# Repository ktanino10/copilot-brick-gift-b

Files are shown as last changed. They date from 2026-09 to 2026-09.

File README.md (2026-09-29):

# B DESK CLASSIC — 個人向け印刷・組立キット

**本人向けの公開案内： [説明・作り方・工程を見る](https://ktanino10.github.io/copilot-brick-gift-b/)**

2026-09-23のユーザー承認により、この個人向けrepoをpublicに変更し、GitHub Pagesで案内します。
個人銘板・許可済みの加工写真も公開内容です。原画像・EXIF・認証情報・ローカル監査資料は含めません。
公開内容は第三者にコピー・cacheされ得ます。[公開範囲](publication/README.md)を参照してください。

**2026-09-25：完成しました。「これで完成ですね」とご報告いただきました。**
水色のゴーグル枠を組み、上枠と紫の頭頂までそろった
[制作過程と完成の写真8枚](docs/BUILD-LOG.md#progress-2026-09-25)を追記しています。
前の16枚も残し、文字の試作から完成までを24枚の実写真でたどれます。
写真の紫・黄色は実制作の配色で、設計色や印刷データは変更していません。
制作の流れは **企画 → 設計 → 3Dプリント → 超音波洗浄 → アッセンブリー（組み立て）**。
[5工程の案内](docs/BUILD-LOG.md#今回の制作は5工程)から設計資料・動画・完成写真へ進めます。
[3Dプリントをページ内で見る](https://ktanino10.github.io/copilot-brick-gift-b/docs/BUILD-LOG.html#printing-video-2026-09-25) ／
[超音波洗浄をページ内で見る](https://ktanino10.github.io/copilot-brick-gift-b/docs/BUILD-LOG.html#post-processing-ultrasonic-2026-09-25)。
2本ともユーザー提供動画です（ネット接続が必要、自動再生なし）。

**2026-09-22承認：文字銘板を読みやすい版へ更新しました。**
1行目12 mmを維持して孔・字間を広げ、2行目10 mm、白い浮彫1.2 mmにしています。
既に印刷した台座・顔・右ロゴはそのまま使い、更新するのは**文字銘板1枚だけ**です。
まず[同寸法の小さな文字試験片と変更説明](docs/NAMEPLATE-V2.md)を確認してください。

**配布するのは通常GitHub CopilotのB・1種類だけ。個人銘板入りのデータと日本語の作り方です。**
承認済みの顔、シアンのゴーグル、マゼンタの外周、緑の目、5段の黒台座を変更していません。
別PCでも、公開Webページを直接見るか、このリポジトリから保存して作業できます。

**[B全キットをダウンロード](https://github.com/ktanino10/copilot-brick-gift-b/blob/main/downloads/B-personal-print-kit.zip)**

リンク先で **Download raw file** → ZIPを展開。公開repoなので閲覧・保存にログインは不要です。
リポジトリ上部の **Code → Download ZIP** でも同じ内容を受け取れます。
2つとも保存する必要はありません。

**展開したフォルダの [`guide/index.html`](guide/index.html) をダブルクリックすると、
印刷ファイルと組立位置を照合できる3Dガイドが開きます。**
インターネット接続、Python、Node、サーバーの準備は不要です。
GitHub上ではHTMLが実行されないため、必ず保存・展開して開きます。

**色別表の上からの印刷順は、組立順ではありません。**
最初は `B-black-02.3mf` の **slot 3 / `BASE3-24x10-B-562406` → `B-001` / 工程1**。
`black-01`の8個は2〜5段目用なので、既に刷ったものは捨てず、部品IDごとに仕分けて使います。

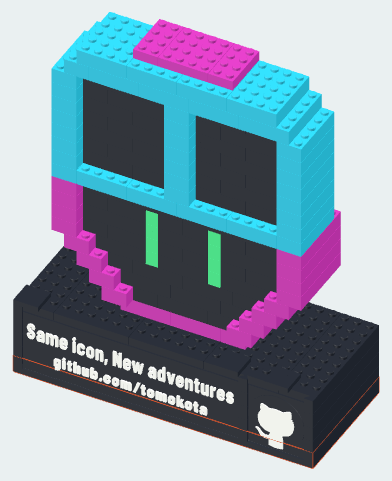
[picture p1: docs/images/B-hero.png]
個人銘板入りの承認済みB。実STLから作成した保存済みの完成配置画像


これは実STL由来のデジタル完成図で、実物写真ではありません。
オレンジの枠はビューアの選択表示で、追加の印刷色・部品ではありません。
**配布データはNOT_SLICED（未スライス）。実制作写真はありますが、正式な嵌合・保持・強度・転倒の評価結果は未提供です。**
3MFは形状と配置のみで、検証済みP1S設定・Pause・G-codeを含みません。

## CLI風アレンジ（実物写真）

ブロックを変更してCLI風にアレンジした実物です。**標準配布モデルとは異なるアレンジ例です。**
設計・印刷ファイル・3D組立順は変更していません。

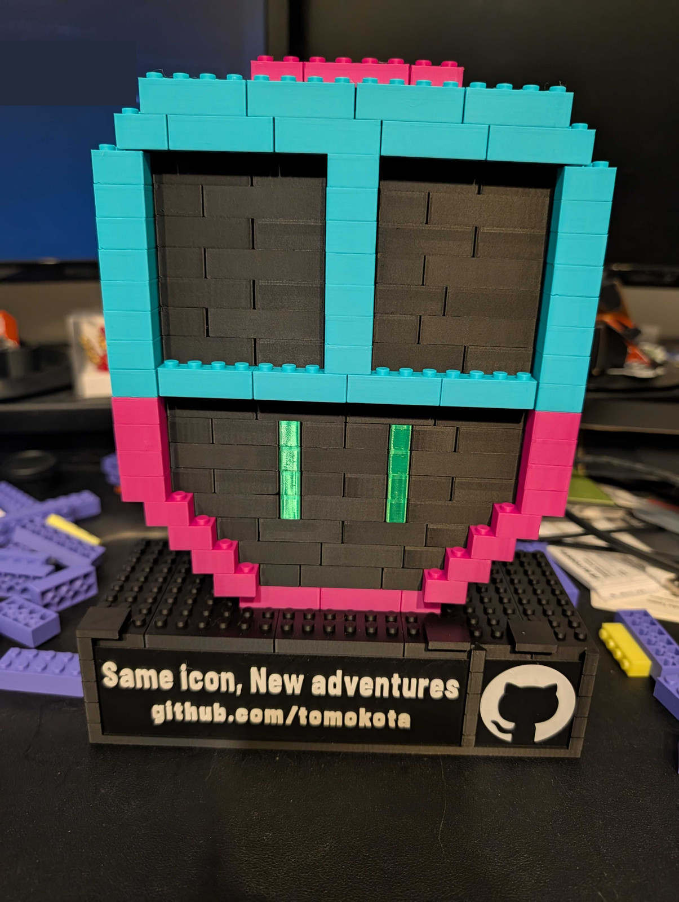
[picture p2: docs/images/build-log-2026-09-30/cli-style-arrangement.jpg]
CLI風にアレンジした実物のブロック模型。シアンのゴーグル枠、黒い顔、マゼンタの輪郭、緑色の目と黒い台座


[制作記録と写真の取扱い](docs/BUILD-LOG.md#cli-arrangement-2026-09-30)に追記しました。
追加日は2026-09-30（JST）で、撮影日は未確認です。

## まず、ここから

1. **[別PCでの保存・Bambu Studio・印刷手順](docs/PRINTING.md)** を開き、
   P1Sの実ノズル・PLA・プレートとStudio設定を合わせます。
2. 最初は **[FIT-M-D470](kit/fit/FIT-M-D470.stl)＋[FIT-F-CP12](kit/fit/FIT-F-CP12.stl)を各1個だけ**。
   mm・100%・向きを確認し、スライス後に穴入口と屋根の経路を見ます。
3. **[少量試作の順番](docs/TRIAL.md)** に沿い、必要なキー溝試験片 → 実ブロック4個 →
   keeperとB台座端部3個 → 実5段台座・前面 → 顔の少量バッチへ進みます。
4. 問題がなければ **[オフライン3Dガイド](guide/index.html)** と
   **[組立・銘板交換・分解](docs/ASSEMBLY.md)** を見ながら組みます。
   **[3Dガイドの使い方](docs/GUIDE.md)**／**[28工程の図](docs/STEPS.md)** も同梱しています。

**穴・溝が塞がる、指でつかめない、座らない、強い力が必要、割れ、保持不足があれば停止。**
全数を先に刷らず、穴を1つずつ削る・工具で無理押しすることを前提にしません。
試作7個の成功だけでは完成品の合格になりません。

## 印刷した部品を、3Dで探してから組む

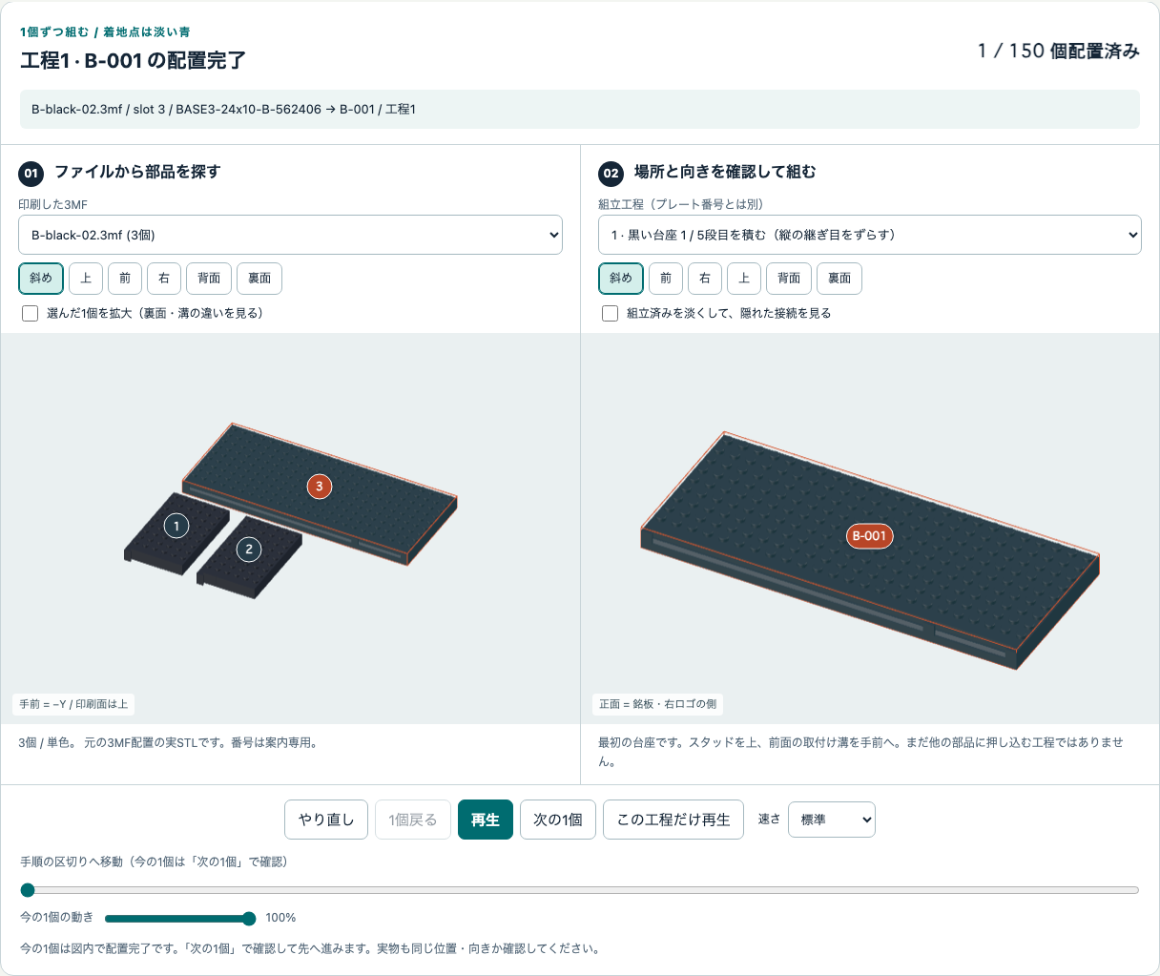
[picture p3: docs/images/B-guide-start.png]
実3MFの配置と実STLによる台座1段目。black-02 slot 3からB-001へ対応する3Dガイド


`B-black-02.3mf` → **slot 3** → `BASE3-24x10-B-562406`（**191.8 × 79.8 mm**）
→ **`B-001`、工程1**。この大きさの1段目は1個だけです。
3D内の部品または一覧を選ぶと、適用できる配置番号と工程、完成／途中の位置を強調します。
案内用slotは3MF内の順番を表す番号で、部品に刻印されていません。
**同じ部品ID・色のものは交換可能**で、便宜上の割当は実物の個体識別ではありません。

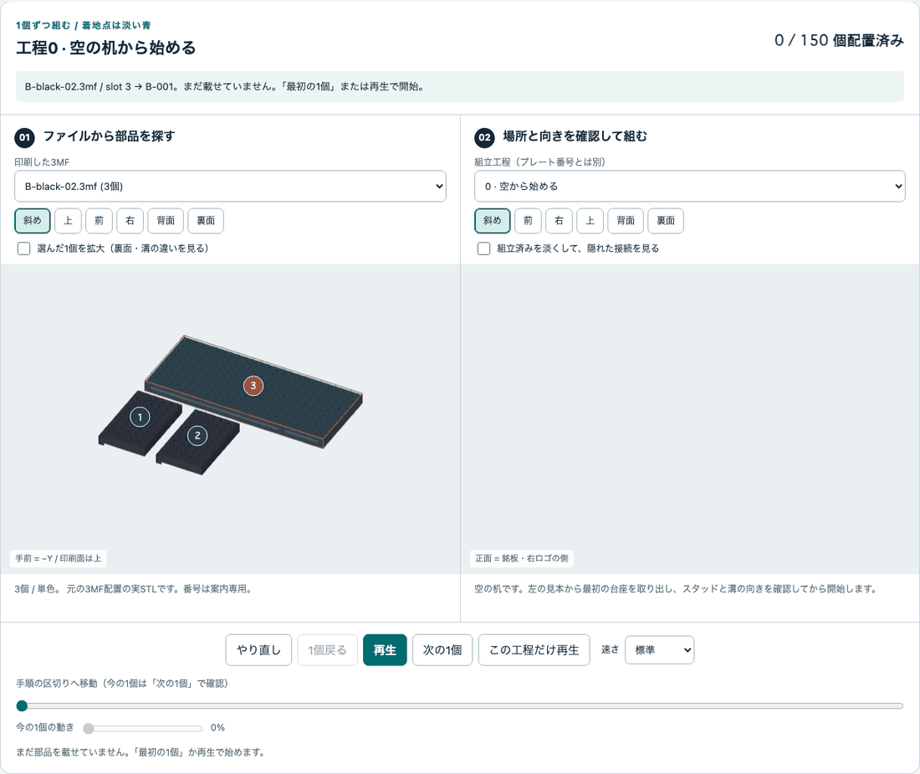
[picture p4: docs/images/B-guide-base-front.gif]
空の机から台座5段、銘板・独立ロゴ、keeper3個を組む実形状3Dアニメーション


台座1〜5段の19個は **black-01〜04**、前面2個は **black-to-white-z2p4 / z2p8**、
keeper3個は **black-07のslot 8〜10** から取ります。
2段目だけでも **black-02 slot 1 → B-002、black-03 slot 3 → B-003、
black-03 slot 1 → B-004、black-01 slot 7 → B-005** が必要です。
全28工程／150個の操作は [3Dガイド](guide/index.html)、
全14枚の対応は [ファイル一覧](docs/FILES.md) へ。
画像・アニメは同梱ビューアの実形状表示で、実物試験や挿入・分解経路の保証ではありません。

## 作るものは、このBだけ

| 項目 | 内容 |
|---|---|
| 完成寸法 W×D×H（設計値） | **191.8 × 80.2 × 238.6 mm**（上端スタッド・前へ0.4 mm増した白文字込み。台座奥行は79.8 mmのまま） |
| 完成品の部品数（設計値） | **150個**。21形状・色別23行の[BOM](kit/B/bom.csv)。試験片は別 |
| 台座（設計値） | 黒5段、台座body高さ48 mm。台座19個＋前面2個＋keeper3個＋顔126個。写真から数えた実測値ではない |
| 前面 | 大きい着脱式2行銘板を左、独立して着脱できる黒地／白Octocatロゴを右 |
| 接続（設計仕様） | 公称8 mmピッチ、無接着で組み、全体を分解できる設計。写真から接着の有無を証明したものではなく、市販品との互換保証もなし |
| 対象プリンタ・材料 | Bambu Lab P1S、PLA。実設定は本人が確認 |
| キット識別 | `4.1-B-legibility.1`。文字銘板だけ改訂。他20形状と150配置は維持 |

### 銘板は反映済み

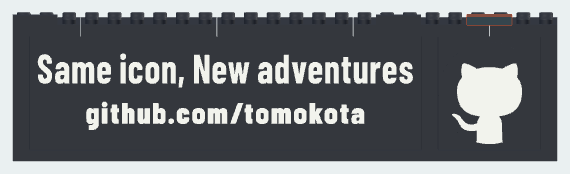
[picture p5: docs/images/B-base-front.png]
個人用の2行銘板と、右側の独立ロゴ。保存済み実形状レンダー


```text
Same icon, New adventures
github.com/tomokota
```

`NP3-TEXT-B` は **142 × 40 × 3.6 mm**、黒い支持体2.4 mm＋白い浮彫1.2 mmです。
実際の行の文字外接高さは上12 mm・下10 mm。黒い基材・裏の取付け形状は変更していません。
銘板は追加の151個目ではなく、完成BOMの1枚を個人版に置換済みです。
`@tomokota` の独立行や、別の呼び名への改名はしていません。
汎用銘板を別途取得する必要はありません。

## 色とファイルの選び方

必要なPLAは**黒・シアン・マゼンタ・緑・白の5色**。
平らな机、柔らかい布、色／部品ID別のトレー、観察用のノギスを用意します。
接着剤・別ピン・ハンマーは不要です。

| 印刷するもの | 組込数 | 3MF候補配置 | ノズルの出発点 |
|---|---:|---:|---|
| 黒い本体・台座・keeper | 82 | 黒7枚 | 0.4 mm |
| シアン | 36 | シアン2枚 | 0.4 mm |
| マゼンタ | 22 | マゼンタ2枚 | 0.4 mm |
| 緑 | 8 | 緑1枚 | 0.4 mm |
| 個人銘板 | 1 | 黒→白1枚、支持体2.4 mm後 | 0.2 mm |
| 右ロゴ | 1 | 黒→白1枚、支持体2.8 mm後 | 0.2 mm |
| **合計** | **150** | **14枚** | **印刷条件・全体の正式検証は未照合** |

BOMの黒84個には、黒い支持体を持つ銘板とロゴ各1個も含まれます。
白のレリーフを別部品として足しません。

**[ファイル名・プレートごとの個数・STL一覧](docs/FILES.md)** から選びます。
本体4色は別々の単色プレートで印刷します。白い文字・ロゴは独立小部品ではなく、
黒い支持体とつながったレリーフです。この2部品だけ、実スライスのプレビューで
**黒地終了後／最初の白い経路の前にPauseを追加**し、P1S標準手順で手動交換します。
AMS不要の経路ですが、Pause・交換・再開は実機で未確認です。
固定の層番号や未検証G-codeは提供しません。

**STLと3MFは代替です。同じ部品の両方を読み込まないでください。**
3MFを1つ開くたびに空のプロジェクトから始めます。
ノズル0.4／0.2 mmは推奨の出発点で、現在の装着径・PLA銘柄・プレート・プロファイルを
この配布物から推測しません。時間・重量は本人の実スライス結果だけを記録します。

## 手順・図面・保管用データ

| 開くもの | 用途 |
|---|---|
| [写真付き制作記録](docs/BUILD-LOG.md)／[9/25の完成記録](docs/BUILD-LOG.html#progress-2026-09-25) | 文字の相談→土台と前面→顔→ゴーグル・頭頂と完成。実物写真と完成CGを区別 |
| [オフライン3Dガイド](guide/index.html)／[使い方](docs/GUIDE.md) | ZIP展開後にダブルクリック。実プレートの部品から組立位置・全28工程へ |
| [印刷手順](docs/PRINTING.md)／[少量試作](docs/TRIAL.md) | 別PCの保存から設定・レイヤー確認・色替え・停止条件まで |
| [組立・分解・交換](docs/ASSEMBLY.md)／[工程図](docs/STEPS.md) | 5段台座から顔まで。番号と色を照合 |
| [組立・部品図PDF（54ページ）](kit/B/drawings.pdf) | 個人銘板入りBの保存済みCAD図。紙への印刷も可能 |
| [BOM](kit/B/bom.csv)／[工程CSV](kit/B/steps.csv)／[配置JSON](kit/B/assembly.json) | 数量・色・配置番号・28工程の対応 |
| [個人銘板の寸法図](kit/B/drawings/parts/NP3-TEXT-B.svg) | 実寸・印刷姿勢・正確な2行 |
| [銘板更新と小試験片](docs/NAMEPLATE-V2.md) | 旧版との比較、まず65.4×30.9 mmだけで文字を確認 |
| [B完成FreeCAD](source/native/B.FCStd)／[完成STEP](source/native/B.step)／[銘板FreeCAD](source/native/NP3-TEXT-B.FCStd) | 保管・確認用。印刷開始にFreeCADは不要 |
| [出典・再利用範囲](docs/PROVENANCE.md)／[権利表記](notices/README.md) | 形状と個人版の対応、元source、フォント等 |
| [検証・保守](docs/MAINTENANCE.md)／[SHA-256一覧](SHA256SUMS.txt) | ファイル対応と再検証方法 |

非文字部品の一部SVGの `REV3` は、変更していない共通形状を作図した当時の表記です。
文字が見える現行図・画像・3Dは新しい銘板を使用しています。
共通接続図の `PUBLIC TEMPLATE` は形状の出典表示で、個人完成図や公開配布先ではありません。
詳しくは[出典](docs/PROVENANCE.md)を参照してください。

成人向け屋内卓上オブジェです。小部品・破片を子どもやペットから離し、
高温部に触れず、完成品は**台座を両手で支えて**扱ってください。
9/22の文字試作は0.2 mmノズルとの申告があり、9/23に土台・前面、9/24に顔下部、
9/25にゴーグル・頭頂までの完成写真と本人の完成報告が届きました。
完成の報告と写真は、使用STL／実スライス版の照合や寸法・荷重などの測定結果とは分けて記録しています。
設定入りBambu Studioプロジェクトは未受領で、糸引き・上面荒れの原因や解決は断定していません。

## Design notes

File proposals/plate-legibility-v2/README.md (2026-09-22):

# 個人B銘板・可読性改訂の承認記録

**この実CAD比較は2026-09-22に承認され、現行銘板へ採用されました。**
このフォルダは比較時の候補形状・測定・根拠の記録です。通常の印刷は
[現行の新版説明](../../docs/NAMEPLATE-V2.md)から行ってください。
候補ファイルと現行ファイルを別々の部品として二重に印刷しません。

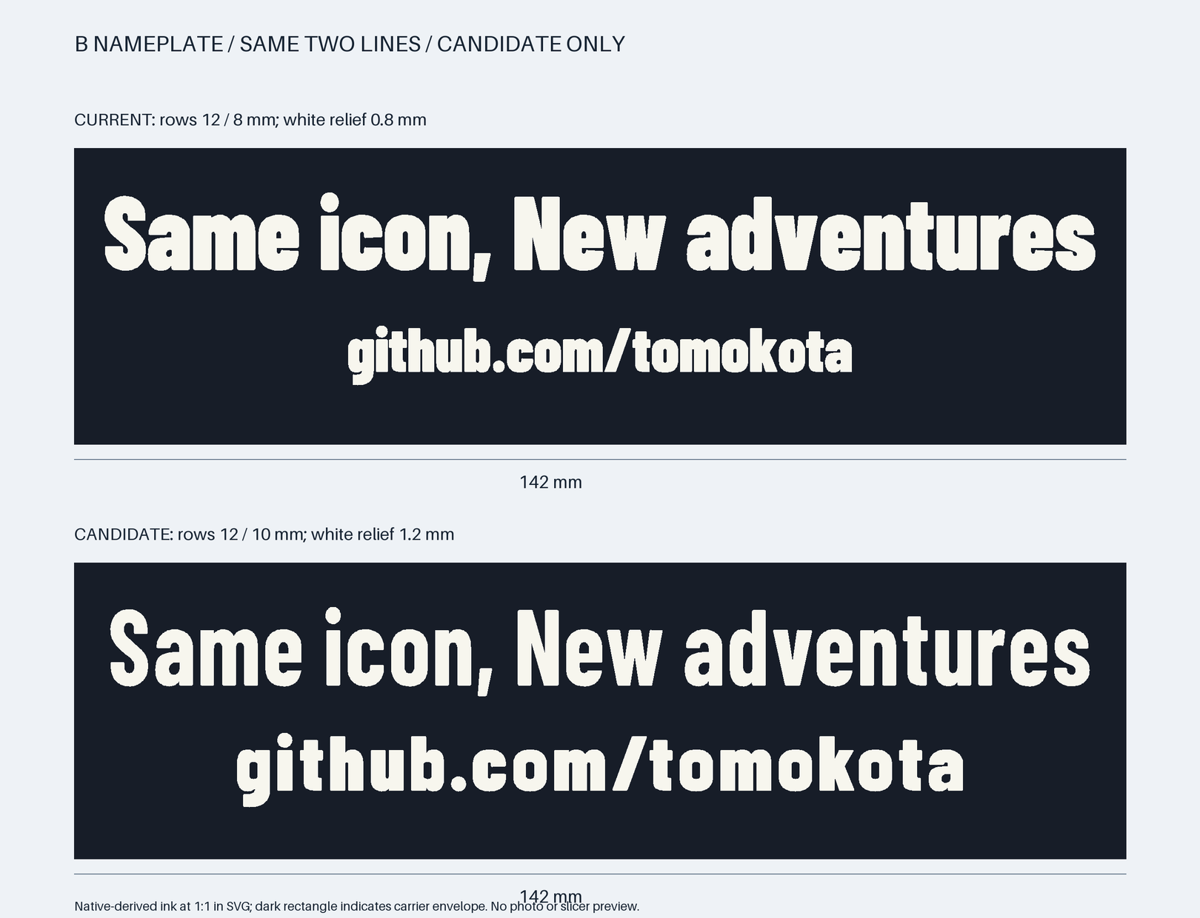
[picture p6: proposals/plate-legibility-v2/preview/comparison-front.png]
上は旧版、下が承認形状。同じ142mm幅、実native輪郭


2行の正確な文面、黒い基材142×40×2.4 mmと裏取付けは維持。
上段12 mm・下段10 mm、白い浮彫1.2 mm、全厚3.6 mmです。
前面の追加0.4 mmを含む完成模型の奥行は80.2 mmになります。

`candidate/plate.stl`／`.3mf`は同じ承認候補1個、`.FCStd`／`.step`は実nativeです。
`coupon/coupon.stl`／`.3mf`は同寸法glyphの小試験片で、縮小した全文ではありません。
どちらもSTLか3MFの一方を選びます。黒2.4 mm後のPauseは本人が実スライスで設定し、
3MFにprofile・Pause・G-codeが入っているとは扱いません。

[孔の拡大図](preview/counter-detail.png)・[実native断面](preview/side-section.png)・
[試験片](preview/coupon-front.png)・[全glyphの測定定義と値](metrics.json)・
[黒基材と連続解除経路の検査](motion-verification.json)を保存しています。
閉孔の中央帯chord、e/cの外へ抜ける有効開口、正線の代表gaugeと持続neckの判定を分けています。
0.2 mmノズルでも、ここで得た約1 mmを成功保証の規格とはしていません。

元写真やEXIFは含めていません。写真の糸引き・上面荒れ等は実設定が未受領のため
原因や補正値を断定せず、新版の実機結果も未確認です。

## 再現の範囲

同じリポジトリの`source/scripts/legible_lettering.py`と`legible_metrics.py`を利用します。
元のBlack、追加した正規Barlow Condensed Bold、OFLは改変していないフォント資源です。
Boldの出典は`google/fonts` commit `e44c4b011a820c2cbe2fd2cfa8052037d7edb571`。
`letter-plan.json`はこの個人2行専用で、別の文字列へ流用しません。
現行と旧版を取り違えないよう、比較の旧形状はrevision付き保管先を明示参照します。
通常ユーザーが再生成する必要はありません。

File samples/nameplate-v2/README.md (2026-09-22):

# 新版銘板の文字試験片

まず`NP3-LETTER-TEST-B-V2.3mf`か同じSTLの**どちらか一方を1個**使います。
65.4×30.9×3.6 mm、黒2.4 mm＋白1.2 mm。mm・100%、平らな裏面を下、文字を上。
汎用3MFは未スライスで、Pause・実機profile・G-codeを含みません。

実際の新版から`icon, New ad`と`b.com/to`を、文字倍率と行内の字間を変えず切り出しています。
孔・eの開口・字間・点・スラッシュ・mの接合を、実装ノズルと一致する0.2 mm設定で確認します。
黒2.4 mmの終了後、最初の白い経路より前にPauseを設定してください。固定層番号はありません。

これは完成BOM150個とは別の試作です。取付けキーがなく、大きい銘板の反り・保持・嵌合試験は代行しません。
詳しくは[変更説明](../../docs/NAMEPLATE-V2.md)と[印刷手順](../../docs/PRINTING.md)を参照してください。

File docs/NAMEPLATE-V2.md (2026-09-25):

# 文字銘板の更新 — 2行のまま、孔と字間を広げる

[入口](../README.md) · [印刷手順](PRINTING.md) · [組立・交換](ASSEMBLY.md)

**2026-09-22に比較図で承認された版を、現行`NP3-TEXT-B`へ反映しました。**
再印刷対象は文字銘板1枚だけです。台座・顔・右ロゴ・keeperの印刷形状と配置は変えていません。
完成品は150個のままで、下の文字試験片はその個数に足しません。

上は旧版、下は承認済み新版。どちらも実CADの文字輪郭、同じ142mm幅

## 先に小さい試験片を1個

| 保存するもの | 用途 |
|---|---|
| [文字試験片3MF](../samples/nameplate-v2/NP3-LETTER-TEST-B-V2.3mf) | まずこちらを1個。65.4×30.9×3.6 mm、黒2.4＋白1.2 mm |
| [文字試験片STL](../samples/nameplate-v2/NP3-LETTER-TEST-B-V2.stl) | 同じ1個の代替形式。上の3MFと同時に読み込まない |
| [新版銘板3MF](../kit/B/plates/B-black-to-white-z2p4-01.3mf) | 小試験後の全文142×40×3.6 mm、1個 |
| [新版銘板STL](../kit/B/parts/NP3-TEXT-B.stl) | 同じ全文1個の代替形式 |

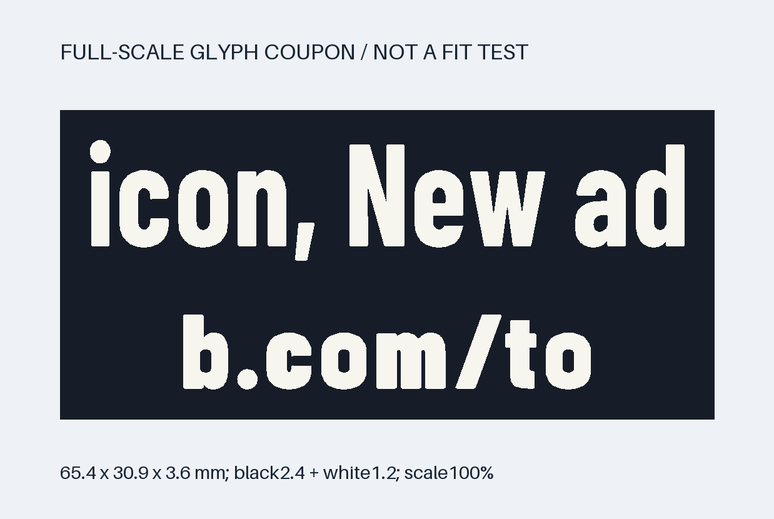
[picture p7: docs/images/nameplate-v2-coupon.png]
縮小していない、候補と同じglyphと字間の試験片


試験片は実際の新版から **`icon, New ad` と `b.com/to`** を切り出したもので、
文字の大きさ・字間・黒白の高さは全文銘板と同じです。上段のa/e/o/d、eの出口、
下段のb/o、点、スラッシュ、mの接合部を見られます。
取付けキーのない単純な裏板です。これが良くても、全文板の反り・嵌合・保持の合格ではありません。

P1Sの実装ノズルとStudioの**0.2 mm設定が一致**することを確認し、
mm・100%、平らな裏面を下、文字を上で1個ずつ使います。
どちらも**NOT_SLICED**で、Pause・プリンタprofile・G-codeは含みません。
黒2.4 mmが終わった後、最初の白い経路の前にPauseを入れるルールは変更ありません。
固定層番号には置き換えず、実レイヤープレビューで確認してください。

## 何を変えたか

| 項目 | 旧版 | 新版 |
|---|---:|---:|
| 上段の実ink高さ | 12 mm | **12 mmを維持** |
| 下段の実ink高さ | 8 mm | **10 mm** |
| 白の浮彫高さ | 0.8 mm | **1.2 mm** |
| 黒の基材厚さ | 2.4 mm | **2.4 mmのまま** |
| 銘板全厚 | 3.2 mm | **3.6 mm** |
| 上段の最小字間・実BRep距離 | 0.342 mm | **1.048 mm** |
| 下段の最小字間・実BRep距離 | 0.172 mm | **1.048 mm** |
| 上下の実ink間隔 | 6 mm | **5 mm** |

「ink高さ」はフォントのポイント数ではなく、点やカンマ等を含む各行の実文字形状の外接高さです。
下段は均等拡大です。上段は横方向のフォント尺度を保ち、従来と同様に実高さ12 mmへ合わせています。
幅へ押し込む横圧縮、文字削除、URL短縮、3行化はしていません。

上段は同じBarlow CondensedのBoldへ替え、eの右の口を広げています。
下段はBlackの正線を残しながら、内側の孔だけを広げました。
不足する字間だけを追加し、元のkerningを縮めていません。
白を厚くしたのは板から出る方向であり、白い文字を横太りさせたものではありません。

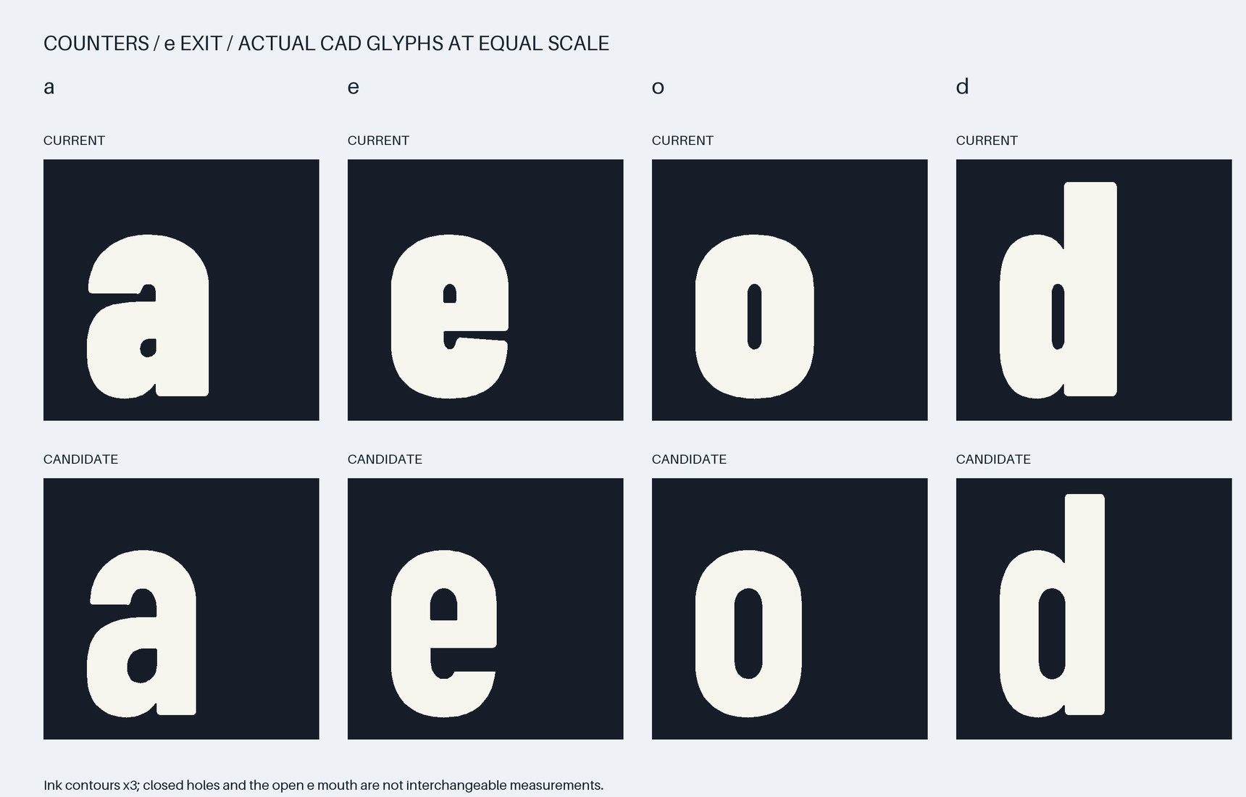
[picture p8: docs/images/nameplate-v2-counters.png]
a/e/o/dの実CAD輪郭を同倍率で比較


代表的な閉孔の**中央50%帯の最小横chord**は、上段aが0.655→1.203 mm、
eが0.501→1.040 mm、oが0.628→1.267 mm、dが0.563→1.203 mmです。
eの右へ通じる有効開口は約0.32→1.10 mm、下段g/b/oの同chordは最低約1.02 mmです。

正の材料幅も別に測っています。平行直線のgauge最小値は上段1.261 mm／下段1.694 mm。
曲線を含む持続的な細い接合を調べる「材料coreが分裂する侵食径」は、
定義した面積条件で上段最低約1.09 mm／下段約1.02 mmです。
点やスラッシュを含めた[測定記録と定義](../verification/legibility-metrics.json)を残しています。

これらは**今回の候補を比較する設計上の目安**です。0.2 mmノズルの保証規格ではありません。
孔の尖った端へ近づいた数学上のゼロ幅を「最小孔径」と数えず、
中央25〜75%を通る横・縦101本のchordと内接円径を区別しています。
e/cの開口は0.01 mm格子で外へ抜ける最大clearance経路を測り、誤差目安は約±0.03 mm。
正線gaugeも曲線先端の全箇所保証ではありません。

## 黒い取付けと交換手順は維持

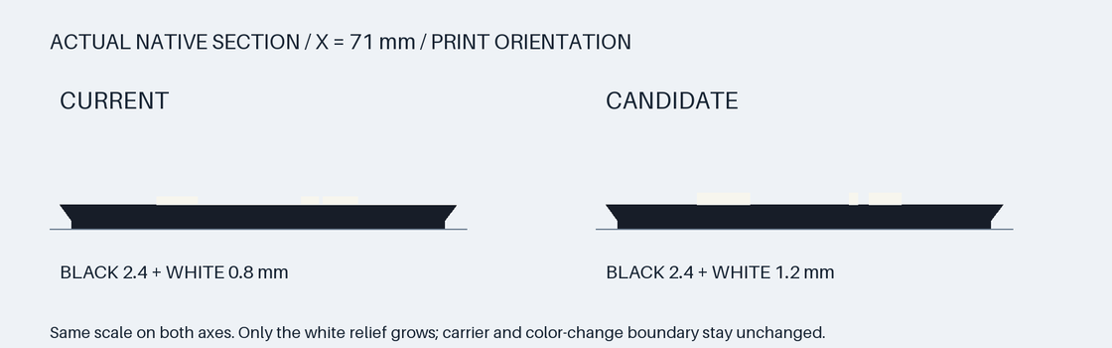
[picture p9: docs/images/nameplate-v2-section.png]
実nativeのX=71mm断面。両軸同倍率、黒2.4mmは不変


黒いキャリアと裏のキーテーパー・座面は旧版と実BRepの体積対称差0です。
差替えた状態、keeperを上6 mm→前32 mmへ外す操作、
銘板を上45 mm→前14 mmへ抜く操作について、
連続掃引または形状を包む保守的な包絡を使い、デジタル干渉0を確認しました。
実物は軽い指の力で試し、強い力・白化・割れ・保持不足があれば止めます。

増した白が0.4 mm前へ出るため、完成模型の外接寸法は**191.8×80.2×238.6 mm**です。
台座の191.8×79.8 mmと5段48 mm、150個の配置は変わりません。
この図はスライス結果でも物理的な成功証明でもありません。

## 写真から分かること・まだ分からないこと

2026-09-23に、銘板2枚の写真と「いけているみたい」、その後に
「土台が組み上がりました」という報告・写真が届きました。
[制作記録](BUILD-LOG.md)に、改訂後の試作についての手応えと台座・前面の状態をまとめています。
2枚の上下の旧・新版対応、各現物と指定STL／実スライスのhashは未照合です。
9/24には、銘板・右ロゴ付き台座の上へ顔下部を組む[途中記録](BUILD-LOG.md#progress-2026-09-24)が追加されました。
これは文字銘板の再改訂や、使用版・印刷条件の合格認定ではありません。
9/25には、ゴーグルの上枠と紫の頭頂までそろった[実物の完成写真と本人の完成報告](BUILD-LOG.md#progress-2026-09-25)が届きました。

旧銘板を0.2 mmノズルで印刷したとの申告と写真が、この変更の起点です。
狭い孔・字間の余裕を増やしましたが、糸引き・上面の荒れ・線状の抜けを
形状だけで解消できるとは断定しません。実際の設定入りBambu Studioプロジェクトは未受領です。
温度、流量、乾燥、冷却の値を写真だけで推測して一律変更しないでください。

試験片で孔が閉じる、文字経路が欠ける、上面が荒れる場合は全文の再印刷を止め、
実プレビューと現物を照合します。写真は銘板を印刷した証拠であり、
完成模型全体の保持・安定性や、特定の指定版が検証条件どおり成功したことを示すものではありません。
許可された加工済み写真だけを掲載し、加工前の原画像やEXIFはこのリポジトリへ保存していません。

旧版を確認する場合だけ、
[履歴用の旧銘板](https://github.com/ktanino10/copilot-brick-gift-b/tree/main/revisions/4.0-B-personal-kit.2)
を使います。現行の印刷対象に混ぜないでください。

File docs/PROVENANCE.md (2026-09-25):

# 出典と個人Bへの対応

[入口](../README.md) · [検証・保守](MAINTENANCE.md) · [権利表記](../notices/README.md)

## 採用範囲

このリポジトリは **B DESK CLASSICの個人向けキット**です。
非文字20形状・黒い取付け基材・150配置を維持し、文字銘板1個だけを
2026-09-22承認の可読性改訂版へ更新しています。
追加キャラクター、別サイズ案、旧試験の4 mmピンは配布対象ではありません。
原本のGit履歴・バックアップ全体は取り込まず、明示された現行ファイルとBの保存済み媒体だけを
ハッシュ照合して選別しました。公開元のリポジトリ・worktreeを変更していません。

| 系統 | 固定した出典 |
|---|---|
| 共通の現行source | `ktanino10/copilot-brick-display`、commit `1eaae1288816ec9575eeb6e2abbe74ed53289d74` |
| 元の別PC・段階試作手順 | 同repo、生成／手順更新commit `7af459e5c5c9f0e3956bf785e34db20135a7ba97`。上記最新commitは検証記録の追記 |
| 共通形状revision | `4.0-public-template`。B非文字20形状、150配置、取付け仕様を再利用 |
| 個人銘板 | 現行は実ink高12／10 mm・白1.2 mmの承認形状。142×40×3.6 mm。正確な2行は不変 |
| 個人B完成native・PDF・画像 | 保存済みBの文字部品だけ差し替え、関係する投影・実STL画像を更新。他149組込solidは幾何一致 |
| 今回のキットrevision | `4.1-B-legibility.1`。文字面だけの改訂。白が0.4 mm前に出るため全体奥行は80.2 mm |

各採用ファイルの出典相対パス、取得時のbytesとSHA-256は
[source-import.json](../verification/source-import.json)にあります。
`adapted:` はBだけの選別やパス・メタデータ整備を行ったものです。
同記録は取得時点の記録で、後のメタデータ更新を含む**納品時の全ハッシュは
[SHA256SUMS.txt](../SHA256SUMS.txt)** を正とします。

## 現行と旧版を分ける

| 現行ファイル | 対応 |
|---|---|
| `kit/B/parts/NP3-TEXT-B.stl` | 新版の文字銘板1個 |
| `kit/B/plates/B-black-to-white-z2p4-01.3mf` | 同じ新版1個の代替形式。Pauseは未設定 |
| `source/native/NP3-TEXT-B.FCStd` | 新版の実native、実STEPも同じ形状 |
| `source/native/B.FCStd`／`B.step` | 同じ150配置へ新版だけを差し替えた完成native／STEP |

現行のSHA-256は[配布一覧](../SHA256SUMS.txt)を参照してください。
旧銘板（下段8 mm・白0.8 mm）は
[revision付きの保管先](https://github.com/ktanino10/copilot-brick-gift-b/tree/main/revisions/4.0-B-personal-kit.2)
に残しました。現行印刷ZIPには旧板を混ぜません。

通常版の文字入りSTLと対応3MFは、この印刷対象には含めていません。
個人板と同じ右ロゴを各1個、残り148個と合わせて**150個**です。
同じ銘板のSTL／3MFは代替形式であり、2個作る意味ではありません。
右ロゴと本体の単色3MFは元ファイルを無変更で使用しています。

旧版の元担当から引き継いだデジタル確認（新版の値と混同しません）：

- [銘板nativeの確認](../verification/inherited-plate-native.json)：
  現行Bキャリアとの対称差0、完成配置の候補9ペアの最大干渉0、
  最小の実直線ストローク約1.4747 mm。
- [銘板梱包の確認](../verification/inherited-plate-package.json)：
  closed・vertex-manifold・正体積、3MFを再読込して1個、NOT_SLICED。
  ここでいう過去の小ZIPは出典記録だけで、今回の配布経路ではありません。

今回の専用worktreeでも、[nativeを再openした結果](../verification/native.json)で
150個のID・色・配置、完成外形、2行、銘板寸法、個人plateとの対称差0、
候補9ペアの最大干渉0を確認しています。
今回は実際に文字nativeを更新し、完成native中の他149個は幾何的に同じまま保存しました。
曲線方向ベクトルの丸めにより旧BRep文字列とbyte差が出た右ロゴも、体積対称差0・面数・外形一致です。
印刷用の非文字20 STL／他13枚の3MFはbyte不変更です。
元の公開キャリアとの比較結果は、元担当の記録として区別して保持します。

## 画像・図面を混同しない

`docs/images/B-hero.png` と `B-base-front.png` は、個人2行が入った
現行の実STLを同じオフラインビューアで描画した画像です。
初回の旧Blender画像を、新版の完成画像と称していません。
`nameplate-front.png` は新版の実CAD正面投影です。
`nameplate-print-orientation.svg` だけは、姿勢と色替え高さを説明する模式図です。
いずれも実物写真・実スライス成功例ではありません。

非文字部品のSVGには保存時のヘッダー **`REV3`** が残っています。
変更していない共通部品の図として使用します。文字が見える全体図・分解図・銘板図、
前面の実断面、銘板を含む工程の平面範囲は新版に対応させ、PDFをまとめ直しています。
全体の前・右・上の図は、実STLの少し見下ろす正投影ビューです。
寸法ラベルはnativeの外接値で、画像の画素を測る図ではありません。
銘板の輪郭・断面と前面取付け断面は実native由来です。

`kit/fit/interface.*`、`front-interface.svg`、非文字部品の寸法SVGは**共通形状の参考図**です。
`PUBLIC TEMPLATE` という元ヘッダーは来歴の表示で、個人完成図や公開配布の指示ではありません。
個人文字が見える銘板図・完成画像・PDFは、すべて今回の確定2行に対応しています。

## オフライン3Dガイドと新しい案内画像

[`guide/index.html`](../guide/index.html)は、承認済みBの実STL・実3MF・assemblyを照合し、
描画ランタイムと圧縮STLを1つのHTMLへ埋め込んだものです。
`guide/index.mapping.json`はその対応表、`kit/B/part-map.csv`は全150slotの表です。
同形同色の全候補と便宜割当を分け、刻印や実物個体の識別とは扱いません。
取付け機構、色、150配置は再設計・再配置していません。
埋め込まれた銘板メッシュだけが今回の新版へ更新されています。

共通のviewer／mapping generatorだけを`ktanino10/copilot-brick-display`の担当者から
限定pathでread-only取得しました。共通案内コードの固定commitは
`35ebc11234779424ebbda83b3f1b7d31d8518b24`（UI v1.3）で、
形状の出典commit `1eaae1288816ec9575eeb6e2abbe74ed53289d74`とは別です。
取り込みのファイル別SHA-256と版は
[guide-source-import.json](../verification/guide-source-import.json)に記録しています。
個人source、銘板、画像、生成HTMLを公開側へ送り返していません。
当初はprivate／Pagesなしで保存しました。2026-09-23のユーザーによる追加承認後は
個人版repoをpublic化し、選別した案内をPagesでも公開します。保存したローカルHTMLも引き続き使えます。

`docs/images/B-guide-start.png`、`B-guide-front.png`、
`B-guide-base-front.gif`は、この同梱ビューアをオフラインの実ブラウザで描画・撮影したものです。
GIFは空の机から`B-001`〜`B-024`の24個を追加し、台座5段・前面2個・keeper3個までを示します。
銘板の90度回転、黒2.4 mm／白1.2 mmと、変更していないロゴ黒2.8 mm／白0.8 mmは実形状です。
軌跡や着地点の透過表示は説明用で、物理シミュレーションではありません。
[ブラウザ検証](../verification/guide-browser.json)は表示・操作の確認であり、実機の合格証拠ではありません。

## 元generatorと寸法source

`source/design/parameters.json` は機械寸法・Bの離散配置と個人2行、
`catalog.json` はB＋必要fit／trialだけの形状定義、`interface.json` は接続仕様です。
個人銘板のhash・三角形数・CAD体積・重心と完成Bの集計値は、今回の再open結果へ更新し、
通常版の文字の集計値を残していません。

`source/scripts/` に、元の機械geometry・前面機構・文字幅測定・配置generatorを保持しています。
`freecad_geometry.py`、`letter_metrics.py` の共通機械・既存正線測定はそのままです。
`front_nameplate.py` は承認済みの文字計画に対応し、`legible_lettering.py`と
`legible_metrics.py`が閉孔・e出口・追加字間の限定処理と定義済み測定を提供します。
`source/design/nameplate-plan.json`は正確な個人2行に対する計画で、公開側へ流用しません。
`design.py` はBと確定2行のみ許可し、公開用ポリシーや公開サイト出力に依存せず、
新しいローカル出力先だけを使うよう入口を適応しました。配置・寸法の計算は変えていません。

Barlow Condensed BlackとOFL、元マークの派生輪郭を保持し、正規のBoldを追加しました。
Boldの出典は`google/fonts` commit `e44c4b011a820c2cbe2fd2cfa8052037d7edb571`です。
公開側へ渡したのは個人値を持たない共通関数とBold/OFLだけです。
制作記録には、9/23記録の9枚、9/24の途中写真7枚と、9/25の制作過程・完成写真8枚を収録しています。
各回の写真掲載は別途承認されています。
いずれも親担当が回転・切り取り・メタデータ除去した派生だけを、再加工せずに使用しています。
加工前の原画像・元のファイル名・EXIF・元パス対応表は含めません。
以前の記録にあるprivate生成モードは当時の来歴で、現在の公開設定を示すものではありません。
[最新の公開方針](../publication/README.md)を参照してください。
不要なBlenderファイル／旧動画／中間フレーム、公開用workflow・CNAME・Pages設定、
会話履歴、端末の絶対パス、プリンタID・tokenも含めません。
元プロジェクト全体のビルドやサイト公開手順は、このキットの利用に必要ありません。

## 検証の限界

closed／manifold、CAD干渉0、正しい配置、ハッシュ一致は**印刷成功の保証ではありません**。
文字試作から、台座・顔・ゴーグル・頭頂と完成に至る実写真・本人報告は[制作記録](BUILD-LOG.md)にあります。
現物の正確な寸法、keeper保持力、強度、転倒、P1Sの交換手順等の正式な評価結果は未提供です。
9/22の0.2 mmノズル申告、9/23の土台、9/24の顔下部、9/25の完成報告と写真を記録しています。
完成写真と本人の報告は、使用した版のhash照合や寸法・荷重・耐久の測定とは分けています。
写真の色と設計色は別で、印刷データは変更していません。
PLA銘柄／色、plate、処理profile、AMS有無、実設定入りBambuプロジェクトは未照合です。
本人の実スライスと段階試作を省略しないでください。

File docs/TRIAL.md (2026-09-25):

# 全数を刷る前の少量試作

銘板だけを新しい可読性改訂版へ替える場合は、まず[実文字と同寸法の小試験片](NAMEPLATE-V2.md)を
使えます。これは文字の孔・開口・字間・白1.2 mmを確認するもので、
以下の機械的なfit試験や大きい銘板の取付け確認の代わりではありません。

[入口](../README.md) · [3Dで部品を探す](../guide/index.html) · [実機設定・レイヤー確認](PRINTING.md) · [組立](ASSEMBLY.md)

**試作7個の確認は、完成品の保持・強度・転倒の合格ではありません。**
外観、8 mmピッチ、スタッド・受け・溝の設計寸法は変更していません。

別の4 mmピン／受け試験では「小さくて作りにくい」「穴が樹脂で埋まる」との報告が
ありました。しかし失敗時の設定入りBambu Studioプロジェクトは未受領です。
今回は8 mmピッチのスタッド／下面の壁・筒・リブという別構造であり、
旧試験の原因を確定したり、補正値を流用したりしていません。

## 段階ごとに止まり、合格した分だけ進む

| 段階 | 選ぶ部品 | 個数 | 確認すること |
|---|---|---:|---|
| 1 | `FIT-M-D470`、`FIT-F-CP12` | 各1 | 入口、スタッド、軽い指の力での着脱 |
| 2 | `NP3-FIT-PLAQUE`、`NP3-FIT-SOCKET-C25`から | 必要分 | 短いキー溝への着座。候補値は合格値ではない |
| 3 | `BR-02x02-H096`、`BR-02x04-H096` | 各2、計4 | 実ブロックのつかみやすさ、下面空洞、屋根、着脱 |
| 4 | `NP3-KEEPER`、`BASE3-03x10-T-aa77a9` | 1＋2、計3 | 浅い受け、深い台座、キー溝、反りと整列 |
| 5 | Bの実5段台座＋個人銘板＋右ロゴ＋keeper3個 | [BOM](../kit/B/bom.csv)の該当分 | 全幅の反り、5段の溝、上止め、交換経路 |
| 6 | 顔の部品 | 少量バッチ | 細い1列部品も種類ごとに1個先行して確認 |

**「7個」は段階3の4個＋段階4の3個だけ**です。最初のfit試験片、
キー溝試験片、5段台座、完成品150個の総数とは分けて数えます。

[B専用試作BOM](../kit/trial/bom.csv)を使います。台座端部2個は**同じ左端形状を2個**で、
左右一対や鏡像ではありません。本来の3段目・5段目に使う同形状を選んでいます。
2個だけ重ねる試作は、正式な5段・互い違いの継ぎ目の再現ではありません。

2×2、2×4は既存の共通接続を試すための代表形状です。試作BOMを完成BOMに足しません。
完成品に使える同じID・色の良品だけ、完成BOMの既印刷数として管理できます。
試験片や完成BOMにない形状は、完成150個には含めません。

段階5で先にそろえるのは、完成BOMの **`BASE3-` で始まる全8行・計19個**、
**`NP3-KEEPER` 3個、`NP3-TEXT-B` 1個、`NP3-LOGO-B` 1個の計24個**です。
試作から流用する良品の分は差し引きます。黒い3MFには顔の部品も含むプレートがあるため、
この段階は必要なSTLをBOMどおり手配置できます。顔126個は、実台座・前面の確認後です。
印刷済みの3MFから探す場合は[3Dガイド](GUIDE.md)を使います。
1段目の大きい1枚は `B-black-02.3mf` slot 3の`B-001`、
試作した同じ左端2個は`B-006`／`B-015`（3段目／5段目）です。
黒の印刷順を組立順とは扱いません。

## ファイルと向き

fit試験片は [kit/fit/](../kit/fit/)、実ブロック等の参照先は
[試作BOM](../kit/trial/bom.csv)に記載しています。
**BOMの段階どおりの個数だけ**を新しい空のプロジェクトに読み込みます。

| 試作の実部品 | 外形 W×D×H / mm | 姿勢・注意 |
|---|---|---|
| `BR-02x02-H096` | 15.8 × 15.8 × 11.4 | 穴側下、スタッド上 |
| `BR-02x04-H096` | 15.8 × 31.8 × 11.4 | 穴側下、スタッド上 |
| `NP3-KEEPER` | 15.8 × 15.8 × 3.2 | 浅い受け下。後半の1列だけが受け、前半は中実の上止め |
| `BASE3-03x10-T-aa77a9` | 23.8 × 79.8 × 11.4 | 穴側下、前面キー溝を保つ。最前列の補強帯は削らない |

黒PLAを最初の候補にし、材料・色・ノズルが変われば再確認します。
まず実機の設定でスライスし、[入口・内部・屋根の点検](PRINTING.md#4-スライス後に見る場所)を
行ってから本人が印刷します。時間・重量は未測定のままで構いません。

## 冷却後の手作業

1. 完全に冷ましてから外し、明るい机と柔らかい布の上でIDごとに分けます。
   スタッドではなく側壁を持ちます。
2. 穴・溝の入口、屋根の垂れ、反り、白化・ひびを観察します。
   異常がある部品を押し合わせません。
3. 下の部品を机で支え、平行を保ち、軽い指の力で最後まで座るか確認します。
   真っすぐ取り外せることも確認します。つかめない場合は中止します。
4. keeperは対応する2スタッドへ試します。台座は最前列の補強帯を避け、
   接続用の2列目以降を使います。
5. 段階5で実5段の全幅・溝整列と、大きい銘板の反り・保持・交換を別途確認します。
   段階4だけでkeeperの上止め力や完成銘板の保持を認定しません。

市販ブロックと比べる場合は、変形・損傷のない小部品を使い、
「印刷オス→市販メス」「市販オス→印刷メス」を別々に確認します。
互換性の保証ではありません。傷がつきそうなら止めます。

## 中止条件と記録

**閉塞／指でつかめない／着座しない／強い力・工具が必要／割れ・白化／保持不足**
のいずれかがあれば、後の段階と全数印刷を止めます。
小穴の個別削り、こじり、打撃、熱による無理合わせをしません。

[fit-log.csv](../kit/fit-log.csv)をローカルへコピーして、入力ファイル名とSHA-256、
ノズル、PLA、プレート、プロファイル、入口／屋根の観察、つかみやすさ、
着座・保持、変更した1条件と結果を記録します。未確認の欄は空欄で構いません。
初層、ブリム、サポート、ブリッジ、材料、形状を区別し、原因未確定のまま
全穴径・XY補正・流量・温度をまとめて変更しません。

文字試作から完成までの[実制作写真と本人報告](BUILD-LOG.md)がありますが、
嵌合力・keeper保持・台座剛性・転倒等の正式な評価結果は未提供です。
CADの断面、閉じたメッシュ、ハッシュ一致は、実機印刷の成功保証ではありません。
小部品・破片を子どもやペットの手の届く場所に置かないでください。

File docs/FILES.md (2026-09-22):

# Bのファイル一覧と数量

[入口](../README.md) · [オフライン3D](../guide/index.html) · [3Dの使い方](GUIDE.md) · [印刷手順](PRINTING.md) · [少量試作](TRIAL.md)

**2026-09-22の変更は文字銘板1枚だけです。全厚3.6 mm・上12／下10 mm・白1.2 mm。まず[小さな文字試験片](NAMEPLATE-V2.md)から。台座・顔・右ロゴは刷り直し不要です。**

**印刷したファイルから探す：ZIPを展開して `guide/index.html` をダブルクリックし、3MFとslotを選びます。実プレートの配置と完成／途中の対応位置が3Dで見られます。**
全14枚／150配置を照合しています。slotは案内用の番号で、実物には刻印されていません。
同じ部品ID・色は可換です。便宜上の割当を実物の固有番号とは扱いません。
**色表とblack-01からの印刷順は組立順ではありません。1段目はblack-02 slot 3のB-001です。**

**全ファイルNOT_SLICED。STLと3MFは代替です。同じ部品の両形式を読み込まないでください。**
この一覧はBOM・3MF manifestから生成しています。各プレートを空のプロジェクトへ1枚ずつ開きます。
3MFにはPause、検証済みプリンタ設定、G-codeがありません。個人銘板は既に置換済みです。

## 配置済み3MF：全14枚、計150個

| ファイル | 色・用途 | 配置個数 | slotと組立位置 |
|---|---|---:|---|
| [B-black-01.3mf](../kit/B/plates/B-black-01.3mf) | 黒 | 8 | [対応表](#b-black-013mf) |
| [B-black-02.3mf](../kit/B/plates/B-black-02.3mf) | 黒 | 3 | [対応表](#b-black-023mf) |
| [B-black-03.3mf](../kit/B/plates/B-black-03.3mf) | 黒 | 6 | [対応表](#b-black-033mf) |
| [B-black-04.3mf](../kit/B/plates/B-black-04.3mf) | 黒 | 19 | [対応表](#b-black-043mf) |
| [B-black-05.3mf](../kit/B/plates/B-black-05.3mf) | 黒 | 20 | [対応表](#b-black-053mf) |
| [B-black-06.3mf](../kit/B/plates/B-black-06.3mf) | 黒 | 16 | [対応表](#b-black-063mf) |
| [B-black-07.3mf](../kit/B/plates/B-black-07.3mf) | 黒 | 10 | [対応表](#b-black-073mf) |
| [B-cyan-01.3mf](../kit/B/plates/B-cyan-01.3mf) | シアン | 26 | [対応表](#b-cyan-013mf) |
| [B-cyan-02.3mf](../kit/B/plates/B-cyan-02.3mf) | シアン | 10 | [対応表](#b-cyan-023mf) |
| [B-magenta-01.3mf](../kit/B/plates/B-magenta-01.3mf) | マゼンタ | 20 | [対応表](#b-magenta-013mf) |
| [B-magenta-02.3mf](../kit/B/plates/B-magenta-02.3mf) | マゼンタ | 2 | [対応表](#b-magenta-023mf) |
| [B-green-01.3mf](../kit/B/plates/B-green-01.3mf) | 緑 | 8 | [対応表](#b-green-013mf) |
| [B-black-to-white-z2p4-01.3mf](../kit/B/plates/B-black-to-white-z2p4-01.3mf) | 黒→白・個人銘板（2.4 mm後） | 1 | [対応表](#b-black-to-white-z2p4-013mf) |
| [B-black-to-white-z2p8-01.3mf](../kit/B/plates/B-black-to-white-z2p8-01.3mf) | 黒→白・右ロゴ（2.8 mm後） | 1 | [対応表](#b-black-to-white-z2p8-013mf) |

色替えの高さは目安となる境界です。実レイヤープレビューで黒地終了後／最初の白path前へPauseを入れ、
停止・交換・再開を本人が確認してください。固定層番号には変換しません。

## 手配置用STL：21形状、色別23行、完成150個

1つのSTLファイルは形状1種類です。以下の色ごとの数量が必要数です。
試作から完成品へ流用する良品があれば、既印刷数として引き当てて重複印刷を避けます。

| STL／部品ID | 色 | 完成必要数 |
|---|---|---:|
| [BASE3-03x10-T-aa77a9](../kit/B/parts/BASE3-03x10-T-aa77a9.stl) | 黒 | 2 |
| [BASE3-03x10-T-d79875](../kit/B/parts/BASE3-03x10-T-d79875.stl) | 黒 | 2 |
| [BASE3-06x10-T-3f87ac](../kit/B/parts/BASE3-06x10-T-3f87ac.stl) | 黒 | 2 |
| [BASE3-06x10-T-6159e6](../kit/B/parts/BASE3-06x10-T-6159e6.stl) | 黒 | 2 |
| [BASE3-06x10-T-6e100f](../kit/B/parts/BASE3-06x10-T-6e100f.stl) | 黒 | 2 |
| [BASE3-06x10-T-838259](../kit/B/parts/BASE3-06x10-T-838259.stl) | 黒 | 6 |
| [BASE3-06x10-T-e1945a](../kit/B/parts/BASE3-06x10-T-e1945a.stl) | 黒 | 2 |
| [BASE3-24x10-B-562406](../kit/B/parts/BASE3-24x10-B-562406.stl) | 黒 | 1 |
| [BR-01x04-H096](../kit/B/parts/BR-01x04-H096.stl) | 緑 | 8 |
| [BR-02x04-H064](../kit/B/parts/BR-02x04-H064.stl) | マゼンタ | 2 |
| [BR-02x04-H096](../kit/B/parts/BR-02x04-H096.stl) | 黒 | 19 |
| [BR-02x04-H096](../kit/B/parts/BR-02x04-H096.stl) | マゼンタ | 1 |
| [BR-02x05-H096](../kit/B/parts/BR-02x05-H096.stl) | シアン | 24 |
| [BR-02x06-H096](../kit/B/parts/BR-02x06-H096.stl) | マゼンタ | 16 |
| [BR-03x04-H096](../kit/B/parts/BR-03x04-H096.stl) | 黒 | 12 |
| [BR-04x04-H064](../kit/B/parts/BR-04x04-H064.stl) | マゼンタ | 1 |
| [BR-04x04-H096](../kit/B/parts/BR-04x04-H096.stl) | 黒 | 21 |
| [BR-04x04-H096](../kit/B/parts/BR-04x04-H096.stl) | マゼンタ | 2 |
| [BR-04x05-H096](../kit/B/parts/BR-04x05-H096.stl) | シアン | 12 |
| [BR-05x04-H096](../kit/B/parts/BR-05x04-H096.stl) | 黒 | 8 |
| [NP3-KEEPER](../kit/B/parts/NP3-KEEPER.stl) | 黒 | 3 |
| [NP3-LOGO-B](../kit/B/parts/NP3-LOGO-B.stl) | 黒→白 | 1 |
| [NP3-TEXT-B](../kit/B/parts/NP3-TEXT-B.stl) | 黒→白 | 1 |

## 全数印刷より先に使うもの

まず [FIT-M-D470](../kit/fit/FIT-M-D470.stl)＋[FIT-F-CP12](../kit/fit/FIT-F-CP12.stl)を各1個。
キー溝は [NP3-FIT-PLAQUE](../kit/fit/NP3-FIT-PLAQUE.stl)＋[NP3-FIT-SOCKET-C25](../kit/fit/NP3-FIT-SOCKET-C25.stl)から必要分だけ。

他のfit候補は [kit/fit/](../kit/fit/)にありますが、全種類を一括印刷しません。
候補は合格補正値ではありません。次の[試作BOM](../kit/trial/bom.csv)はBの7個だけです。

| 実部品の試作 | 個数 |
|---|---:|
| [BR-02x02-H096](../kit/trial/parts/BR-02x02-H096.stl) | 2 |
| [BR-02x04-H096](../kit/B/parts/BR-02x04-H096.stl) | 2 |
| [NP3-KEEPER](../kit/B/parts/NP3-KEEPER.stl) | 1 |
| [BASE3-03x10-T-aa77a9](../kit/B/parts/BASE3-03x10-T-aa77a9.stl) | 2（同じ左端形状） |

4個→3個と段階を分けます。2×2は完成BOMにない共通接続の試験用で、完成150個には数えません。

## 各3MFのslot・形状・寸法・適用先：全150項目

[対応CSV](../kit/B/part-map.csv) · [検査用mapping JSON](../guide/index.mapping.json) · [実プレートを3Dで見る](../guide/index.html)

slotは元3MFの順番です。各行は印刷配置1個で、同形の行でも別の印刷配置を数えています。
「同形数」はこのプレート内／完成B全体の同ID・同色数。「全適用先」は可換な全候補で、各行の実物を候補全部へ同時に使う意味ではありません。
便宜割当は150個を過不足なく数える案内です。寸法は印刷姿勢のスタッド・レリーフ込み外形です。

### B-black-01.3mf

[3Dガイド](../guide/index.html)でこのファイルを選び、同じslot番号の実形状を確認します。

| slot | 部品ID | 外形 W×D×H mm | 同形数（板内／全体） | 便宜割当／工程 | 全適用先 | 適用工程 |
|---:|---|---|---:|---|---|---|
| 1 | [BASE3-03x10-T-aa77a9](../kit/B/parts/BASE3-03x10-T-aa77a9.stl) | 23.8 × 79.8 × 11.4 | 2／2 | `B-006`／3 | `B-006`、`B-015` | 3、5 |
| 2 | [BASE3-03x10-T-aa77a9](../kit/B/parts/BASE3-03x10-T-aa77a9.stl) | 23.8 × 79.8 × 11.4 | 2／2 | `B-015`／5 | `B-006`、`B-015` | 3、5 |
| 3 | [BASE3-03x10-T-d79875](../kit/B/parts/BASE3-03x10-T-d79875.stl) | 23.8 × 79.8 × 11.4 | 2／2 | `B-010`／3 | `B-010`、`B-019` | 3、5 |
| 4 | [BASE3-03x10-T-d79875](../kit/B/parts/BASE3-03x10-T-d79875.stl) | 23.8 × 79.8 × 11.4 | 2／2 | `B-019`／5 | `B-010`、`B-019` | 3、5 |
| 5 | [BASE3-06x10-T-6159e6](../kit/B/parts/BASE3-06x10-T-6159e6.stl) | 47.8 × 79.8 × 11.4 | 2／2 | `B-009`／3 | `B-009`、`B-018` | 3、5 |
| 6 | [BASE3-06x10-T-6159e6](../kit/B/parts/BASE3-06x10-T-6159e6.stl) | 47.8 × 79.8 × 11.4 | 2／2 | `B-018`／5 | `B-009`、`B-018` | 3、5 |
| 7 | [BASE3-06x10-T-6e100f](../kit/B/parts/BASE3-06x10-T-6e100f.stl) | 47.8 × 79.8 × 11.4 | 2／2 | `B-005`／2 | `B-005`、`B-014` | 2、4 |
| 8 | [BASE3-06x10-T-6e100f](../kit/B/parts/BASE3-06x10-T-6e100f.stl) | 47.8 × 79.8 × 11.4 | 2／2 | `B-014`／4 | `B-005`、`B-014` | 2、4 |

### B-black-02.3mf

[3Dガイド](../guide/index.html)でこのファイルを選び、同じslot番号の実形状を確認します。

| slot | 部品ID | 外形 W×D×H mm | 同形数（板内／全体） | 便宜割当／工程 | 全適用先 | 適用工程 |
|---:|---|---|---:|---|---|---|
| 1 | [BASE3-06x10-T-e1945a](../kit/B/parts/BASE3-06x10-T-e1945a.stl) | 47.8 × 79.8 × 11.4 | 2／2 | `B-002`／2 | `B-002`、`B-011` | 2、4 |
| 2 | [BASE3-06x10-T-e1945a](../kit/B/parts/BASE3-06x10-T-e1945a.stl) | 47.8 × 79.8 × 11.4 | 2／2 | `B-011`／4 | `B-002`、`B-011` | 2、4 |
| 3 | [BASE3-24x10-B-562406](../kit/B/parts/BASE3-24x10-B-562406.stl) | 191.8 × 79.8 × 11.4 | 1／1 | `B-001`／1 | `B-001` | 1 |

### B-black-03.3mf

[3Dガイド](../guide/index.html)でこのファイルを選び、同じslot番号の実形状を確認します。

| slot | 部品ID | 外形 W×D×H mm | 同形数（板内／全体） | 便宜割当／工程 | 全適用先 | 適用工程 |
|---:|---|---|---:|---|---|---|
| 1 | [BASE3-06x10-T-3f87ac](../kit/B/parts/BASE3-06x10-T-3f87ac.stl) | 47.8 × 76.4 × 11.4 | 2／2 | `B-004`／2 | `B-004`、`B-013` | 2、4 |
| 2 | [BASE3-06x10-T-3f87ac](../kit/B/parts/BASE3-06x10-T-3f87ac.stl) | 47.8 × 76.4 × 11.4 | 2／2 | `B-013`／4 | `B-004`、`B-013` | 2、4 |
| 3 | [BASE3-06x10-T-838259](../kit/B/parts/BASE3-06x10-T-838259.stl) | 47.8 × 76.4 × 11.4 | 4／6 | `B-003`／2 | `B-003`、`B-007`、`B-008`、`B-012`、`B-016`、`B-017` | 2、3、4、5 |
| 4 | [BASE3-06x10-T-838259](../kit/B/parts/BASE3-06x10-T-838259.stl) | 47.8 × 76.4 × 11.4 | 4／6 | `B-007`／3 | `B-003`、`B-007`、`B-008`、`B-012`、`B-016`、`B-017` | 2、3、4、5 |
| 5 | [BASE3-06x10-T-838259](../kit/B/parts/BASE3-06x10-T-838259.stl) | 47.8 × 76.4 × 11.4 | 4／6 | `B-008`／3 | `B-003`、`B-007`、`B-008`、`B-012`、`B-016`、`B-017` | 2、3、4、5 |
| 6 | [BASE3-06x10-T-838259](../kit/B/parts/BASE3-06x10-T-838259.stl) | 47.8 × 76.4 × 11.4 | 4／6 | `B-012`／4 | `B-003`、`B-007`、`B-008`、`B-012`、`B-016`、`B-017` | 2、3、4、5 |

### B-black-04.3mf

[3Dガイド](../guide/index.html)でこのファイルを選び、同じslot番号の実形状を確認します。

| slot | 部品ID | 外形 W×D×H mm | 同形数（板内／全体） | 便宜割当／工程 | 全適用先 | 適用工程 |
|---:|---|---|---:|---|---|---|
| 1 | [BASE3-06x10-T-838259](../kit/B/parts/BASE3-06x10-T-838259.stl) | 47.8 × 76.4 × 11.4 | 2／6 | `B-016`／5 | `B-003`、`B-007`、`B-008`、`B-012`、`B-016`、`B-017` | 2、3、4、5 |
| 2 | [BASE3-06x10-T-838259](../kit/B/parts/BASE3-06x10-T-838259.stl) | 47.8 × 76.4 × 11.4 | 2／6 | `B-017`／5 | `B-003`、`B-007`、`B-008`、`B-012`、`B-016`、`B-017` | 2、3、4、5 |
| 3 | [BR-02x04-H096](../kit/B/parts/BR-02x04-H096.stl) | 15.8 × 31.8 × 11.4 | 17／19 | `B-029`／9 | `B-029`、`B-031`、`B-036`、`B-039`、`B-042`、`B-052`、`B-055`、`B-056`、`B-058`、`B-069`、`B-072`、`B-073`、`B-075`、`B-098`、`B-101`、`B-112`、`B-115`、`B-126`、`B-129` | 9、10、11、13、15、19、21、23 |
| 4 | [BR-02x04-H096](../kit/B/parts/BR-02x04-H096.stl) | 15.8 × 31.8 × 11.4 | 17／19 | `B-031`／9 | `B-029`、`B-031`、`B-036`、`B-039`、`B-042`、`B-052`、`B-055`、`B-056`、`B-058`、`B-069`、`B-072`、`B-073`、`B-075`、`B-098`、`B-101`、`B-112`、`B-115`、`B-126`、`B-129` | 9、10、11、13、15、19、21、23 |
| 5 | [BR-02x04-H096](../kit/B/parts/BR-02x04-H096.stl) | 15.8 × 31.8 × 11.4 | 17／19 | `B-036`／10 | `B-029`、`B-031`、`B-036`、`B-039`、`B-042`、`B-052`、`B-055`、`B-056`、`B-058`、`B-069`、`B-072`、`B-073`、`B-075`、`B-098`、`B-101`、`B-112`、`B-115`、`B-126`、`B-129` | 9、10、11、13、15、19、21、23 |
| 6 | [BR-02x04-H096](../kit/B/parts/BR-02x04-H096.stl) | 15.8 × 31.8 × 11.4 | 17／19 | `B-039`／11 | `B-029`、`B-031`、`B-036`、`B-039`、`B-042`、`B-052`、`B-055`、`B-056`、`B-058`、`B-069`、`B-072`、`B-073`、`B-075`、`B-098`、`B-101`、`B-112`、`B-115`、`B-126`、`B-129` | 9、10、11、13、15、19、21、23 |
| 7 | [BR-02x04-H096](../kit/B/parts/BR-02x04-H096.stl) | 15.8 × 31.8 × 11.4 | 17／19 | `B-042`／11 | `B-029`、`B-031`、`B-036`、`B-039`、`B-042`、`B-052`、`B-055`、`B-056`、`B-058`、`B-069`、`B-072`、`B-073`、`B-075`、`B-098`、`B-101`、`B-112`、`B-115`、`B-126`、`B-129` | 9、10、11、13、15、19、21、23 |
| 8 | [BR-02x04-H096](../kit/B/parts/BR-02x04-H096.stl) | 15.8 × 31.8 × 11.4 | 17／19 | `B-052`／13 | `B-029`、`B-031`、`B-036`、`B-039`、`B-042`、`B-052`、`B-055`、`B-056`、`B-058`、`B-069`、`B-072`、`B-073`、`B-075`、`B-098`、`B-101`、`B-112`、`B-115`、`B-126`、`B-129` | 9、10、11、13、15、19、21、23 |
| 9 | [BR-02x04-H096](../kit/B/parts/BR-02x04-H096.stl) | 15.8 × 31.8 × 11.4 | 17／19 | `B-055`／13 | `B-029`、`B-031`、`B-036`、`B-039`、`B-042`、`B-052`、`B-055`、`B-056`、`B-058`、`B-069`、`B-072`、`B-073`、`B-075`、`B-098`、`B-101`、`B-112`、`B-115`、`B-126`、`B-129` | 9、10、11、13、15、19、21、23 |
| 10 | [BR-02x04-H096](../kit/B/parts/BR-02x04-H096.stl) | 15.8 × 31.8 × 11.4 | 17／19 | `B-056`／13 | `B-029`、`B-031`、`B-036`、`B-039`、`B-042`、`B-052`、`B-055`、`B-056`、`B-058`、`B-069`、`B-072`、`B-073`、`B-075`、`B-098`、`B-101`、`B-112`、`B-115`、`B-126`、`B-129` | 9、10、11、13、15、19、21、23 |
| 11 | [BR-02x04-H096](../kit/B/parts/BR-02x04-H096.stl) | 15.8 × 31.8 × 11.4 | 17／19 | `B-058`／13 | `B-029`、`B-031`、`B-036`、`B-039`、`B-042`、`B-052`、`B-055`、`B-056`、`B-058`、`B-069`、`B-072`、`B-073`、`B-075`、`B-098`、`B-101`、`B-112`、`B-115`、`B-126`、`B-129` | 9、10、11、13、15、19、21、23 |
| 12 | [BR-02x04-H096](../kit/B/parts/BR-02x04-H096.stl) | 15.8 × 31.8 × 11.4 | 17／19 | `B-069`／15 | `B-029`、`B-031`、`B-036`、`B-039`、`B-042`、`B-052`、`B-055`、`B-056`、`B-058`、`B-069`、`B-072`、`B-073`、`B-075`、`B-098`、`B-101`、`B-112`、`B-115`、`B-126`、`B-129` | 9、10、11、13、15、19、21、23 |
| 13 | [BR-02x04-H096](../kit/B/parts/BR-02x04-H096.stl) | 15.8 × 31.8 × 11.4 | 17／19 | `B-072`／15 | `B-029`、`B-031`、`B-036`、`B-039`、`B-042`、`B-052`、`B-055`、`B-056`、`B-058`、`B-069`、`B-072`、`B-073`、`B-075`、`B-098`、`B-101`、`B-112`、`B-115`、`B-126`、`B-129` | 9、10、11、13、15、19、21、23 |
| 14 | [BR-02x04-H096](../kit/B/parts/BR-02x04-H096.stl) | 15.8 × 31.8 × 11.4 | 17／19 | `B-073`／15 | `B-029`、`B-031`、`B-036`、`B-039`、`B-042`、`B-052`、`B-055`、`B-056`、`B-058`、`B-069`、`B-072`、`B-073`、`B-075`、`B-098`、`B-101`、`B-112`、`B-115`、`B-126`、`B-129` | 9、10、11、13、15、19、21、23 |
| 15 | [BR-02x04-H096](../kit/B/parts/BR-02x04-H096.stl) | 15.8 × 31.8 × 11.4 | 17／19 | `B-075`／15 | `B-029`、`B-031`、`B-036`、`B-039`、`B-042`、`B-052`、`B-055`、`B-056`、`B-058`、`B-069`、`B-072`、`B-073`、`B-075`、`B-098`、`B-101`、`B-112`、`B-115`、`B-126`、`B-129` | 9、10、11、13、15、19、21、23 |
| 16 | [BR-02x04-H096](../kit/B/parts/BR-02x04-H096.stl) | 15.8 × 31.8 × 11.4 | 17／19 | `B-098`／19 | `B-029`、`B-031`、`B-036`、`B-039`、`B-042`、`B-052`、`B-055`、`B-056`、`B-058`、`B-069`、`B-072`、`B-073`、`B-075`、`B-098`、`B-101`、`B-112`、`B-115`、`B-126`、`B-129` | 9、10、11、13、15、19、21、23 |
| 17 | [BR-02x04-H096](../kit/B/parts/BR-02x04-H096.stl) | 15.8 × 31.8 × 11.4 | 17／19 | `B-101`／19 | `B-029`、`B-031`、`B-036`、`B-039`、`B-042`、`B-052`、`B-055`、`B-056`、`B-058`、`B-069`、`B-072`、`B-073`、`B-075`、`B-098`、`B-101`、`B-112`、`B-115`、`B-126`、`B-129` | 9、10、11、13、15、19、21、23 |
| 18 | [BR-02x04-H096](../kit/B/parts/BR-02x04-H096.stl) | 15.8 × 31.8 × 11.4 | 17／19 | `B-112`／21 | `B-029`、`B-031`、`B-036`、`B-039`、`B-042`、`B-052`、`B-055`、`B-056`、`B-058`、`B-069`、`B-072`、`B-073`、`B-075`、`B-098`、`B-101`、`B-112`、`B-115`、`B-126`、`B-129` | 9、10、11、13、15、19、21、23 |
| 19 | [BR-02x04-H096](../kit/B/parts/BR-02x04-H096.stl) | 15.8 × 31.8 × 11.4 | 17／19 | `B-115`／21 | `B-029`、`B-031`、`B-036`、`B-039`、`B-042`、`B-052`、`B-055`、`B-056`、`B-058`、`B-069`、`B-072`、`B-073`、`B-075`、`B-098`、`B-101`、`B-112`、`B-115`、`B-126`、`B-129` | 9、10、11、13、15、19、21、23 |

### B-black-05.3mf

[3Dガイド](../guide/index.html)でこのファイルを選び、同じslot番号の実形状を確認します。

| slot | 部品ID | 外形 W×D×H mm | 同形数（板内／全体） | 便宜割当／工程 | 全適用先 | 適用工程 |
|---:|---|---|---:|---|---|---|
| 1 | [BR-02x04-H096](../kit/B/parts/BR-02x04-H096.stl) | 15.8 × 31.8 × 11.4 | 2／19 | `B-126`／23 | `B-029`、`B-031`、`B-036`、`B-039`、`B-042`、`B-052`、`B-055`、`B-056`、`B-058`、`B-069`、`B-072`、`B-073`、`B-075`、`B-098`、`B-101`、`B-112`、`B-115`、`B-126`、`B-129` | 9、10、11、13、15、19、21、23 |
| 2 | [BR-02x04-H096](../kit/B/parts/BR-02x04-H096.stl) | 15.8 × 31.8 × 11.4 | 2／19 | `B-129`／23 | `B-029`、`B-031`、`B-036`、`B-039`、`B-042`、`B-052`、`B-055`、`B-056`、`B-058`、`B-069`、`B-072`、`B-073`、`B-075`、`B-098`、`B-101`、`B-112`、`B-115`、`B-126`、`B-129` | 9、10、11、13、15、19、21、23 |
| 3 | [BR-03x04-H096](../kit/B/parts/BR-03x04-H096.stl) | 23.8 × 31.8 × 11.4 | 12／12 | `B-053`／13 | `B-053`、`B-059`、`B-070`、`B-076`、`B-092`、`B-095`、`B-106`、`B-109`、`B-120`、`B-123`、`B-134`、`B-137` | 13、15、18、20、22、24 |
| 4 | [BR-03x04-H096](../kit/B/parts/BR-03x04-H096.stl) | 23.8 × 31.8 × 11.4 | 12／12 | `B-059`／13 | `B-053`、`B-059`、`B-070`、`B-076`、`B-092`、`B-095`、`B-106`、`B-109`、`B-120`、`B-123`、`B-134`、`B-137` | 13、15、18、20、22、24 |
| 5 | [BR-03x04-H096](../kit/B/parts/BR-03x04-H096.stl) | 23.8 × 31.8 × 11.4 | 12／12 | `B-070`／15 | `B-053`、`B-059`、`B-070`、`B-076`、`B-092`、`B-095`、`B-106`、`B-109`、`B-120`、`B-123`、`B-134`、`B-137` | 13、15、18、20、22、24 |
| 6 | [BR-03x04-H096](../kit/B/parts/BR-03x04-H096.stl) | 23.8 × 31.8 × 11.4 | 12／12 | `B-076`／15 | `B-053`、`B-059`、`B-070`、`B-076`、`B-092`、`B-095`、`B-106`、`B-109`、`B-120`、`B-123`、`B-134`、`B-137` | 13、15、18、20、22、24 |
| 7 | [BR-03x04-H096](../kit/B/parts/BR-03x04-H096.stl) | 23.8 × 31.8 × 11.4 | 12／12 | `B-092`／18 | `B-053`、`B-059`、`B-070`、`B-076`、`B-092`、`B-095`、`B-106`、`B-109`、`B-120`、`B-123`、`B-134`、`B-137` | 13、15、18、20、22、24 |
| 8 | [BR-03x04-H096](../kit/B/parts/BR-03x04-H096.stl) | 23.8 × 31.8 × 11.4 | 12／12 | `B-095`／18 | `B-053`、`B-059`、`B-070`、`B-076`、`B-092`、`B-095`、`B-106`、`B-109`、`B-120`、`B-123`、`B-134`、`B-137` | 13、15、18、20、22、24 |
| 9 | [BR-03x04-H096](../kit/B/parts/BR-03x04-H096.stl) | 23.8 × 31.8 × 11.4 | 12／12 | `B-106`／20 | `B-053`、`B-059`、`B-070`、`B-076`、`B-092`、`B-095`、`B-106`、`B-109`、`B-120`、`B-123`、`B-134`、`B-137` | 13、15、18、20、22、24 |
| 10 | [BR-03x04-H096](../kit/B/parts/BR-03x04-H096.stl) | 23.8 × 31.8 × 11.4 | 12／12 | `B-109`／20 | `B-053`、`B-059`、`B-070`、`B-076`、`B-092`、`B-095`、`B-106`、`B-109`、`B-120`、`B-123`、`B-134`、`B-137` | 13、15、18、20、22、24 |
| 11 | [BR-03x04-H096](../kit/B/parts/BR-03x04-H096.stl) | 23.8 × 31.8 × 11.4 | 12／12 | `B-120`／22 | `B-053`、`B-059`、`B-070`、`B-076`、`B-092`、`B-095`、`B-106`、`B-109`、`B-120`、`B-123`、`B-134`、`B-137` | 13、15、18、20、22、24 |
| 12 | [BR-03x04-H096](../kit/B/parts/BR-03x04-H096.stl) | 23.8 × 31.8 × 11.4 | 12／12 | `B-123`／22 | `B-053`、`B-059`、`B-070`、`B-076`、`B-092`、`B-095`、`B-106`、`B-109`、`B-120`、`B-123`、`B-134`、`B-137` | 13、15、18、20、22、24 |
| 13 | [BR-03x04-H096](../kit/B/parts/BR-03x04-H096.stl) | 23.8 × 31.8 × 11.4 | 12／12 | `B-134`／24 | `B-053`、`B-059`、`B-070`、`B-076`、`B-092`、`B-095`、`B-106`、`B-109`、`B-120`、`B-123`、`B-134`、`B-137` | 13、15、18、20、22、24 |
| 14 | [BR-03x04-H096](../kit/B/parts/BR-03x04-H096.stl) | 23.8 × 31.8 × 11.4 | 12／12 | `B-137`／24 | `B-053`、`B-059`、`B-070`、`B-076`、`B-092`、`B-095`、`B-106`、`B-109`、`B-120`、`B-123`、`B-134`、`B-137` | 13、15、18、20、22、24 |
| 15 | [BR-04x04-H096](../kit/B/parts/BR-04x04-H096.stl) | 31.8 × 31.8 × 11.4 | 6／21 | `B-030`／9 | `B-030`、`B-034`、`B-035`、`B-040`、`B-041`、`B-045`、`B-047`、`B-049`、`B-064`、`B-079`、`B-080`、`B-081`、`B-082`、`B-091`、`B-094`、`B-105`、`B-108`、`B-119`、`B-122`、`B-133`、`B-136` | 9、10、11、12、14、16、18、20、22、24 |
| 16 | [BR-04x04-H096](../kit/B/parts/BR-04x04-H096.stl) | 31.8 × 31.8 × 11.4 | 6／21 | `B-034`／10 | `B-030`、`B-034`、`B-035`、`B-040`、`B-041`、`B-045`、`B-047`、`B-049`、`B-064`、`B-079`、`B-080`、`B-081`、`B-082`、`B-091`、`B-094`、`B-105`、`B-108`、`B-119`、`B-122`、`B-133`、`B-136` | 9、10、11、12、14、16、18、20、22、24 |
| 17 | [BR-04x04-H096](../kit/B/parts/BR-04x04-H096.stl) | 31.8 × 31.8 × 11.4 | 6／21 | `B-035`／10 | `B-030`、`B-034`、`B-035`、`B-040`、`B-041`、`B-045`、`B-047`、`B-049`、`B-064`、`B-079`、`B-080`、`B-081`、`B-082`、`B-091`、`B-094`、`B-105`、`B-108`、`B-119`、`B-122`、`B-133`、`B-136` | 9、10、11、12、14、16、18、20、22、24 |
| 18 | [BR-04x04-H096](../kit/B/parts/BR-04x04-H096.stl) | 31.8 × 31.8 × 11.4 | 6／21 | `B-040`／11 | `B-030`、`B-034`、`B-035`、`B-040`、`B-041`、`B-045`、`B-047`、`B-049`、`B-064`、`B-079`、`B-080`、`B-081`、`B-082`、`B-091`、`B-094`、`B-105`、`B-108`、`B-119`、`B-122`、`B-133`、`B-136` | 9、10、11、12、14、16、18、20、22、24 |
| 19 | [BR-04x04-H096](../kit/B/parts/BR-04x04-H096.stl) | 31.8 × 31.8 × 11.4 | 6／21 | `B-041`／11 | `B-030`、`B-034`、`B-035`、`B-040`、`B-041`、`B-045`、`B-047`、`B-049`、`B-064`、`B-079`、`B-080`、`B-081`、`B-082`、`B-091`、`B-094`、`B-105`、`B-108`、`B-119`、`B-122`、`B-133`、`B-136` | 9、10、11、12、14、16、18、20、22、24 |
| 20 | [BR-04x04-H096](../kit/B/parts/BR-04x04-H096.stl) | 31.8 × 31.8 × 11.4 | 6／21 | `B-045`／12 | `B-030`、`B-034`、`B-035`、`B-040`、`B-041`、`B-045`、`B-047`、`B-049`、`B-064`、`B-079`、`B-080`、`B-081`、`B-082`、`B-091`、`B-094`、`B-105`、`B-108`、`B-119`、`B-122`、`B-133`、`B-136` | 9、10、11、12、14、16、18、20、22、24 |

### B-black-06.3mf

[3Dガイド](../guide/index.html)でこのファイルを選び、同じslot番号の実形状を確認します。

| slot | 部品ID | 外形 W×D×H mm | 同形数（板内／全体） | 便宜割当／工程 | 全適用先 | 適用工程 |
|---:|---|---|---:|---|---|---|
| 1 | [BR-04x04-H096](../kit/B/parts/BR-04x04-H096.stl) | 31.8 × 31.8 × 11.4 | 15／21 | `B-047`／12 | `B-030`、`B-034`、`B-035`、`B-040`、`B-041`、`B-045`、`B-047`、`B-049`、`B-064`、`B-079`、`B-080`、`B-081`、`B-082`、`B-091`、`B-094`、`B-105`、`B-108`、`B-119`、`B-122`、`B-133`、`B-136` | 9、10、11、12、14、16、18、20、22、24 |
| 2 | [BR-04x04-H096](../kit/B/parts/BR-04x04-H096.stl) | 31.8 × 31.8 × 11.4 | 15／21 | `B-049`／12 | `B-030`、`B-034`、`B-035`、`B-040`、`B-041`、`B-045`、`B-047`、`B-049`、`B-064`、`B-079`、`B-080`、`B-081`、`B-082`、`B-091`、`B-094`、`B-105`、`B-108`、`B-119`、`B-122`、`B-133`、`B-136` | 9、10、11、12、14、16、18、20、22、24 |
| 3 | [BR-04x04-H096](../kit/B/parts/BR-04x04-H096.stl) | 31.8 × 31.8 × 11.4 | 15／21 | `B-064`／14 | `B-030`、`B-034`、`B-035`、`B-040`、`B-041`、`B-045`、`B-047`、`B-049`、`B-064`、`B-079`、`B-080`、`B-081`、`B-082`、`B-091`、`B-094`、`B-105`、`B-108`、`B-119`、`B-122`、`B-133`、`B-136` | 9、10、11、12、14、16、18、20、22、24 |
| 4 | [BR-04x04-H096](../kit/B/parts/BR-04x04-H096.stl) | 31.8 × 31.8 × 11.4 | 15／21 | `B-079`／16 | `B-030`、`B-034`、`B-035`、`B-040`、`B-041`、`B-045`、`B-047`、`B-049`、`B-064`、`B-079`、`B-080`、`B-081`、`B-082`、`B-091`、`B-094`、`B-105`、`B-108`、`B-119`、`B-122`、`B-133`、`B-136` | 9、10、11、12、14、16、18、20、22、24 |
| 5 | [BR-04x04-H096](../kit/B/parts/BR-04x04-H096.stl) | 31.8 × 31.8 × 11.4 | 15／21 | `B-080`／16 | `B-030`、`B-034`、`B-035`、`B-040`、`B-041`、`B-045`、`B-047`、`B-049`、`B-064`、`B-079`、`B-080`、`B-081`、`B-082`、`B-091`、`B-094`、`B-105`、`B-108`、`B-119`、`B-122`、`B-133`、`B-136` | 9、10、11、12、14、16、18、20、22、24 |
| 6 | [BR-04x04-H096](../kit/B/parts/BR-04x04-H096.stl) | 31.8 × 31.8 × 11.4 | 15／21 | `B-081`／16 | `B-030`、`B-034`、`B-035`、`B-040`、`B-041`、`B-045`、`B-047`、`B-049`、`B-064`、`B-079`、`B-080`、`B-081`、`B-082`、`B-091`、`B-094`、`B-105`、`B-108`、`B-119`、`B-122`、`B-133`、`B-136` | 9、10、11、12、14、16、18、20、22、24 |
| 7 | [BR-04x04-H096](../kit/B/parts/BR-04x04-H096.stl) | 31.8 × 31.8 × 11.4 | 15／21 | `B-082`／16 | `B-030`、`B-034`、`B-035`、`B-040`、`B-041`、`B-045`、`B-047`、`B-049`、`B-064`、`B-079`、`B-080`、`B-081`、`B-082`、`B-091`、`B-094`、`B-105`、`B-108`、`B-119`、`B-122`、`B-133`、`B-136` | 9、10、11、12、14、16、18、20、22、24 |
| 8 | [BR-04x04-H096](../kit/B/parts/BR-04x04-H096.stl) | 31.8 × 31.8 × 11.4 | 15／21 | `B-091`／18 | `B-030`、`B-034`、`B-035`、`B-040`、`B-041`、`B-045`、`B-047`、`B-049`、`B-064`、`B-079`、`B-080`、`B-081`、`B-082`、`B-091`、`B-094`、`B-105`、`B-108`、`B-119`、`B-122`、`B-133`、`B-136` | 9、10、11、12、14、16、18、20、22、24 |
| 9 | [BR-04x04-H096](../kit/B/parts/BR-04x04-H096.stl) | 31.8 × 31.8 × 11.4 | 15／21 | `B-094`／18 | `B-030`、`B-034`、`B-035`、`B-040`、`B-041`、`B-045`、`B-047`、`B-049`、`B-064`、`B-079`、`B-080`、`B-081`、`B-082`、`B-091`、`B-094`、`B-105`、`B-108`、`B-119`、`B-122`、`B-133`、`B-136` | 9、10、11、12、14、16、18、20、22、24 |
| 10 | [BR-04x04-H096](../kit/B/parts/BR-04x04-H096.stl) | 31.8 × 31.8 × 11.4 | 15／21 | `B-105`／20 | `B-030`、`B-034`、`B-035`、`B-040`、`B-041`、`B-045`、`B-047`、`B-049`、`B-064`、`B-079`、`B-080`、`B-081`、`B-082`、`B-091`、`B-094`、`B-105`、`B-108`、`B-119`、`B-122`、`B-133`、`B-136` | 9、10、11、12、14、16、18、20、22、24 |
| 11 | [BR-04x04-H096](../kit/B/parts/BR-04x04-H096.stl) | 31.8 × 31.8 × 11.4 | 15／21 | `B-108`／20 | `B-030`、`B-034`、`B-035`、`B-040`、`B-041`、`B-045`、`B-047`、`B-049`、`B-064`、`B-079`、`B-080`、`B-081`、`B-082`、`B-091`、`B-094`、`B-105`、`B-108`、`B-119`、`B-122`、`B-133`、`B-136` | 9、10、11、12、14、16、18、20、22、24 |
| 12 | [BR-04x04-H096](../kit/B/parts/BR-04x04-H096.stl) | 31.8 × 31.8 × 11.4 | 15／21 | `B-119`／22 | `B-030`、`B-034`、`B-035`、`B-040`、`B-041`、`B-045`、`B-047`、`B-049`、`B-064`、`B-079`、`B-080`、`B-081`、`B-082`、`B-091`、`B-094`、`B-105`、`B-108`、`B-119`、`B-122`、`B-133`、`B-136` | 9、10、11、12、14、16、18、20、22、24 |
| 13 | [BR-04x04-H096](../kit/B/parts/BR-04x04-H096.stl) | 31.8 × 31.8 × 11.4 | 15／21 | `B-122`／22 | `B-030`、`B-034`、`B-035`、`B-040`、`B-041`、`B-045`、`B-047`、`B-049`、`B-064`、`B-079`、`B-080`、`B-081`、`B-082`、`B-091`、`B-094`、`B-105`、`B-108`、`B-119`、`B-122`、`B-133`、`B-136` | 9、10、11、12、14、16、18、20、22、24 |
| 14 | [BR-04x04-H096](../kit/B/parts/BR-04x04-H096.stl) | 31.8 × 31.8 × 11.4 | 15／21 | `B-133`／24 | `B-030`、`B-034`、`B-035`、`B-040`、`B-041`、`B-045`、`B-047`、`B-049`、`B-064`、`B-079`、`B-080`、`B-081`、`B-082`、`B-091`、`B-094`、`B-105`、`B-108`、`B-119`、`B-122`、`B-133`、`B-136` | 9、10、11、12、14、16、18、20、22、24 |
| 15 | [BR-04x04-H096](../kit/B/parts/BR-04x04-H096.stl) | 31.8 × 31.8 × 11.4 | 15／21 | `B-136`／24 | `B-030`、`B-034`、`B-035`、`B-040`、`B-041`、`B-045`、`B-047`、`B-049`、`B-064`、`B-079`、`B-080`、`B-081`、`B-082`、`B-091`、`B-094`、`B-105`、`B-108`、`B-119`、`B-122`、`B-133`、`B-136` | 9、10、11、12、14、16、18、20、22、24 |
| 16 | [BR-05x04-H096](../kit/B/parts/BR-05x04-H096.stl) | 39.8 × 31.8 × 11.4 | 1／8 | `B-062`／14 | `B-062`、`B-066`、`B-099`、`B-102`、`B-113`、`B-116`、`B-127`、`B-130` | 14、19、21、23 |

### B-black-07.3mf

[3Dガイド](../guide/index.html)でこのファイルを選び、同じslot番号の実形状を確認します。

| slot | 部品ID | 外形 W×D×H mm | 同形数（板内／全体） | 便宜割当／工程 | 全適用先 | 適用工程 |
|---:|---|---|---:|---|---|---|
| 1 | [BR-05x04-H096](../kit/B/parts/BR-05x04-H096.stl) | 39.8 × 31.8 × 11.4 | 7／8 | `B-066`／14 | `B-062`、`B-066`、`B-099`、`B-102`、`B-113`、`B-116`、`B-127`、`B-130` | 14、19、21、23 |
| 2 | [BR-05x04-H096](../kit/B/parts/BR-05x04-H096.stl) | 39.8 × 31.8 × 11.4 | 7／8 | `B-099`／19 | `B-062`、`B-066`、`B-099`、`B-102`、`B-113`、`B-116`、`B-127`、`B-130` | 14、19、21、23 |
| 3 | [BR-05x04-H096](../kit/B/parts/BR-05x04-H096.stl) | 39.8 × 31.8 × 11.4 | 7／8 | `B-102`／19 | `B-062`、`B-066`、`B-099`、`B-102`、`B-113`、`B-116`、`B-127`、`B-130` | 14、19、21、23 |
| 4 | [BR-05x04-H096](../kit/B/parts/BR-05x04-H096.stl) | 39.8 × 31.8 × 11.4 | 7／8 | `B-113`／21 | `B-062`、`B-066`、`B-099`、`B-102`、`B-113`、`B-116`、`B-127`、`B-130` | 14、19、21、23 |
| 5 | [BR-05x04-H096](../kit/B/parts/BR-05x04-H096.stl) | 39.8 × 31.8 × 11.4 | 7／8 | `B-116`／21 | `B-062`、`B-066`、`B-099`、`B-102`、`B-113`、`B-116`、`B-127`、`B-130` | 14、19、21、23 |
| 6 | [BR-05x04-H096](../kit/B/parts/BR-05x04-H096.stl) | 39.8 × 31.8 × 11.4 | 7／8 | `B-127`／23 | `B-062`、`B-066`、`B-099`、`B-102`、`B-113`、`B-116`、`B-127`、`B-130` | 14、19、21、23 |
| 7 | [BR-05x04-H096](../kit/B/parts/BR-05x04-H096.stl) | 39.8 × 31.8 × 11.4 | 7／8 | `B-130`／23 | `B-062`、`B-066`、`B-099`、`B-102`、`B-113`、`B-116`、`B-127`、`B-130` | 14、19、21、23 |
| 8 | [NP3-KEEPER](../kit/B/parts/NP3-KEEPER.stl) | 15.8 × 15.8 × 3.2 | 3／3 | `B-022`／7 | `B-022`、`B-023`、`B-024` | 7 |
| 9 | [NP3-KEEPER](../kit/B/parts/NP3-KEEPER.stl) | 15.8 × 15.8 × 3.2 | 3／3 | `B-023`／7 | `B-022`、`B-023`、`B-024` | 7 |
| 10 | [NP3-KEEPER](../kit/B/parts/NP3-KEEPER.stl) | 15.8 × 15.8 × 3.2 | 3／3 | `B-024`／7 | `B-022`、`B-023`、`B-024` | 7 |

### B-cyan-01.3mf

[3Dガイド](../guide/index.html)でこのファイルを選び、同じslot番号の実形状を確認します。

| slot | 部品ID | 外形 W×D×H mm | 同形数（板内／全体） | 便宜割当／工程 | 全適用先 | 適用工程 |
|---:|---|---|---:|---|---|---|
| 1 | [BR-02x05-H096](../kit/B/parts/BR-02x05-H096.stl) | 15.8 × 39.8 × 11.4 | 24／24 | `B-084`／17 | `B-084`、`B-089`、`B-090`、`B-093`、`B-096`、`B-097`、`B-100`、`B-103`、`B-104`、`B-107`、`B-110`、`B-111`、`B-114`、`B-117`、`B-118`、`B-121`、`B-124`、`B-125`、`B-128`、`B-131`、`B-132`、`B-135`、`B-138`、`B-139` | 17、18、19、20、21、22、23、24、25 |
| 2 | [BR-02x05-H096](../kit/B/parts/BR-02x05-H096.stl) | 15.8 × 39.8 × 11.4 | 24／24 | `B-089`／17 | `B-084`、`B-089`、`B-090`、`B-093`、`B-096`、`B-097`、`B-100`、`B-103`、`B-104`、`B-107`、`B-110`、`B-111`、`B-114`、`B-117`、`B-118`、`B-121`、`B-124`、`B-125`、`B-128`、`B-131`、`B-132`、`B-135`、`B-138`、`B-139` | 17、18、19、20、21、22、23、24、25 |
| 3 | [BR-02x05-H096](../kit/B/parts/BR-02x05-H096.stl) | 15.8 × 39.8 × 11.4 | 24／24 | `B-090`／18 | `B-084`、`B-089`、`B-090`、`B-093`、`B-096`、`B-097`、`B-100`、`B-103`、`B-104`、`B-107`、`B-110`、`B-111`、`B-114`、`B-117`、`B-118`、`B-121`、`B-124`、`B-125`、`B-128`、`B-131`、`B-132`、`B-135`、`B-138`、`B-139` | 17、18、19、20、21、22、23、24、25 |
| 4 | [BR-02x05-H096](../kit/B/parts/BR-02x05-H096.stl) | 15.8 × 39.8 × 11.4 | 24／24 | `B-093`／18 | `B-084`、`B-089`、`B-090`、`B-093`、`B-096`、`B-097`、`B-100`、`B-103`、`B-104`、`B-107`、`B-110`、`B-111`、`B-114`、`B-117`、`B-118`、`B-121`、`B-124`、`B-125`、`B-128`、`B-131`、`B-132`、`B-135`、`B-138`、`B-139` | 17、18、19、20、21、22、23、24、25 |
| 5 | [BR-02x05-H096](../kit/B/parts/BR-02x05-H096.stl) | 15.8 × 39.8 × 11.4 | 24／24 | `B-096`／18 | `B-084`、`B-089`、`B-090`、`B-093`、`B-096`、`B-097`、`B-100`、`B-103`、`B-104`、`B-107`、`B-110`、`B-111`、`B-114`、`B-117`、`B-118`、`B-121`、`B-124`、`B-125`、`B-128`、`B-131`、`B-132`、`B-135`、`B-138`、`B-139` | 17、18、19、20、21、22、23、24、25 |
| 6 | [BR-02x05-H096](../kit/B/parts/BR-02x05-H096.stl) | 15.8 × 39.8 × 11.4 | 24／24 | `B-097`／19 | `B-084`、`B-089`、`B-090`、`B-093`、`B-096`、`B-097`、`B-100`、`B-103`、`B-104`、`B-107`、`B-110`、`B-111`、`B-114`、`B-117`、`B-118`、`B-121`、`B-124`、`B-125`、`B-128`、`B-131`、`B-132`、`B-135`、`B-138`、`B-139` | 17、18、19、20、21、22、23、24、25 |
| 7 | [BR-02x05-H096](../kit/B/parts/BR-02x05-H096.stl) | 15.8 × 39.8 × 11.4 | 24／24 | `B-100`／19 | `B-084`、`B-089`、`B-090`、`B-093`、`B-096`、`B-097`、`B-100`、`B-103`、`B-104`、`B-107`、`B-110`、`B-111`、`B-114`、`B-117`、`B-118`、`B-121`、`B-124`、`B-125`、`B-128`、`B-131`、`B-132`、`B-135`、`B-138`、`B-139` | 17、18、19、20、21、22、23、24、25 |
| 8 | [BR-02x05-H096](../kit/B/parts/BR-02x05-H096.stl) | 15.8 × 39.8 × 11.4 | 24／24 | `B-103`／19 | `B-084`、`B-089`、`B-090`、`B-093`、`B-096`、`B-097`、`B-100`、`B-103`、`B-104`、`B-107`、`B-110`、`B-111`、`B-114`、`B-117`、`B-118`、`B-121`、`B-124`、`B-125`、`B-128`、`B-131`、`B-132`、`B-135`、`B-138`、`B-139` | 17、18、19、20、21、22、23、24、25 |
| 9 | [BR-02x05-H096](../kit/B/parts/BR-02x05-H096.stl) | 15.8 × 39.8 × 11.4 | 24／24 | `B-104`／20 | `B-084`、`B-089`、`B-090`、`B-093`、`B-096`、`B-097`、`B-100`、`B-103`、`B-104`、`B-107`、`B-110`、`B-111`、`B-114`、`B-117`、`B-118`、`B-121`、`B-124`、`B-125`、`B-128`、`B-131`、`B-132`、`B-135`、`B-138`、`B-139` | 17、18、19、20、21、22、23、24、25 |
| 10 | [BR-02x05-H096](../kit/B/parts/BR-02x05-H096.stl) | 15.8 × 39.8 × 11.4 | 24／24 | `B-107`／20 | `B-084`、`B-089`、`B-090`、`B-093`、`B-096`、`B-097`、`B-100`、`B-103`、`B-104`、`B-107`、`B-110`、`B-111`、`B-114`、`B-117`、`B-118`、`B-121`、`B-124`、`B-125`、`B-128`、`B-131`、`B-132`、`B-135`、`B-138`、`B-139` | 17、18、19、20、21、22、23、24、25 |
| 11 | [BR-02x05-H096](../kit/B/parts/BR-02x05-H096.stl) | 15.8 × 39.8 × 11.4 | 24／24 | `B-110`／20 | `B-084`、`B-089`、`B-090`、`B-093`、`B-096`、`B-097`、`B-100`、`B-103`、`B-104`、`B-107`、`B-110`、`B-111`、`B-114`、`B-117`、`B-118`、`B-121`、`B-124`、`B-125`、`B-128`、`B-131`、`B-132`、`B-135`、`B-138`、`B-139` | 17、18、19、20、21、22、23、24、25 |
| 12 | [BR-02x05-H096](../kit/B/parts/BR-02x05-H096.stl) | 15.8 × 39.8 × 11.4 | 24／24 | `B-111`／21 | `B-084`、`B-089`、`B-090`、`B-093`、`B-096`、`B-097`、`B-100`、`B-103`、`B-104`、`B-107`、`B-110`、`B-111`、`B-114`、`B-117`、`B-118`、`B-121`、`B-124`、`B-125`、`B-128`、`B-131`、`B-132`、`B-135`、`B-138`、`B-139` | 17、18、19、20、21、22、23、24、25 |
| 13 | [BR-02x05-H096](../kit/B/parts/BR-02x05-H096.stl) | 15.8 × 39.8 × 11.4 | 24／24 | `B-114`／21 | `B-084`、`B-089`、`B-090`、`B-093`、`B-096`、`B-097`、`B-100`、`B-103`、`B-104`、`B-107`、`B-110`、`B-111`、`B-114`、`B-117`、`B-118`、`B-121`、`B-124`、`B-125`、`B-128`、`B-131`、`B-132`、`B-135`、`B-138`、`B-139` | 17、18、19、20、21、22、23、24、25 |
| 14 | [BR-02x05-H096](../kit/B/parts/BR-02x05-H096.stl) | 15.8 × 39.8 × 11.4 | 24／24 | `B-117`／21 | `B-084`、`B-089`、`B-090`、`B-093`、`B-096`、`B-097`、`B-100`、`B-103`、`B-104`、`B-107`、`B-110`、`B-111`、`B-114`、`B-117`、`B-118`、`B-121`、`B-124`、`B-125`、`B-128`、`B-131`、`B-132`、`B-135`、`B-138`、`B-139` | 17、18、19、20、21、22、23、24、25 |
| 15 | [BR-02x05-H096](../kit/B/parts/BR-02x05-H096.stl) | 15.8 × 39.8 × 11.4 | 24／24 | `B-118`／22 | `B-084`、`B-089`、`B-090`、`B-093`、`B-096`、`B-097`、`B-100`、`B-103`、`B-104`、`B-107`、`B-110`、`B-111`、`B-114`、`B-117`、`B-118`、`B-121`、`B-124`、`B-125`、`B-128`、`B-131`、`B-132`、`B-135`、`B-138`、`B-139` | 17、18、19、20、21、22、23、24、25 |
| 16 | [BR-02x05-H096](../kit/B/parts/BR-02x05-H096.stl) | 15.8 × 39.8 × 11.4 | 24／24 | `B-121`／22 | `B-084`、`B-089`、`B-090`、`B-093`、`B-096`、`B-097`、`B-100`、`B-103`、`B-104`、`B-107`、`B-110`、`B-111`、`B-114`、`B-117`、`B-118`、`B-121`、`B-124`、`B-125`、`B-128`、`B-131`、`B-132`、`B-135`、`B-138`、`B-139` | 17、18、19、20、21、22、23、24、25 |
| 17 | [BR-02x05-H096](../kit/B/parts/BR-02x05-H096.stl) | 15.8 × 39.8 × 11.4 | 24／24 | `B-124`／22 | `B-084`、`B-089`、`B-090`、`B-093`、`B-096`、`B-097`、`B-100`、`B-103`、`B-104`、`B-107`、`B-110`、`B-111`、`B-114`、`B-117`、`B-118`、`B-121`、`B-124`、`B-125`、`B-128`、`B-131`、`B-132`、`B-135`、`B-138`、`B-139` | 17、18、19、20、21、22、23、24、25 |
| 18 | [BR-02x05-H096](../kit/B/parts/BR-02x05-H096.stl) | 15.8 × 39.8 × 11.4 | 24／24 | `B-125`／23 | `B-084`、`B-089`、`B-090`、`B-093`、`B-096`、`B-097`、`B-100`、`B-103`、`B-104`、`B-107`、`B-110`、`B-111`、`B-114`、`B-117`、`B-118`、`B-121`、`B-124`、`B-125`、`B-128`、`B-131`、`B-132`、`B-135`、`B-138`、`B-139` | 17、18、19、20、21、22、23、24、25 |
| 19 | [BR-02x05-H096](../kit/B/parts/BR-02x05-H096.stl) | 15.8 × 39.8 × 11.4 | 24／24 | `B-128`／23 | `B-084`、`B-089`、`B-090`、`B-093`、`B-096`、`B-097`、`B-100`、`B-103`、`B-104`、`B-107`、`B-110`、`B-111`、`B-114`、`B-117`、`B-118`、`B-121`、`B-124`、`B-125`、`B-128`、`B-131`、`B-132`、`B-135`、`B-138`、`B-139` | 17、18、19、20、21、22、23、24、25 |
| 20 | [BR-02x05-H096](../kit/B/parts/BR-02x05-H096.stl) | 15.8 × 39.8 × 11.4 | 24／24 | `B-131`／23 | `B-084`、`B-089`、`B-090`、`B-093`、`B-096`、`B-097`、`B-100`、`B-103`、`B-104`、`B-107`、`B-110`、`B-111`、`B-114`、`B-117`、`B-118`、`B-121`、`B-124`、`B-125`、`B-128`、`B-131`、`B-132`、`B-135`、`B-138`、`B-139` | 17、18、19、20、21、22、23、24、25 |
| 21 | [BR-02x05-H096](../kit/B/parts/BR-02x05-H096.stl) | 15.8 × 39.8 × 11.4 | 24／24 | `B-132`／24 | `B-084`、`B-089`、`B-090`、`B-093`、`B-096`、`B-097`、`B-100`、`B-103`、`B-104`、`B-107`、`B-110`、`B-111`、`B-114`、`B-117`、`B-118`、`B-121`、`B-124`、`B-125`、`B-128`、`B-131`、`B-132`、`B-135`、`B-138`、`B-139` | 17、18、19、20、21、22、23、24、25 |
| 22 | [BR-02x05-H096](../kit/B/parts/BR-02x05-H096.stl) | 15.8 × 39.8 × 11.4 | 24／24 | `B-135`／24 | `B-084`、`B-089`、`B-090`、`B-093`、`B-096`、`B-097`、`B-100`、`B-103`、`B-104`、`B-107`、`B-110`、`B-111`、`B-114`、`B-117`、`B-118`、`B-121`、`B-124`、`B-125`、`B-128`、`B-131`、`B-132`、`B-135`、`B-138`、`B-139` | 17、18、19、20、21、22、23、24、25 |
| 23 | [BR-02x05-H096](../kit/B/parts/BR-02x05-H096.stl) | 15.8 × 39.8 × 11.4 | 24／24 | `B-138`／24 | `B-084`、`B-089`、`B-090`、`B-093`、`B-096`、`B-097`、`B-100`、`B-103`、`B-104`、`B-107`、`B-110`、`B-111`、`B-114`、`B-117`、`B-118`、`B-121`、`B-124`、`B-125`、`B-128`、`B-131`、`B-132`、`B-135`、`B-138`、`B-139` | 17、18、19、20、21、22、23、24、25 |
| 24 | [BR-02x05-H096](../kit/B/parts/BR-02x05-H096.stl) | 15.8 × 39.8 × 11.4 | 24／24 | `B-139`／25 | `B-084`、`B-089`、`B-090`、`B-093`、`B-096`、`B-097`、`B-100`、`B-103`、`B-104`、`B-107`、`B-110`、`B-111`、`B-114`、`B-117`、`B-118`、`B-121`、`B-124`、`B-125`、`B-128`、`B-131`、`B-132`、`B-135`、`B-138`、`B-139` | 17、18、19、20、21、22、23、24、25 |
| 25 | [BR-04x05-H096](../kit/B/parts/BR-04x05-H096.stl) | 31.8 × 39.8 × 11.4 | 2／12 | `B-085`／17 | `B-085`、`B-086`、`B-087`、`B-088`、`B-140`、`B-141`、`B-142`、`B-143`、`B-144`、`B-145`、`B-146`、`B-147` | 17、25、26 |
| 26 | [BR-04x05-H096](../kit/B/parts/BR-04x05-H096.stl) | 31.8 × 39.8 × 11.4 | 2／12 | `B-086`／17 | `B-085`、`B-086`、`B-087`、`B-088`、`B-140`、`B-141`、`B-142`、`B-143`、`B-144`、`B-145`、`B-146`、`B-147` | 17、25、26 |

### B-cyan-02.3mf

[3Dガイド](../guide/index.html)でこのファイルを選び、同じslot番号の実形状を確認します。

| slot | 部品ID | 外形 W×D×H mm | 同形数（板内／全体） | 便宜割当／工程 | 全適用先 | 適用工程 |
|---:|---|---|---:|---|---|---|
| 1 | [BR-04x05-H096](../kit/B/parts/BR-04x05-H096.stl) | 31.8 × 39.8 × 11.4 | 10／12 | `B-087`／17 | `B-085`、`B-086`、`B-087`、`B-088`、`B-140`、`B-141`、`B-142`、`B-143`、`B-144`、`B-145`、`B-146`、`B-147` | 17、25、26 |
| 2 | [BR-04x05-H096](../kit/B/parts/BR-04x05-H096.stl) | 31.8 × 39.8 × 11.4 | 10／12 | `B-088`／17 | `B-085`、`B-086`、`B-087`、`B-088`、`B-140`、`B-141`、`B-142`、`B-143`、`B-144`、`B-145`、`B-146`、`B-147` | 17、25、26 |
| 3 | [BR-04x05-H096](../kit/B/parts/BR-04x05-H096.stl) | 31.8 × 39.8 × 11.4 | 10／12 | `B-140`／25 | `B-085`、`B-086`、`B-087`、`B-088`、`B-140`、`B-141`、`B-142`、`B-143`、`B-144`、`B-145`、`B-146`、`B-147` | 17、25、26 |
| 4 | [BR-04x05-H096](../kit/B/parts/BR-04x05-H096.stl) | 31.8 × 39.8 × 11.4 | 10／12 | `B-141`／25 | `B-085`、`B-086`、`B-087`、`B-088`、`B-140`、`B-141`、`B-142`、`B-143`、`B-144`、`B-145`、`B-146`、`B-147` | 17、25、26 |
| 5 | [BR-04x05-H096](../kit/B/parts/BR-04x05-H096.stl) | 31.8 × 39.8 × 11.4 | 10／12 | `B-142`／25 | `B-085`、`B-086`、`B-087`、`B-088`、`B-140`、`B-141`、`B-142`、`B-143`、`B-144`、`B-145`、`B-146`、`B-147` | 17、25、26 |
| 6 | [BR-04x05-H096](../kit/B/parts/BR-04x05-H096.stl) | 31.8 × 39.8 × 11.4 | 10／12 | `B-143`／25 | `B-085`、`B-086`、`B-087`、`B-088`、`B-140`、`B-141`、`B-142`、`B-143`、`B-144`、`B-145`、`B-146`、`B-147` | 17、25、26 |
| 7 | [BR-04x05-H096](../kit/B/parts/BR-04x05-H096.stl) | 31.8 × 39.8 × 11.4 | 10／12 | `B-144`／26 | `B-085`、`B-086`、`B-087`、`B-088`、`B-140`、`B-141`、`B-142`、`B-143`、`B-144`、`B-145`、`B-146`、`B-147` | 17、25、26 |
| 8 | [BR-04x05-H096](../kit/B/parts/BR-04x05-H096.stl) | 31.8 × 39.8 × 11.4 | 10／12 | `B-145`／26 | `B-085`、`B-086`、`B-087`、`B-088`、`B-140`、`B-141`、`B-142`、`B-143`、`B-144`、`B-145`、`B-146`、`B-147` | 17、25、26 |
| 9 | [BR-04x05-H096](../kit/B/parts/BR-04x05-H096.stl) | 31.8 × 39.8 × 11.4 | 10／12 | `B-146`／26 | `B-085`、`B-086`、`B-087`、`B-088`、`B-140`、`B-141`、`B-142`、`B-143`、`B-144`、`B-145`、`B-146`、`B-147` | 17、25、26 |
| 10 | [BR-04x05-H096](../kit/B/parts/BR-04x05-H096.stl) | 31.8 × 39.8 × 11.4 | 10／12 | `B-147`／26 | `B-085`、`B-086`、`B-087`、`B-088`、`B-140`、`B-141`、`B-142`、`B-143`、`B-144`、`B-145`、`B-146`、`B-147` | 17、25、26 |

### B-magenta-01.3mf

[3Dガイド](../guide/index.html)でこのファイルを選び、同じslot番号の実形状を確認します。

| slot | 部品ID | 外形 W×D×H mm | 同形数（板内／全体） | 便宜割当／工程 | 全適用先 | 適用工程 |
|---:|---|---|---:|---|---|---|
| 1 | [BR-02x06-H096](../kit/B/parts/BR-02x06-H096.stl) | 15.8 × 47.8 × 11.4 | 16／16 | `B-028`／9 | `B-028`、`B-032`、`B-033`、`B-037`、`B-038`、`B-043`、`B-044`、`B-050`、`B-051`、`B-060`、`B-061`、`B-067`、`B-068`、`B-077`、`B-078`、`B-083` | 9、10、11、12、13、14、15、16 |
| 2 | [BR-02x06-H096](../kit/B/parts/BR-02x06-H096.stl) | 15.8 × 47.8 × 11.4 | 16／16 | `B-032`／9 | `B-028`、`B-032`、`B-033`、`B-037`、`B-038`、`B-043`、`B-044`、`B-050`、`B-051`、`B-060`、`B-061`、`B-067`、`B-068`、`B-077`、`B-078`、`B-083` | 9、10、11、12、13、14、15、16 |
| 3 | [BR-02x06-H096](../kit/B/parts/BR-02x06-H096.stl) | 15.8 × 47.8 × 11.4 | 16／16 | `B-033`／10 | `B-028`、`B-032`、`B-033`、`B-037`、`B-038`、`B-043`、`B-044`、`B-050`、`B-051`、`B-060`、`B-061`、`B-067`、`B-068`、`B-077`、`B-078`、`B-083` | 9、10、11、12、13、14、15、16 |
| 4 | [BR-02x06-H096](../kit/B/parts/BR-02x06-H096.stl) | 15.8 × 47.8 × 11.4 | 16／16 | `B-037`／10 | `B-028`、`B-032`、`B-033`、`B-037`、`B-038`、`B-043`、`B-044`、`B-050`、`B-051`、`B-060`、`B-061`、`B-067`、`B-068`、`B-077`、`B-078`、`B-083` | 9、10、11、12、13、14、15、16 |
| 5 | [BR-02x06-H096](../kit/B/parts/BR-02x06-H096.stl) | 15.8 × 47.8 × 11.4 | 16／16 | `B-038`／11 | `B-028`、`B-032`、`B-033`、`B-037`、`B-038`、`B-043`、`B-044`、`B-050`、`B-051`、`B-060`、`B-061`、`B-067`、`B-068`、`B-077`、`B-078`、`B-083` | 9、10、11、12、13、14、15、16 |
| 6 | [BR-02x06-H096](../kit/B/parts/BR-02x06-H096.stl) | 15.8 × 47.8 × 11.4 | 16／16 | `B-043`／11 | `B-028`、`B-032`、`B-033`、`B-037`、`B-038`、`B-043`、`B-044`、`B-050`、`B-051`、`B-060`、`B-061`、`B-067`、`B-068`、`B-077`、`B-078`、`B-083` | 9、10、11、12、13、14、15、16 |
| 7 | [BR-02x06-H096](../kit/B/parts/BR-02x06-H096.stl) | 15.8 × 47.8 × 11.4 | 16／16 | `B-044`／12 | `B-028`、`B-032`、`B-033`、`B-037`、`B-038`、`B-043`、`B-044`、`B-050`、`B-051`、`B-060`、`B-061`、`B-067`、`B-068`、`B-077`、`B-078`、`B-083` | 9、10、11、12、13、14、15、16 |
| 8 | [BR-02x06-H096](../kit/B/parts/BR-02x06-H096.stl) | 15.8 × 47.8 × 11.4 | 16／16 | `B-050`／12 | `B-028`、`B-032`、`B-033`、`B-037`、`B-038`、`B-043`、`B-044`、`B-050`、`B-051`、`B-060`、`B-061`、`B-067`、`B-068`、`B-077`、`B-078`、`B-083` | 9、10、11、12、13、14、15、16 |
| 9 | [BR-02x06-H096](../kit/B/parts/BR-02x06-H096.stl) | 15.8 × 47.8 × 11.4 | 16／16 | `B-051`／13 | `B-028`、`B-032`、`B-033`、`B-037`、`B-038`、`B-043`、`B-044`、`B-050`、`B-051`、`B-060`、`B-061`、`B-067`、`B-068`、`B-077`、`B-078`、`B-083` | 9、10、11、12、13、14、15、16 |
| 10 | [BR-02x06-H096](../kit/B/parts/BR-02x06-H096.stl) | 15.8 × 47.8 × 11.4 | 16／16 | `B-060`／13 | `B-028`、`B-032`、`B-033`、`B-037`、`B-038`、`B-043`、`B-044`、`B-050`、`B-051`、`B-060`、`B-061`、`B-067`、`B-068`、`B-077`、`B-078`、`B-083` | 9、10、11、12、13、14、15、16 |
| 11 | [BR-02x06-H096](../kit/B/parts/BR-02x06-H096.stl) | 15.8 × 47.8 × 11.4 | 16／16 | `B-061`／14 | `B-028`、`B-032`、`B-033`、`B-037`、`B-038`、`B-043`、`B-044`、`B-050`、`B-051`、`B-060`、`B-061`、`B-067`、`B-068`、`B-077`、`B-078`、`B-083` | 9、10、11、12、13、14、15、16 |
| 12 | [BR-02x06-H096](../kit/B/parts/BR-02x06-H096.stl) | 15.8 × 47.8 × 11.4 | 16／16 | `B-067`／14 | `B-028`、`B-032`、`B-033`、`B-037`、`B-038`、`B-043`、`B-044`、`B-050`、`B-051`、`B-060`、`B-061`、`B-067`、`B-068`、`B-077`、`B-078`、`B-083` | 9、10、11、12、13、14、15、16 |
| 13 | [BR-02x06-H096](../kit/B/parts/BR-02x06-H096.stl) | 15.8 × 47.8 × 11.4 | 16／16 | `B-068`／15 | `B-028`、`B-032`、`B-033`、`B-037`、`B-038`、`B-043`、`B-044`、`B-050`、`B-051`、`B-060`、`B-061`、`B-067`、`B-068`、`B-077`、`B-078`、`B-083` | 9、10、11、12、13、14、15、16 |
| 14 | [BR-02x06-H096](../kit/B/parts/BR-02x06-H096.stl) | 15.8 × 47.8 × 11.4 | 16／16 | `B-077`／15 | `B-028`、`B-032`、`B-033`、`B-037`、`B-038`、`B-043`、`B-044`、`B-050`、`B-051`、`B-060`、`B-061`、`B-067`、`B-068`、`B-077`、`B-078`、`B-083` | 9、10、11、12、13、14、15、16 |
| 15 | [BR-02x06-H096](../kit/B/parts/BR-02x06-H096.stl) | 15.8 × 47.8 × 11.4 | 16／16 | `B-078`／16 | `B-028`、`B-032`、`B-033`、`B-037`、`B-038`、`B-043`、`B-044`、`B-050`、`B-051`、`B-060`、`B-061`、`B-067`、`B-068`、`B-077`、`B-078`、`B-083` | 9、10、11、12、13、14、15、16 |
| 16 | [BR-02x06-H096](../kit/B/parts/BR-02x06-H096.stl) | 15.8 × 47.8 × 11.4 | 16／16 | `B-083`／16 | `B-028`、`B-032`、`B-033`、`B-037`、`B-038`、`B-043`、`B-044`、`B-050`、`B-051`、`B-060`、`B-061`、`B-067`、`B-068`、`B-077`、`B-078`、`B-083` | 9、10、11、12、13、14、15、16 |
| 17 | [BR-02x04-H064](../kit/B/parts/BR-02x04-H064.stl) | 15.8 × 31.8 × 8.2 | 2／2 | `B-148`／27 | `B-148`、`B-150` | 27 |
| 18 | [BR-02x04-H064](../kit/B/parts/BR-02x04-H064.stl) | 15.8 × 31.8 × 8.2 | 2／2 | `B-150`／27 | `B-148`、`B-150` | 27 |
| 19 | [BR-02x04-H096](../kit/B/parts/BR-02x04-H096.stl) | 15.8 × 31.8 × 11.4 | 1／1 | `B-027`／8 | `B-027` | 8 |
| 20 | [BR-04x04-H064](../kit/B/parts/BR-04x04-H064.stl) | 31.8 × 31.8 × 8.2 | 1／1 | `B-149`／27 | `B-149` | 27 |

### B-magenta-02.3mf

[3Dガイド](../guide/index.html)でこのファイルを選び、同じslot番号の実形状を確認します。

| slot | 部品ID | 外形 W×D×H mm | 同形数（板内／全体） | 便宜割当／工程 | 全適用先 | 適用工程 |
|---:|---|---|---:|---|---|---|
| 1 | [BR-04x04-H096](../kit/B/parts/BR-04x04-H096.stl) | 31.8 × 31.8 × 11.4 | 2／2 | `B-025`／8 | `B-025`、`B-026` | 8 |
| 2 | [BR-04x04-H096](../kit/B/parts/BR-04x04-H096.stl) | 31.8 × 31.8 × 11.4 | 2／2 | `B-026`／8 | `B-025`、`B-026` | 8 |

### B-green-01.3mf

[3Dガイド](../guide/index.html)でこのファイルを選び、同じslot番号の実形状を確認します。

| slot | 部品ID | 外形 W×D×H mm | 同形数（板内／全体） | 便宜割当／工程 | 全適用先 | 適用工程 |
|---:|---|---|---:|---|---|---|
| 1 | [BR-01x04-H096](../kit/B/parts/BR-01x04-H096.stl) | 7.8 × 31.8 × 11.4 | 8／8 | `B-046`／12 | `B-046`、`B-048`、`B-054`、`B-057`、`B-063`、`B-065`、`B-071`、`B-074` | 12、13、14、15 |
| 2 | [BR-01x04-H096](../kit/B/parts/BR-01x04-H096.stl) | 7.8 × 31.8 × 11.4 | 8／8 | `B-048`／12 | `B-046`、`B-048`、`B-054`、`B-057`、`B-063`、`B-065`、`B-071`、`B-074` | 12、13、14、15 |
| 3 | [BR-01x04-H096](../kit/B/parts/BR-01x04-H096.stl) | 7.8 × 31.8 × 11.4 | 8／8 | `B-054`／13 | `B-046`、`B-048`、`B-054`、`B-057`、`B-063`、`B-065`、`B-071`、`B-074` | 12、13、14、15 |
| 4 | [BR-01x04-H096](../kit/B/parts/BR-01x04-H096.stl) | 7.8 × 31.8 × 11.4 | 8／8 | `B-057`／13 | `B-046`、`B-048`、`B-054`、`B-057`、`B-063`、`B-065`、`B-071`、`B-074` | 12、13、14、15 |
| 5 | [BR-01x04-H096](../kit/B/parts/BR-01x04-H096.stl) | 7.8 × 31.8 × 11.4 | 8／8 | `B-063`／14 | `B-046`、`B-048`、`B-054`、`B-057`、`B-063`、`B-065`、`B-071`、`B-074` | 12、13、14、15 |
| 6 | [BR-01x04-H096](../kit/B/parts/BR-01x04-H096.stl) | 7.8 × 31.8 × 11.4 | 8／8 | `B-065`／14 | `B-046`、`B-048`、`B-054`、`B-057`、`B-063`、`B-065`、`B-071`、`B-074` | 12、13、14、15 |
| 7 | [BR-01x04-H096](../kit/B/parts/BR-01x04-H096.stl) | 7.8 × 31.8 × 11.4 | 8／8 | `B-071`／15 | `B-046`、`B-048`、`B-054`、`B-057`、`B-063`、`B-065`、`B-071`、`B-074` | 12、13、14、15 |
| 8 | [BR-01x04-H096](../kit/B/parts/BR-01x04-H096.stl) | 7.8 × 31.8 × 11.4 | 8／8 | `B-074`／15 | `B-046`、`B-048`、`B-054`、`B-057`、`B-063`、`B-065`、`B-071`、`B-074` | 12、13、14、15 |

### B-black-to-white-z2p4-01.3mf

[3Dガイド](../guide/index.html)でこのファイルを選び、同じslot番号の実形状を確認します。

| slot | 部品ID | 外形 W×D×H mm | 同形数（板内／全体） | 便宜割当／工程 | 全適用先 | 適用工程 |
|---:|---|---|---:|---|---|---|
| 1 | [NP3-TEXT-B](../kit/B/parts/NP3-TEXT-B.stl) | 142 × 40 × 3.6 | 1／1 | `B-020`／6 | `B-020` | 6 |

### B-black-to-white-z2p8-01.3mf

[3Dガイド](../guide/index.html)でこのファイルを選び、同じslot番号の実形状を確認します。

| slot | 部品ID | 外形 W×D×H mm | 同形数（板内／全体） | 便宜割当／工程 | 全適用先 | 適用工程 |
|---:|---|---|---:|---|---|---|
| 1 | [NP3-LOGO-B](../kit/B/parts/NP3-LOGO-B.stl) | 40 × 40 × 3.6 | 1／1 | `B-021`／6 | `B-021` | 6 |

## 保管・照合

[BOM](../kit/B/bom.csv) · [slot対応CSV](../kit/B/part-map.csv) · [工程CSV](../kit/B/steps.csv) · [組立配置](../kit/B/assembly.json) · [全図PDF](../kit/B/drawings.pdf) · [印刷ファイルmanifest](../kit/manifest.json)

[完成FreeCAD](../source/native/B.FCStd) · [銘板FreeCAD](../source/native/NP3-TEXT-B.FCStd) · [銘板STEP](../source/native/NP3-TEXT-B.step)

[全キットZIP](https://github.com/ktanino10/copilot-brick-gift-b/blob/main/downloads/B-personal-print-kit.zip) · [ファイルSHA-256](../SHA256SUMS.txt) · [ZIPのSHA-256](https://github.com/ktanino10/copilot-brick-gift-b/blob/main/downloads/SHA256SUMS.txt)

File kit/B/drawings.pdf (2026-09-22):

## PRIVATE B / 4.1-B-legibility.1 / TWO-LINE NAMEPLATE

# B / DESK CLASSIC / CURRENT ENVELOPE

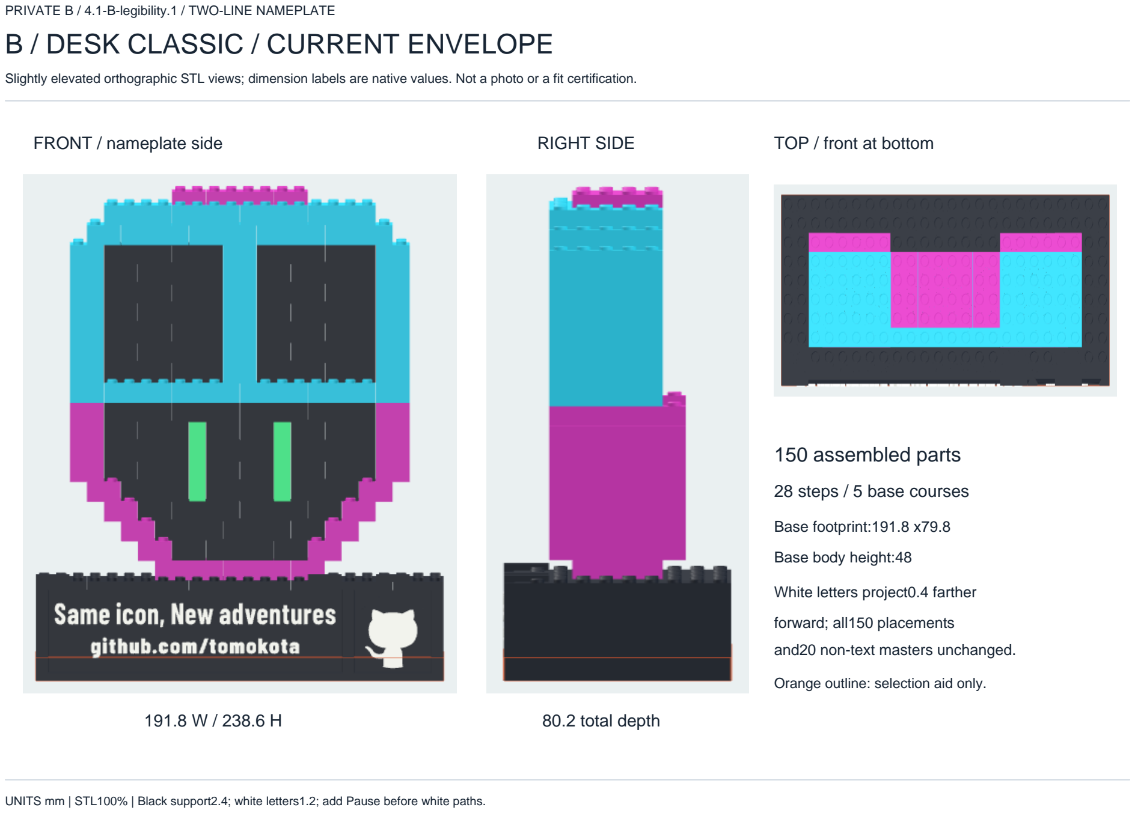
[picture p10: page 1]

Slightly elevated orthographic STL views; dimension labels are native values. Not a photo or a fit certification.

# FRONT / nameplate side

191.8 W / 238.6 H

# RIGHT SIDE

# 80.2 total depth

# TOP / front at bottom

# 150 assembled parts

# 28 steps / 5 base courses

## Base footprint:191.8 x79.8

## Base body height:48

## White letters project0.4 farther

## forward; all150 placements

and20 non-text masters unchanged.

Orange outline: selection aid only.

UNITS mm | STL100% | Black support2.4; white letters1.2; add Pause before white paths.

## PRIVATE B / 4.1-B-legibility.1 / TWO-LINE NAMEPLATE

# B / FRONT MODULE INSERTION AND RELEASE REFERENCE

Left: current mesh insertion detail; right: actual native plate cap contours. Not a force simulation.

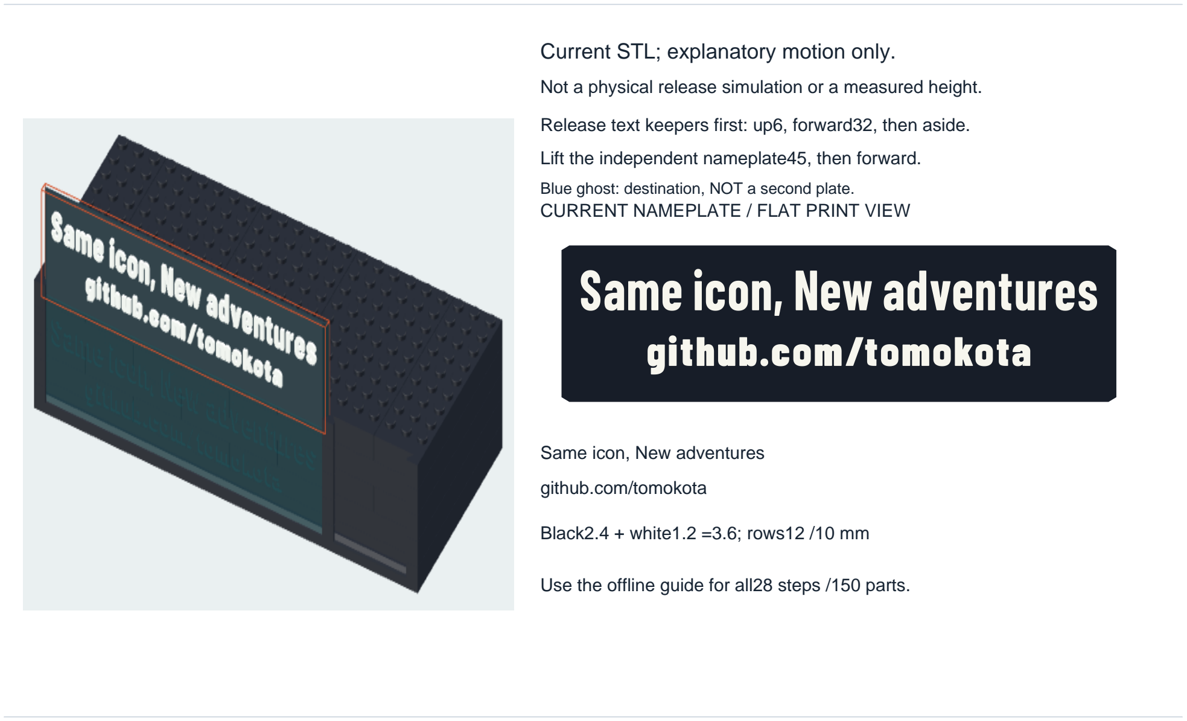
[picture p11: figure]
Current STL; explanatory motion only.; CURRENT NAMEPLATE / FLAT PRINT VIEW; Same icon, New adventures; github.com/tomokota; Black2.4 + white1.2 =3.6; rows12 /10 mm

Not a physical release simulation or a measured height.

Release text keepers first: up6, forward32, then aside. Lift the independent nameplate45, then forward.
Blue ghost: destination, NOT a second plate.

Use the offline guide for all28 steps /150 parts.

UNITS mm | STL100% | Black support2.4; white letters1.2; add Pause before white paths.

### BRICK PORTRAIT / PUBLIC TEMPLATE / 5-COURSE BASE / DIGITAL PROTOTYPE

# INTERFACE / SECTION & CLEARANCE

Project design candidates, NOT a proprietary tolerance standard. Geometry from FreeCAD planar sections.

## SECTION: Y = 4.00 / TWO 2x2 BRICKS

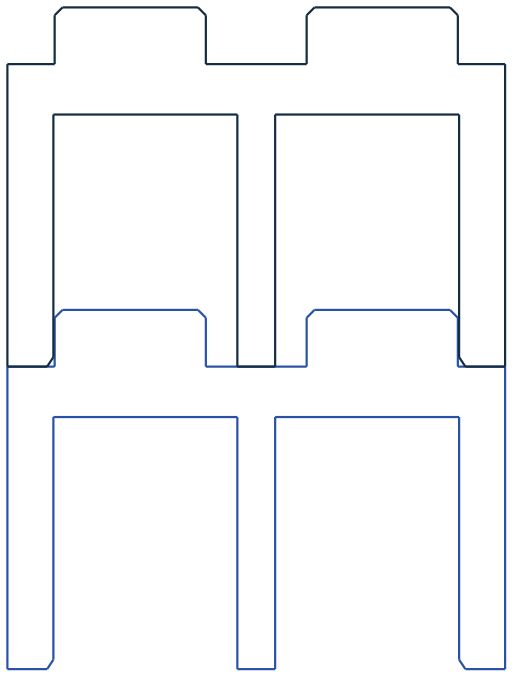
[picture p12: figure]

## 8.00 nominal pitch x 2

## JOINT SECTION: Z = 10.50

### Actual wall, tube, rib + mating stud outlines

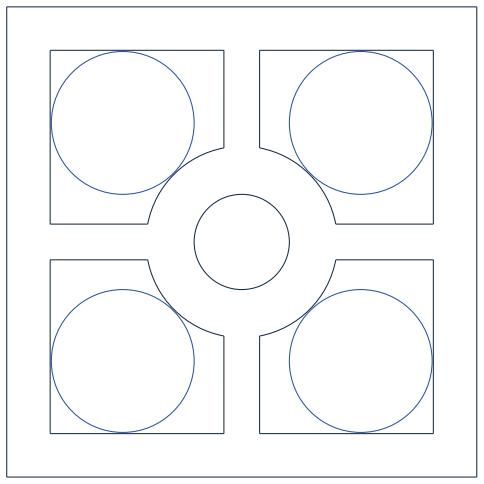
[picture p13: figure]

### Blue: lower brick / black: upper socket

### Reference stud dia 4.80; candidate height 1.80

### Radial clearance c=+0.04 (default; untested)

### Inside wall offset 1.56 / wall thickness 1.46

### Tube OD 6.433708 / ID 3.20; grid rib 1.20

### Tip lead-in 0.25 / female lead-in 0.20 x 0.30

### Roof 1.60; thin plate roof 1.00

### Thin plate / keeper: nominal headroom 0.40

No forced fit. Tune male and female separately.

UNITS mm | Fixed 8 mm pitch | Physical fit / strength / stability NOT tested | Do not scale STL. Calibrate male + female coupons first.

## PRIVATE B / 4.1-B-legibility.1 / TWO-LINE NAMEPLATE

# B / CURRENT FRONT INTERFACE AND RELEASE

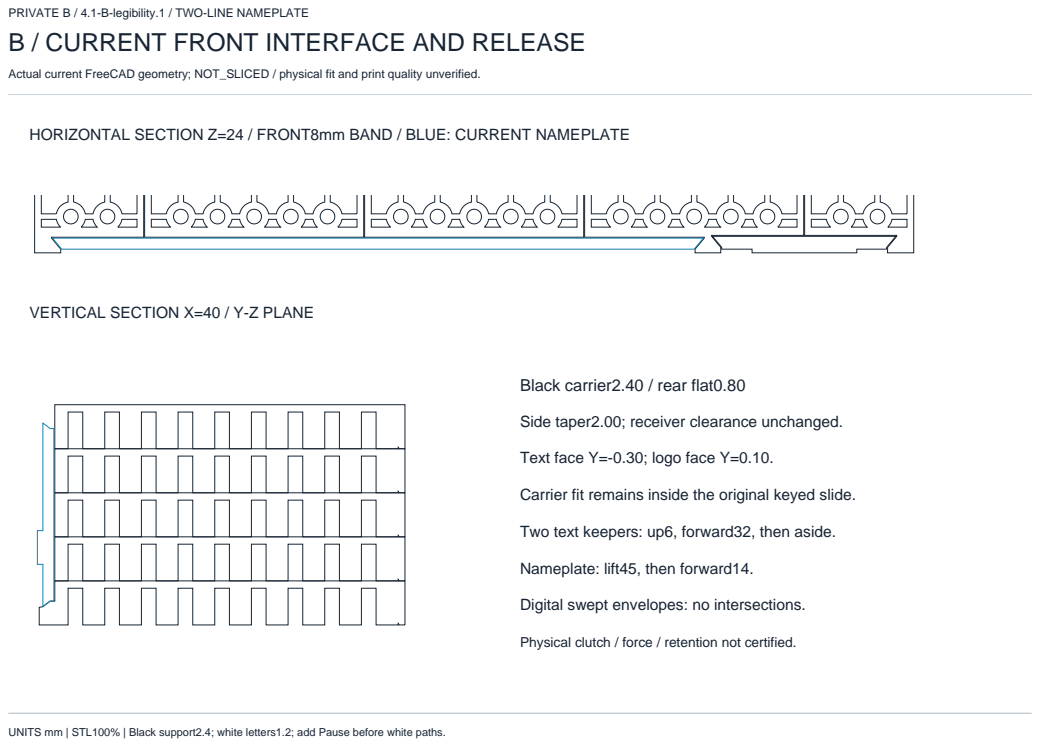
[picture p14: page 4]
Black carrier2.40 / rear flat0.80; Nameplate: lift45, then forward14.

Actual current FreeCAD geometry; NOT_SLICED / physical fit and print quality unverified.

HORIZONTAL SECTION Z=24 / FRONT8mm BAND / BLUE: CURRENT NAMEPLATE

VERTICAL SECTION X=40 / Y-Z PLANE

Side taper2.00; receiver clearance unchanged.

Text face Y=-0.30; logo face Y=0.10.

Carrier fit remains inside the original keyed slide.

Two text keepers: up6, forward32, then aside.

Digital swept envelopes: no intersections.

Physical clutch / force / retention not certified.

UNITS mm | STL100% | Black support2.4; white letters1.2; add Pause before white paths.

### BRICK PORTRAIT / REV3 / 5-COURSE BASE / DIGITAL PROTOTYPE

# B / COLOR BOM / 1

One STL geometry may be printed in several colors. Use the quantities for this model only.

PART ID | COLOR | QTY | PRINT FILE
BASE3-03x10-T-aa77a9 | black | 2 | parts/BASE3-03x10-T-aa77a9.stl
BASE3-03x10-T-d79875 | black | 2 | parts/BASE3-03x10-T-d79875.stl
BASE3-06x10-T-3f87ac | black | 2 | parts/BASE3-06x10-T-3f87ac.stl
BASE3-06x10-T-6159e6 | black | 2 | parts/BASE3-06x10-T-6159e6.stl
BASE3-06x10-T-6e100f | black | 2 | parts/BASE3-06x10-T-6e100f.stl
BASE3-06x10-T-838259 | black | 6 | parts/BASE3-06x10-T-838259.stl
BASE3-06x10-T-e1945a | black | 2 | parts/BASE3-06x10-T-e1945a.stl
BASE3-24x10-B-562406 | black | 1 | parts/BASE3-24x10-B-562406.stl
BR-01x04-H096 | green | 8 | parts/BR-01x04-H096.stl
BR-02x04-H064 | magenta | 2 | parts/BR-02x04-H064.stl
BR-02x04-H096 | black | 19 | parts/BR-02x04-H096.stl
BR-02x04-H096 | magenta | 1 | parts/BR-02x04-H096.stl
BR-02x05-H096 | cyan | 24 | parts/BR-02x05-H096.stl
BR-02x06-H096 | magenta | 16 | parts/BR-02x06-H096.stl
BR-03x04-H096 | black | 12 | parts/BR-03x04-H096.stl
BR-04x04-H064 | magenta | 1 | parts/BR-04x04-H064.stl
BR-04x04-H096 | black | 21 | parts/BR-04x04-H096.stl
BR-04x04-H096 | magenta | 2 | parts/BR-04x04-H096.stl
BR-04x05-H096 | cyan | 12 | parts/BR-04x05-H096.stl
BR-05x04-H096 | black | 8 | parts/BR-05x04-H096.stl
NP3-KEEPER | black | 3 | parts/NP3-KEEPER.stl
NP3-LOGO-B | black | 1 | parts/NP3-LOGO-B.stl
NP3-TEXT-B | black | 1 | parts/NP3-TEXT-B.stl

TEXT: black -> white at 2.4mm; LOGO: black -> white at 2.8mm. Separate plates.

Assembly: 150 pieces, including 2 front modules + 3 keepers. Coupons separate.

### BRICK PORTRAIT / REV3 / 5-COURSE BASE / DIGITAL PROTOTYPE

# B / STEP 01 OF 28

Placement diagram from canonical part bounds. IDs match native CAD, BOM, viewer and animation.

## PLAN VIEW / front at bottom / NEW parts in color

001

## nominal 192 / grid 8.00

## FRONT (-Y) / new parts enter from above (+Z)

# ADD 1 PART(S)

### B-001 BLACK

BASE3-24x10-B-562406 @ 0,0,0

### BRICK PORTRAIT / REV3 / 5-COURSE BASE / DIGITAL PROTOTYPE

# B / STEP 02 OF 28

Placement diagram from canonical part bounds. IDs match native CAD, BOM, viewer and animation.

## PLAN VIEW / front at bottom / NEW parts in color

002 | 003 | 004 | 005

## nominal 192 / grid 8.00

## FRONT (-Y) / new parts enter from above (+Z)

# ADD 4 PART(S)

### B-002 BLACK

BASE3-06x10-T-e1945a @ 0,0,9.6

### B-003 BLACK

BASE3-06x10-T-838259 @ 48,0,9.6

### B-004 BLACK

BASE3-06x10-T-3f87ac @ 96,0,9.6

### B-005 BLACK

BASE3-06x10-T-6e100f @ 144,0,9.6

### BRICK PORTRAIT / REV3 / 5-COURSE BASE / DIGITAL PROTOTYPE

# B / STEP 03 OF 28

Placement diagram from canonical part bounds. IDs match native CAD, BOM, viewer and animation.

## PLAN VIEW / front at bottom / NEW parts in color

006 | 007 | 008 | 009 | 010

## nominal 192 / grid 8.00

## FRONT (-Y) / new parts enter from above (+Z)

# ADD 5 PART(S)

### B-006 BLACK

BASE3-03x10-T-aa77a9 @ 0,0,19.2

### B-007 BLACK

BASE3-06x10-T-838259 @ 24,0,19.2

### B-008 BLACK

BASE3-06x10-T-838259 @ 72,0,19.2

### B-009 BLACK

BASE3-06x10-T-6159e6 @ 120,0,19.2

### B-010 BLACK

BASE3-03x10-T-d79875 @ 168,0,19.2

### BRICK PORTRAIT / REV3 / 5-COURSE BASE / DIGITAL PROTOTYPE

# B / STEP 04 OF 28

Placement diagram from canonical part bounds. IDs match native CAD, BOM, viewer and animation.

## PLAN VIEW / front at bottom / NEW parts in color

011 | 012 | 013 | 014

## nominal 192 / grid 8.00

## FRONT (-Y) / new parts enter from above (+Z)

# ADD 4 PART(S)

### B-011 BLACK

BASE3-06x10-T-e1945a @ 0,0,28.8

### B-012 BLACK

BASE3-06x10-T-838259 @ 48,0,28.8

### B-013 BLACK

BASE3-06x10-T-3f87ac @ 96,0,28.8

### B-014 BLACK

BASE3-06x10-T-6e100f @ 144,0,28.8

### BRICK PORTRAIT / REV3 / 5-COURSE BASE / DIGITAL PROTOTYPE

# B / STEP 05 OF 28

Placement diagram from canonical part bounds. IDs match native CAD, BOM, viewer and animation.

## PLAN VIEW / front at bottom / NEW parts in color

015 | 016 | 017 | 018 | 019

## nominal 192 / grid 8.00

## FRONT (-Y) / new parts enter from above (+Z)

# ADD 5 PART(S)

### B-015 BLACK

BASE3-03x10-T-aa77a9 @ 0,0,38.4

### B-016 BLACK

BASE3-06x10-T-838259 @ 24,0,38.4

### B-017 BLACK

BASE3-06x10-T-838259 @ 72,0,38.4

### B-018 BLACK

BASE3-06x10-T-6159e6 @ 120,0,38.4

### B-019 BLACK

BASE3-03x10-T-d79875 @ 168,0,38.4

### BRICK PORTRAIT / LEGIBILITY4.1 / 5-COURSE BASE / DIGITAL PROTOTYPE

# B / STEP 06 OF 28

Placement diagram from canonical part bounds. IDs match native CAD, BOM, viewer and animation.

## PLAN VIEW / front at bottom / NEW parts in color

020 021

## nominal 192 / grid 8.00

## FRONT (-Y) / new parts enter from above (+Z)

# ADD 2 PART(S)

### B-020 BLACK

NP3-TEXT-B @ 4,3.3,4

### B-021 BLACK

NP3-LOGO-B @ 148,3.7,4

# B / STEP 07 OF 28

Placement diagram from canonical part bounds. IDs match native CAD, BOM, viewer and animation.

## PLAN VIEW / front at bottom / NEW parts in color

022 | 023 | 024

## nominal 192 / grid 8.00

## FRONT (-Y) / new parts enter from above (+Z)

# ADD 3 PART(S)

### B-022 BLACK

NP3-KEEPER @ 0,0,48

### B-023 BLACK

NP3-KEEPER @ 128,0,48

### B-024 BLACK

NP3-KEEPER @ 160,0,48

# B / STEP 08 OF 28

Placement diagram from canonical part bounds. IDs match native CAD, BOM, viewer and animation.

## PLAN VIEW / front at bottom / NEW parts in color

025 | 026 | 027

## nominal 192 / grid 8.00

## FRONT (-Y) / new parts enter from above (+Z)

# ADD 3 PART(S)

### B-025 MAGENTA

BR-04x04-H096 @ 56,24,48

### B-026 MAGENTA

BR-04x04-H096 @ 88,24,48

### B-027 MAGENTA

BR-02x04-H096 @ 120,24,48

# B / STEP 09 OF 28

Placement diagram from canonical part bounds. IDs match native CAD, BOM, viewer and animation.

## PLAN VIEW / front at bottom / NEW parts in color

028 | 029 | 030 | 031 | 032

## nominal 192 / grid 8.00

## FRONT (-Y) / new parts enter from above (+Z)

# ADD 5 PART(S)

### B-028 MAGENTA

BR-02x06-H096 @ 48,16,57.6

### B-029 BLACK

BR-02x04-H096 @ 64,24,57.6

### B-030 BLACK

BR-04x04-H096 @ 80,24,57.6

### B-031 BLACK

BR-02x04-H096 @ 112,24,57.6

### B-032 MAGENTA

BR-02x06-H096 @ 128,16,57.6

# B / STEP 10 OF 28

Placement diagram from canonical part bounds. IDs match native CAD, BOM, viewer and animation.

## PLAN VIEW / front at bottom / NEW parts in color

033 | 034 | 035 | 036 | 037

## nominal 192 / grid 8.00

## FRONT (-Y) / new parts enter from above (+Z)

# ADD 5 PART(S)

### B-033 MAGENTA

BR-02x06-H096 @ 40,16,67.2

### B-034 BLACK

BR-04x04-H096 @ 56,24,67.2

### B-035 BLACK

BR-04x04-H096 @ 88,24,67.2

### B-036 BLACK

BR-02x04-H096 @ 120,24,67.2

### B-037 MAGENTA

BR-02x06-H096 @ 136,16,67.2

# B / STEP 11 OF 28

Placement diagram from canonical part bounds. IDs match native CAD, BOM, viewer and animation.

## PLAN VIEW / front at bottom / NEW parts in color

038 | 039 | 040 | 041 | 042 | 043

## nominal 192 / grid 8.00

## FRONT (-Y) / new parts enter from above (+Z)

# ADD 6 PART(S)

### B-038 MAGENTA

BR-02x06-H096 @ 32,16,76.8

### B-039 BLACK

BR-02x04-H096 @ 48,24,76.8

### B-040 BLACK

BR-04x04-H096 @ 64,24,76.8

### B-041 BLACK

BR-04x04-H096 @ 96,24,76.8

### B-042 BLACK

BR-02x04-H096 @ 128,24,76.8

### B-043 MAGENTA

BR-02x06-H096 @ 144,16,76.8

# B / STEP 12 OF 28

Placement diagram from canonical part bounds. IDs match native CAD, BOM, viewer and animation.

## PLAN VIEW / front at bottom / NEW parts in color

044 | 045 | 046 | 047 | 048 | 049 | 050

## nominal 192 / grid 8.00

## FRONT (-Y) / new parts enter from above (+Z)

# ADD 7 PART(S)

### B-044 MAGENTA

BR-02x06-H096 @ 24,16,86.4

### B-045 BLACK

BR-04x04-H096 @ 40,24,86.4

### B-046 GREEN

BR-01x04-H096 @ 72,24,86.4

### B-047 BLACK

BR-04x04-H096 @ 80,24,86.4

### B-048 GREEN

BR-01x04-H096 @ 112,24,86.4

### B-049 BLACK

BR-04x04-H096 @ 120,24,86.4

### B-050 MAGENTA

BR-02x06-H096 @ 152,16,86.4

# B / STEP 13 OF 28

Placement diagram from canonical part bounds. IDs match native CAD, BOM, viewer and animation.

## PLAN VIEW / front at bottom / NEW parts in color

051 | 052 | 053 | 054 | 055 | 056 | 057 | 058 | 059 | 060

## nominal 192 / grid 8.00

## FRONT (-Y) / new parts enter from above (+Z)

# ADD 10 PART(S)

### B-051 MAGENTA

BR-02x06-H096 @ 16,16,96

### B-052 BLACK

BR-02x04-H096 @ 32,24,96

### B-053 BLACK

BR-03x04-H096 @ 48,24,96

### B-054 GREEN

BR-01x04-H096 @ 72,24,96

### B-055 BLACK

BR-02x04-H096 @ 80,24,96

### B-056 BLACK

BR-02x04-H096 @ 96,24,96

### B-057 GREEN

BR-01x04-H096 @ 112,24,96

### B-058 BLACK

BR-02x04-H096 @ 120,24,96

### B-059 BLACK

BR-03x04-H096 @ 136,24,96

### B-060 MAGENTA

BR-02x06-H096 @ 160,16,96

# B / STEP 14 OF 28

Placement diagram from canonical part bounds. IDs match native CAD, BOM, viewer and animation.

## PLAN VIEW / front at bottom / NEW parts in color

061 | 062 | 063 | 064 | 065 | 066 | 067

## nominal 192 / grid 8.00

## FRONT (-Y) / new parts enter from above (+Z)

# ADD 7 PART(S)

### B-061 MAGENTA

BR-02x06-H096 @ 16,16,105.6

### B-062 BLACK

BR-05x04-H096 @ 32,24,105.6

### B-063 GREEN

BR-01x04-H096 @ 72,24,105.6

### B-064 BLACK

BR-04x04-H096 @ 80,24,105.6

### B-065 GREEN

BR-01x04-H096 @ 112,24,105.6

### B-066 BLACK

BR-05x04-H096 @ 120,24,105.6

### B-067 MAGENTA

BR-02x06-H096 @ 160,16,105.6

# B / STEP 15 OF 28

Placement diagram from canonical part bounds. IDs match native CAD, BOM, viewer and animation.

## PLAN VIEW / front at bottom / NEW parts in color

068 | 069 | 070 | 071 | 072 | 073 | 074 | 075 | 076 | 077

## nominal 192 / grid 8.00

## FRONT (-Y) / new parts enter from above (+Z)

# ADD 10 PART(S)

### B-068 MAGENTA

BR-02x06-H096 @ 16,16,115.2

### B-069 BLACK

BR-02x04-H096 @ 32,24,115.2

### B-070 BLACK

BR-03x04-H096 @ 48,24,115.2

### B-071 GREEN

BR-01x04-H096 @ 72,24,115.2

### B-072 BLACK

BR-02x04-H096 @ 80,24,115.2

### B-073 BLACK

BR-02x04-H096 @ 96,24,115.2

### B-074 GREEN

BR-01x04-H096 @ 112,24,115.2

### B-075 BLACK

BR-02x04-H096 @ 120,24,115.2

### B-076 BLACK

BR-03x04-H096 @ 136,24,115.2

### B-077 MAGENTA

BR-02x06-H096 @ 160,16,115.2

# B / STEP 16 OF 28

Placement diagram from canonical part bounds. IDs match native CAD, BOM, viewer and animation.

## PLAN VIEW / front at bottom / NEW parts in color

078 | 079 | 080 | 081 | 082 | 083

## nominal 192 / grid 8.00

## FRONT (-Y) / new parts enter from above (+Z)

# ADD 6 PART(S)

### B-078 MAGENTA

BR-02x06-H096 @ 16,16,124.8

### B-079 BLACK

BR-04x04-H096 @ 32,24,124.8

### B-080 BLACK

BR-04x04-H096 @ 64,24,124.8

### B-081 BLACK

BR-04x04-H096 @ 96,24,124.8

### B-082 BLACK

BR-04x04-H096 @ 128,24,124.8

### B-083 MAGENTA

BR-02x06-H096 @ 160,16,124.8

# B / STEP 17 OF 28

Placement diagram from canonical part bounds. IDs match native CAD, BOM, viewer and animation.

## PLAN VIEW / front at bottom / NEW parts in color

084 | 085 | 086 | 087 | 088 | 089

## nominal 192 / grid 8.00

## FRONT (-Y) / new parts enter from above (+Z)

# ADD 6 PART(S)

### B-084 CYAN

BR-02x05-H096 @ 16,16,134.4

### B-085 CYAN

BR-04x05-H096 @ 32,16,134.4

### B-086 CYAN

BR-04x05-H096 @ 64,16,134.4

### B-087 CYAN

BR-04x05-H096 @ 96,16,134.4

### B-088 CYAN

BR-04x05-H096 @ 128,16,134.4

### B-089 CYAN

BR-02x05-H096 @ 160,16,134.4

# B / STEP 18 OF 28

Placement diagram from canonical part bounds. IDs match native CAD, BOM, viewer and animation.

## PLAN VIEW / front at bottom / NEW parts in color

090 | 093 | 096
091 092 | 094 095

## nominal 192 / grid 8.00

## FRONT (-Y) / new parts enter from above (+Z)

# ADD 7 PART(S)

### B-090 CYAN

BR-02x05-H096 @ 16,16,144

### B-091 BLACK

BR-04x04-H096 @ 32,24,144

### B-092 BLACK

BR-03x04-H096 @ 64,24,144

### B-093 CYAN

BR-02x05-H096 @ 88,16,144

### B-094 BLACK

BR-04x04-H096 @ 104,24,144

### B-095 BLACK

BR-03x04-H096 @ 136,24,144

### B-096 CYAN

BR-02x05-H096 @ 160,16,144

# B / STEP 19 OF 28

Placement diagram from canonical part bounds. IDs match native CAD, BOM, viewer and animation.

## PLAN VIEW / front at bottom / NEW parts in color

097 | 100 | 103
098 099 | 101 102

## nominal 192 / grid 8.00

## FRONT (-Y) / new parts enter from above (+Z)

# ADD 7 PART(S)

### B-097 CYAN

BR-02x05-H096 @ 16,16,153.6

### B-098 BLACK

BR-02x04-H096 @ 32,24,153.6

### B-099 BLACK

BR-05x04-H096 @ 48,24,153.6

### B-100 CYAN

BR-02x05-H096 @ 88,16,153.6

### B-101 BLACK

BR-02x04-H096 @ 104,24,153.6

### B-102 BLACK

BR-05x04-H096 @ 120,24,153.6

### B-103 CYAN

BR-02x05-H096 @ 160,16,153.6

# B / STEP 20 OF 28

Placement diagram from canonical part bounds. IDs match native CAD, BOM, viewer and animation.

## PLAN VIEW / front at bottom / NEW parts in color

104 | 107 | 110
105 106 | 108 109

## nominal 192 / grid 8.00

## FRONT (-Y) / new parts enter from above (+Z)

# ADD 7 PART(S)

### B-104 CYAN

BR-02x05-H096 @ 16,16,163.2

### B-105 BLACK

BR-04x04-H096 @ 32,24,163.2

### B-106 BLACK

BR-03x04-H096 @ 64,24,163.2

### B-107 CYAN

BR-02x05-H096 @ 88,16,163.2

### B-108 BLACK

BR-04x04-H096 @ 104,24,163.2

### B-109 BLACK

BR-03x04-H096 @ 136,24,163.2

### B-110 CYAN

BR-02x05-H096 @ 160,16,163.2

# B / STEP 21 OF 28

Placement diagram from canonical part bounds. IDs match native CAD, BOM, viewer and animation.

## PLAN VIEW / front at bottom / NEW parts in color

111 | 114 | 117
112 113 | 115 116

## nominal 192 / grid 8.00

## FRONT (-Y) / new parts enter from above (+Z)

# ADD 7 PART(S)

### B-111 CYAN

BR-02x05-H096 @ 16,16,172.8

### B-112 BLACK

BR-02x04-H096 @ 32,24,172.8

### B-113 BLACK

BR-05x04-H096 @ 48,24,172.8

### B-114 CYAN

BR-02x05-H096 @ 88,16,172.8

### B-115 BLACK

BR-02x04-H096 @ 104,24,172.8

### B-116 BLACK

BR-05x04-H096 @ 120,24,172.8

### B-117 CYAN

BR-02x05-H096 @ 160,16,172.8

# B / STEP 22 OF 28

Placement diagram from canonical part bounds. IDs match native CAD, BOM, viewer and animation.

## PLAN VIEW / front at bottom / NEW parts in color

118 | 121 | 124
119 120 | 122 123

## nominal 192 / grid 8.00

## FRONT (-Y) / new parts enter from above (+Z)

# ADD 7 PART(S)

### B-118 CYAN

BR-02x05-H096 @ 16,16,182.4

### B-119 BLACK

BR-04x04-H096 @ 32,24,182.4

### B-120 BLACK

BR-03x04-H096 @ 64,24,182.4

### B-121 CYAN

BR-02x05-H096 @ 88,16,182.4

### B-122 BLACK

BR-04x04-H096 @ 104,24,182.4

### B-123 BLACK

BR-03x04-H096 @ 136,24,182.4

### B-124 CYAN

BR-02x05-H096 @ 160,16,182.4

# B / STEP 23 OF 28

Placement diagram from canonical part bounds. IDs match native CAD, BOM, viewer and animation.

## PLAN VIEW / front at bottom / NEW parts in color

125 | 128 | 131
126 127 | 129 130

## nominal 192 / grid 8.00

## FRONT (-Y) / new parts enter from above (+Z)

# ADD 7 PART(S)

### B-125 CYAN

BR-02x05-H096 @ 16,16,192

### B-126 BLACK

BR-02x04-H096 @ 32,24,192

### B-127 BLACK

BR-05x04-H096 @ 48,24,192

### B-128 CYAN

BR-02x05-H096 @ 88,16,192

### B-129 BLACK

BR-02x04-H096 @ 104,24,192

### B-130 BLACK

BR-05x04-H096 @ 120,24,192

### B-131 CYAN

BR-02x05-H096 @ 160,16,192

# B / STEP 24 OF 28

Placement diagram from canonical part bounds. IDs match native CAD, BOM, viewer and animation.

## PLAN VIEW / front at bottom / NEW parts in color

132 | 135 | 138
133 134 | 136 137

## nominal 192 / grid 8.00

## FRONT (-Y) / new parts enter from above (+Z)

# ADD 7 PART(S)

### B-132 CYAN

BR-02x05-H096 @ 16,16,201.6

### B-133 BLACK

BR-04x04-H096 @ 32,24,201.6

### B-134 BLACK

BR-03x04-H096 @ 64,24,201.6

### B-135 CYAN

BR-02x05-H096 @ 88,16,201.6

### B-136 BLACK

BR-04x04-H096 @ 104,24,201.6

### B-137 BLACK

BR-03x04-H096 @ 136,24,201.6

### B-138 CYAN

BR-02x05-H096 @ 160,16,201.6

# B / STEP 25 OF 28

Placement diagram from canonical part bounds. IDs match native CAD, BOM, viewer and animation.

## PLAN VIEW / front at bottom / NEW parts in color

139 | 140 | 141 | 142 | 143

## nominal 192 / grid 8.00

## FRONT (-Y) / new parts enter from above (+Z)

# ADD 5 PART(S)

### B-139 CYAN

BR-02x05-H096 @ 24,16,211.2

### B-140 CYAN

BR-04x05-H096 @ 40,16,211.2

### B-141 CYAN

BR-04x05-H096 @ 72,16,211.2

### B-142 CYAN

BR-04x05-H096 @ 104,16,211.2

### B-143 CYAN

BR-04x05-H096 @ 136,16,211.2

# B / STEP 26 OF 28

Placement diagram from canonical part bounds. IDs match native CAD, BOM, viewer and animation.

## PLAN VIEW / front at bottom / NEW parts in color

144 | 145 | 146 | 147

## nominal 192 / grid 8.00

## FRONT (-Y) / new parts enter from above (+Z)

# ADD 4 PART(S)

### B-144 CYAN

BR-04x05-H096 @ 32,16,220.8

### B-145 CYAN

BR-04x05-H096 @ 64,16,220.8

### B-146 CYAN

BR-04x05-H096 @ 96,16,220.8

### B-147 CYAN

BR-04x05-H096 @ 128,16,220.8

# B / STEP 27 OF 28

Placement diagram from canonical part bounds. IDs match native CAD, BOM, viewer and animation.

## PLAN VIEW / front at bottom / NEW parts in color

148 | 149 | 150

## nominal 192 / grid 8.00

## FRONT (-Y) / new parts enter from above (+Z)

# ADD 3 PART(S)

### B-148 MAGENTA

BR-02x04-H064 @ 64,24,230.4

### B-149 MAGENTA

BR-04x04-H064 @ 80,24,230.4

### B-150 MAGENTA

BR-02x04-H064 @ 112,24,230.4

# B / STEP 28 OF 28

Placement diagram from canonical part bounds. IDs match native CAD, BOM, viewer and animation.

## PLAN VIEW / front at bottom / NEW parts in color

## nominal 192 / grid 8.00

## FRONT (-Y) / new parts enter from above (+Z)

# ADD 0 PART(S)

### BRICK PORTRAIT / PUBLIC TEMPLATE / 5-COURSE BASE / DIGITAL PROTOTYPE

# BASE3-03x10-T-aa77a9

Three orthographic views + underside from the actual solid. Exterior heights include studs / text.

## FRONT

23.80

11.40

## SIDE

79.80

TOP / PRINT ORIENTATION | BOTTOM / REAL CAVITIES

Kind: front_base

STL: BASE3-03x10-T-aa77a9.stl

STL units: mm / scale 100%

Grid: 3 x 10 @ 8.00

Body height: 9.60

Stud: dia 4.80 x 1.80 high

Tip lead-in: 0.25 high / radial

Female radial c: +0.04

Outer wall: 1.46

Tube bore: 3.20 (not accessory fit)

Roof ribs: 1.20; bridge gap <=6.80

Front row reserved (no stud/socket)

NP3 dovetail side allowance: 0.20

See front-interface.svg for sections

### BRICK PORTRAIT / PUBLIC TEMPLATE / 5-COURSE BASE / DIGITAL PROTOTYPE

# BASE3-03x10-T-d79875

Three orthographic views + underside from the actual solid. Exterior heights include studs / text.

## FRONT

23.80

11.40

## SIDE

79.80

TOP / PRINT ORIENTATION | BOTTOM / REAL CAVITIES

Kind: front_base

STL: BASE3-03x10-T-d79875.stl

STL units: mm / scale 100%

Grid: 3 x 10 @ 8.00

Body height: 9.60

Stud: dia 4.80 x 1.80 high

Tip lead-in: 0.25 high / radial

Female radial c: +0.04

Outer wall: 1.46

Tube bore: 3.20 (not accessory fit)

Roof ribs: 1.20; bridge gap <=6.80

Front row reserved (no stud/socket)

NP3 dovetail side allowance: 0.20

See front-interface.svg for sections

### BRICK PORTRAIT / PUBLIC TEMPLATE / 5-COURSE BASE / DIGITAL PROTOTYPE

# BASE3-06x10-T-3f87ac

Three orthographic views + underside from the actual solid. Exterior heights include studs / text.

## FRONT

47.80

11.40

## SIDE

76.40

TOP / PRINT ORIENTATION | BOTTOM / REAL CAVITIES

Kind: front_base

STL: BASE3-06x10-T-3f87ac.stl

STL units: mm / scale 100%

Grid: 6 x 10 @ 8.00

Body height: 9.60

Stud: dia 4.80 x 1.80 high

Tip lead-in: 0.25 high / radial

Female radial c: +0.04

Outer wall: 1.46

Tube bore: 3.20 (not accessory fit)

Roof ribs: 1.20; bridge gap <=6.80

Front row reserved (no stud/socket)

NP3 dovetail side allowance: 0.20

See front-interface.svg for sections

### BRICK PORTRAIT / PUBLIC TEMPLATE / 5-COURSE BASE / DIGITAL PROTOTYPE

# BASE3-06x10-T-6159e6

Three orthographic views + underside from the actual solid. Exterior heights include studs / text.

## FRONT

47.80

11.40

## SIDE

79.80

TOP / PRINT ORIENTATION | BOTTOM / REAL CAVITIES

Kind: front_base

STL: BASE3-06x10-T-6159e6.stl

STL units: mm / scale 100%

Grid: 6 x 10 @ 8.00

Body height: 9.60

Stud: dia 4.80 x 1.80 high

Tip lead-in: 0.25 high / radial

Female radial c: +0.04

Outer wall: 1.46

Tube bore: 3.20 (not accessory fit)

Roof ribs: 1.20; bridge gap <=6.80

Front row reserved (no stud/socket)

NP3 dovetail side allowance: 0.20

See front-interface.svg for sections

### BRICK PORTRAIT / PUBLIC TEMPLATE / 5-COURSE BASE / DIGITAL PROTOTYPE

# BASE3-06x10-T-6e100f

Three orthographic views + underside from the actual solid. Exterior heights include studs / text.

## FRONT

47.80

11.40

## SIDE

79.80

TOP / PRINT ORIENTATION | BOTTOM / REAL CAVITIES

Kind: front_base

STL: BASE3-06x10-T-6e100f.stl

STL units: mm / scale 100%

Grid: 6 x 10 @ 8.00

Body height: 9.60

Stud: dia 4.80 x 1.80 high

Tip lead-in: 0.25 high / radial

Female radial c: +0.04

Outer wall: 1.46

Tube bore: 3.20 (not accessory fit)

Roof ribs: 1.20; bridge gap <=6.80

Front row reserved (no stud/socket)

NP3 dovetail side allowance: 0.20

See front-interface.svg for sections

### BRICK PORTRAIT / PUBLIC TEMPLATE / 5-COURSE BASE / DIGITAL PROTOTYPE

# BASE3-06x10-T-838259

Three orthographic views + underside from the actual solid. Exterior heights include studs / text.

## FRONT

47.80

11.40

## SIDE

76.40

TOP / PRINT ORIENTATION | BOTTOM / REAL CAVITIES

Kind: front_base

STL: BASE3-06x10-T-838259.stl

STL units: mm / scale 100%

Grid: 6 x 10 @ 8.00

Body height: 9.60

Stud: dia 4.80 x 1.80 high

Tip lead-in: 0.25 high / radial

Female radial c: +0.04

Outer wall: 1.46

Tube bore: 3.20 (not accessory fit)

Roof ribs: 1.20; bridge gap <=6.80

Front row reserved (no stud/socket)

NP3 dovetail side allowance: 0.20

See front-interface.svg for sections

### BRICK PORTRAIT / PUBLIC TEMPLATE / 5-COURSE BASE / DIGITAL PROTOTYPE

# BASE3-06x10-T-e1945a

Three orthographic views + underside from the actual solid. Exterior heights include studs / text.

## FRONT

47.80

11.40

## SIDE

79.80

TOP / PRINT ORIENTATION | BOTTOM / REAL CAVITIES

Kind: front_base

STL: BASE3-06x10-T-e1945a.stl

STL units: mm / scale 100%

Grid: 6 x 10 @ 8.00

Body height: 9.60

Stud: dia 4.80 x 1.80 high

Tip lead-in: 0.25 high / radial

Female radial c: +0.04

Outer wall: 1.46

Tube bore: 3.20 (not accessory fit)

Roof ribs: 1.20; bridge gap <=6.80

Front row reserved (no stud/socket)

NP3 dovetail side allowance: 0.20

See front-interface.svg for sections

### BRICK PORTRAIT / PUBLIC TEMPLATE / 5-COURSE BASE / DIGITAL PROTOTYPE

# BASE3-24x10-B-562406

Three orthographic views + underside from the actual solid. Exterior heights include studs / text.

## FRONT

191.80

11.40

## SIDE

79.80

TOP / PRINT ORIENTATION | BOTTOM / REAL CAVITIES

Kind: front_base

STL: BASE3-24x10-B-562406.stl

STL units: mm / scale 100%

Grid: 24 x 10 @ 8.00

Body height: 9.60

Stud: dia 4.80 x 1.80 high

Tip lead-in: 0.25 high / radial

Female radial c: +0.04

Outer wall: 1.46

Tube bore: 3.20 (not accessory fit)

Roof ribs: 1.20; bridge gap <=6.80

Front row reserved (no stud/socket)

NP3 dovetail side allowance: 0.20

See front-interface.svg for sections

### BRICK PORTRAIT / PUBLIC TEMPLATE / 5-COURSE BASE / DIGITAL PROTOTYPE

# BR-01x04-H096

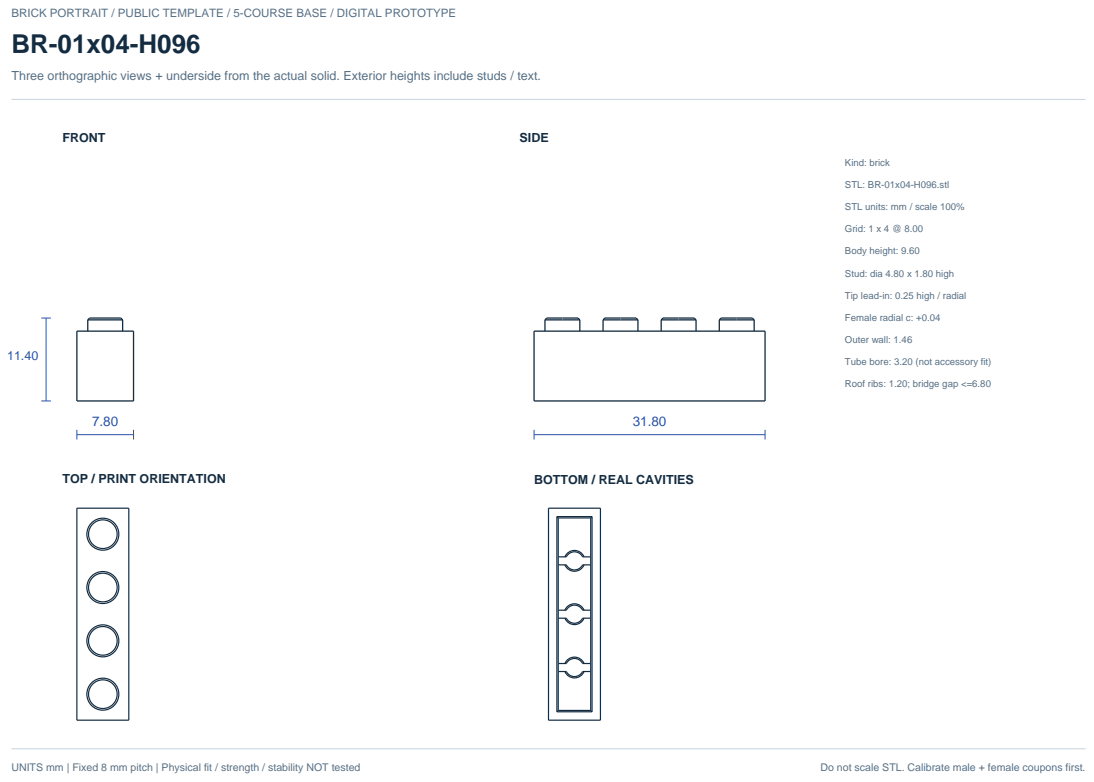
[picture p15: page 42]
FRONT; SIDE; TOP / PRINT ORIENTATION; BOTTOM / REAL CAVITIES; Kind: brick; Grid: 1 x 4 @ 8.00; Body height: 9.60; Female radial c: +0.04; Outer wall: 1.46

Three orthographic views + underside from the actual solid. Exterior heights include studs / text.

STL: BR-01x04-H096.stl

STL units: mm / scale 100%

Stud: dia 4.80 x 1.80 high

Tip lead-in: 0.25 high / radial

Tube bore: 3.20 (not accessory fit)

Roof ribs: 1.20; bridge gap <=6.80

### BRICK PORTRAIT / PUBLIC TEMPLATE / 5-COURSE BASE / DIGITAL PROTOTYPE

# BR-02x04-H064

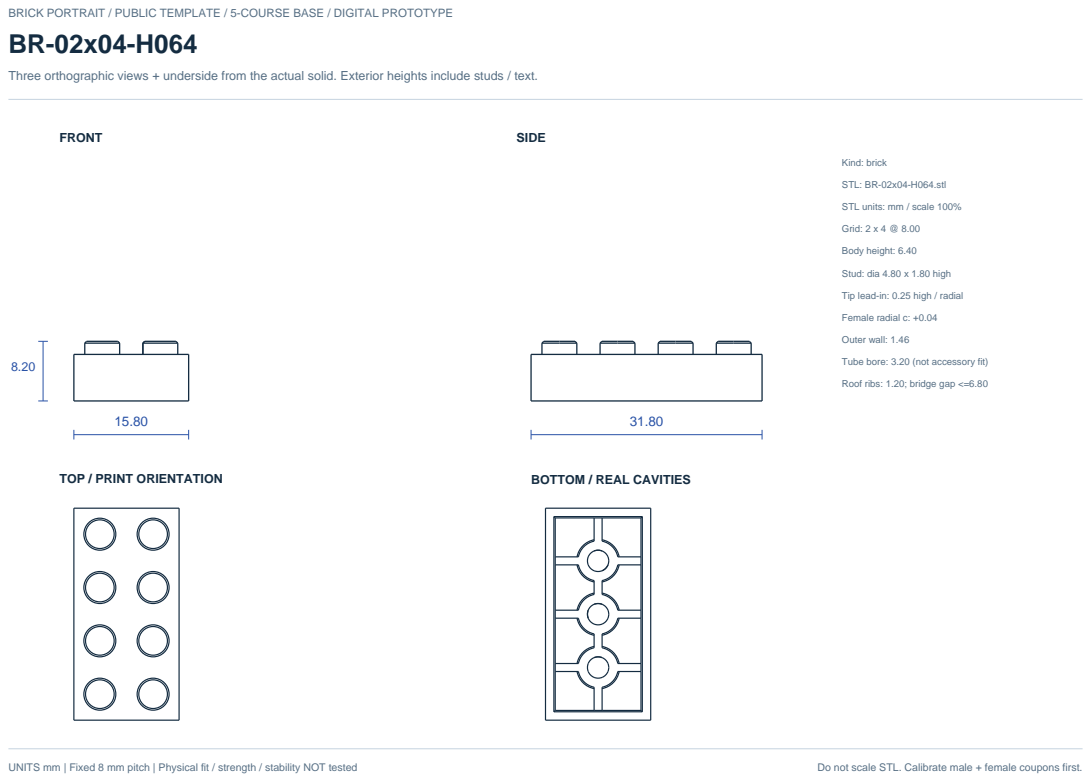
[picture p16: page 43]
FRONT; SIDE; TOP / PRINT ORIENTATION; BOTTOM / REAL CAVITIES; Kind: brick; Grid: 2 x 4 @ 8.00; Body height: 6.40; Female radial c: +0.04; Outer wall: 1.46

Three orthographic views + underside from the actual solid. Exterior heights include studs / text.

STL: BR-02x04-H064.stl

STL units: mm / scale 100%

Stud: dia 4.80 x 1.80 high

Tip lead-in: 0.25 high / radial

Tube bore: 3.20 (not accessory fit)

Roof ribs: 1.20; bridge gap <=6.80

### BRICK PORTRAIT / PUBLIC TEMPLATE / 5-COURSE BASE / DIGITAL PROTOTYPE

# BR-02x04-H096

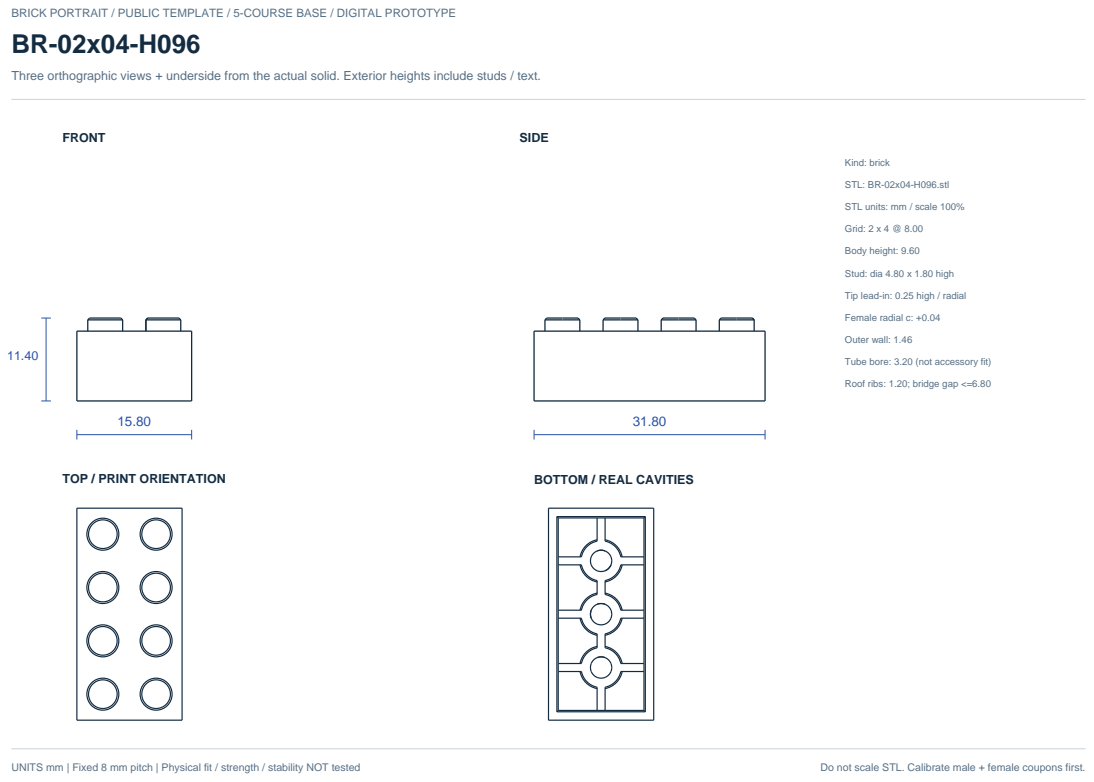
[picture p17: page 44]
FRONT; SIDE; TOP / PRINT ORIENTATION; BOTTOM / REAL CAVITIES; Kind: brick; Grid: 2 x 4 @ 8.00; Body height: 9.60; Female radial c: +0.04; Outer wall: 1.46

Three orthographic views + underside from the actual solid. Exterior heights include studs / text.

STL: BR-02x04-H096.stl

STL units: mm / scale 100%

Stud: dia 4.80 x 1.80 high

Tip lead-in: 0.25 high / radial

Tube bore: 3.20 (not accessory fit)

Roof ribs: 1.20; bridge gap <=6.80

### BRICK PORTRAIT / PUBLIC TEMPLATE / 5-COURSE BASE / DIGITAL PROTOTYPE

# BR-02x05-H096

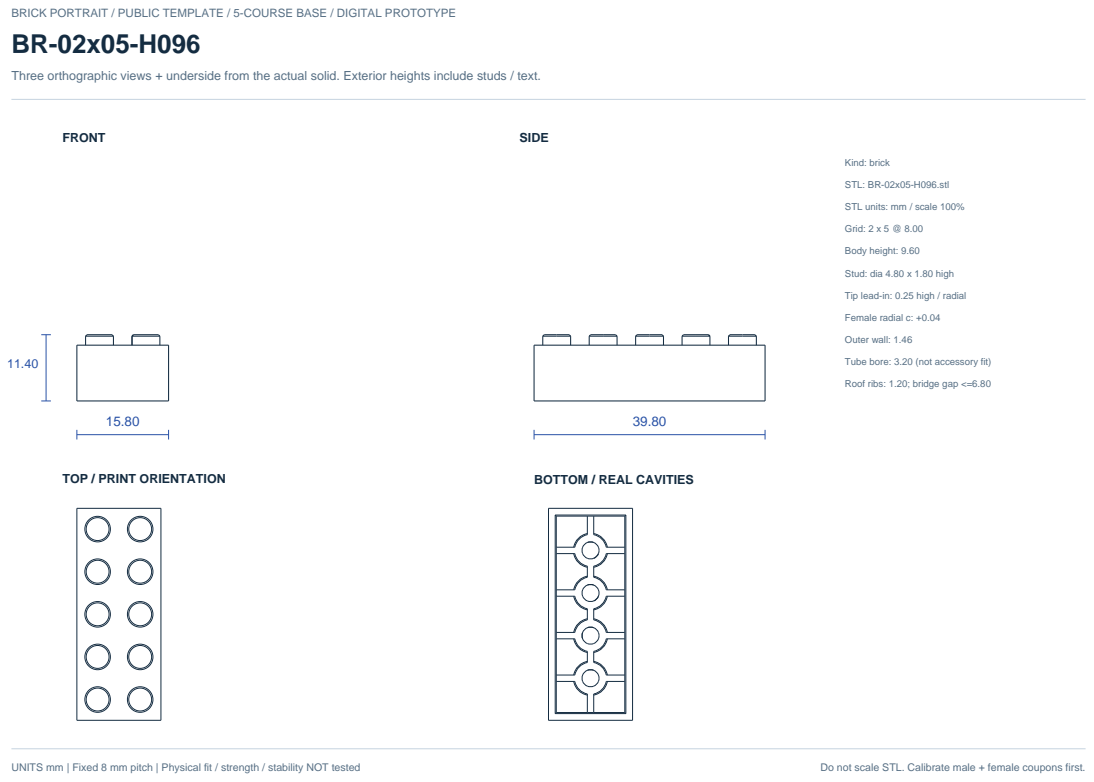
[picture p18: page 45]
FRONT; SIDE; TOP / PRINT ORIENTATION; BOTTOM / REAL CAVITIES; Kind: brick; Grid: 2 x 5 @ 8.00; Body height: 9.60; Female radial c: +0.04; Outer wall: 1.46

Three orthographic views + underside from the actual solid. Exterior heights include studs / text.

STL: BR-02x05-H096.stl

STL units: mm / scale 100%

Stud: dia 4.80 x 1.80 high

Tip lead-in: 0.25 high / radial

Tube bore: 3.20 (not accessory fit)

Roof ribs: 1.20; bridge gap <=6.80

### BRICK PORTRAIT / PUBLIC TEMPLATE / 5-COURSE BASE / DIGITAL PROTOTYPE

# BR-02x06-H096

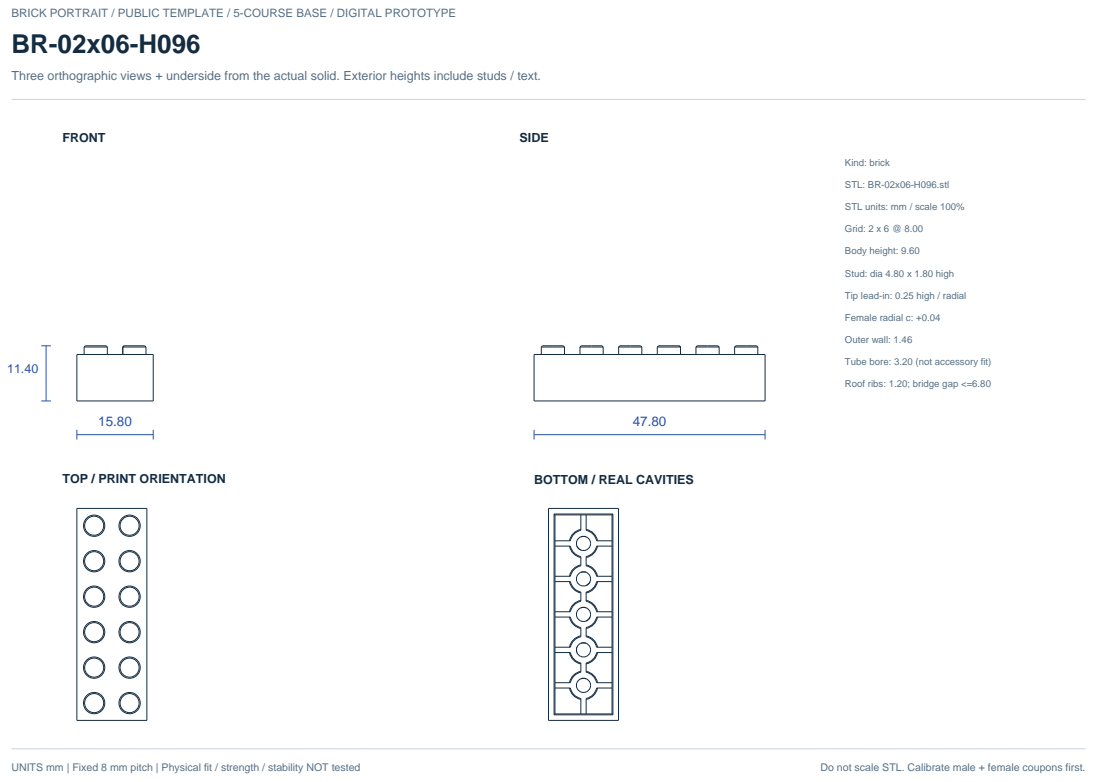
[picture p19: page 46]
FRONT; SIDE; TOP / PRINT ORIENTATION; BOTTOM / REAL CAVITIES; Kind: brick; Grid: 2 x 6 @ 8.00; Body height: 9.60; Female radial c: +0.04; Outer wall: 1.46

Three orthographic views + underside from the actual solid. Exterior heights include studs / text.

STL: BR-02x06-H096.stl

STL units: mm / scale 100%

Stud: dia 4.80 x 1.80 high

Tip lead-in: 0.25 high / radial

Tube bore: 3.20 (not accessory fit)

Roof ribs: 1.20; bridge gap <=6.80

### BRICK PORTRAIT / PUBLIC TEMPLATE / 5-COURSE BASE / DIGITAL PROTOTYPE

# BR-03x04-H096

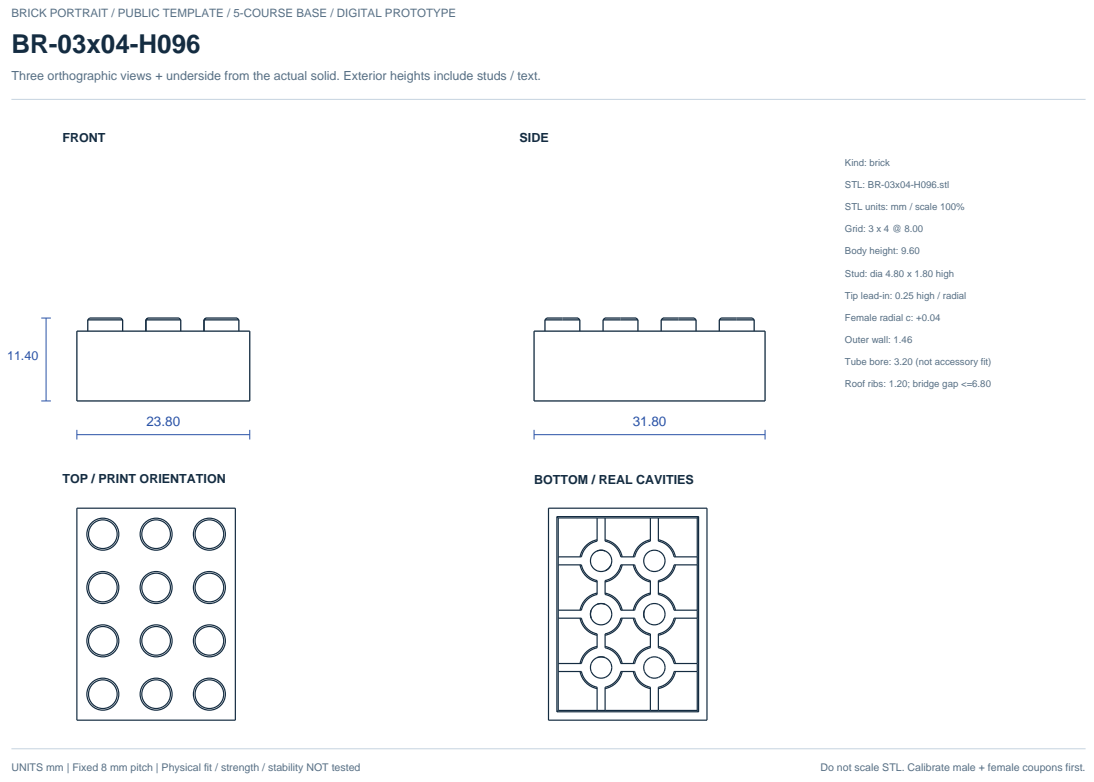
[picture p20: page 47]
FRONT; SIDE; TOP / PRINT ORIENTATION; BOTTOM / REAL CAVITIES; Kind: brick; Grid: 3 x 4 @ 8.00; Body height: 9.60; Female radial c: +0.04; Outer wall: 1.46

Three orthographic views + underside from the actual solid. Exterior heights include studs / text.

STL: BR-03x04-H096.stl

STL units: mm / scale 100%

Stud: dia 4.80 x 1.80 high

Tip lead-in: 0.25 high / radial

Tube bore: 3.20 (not accessory fit)

Roof ribs: 1.20; bridge gap <=6.80

### BRICK PORTRAIT / PUBLIC TEMPLATE / 5-COURSE BASE / DIGITAL PROTOTYPE

# BR-04x04-H064

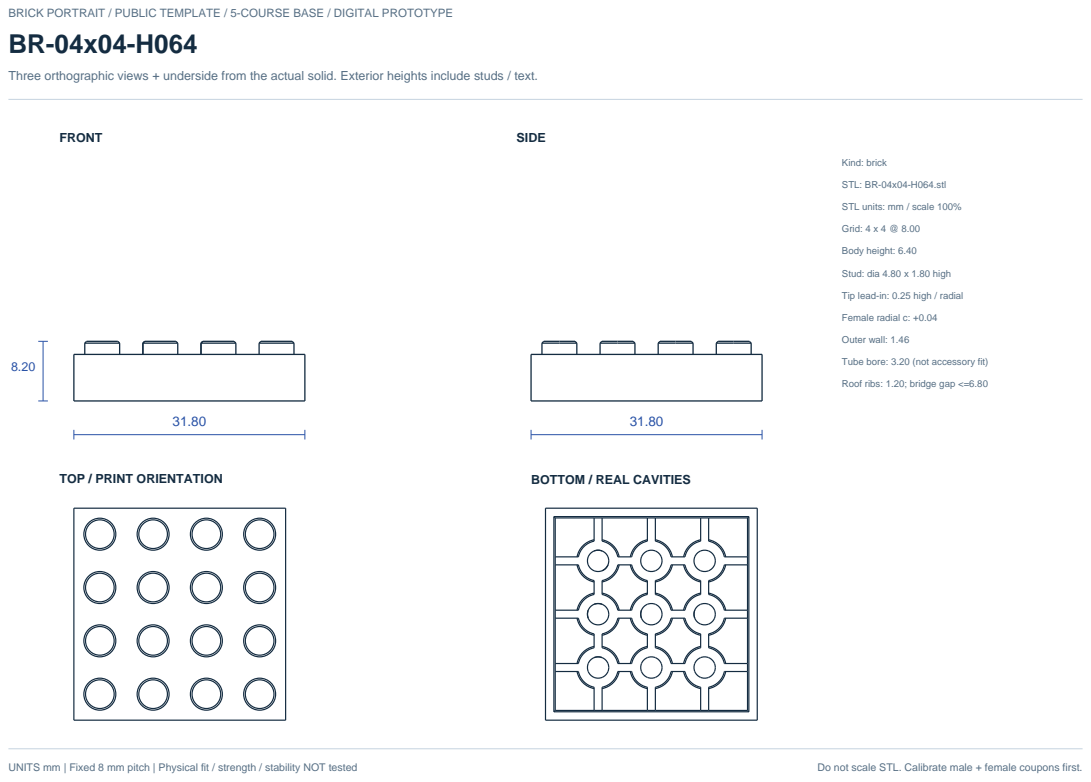
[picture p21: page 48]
FRONT; SIDE; TOP / PRINT ORIENTATION; BOTTOM / REAL CAVITIES; Kind: brick; Grid: 4 x 4 @ 8.00; Body height: 6.40; Female radial c: +0.04; Outer wall: 1.46

Three orthographic views + underside from the actual solid. Exterior heights include studs / text.

STL: BR-04x04-H064.stl

STL units: mm / scale 100%

Stud: dia 4.80 x 1.80 high

Tip lead-in: 0.25 high / radial

Tube bore: 3.20 (not accessory fit)

Roof ribs: 1.20; bridge gap <=6.80

### BRICK PORTRAIT / PUBLIC TEMPLATE / 5-COURSE BASE / DIGITAL PROTOTYPE

# BR-04x04-H096

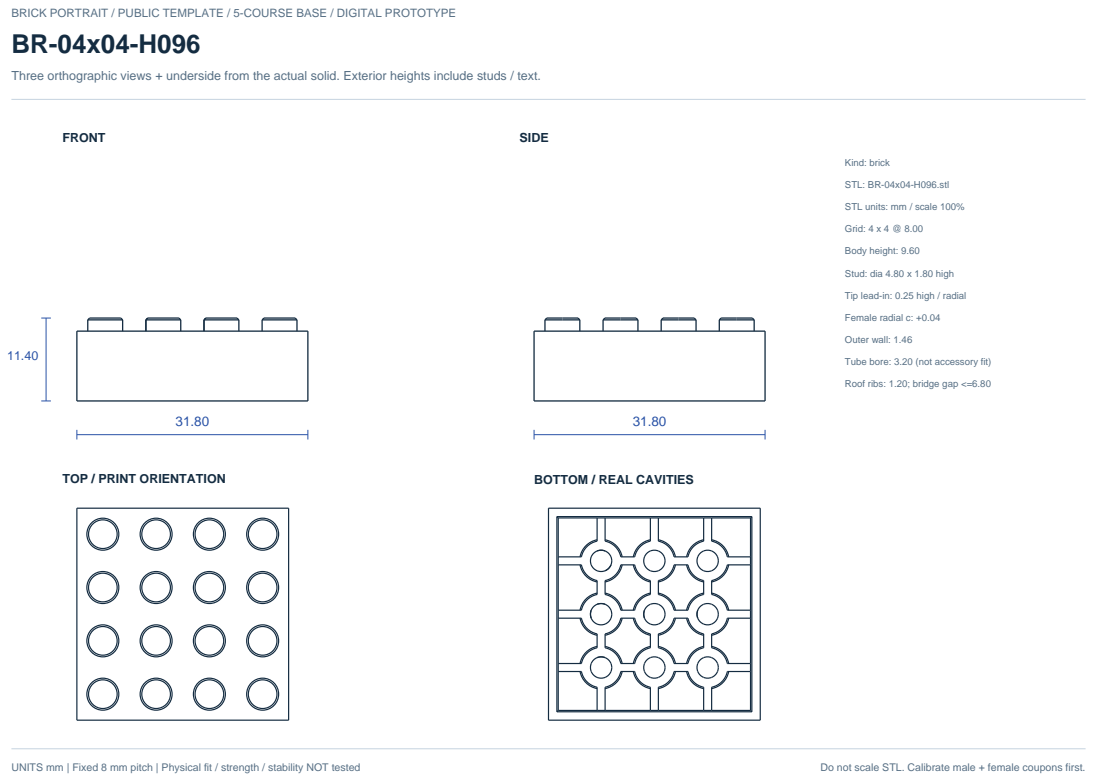
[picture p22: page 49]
FRONT; SIDE; TOP / PRINT ORIENTATION; BOTTOM / REAL CAVITIES; Kind: brick; Grid: 4 x 4 @ 8.00; Body height: 9.60; Female radial c: +0.04; Outer wall: 1.46

Three orthographic views + underside from the actual solid. Exterior heights include studs / text.

STL: BR-04x04-H096.stl

STL units: mm / scale 100%

Stud: dia 4.80 x 1.80 high

Tip lead-in: 0.25 high / radial

Tube bore: 3.20 (not accessory fit)

Roof ribs: 1.20; bridge gap <=6.80

### BRICK PORTRAIT / PUBLIC TEMPLATE / 5-COURSE BASE / DIGITAL PROTOTYPE

# BR-04x05-H096

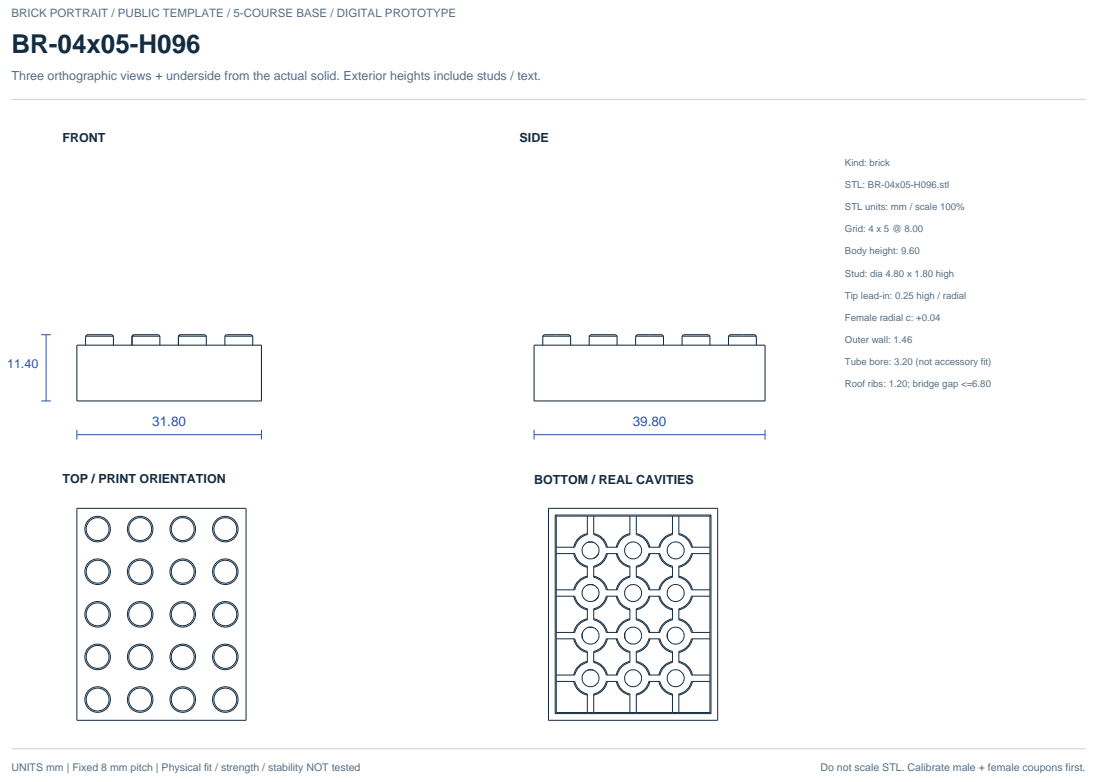
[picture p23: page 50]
FRONT; SIDE; TOP / PRINT ORIENTATION; BOTTOM / REAL CAVITIES; Kind: brick; Grid: 4 x 5 @ 8.00; Body height: 9.60; Female radial c: +0.04; Outer wall: 1.46

Three orthographic views + underside from the actual solid. Exterior heights include studs / text.

STL: BR-04x05-H096.stl

STL units: mm / scale 100%

Stud: dia 4.80 x 1.80 high

Tip lead-in: 0.25 high / radial

Tube bore: 3.20 (not accessory fit)

Roof ribs: 1.20; bridge gap <=6.80

### BRICK PORTRAIT / PUBLIC TEMPLATE / 5-COURSE BASE / DIGITAL PROTOTYPE

# BR-05x04-H096

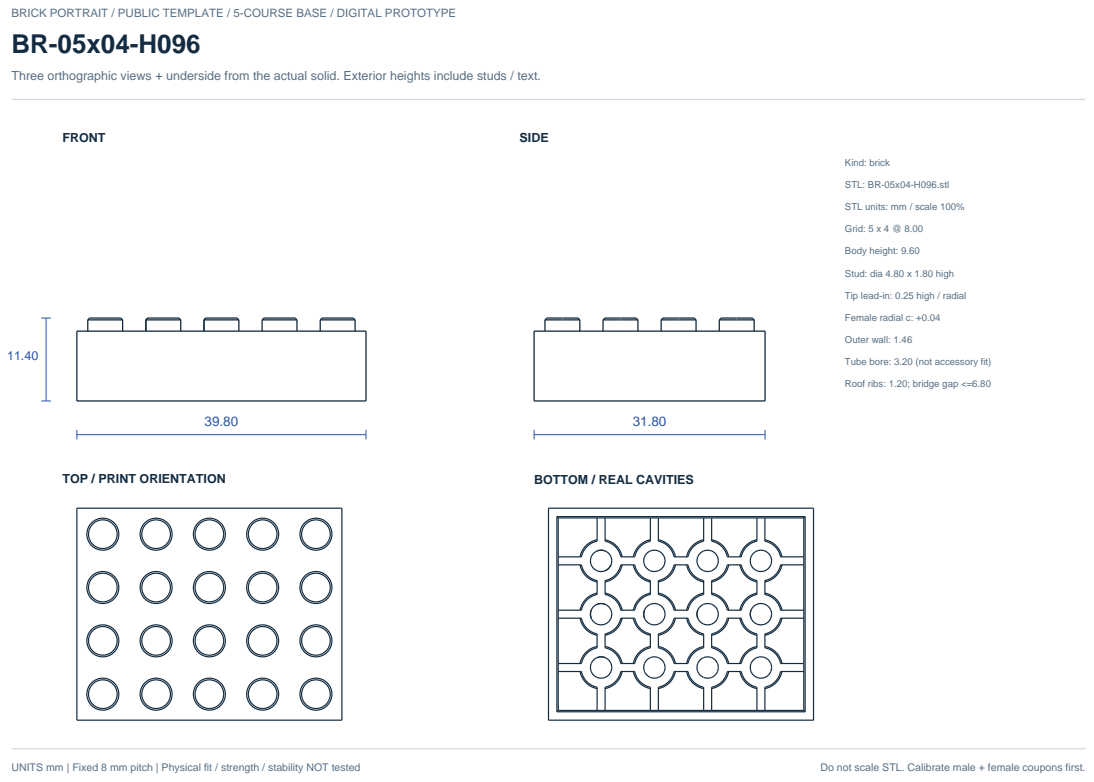
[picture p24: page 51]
FRONT; SIDE; TOP / PRINT ORIENTATION; BOTTOM / REAL CAVITIES; Kind: brick; Grid: 5 x 4 @ 8.00; Body height: 9.60; Female radial c: +0.04; Outer wall: 1.46

Three orthographic views + underside from the actual solid. Exterior heights include studs / text.

STL: BR-05x04-H096.stl

STL units: mm / scale 100%

Stud: dia 4.80 x 1.80 high

Tip lead-in: 0.25 high / radial

Tube bore: 3.20 (not accessory fit)

Roof ribs: 1.20; bridge gap <=6.80

### BRICK PORTRAIT / PUBLIC TEMPLATE / 5-COURSE BASE / DIGITAL PROTOTYPE

# NP3-KEEPER

Three orthographic views + underside from the actual solid. Exterior heights include studs / text.

## FRONT

15.80

3.20

## SIDE

15.80

TOP / PRINT ORIENTATION | BOTTOM / REAL CAVITIES

Kind: front_keeper

STL: NP3-KEEPER.stl

STL units: mm / scale 100%

Grid: 2 x 1 @ 8.00

Body height: 3.20

Female radial c: +0.04

Outer wall: 1.46

Tube bore: 3.20 (not accessory fit)

Roof ribs: 1.20; bridge gap <=6.80

Socket row at local Y=12.00

Flat front stop covers module top

Lift 6mm, then forward >=32mm and aside

### BRICK PORTRAIT / PUBLIC TEMPLATE / 5-COURSE BASE / DIGITAL PROTOTYPE

# NP3-LOGO-B

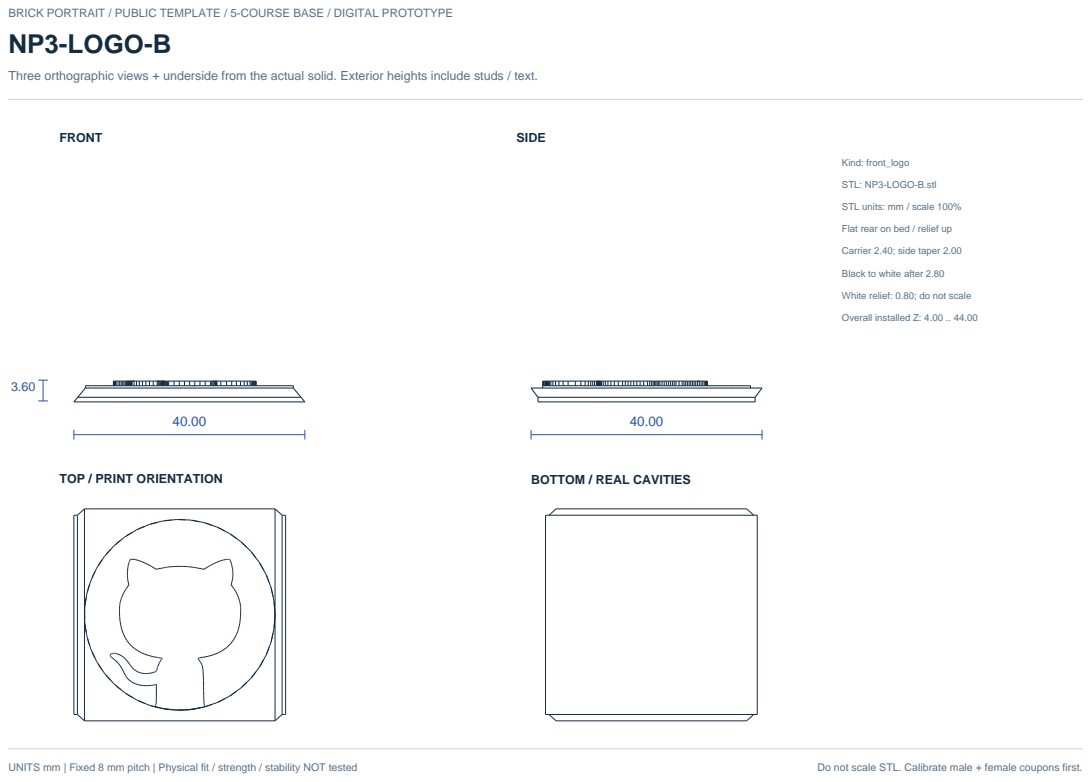
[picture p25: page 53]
FRONT; SIDE; TOP / PRINT ORIENTATION; BOTTOM / REAL CAVITIES; Kind: front_logo; Overall installed Z: 4.00 .. 44.00

Three orthographic views + underside from the actual solid. Exterior heights include studs / text.

STL: NP3-LOGO-B.stl

STL units: mm / scale 100%

Flat rear on bed / relief up

Carrier 2.40; side taper 2.00

Black to white after 2.80

White relief: 0.80; do not scale

## PRIVATE B / 4.1-B-legibility.1 / TWO-LINE NAMEPLATE

# NP3-TEXT-B / LEGIBILITY V2

Actual current FreeCAD geometry; NOT_SLICED / physical fit and print quality unverified.

# TOP / REAR ON BED / LETTERS UP

142.00 x40.00

NATIVE SECTION Y=26 / TOTAL3.60 | SECTION X=71 /40.00 x3.60

Unchanged black carrier:142 x40 x2.4; keyed rear geometry preserved.

Actual ink row heights12 /10; white relief1.2; black-to-white after2.4.

# Same icon, New adventures

# github.com/tomokota

Print the lettering coupon first. Thickness does not diagnose stringing or surface roughness.

UNITS mm | STL100% | Black support2.4; white letters1.2; add Pause before white paths.

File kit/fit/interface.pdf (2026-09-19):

BRICK PORTRAIT / PUBLIC TEMPLATE / 5-COURSE BASE / DIGITAL PROTOTYPE

# INTERFACE / SECTION & CLEARANCE

Project design candidates, NOT a proprietary tolerance standard. Geometry from FreeCAD planar sections.

SECTION: Y = 4.00 / TWO 2x2 BRICKS

JOINT SECTION: Z = 10.50

Actual wall, tube, rib + mating stud outlines

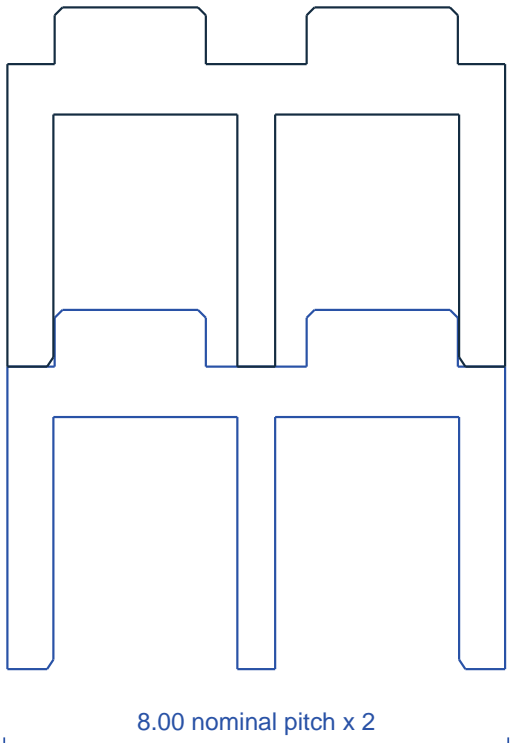
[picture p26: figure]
8.00 nominal pitch x 2

Blue: lower brick / black: upper socket

Reference stud dia 4.80; candidate height 1.80 Radial clearance c=+0.04 (default; untested)

Inside wall offset 1.56 / wall thickness 1.46

Tube OD 6.433708 / ID 3.20; grid rib 1.20

Tip lead-in 0.25 / female lead-in 0.20 x 0.30

Roof 1.60; thin plate roof 1.00

Thin plate / keeper: nominal headroom 0.40

No forced fit. Tune male and female separately.

UNITS mm | Fixed 8 mm pitch | Physical fit / strength / stability NOT tested | Do not scale STL. Calibrate male + female coupons first.

BRICK PORTRAIT / PUBLIC TEMPLATE / 5-COURSE BASE / DIGITAL PROTOTYPE

# NP3 / BASE-FRONT CAPTURE & REMOVAL

Actual BREP sections; precise dimensions apply to the nominal model, not guaranteed printed fit.

B / HORIZONTAL SECTION Z=24 / FRONT 8mm BAND

B message: 142.00

B logo carrier: 40.00

VERTICAL SECTION X=40

48.00

Blue: installed modules; black: actual receiver / keepers

Carrier thickness2.40 / rear flat0.80 / edge relief1.20

Rear width -> front width: 2.00 inset on each X side

Default side clearance0.20; coupon candidates0.15/0.20/0.25

Text backY=3.30; logo backY=3.70; relief frontY=0.10

Both front modules fit in Z=4.00..44.00, inside48mm base

3 separate up-stops: text2 / logo1; stud-grid mounting

Remove: up-stops up6, forward>=32; module up45

Thread / glue / magnet / purchased fastener not required

Physical clutch, retention, flatness and stability NOT tested

UNITS mm | Fixed 8 mm pitch | Physical fit / strength / stability NOT tested | Do not scale STL. Calibrate male + female coupons first.

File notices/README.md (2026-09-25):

# 権利・出典に関する表記

この個人向けキットの元コード、CAD、図、説明全体を覆う包括ライセンスは設定していません。
publicになったことは、商用利用・再配布・商標利用を一律に許可する意味ではありません。
再利用の条件は権利者・リポジトリ所有者へ確認してください。

| このキットに含めたもの | 表記・出典 |
|---|---|
| Barlow Condensed Bold / Black | SIL Open Font License 1.1。[原文OFL](../source/resources/fonts/barlow-condensed/OFL.txt)。上段Bold・下段Blackの輪郭に使用。フォントファイル自体は未改変 |
| GitHubマークの派生輪郭 | [輪郭データ](../source/resources/github-mark-relief.json)。提供された図柄に由来する支持体付きレリーフ。元ラスタ画像は非収録 |
| 既存Bのコード・形状・媒体 | [provenance](../docs/PROVENANCE.md)に固定commit・再利用範囲を記載 |
| 元プロジェクトのnotice | [原文をそのまま保存](upstream-rights.md) |
| Three.js 0.180.0、同版のOrbitControls／STLLoader | [MIT原文](THREE-LICENSE.txt)。オフライン3Dランタイムへ同梱。生成HTMLとruntimeのbannerにも全文を保持 |
| 制作記録の実写真24枚 | ユーザー提供。9/23までの9枚、9/24の7枚、9/25の制作過程・完成8枚は各回の掲載許可済み。[写真の取扱い](../docs/BUILD-LOG.md#写真の取扱い)。写真の権利はユーザーに帰属し、モデル／フォント／ソフトウェアのライセンスを自動適用しない |

原文noticeには元サイトで使われるThree.jsとB612への言及があります。
この版ではThree.jsをオフライン3D案内と、承認済みのGitHub Pages案内で使用します。
B612フォント本体は収録していません。同梱フォントはBarlow Condensed BoldとBlackで、
そのOFLを保持しています。ガイドの画面文字は端末のシステムフォントを利用します。

FreeCAD、Blender、ReportLab、Python、NumPy、trimesh、Shapely、SciPy、svglib、pypdf、Playwright、Pillow、Markdown、esbuild等は作成・検証のツールです。
それらのアプリ／ライブラリ本体は同梱しません。各ツールのライセンスはそれぞれに適用されます。
制作記録に含めるのは許可された加工済み写真だけです。加工前の原画像・EXIF、無関係な人物・バッグ画像、
参考資料PDF、依頼会話、機器の認証情報は収録しません。写真の掲載許可は第三者への包括的な再利用許諾ではありません。

GitHub、LEGO、Bambu Lab等の名称は、図柄・接続の参考・使用機器を示すものです。
この模型は非公式の個人用卓上オブジェで、各社の公式商品・認定品・互換保証品ではありません。
GitHubマークの包括的な商標利用許諾を与えるものではありません。

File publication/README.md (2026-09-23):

# 公開範囲とGitHub Pages

2026-09-23、ユーザーから個人向けリポジトリ全体のpublic化と、
本人へ説明・作り方・工程を見せるGitHub Pagesの公開を明示的に承認されました。
以前の「private／Pagesなし」方針はこの承認で更新しています。

リポジトリの現在の追跡ファイルとGit履歴は公開されます。
切替前に、実際にremoteへ公開されるmainの5コミット・368 blobと、
ZIP／3MF／native内部を含む569件の内容を点検しました。
認証情報・絶対ローカルパス・加工前写真・元パス監査表・画像EXIFは検出されませんでした。
個人銘板と許可済み写真は意図した公開内容であり、秘密として誤分類していません。

`.work`、未追跡の私有フォルダ、セッション状態、ローカルのCopilot checkpoint refsは、
このリポジトリの公開ブランチへpushしていません。履歴を削除・書き換える作業でもありません。
公開された内容は第三者にコピー・cacheされ得るため、削除で完全回収できる保証はありません。

Pagesは公開用の出力だけをアップロードします。リポジトリのルートをそのまま配信しません。
原写真、EXIF、認証情報、監査元パス、内部検証記録、nativeの一式、旧版・旧履歴は、
Pagesの配信フォルダに含めません。印刷データは公開repoの対応ファイルへリンクします。

模型の寸法、100%の印刷倍率、150配置は今回変更していません。
この作業は公開のための案内と配信設定の変更で、形状・表示・工程進捗の縮小ではありません。

[公開方針](policy.json)に、公開許可と除外範囲を記録しています。

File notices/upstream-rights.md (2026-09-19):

# Notices and rights

No blanket license has been selected for this project's original code, CAD, artwork, or documents.
Public availability is not a statement that all uses are permitted. Ask the repository owner
about reuse terms. This file does not relabel third-party components.

Third-party material intentionally redistributed:

| Material | License / notice location | Purpose |
| --- | --- | --- |
| Three.js 0.180.0 | MIT, `site/vendor/THREE-LICENSE.txt` | Local browser 3D runtime |
| B612 Mono Bold | SIL Open Font License 1.1, `resources/fonts/OFL.txt` | Exact approved message outlines |
| Barlow Condensed Black | SIL Open Font License 1.1, `resources/fonts/barlow-condensed/OFL.txt` | Enlarged two-line normal-model lettering |

Python packages, FreeCAD, Blender and ffmpeg are build/runtime tools rather than vendored
application binaries. Their respective licenses remain applicable. Package versions are pinned
where installed for this project. Source-reference PDFs and proprietary photographs are not copied
into the public package.

The new front logo is a supported 3D relief derived from the user's supplied GitHub mark.
Only the derived contours and manufactured geometry are included; the input raster is not distributed.
This does not grant a blanket trademark license or claim official status.

LEGO, Bambu Lab and GitHub names identify references, intended interfaces, tools or the public
profile URL. This is an original, unofficial personal display model. It is not an official LEGO
or GitHub product and has no endorsement or compatibility certification from those organizations.

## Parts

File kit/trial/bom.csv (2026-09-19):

part | quantity | color | stage | stl | sha256 | width_mm | depth_mm | height_mm | orientation
BR-02x02-H096 | 2 | black | real-blocks | parts/BR-02x02-H096.stl | 16726dd1b4b1e1a44bc8c0871ab681cf12c200643be356c5f1903c0017395d30 | 15.8 | 15.8 | 11.4 | underside_on_bed_studs_up
BR-02x04-H096 | 2 | black | real-blocks | ../B/parts/BR-02x04-H096.stl | 31b61fbf103450546cda92dfe50bfc24393e776bbe62a45d24d6084cb0c7a269 | 15.8 | 31.8 | 11.4 | underside_on_bed_studs_up
NP3-KEEPER | 1 | black | keeper-base | ../B/parts/NP3-KEEPER.stl | b523f99637728aa9e51b4025ec778016f0c9d78f9959aa7823abb71ce691978f | 15.8 | 15.8 | 3.2 | flat_front_pad_and_socket_down
BASE3-03x10-T-aa77a9 | 2 | black | keeper-base | ../B/parts/BASE3-03x10-T-aa77a9.stl | 0eedec766e01cdbef5539540873c80f90309018d6958a6b77b19516be633f18e | 23.8 | 79.8 | 11.4 | underside_on_bed_studs_up

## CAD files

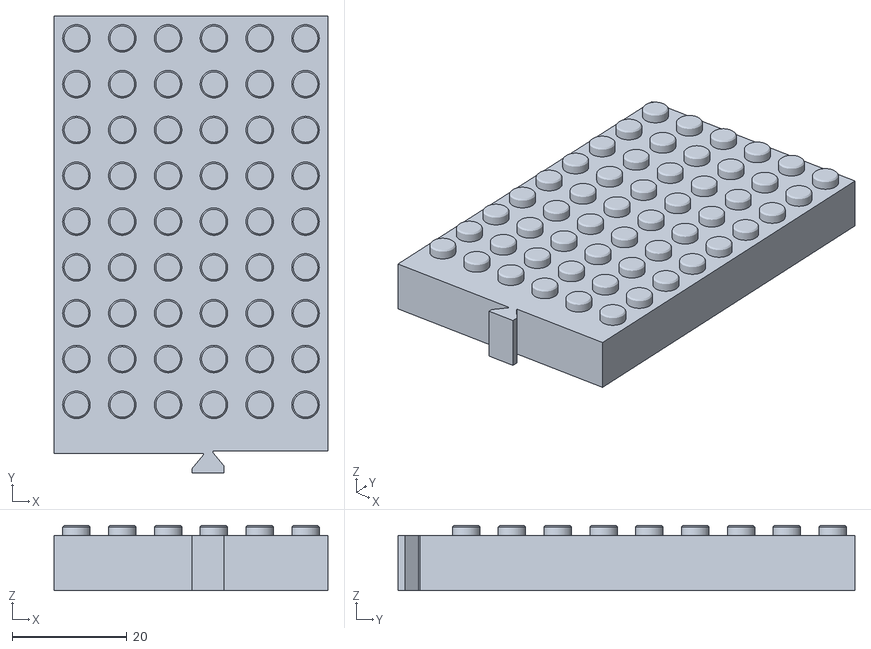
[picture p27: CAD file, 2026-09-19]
kit/B/parts/BASE3-06x10-T-6159e6.stl
47.8 x 79.8 x 11.4

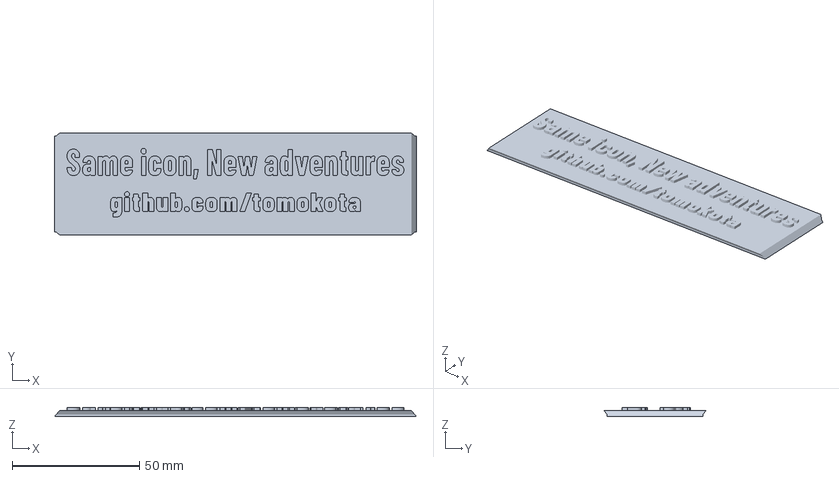
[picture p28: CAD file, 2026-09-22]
kit/B/plates/B-black-to-white-z2p4-01.3mf
142.0 x 40.0 x 3.60 mm

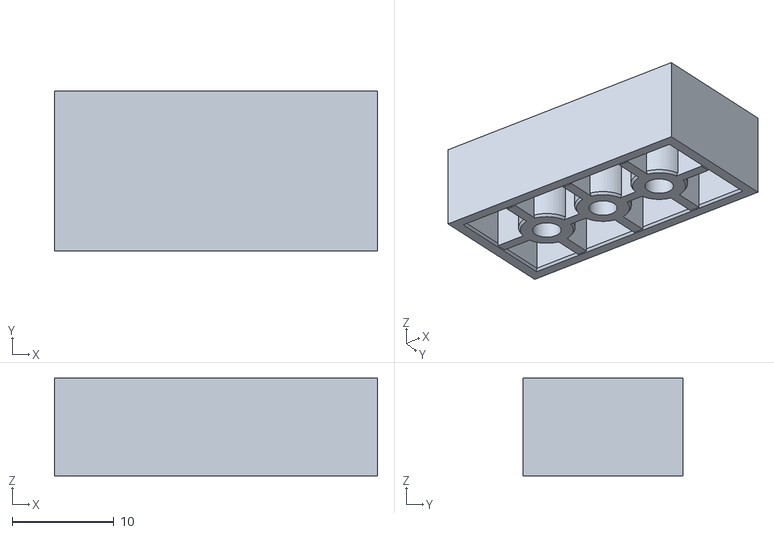
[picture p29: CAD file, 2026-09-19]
kit/fit/FIT-F-CP08.stl
31.8 x 15.8 x 9.60

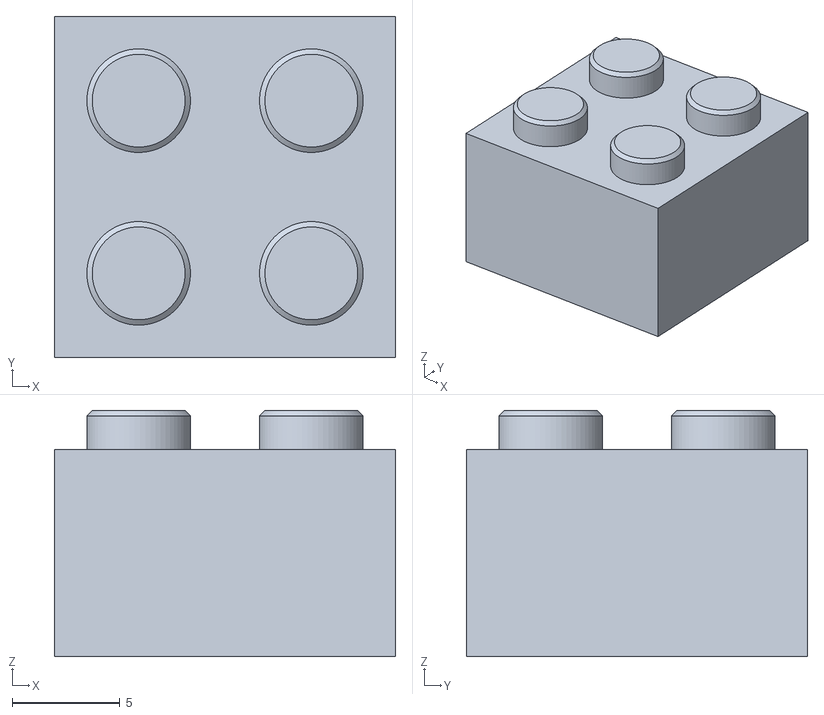
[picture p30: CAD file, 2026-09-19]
kit/trial/parts/BR-02x02-H096.stl
15.8 x 15.8 x 11.4

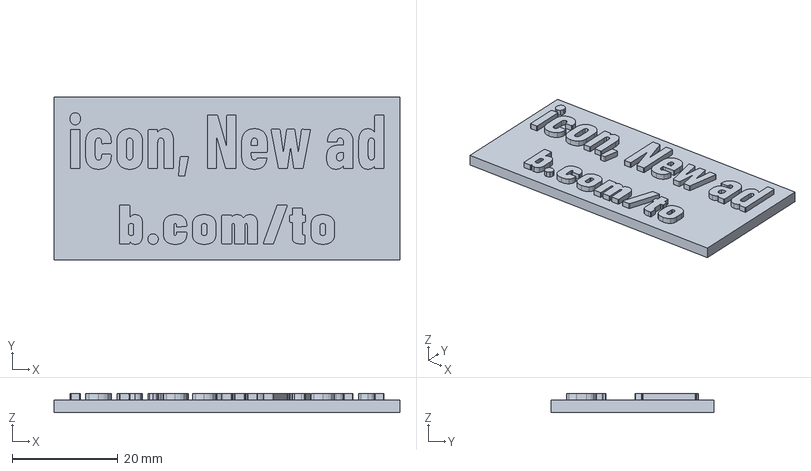
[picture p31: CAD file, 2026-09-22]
proposals/plate-legibility-v2/coupon/coupon.step
65.4 x 30.9 x 3.60 mm

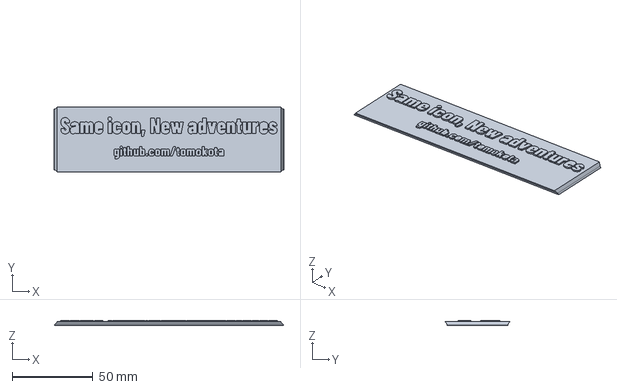
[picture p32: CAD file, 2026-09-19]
revisions/4.0-B-personal-kit.2/nameplate/plate.step
142.0 x 40.0 x 3.20 mm

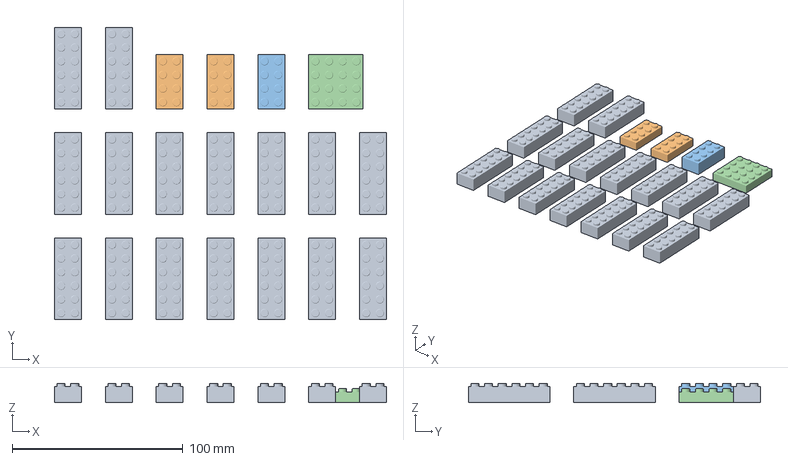
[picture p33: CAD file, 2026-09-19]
kit/B/plates/B-magenta-01.3mf
194.6 x 171.4 x 11.4 mm
BR-02x06-H096 x 16
BR-02x04-H064 x 2
BR-02x04-H096
BR-04x04-H064

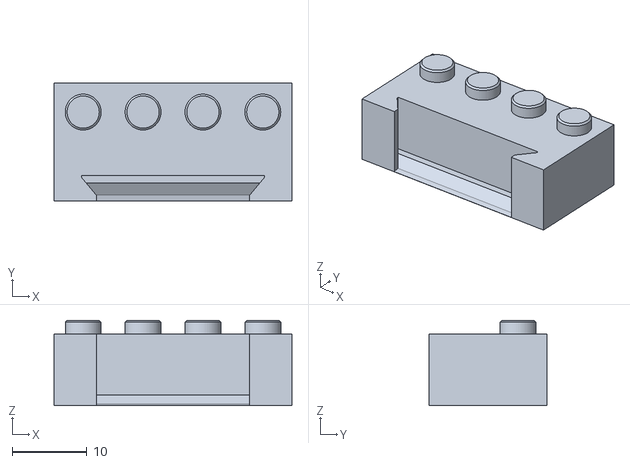
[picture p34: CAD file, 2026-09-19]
kit/fit/NP3-FIT-SOCKET-C25.stl
31.8 x 15.8 x 11.4

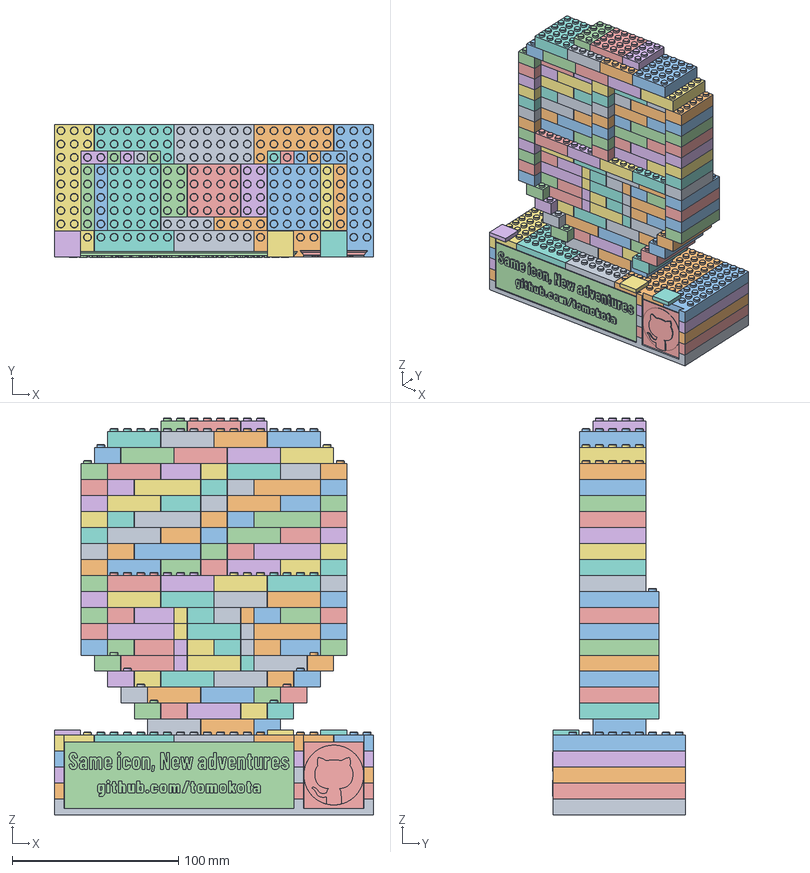
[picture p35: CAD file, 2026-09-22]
source/native/B.FCStd
191.8 x 80.2 x 238.6 mm
B-001 | BASE3-24x10-B-562406 | black
B-002 | BASE3-06x10-T-e1945a | black
B-003 | BASE3-06x10-T-838259 | black
B-004 | BASE3-06x10-T-3f87ac | black
B-005 | BASE3-06x10-T-6e100f | black
B-006 | BASE3-03x10-T-aa77a9 | black
B-007 | BASE3-06x10-T-838259 | black
B-008 | BASE3-06x10-T-838259 | black
B-009 | BASE3-06x10-T-6159e6 | black
B-010 | BASE3-03x10-T-d79875 | black
B-011 | BASE3-06x10-T-e1945a | black
B-012 | BASE3-06x10-T-838259 | black
B-013 | BASE3-06x10-T-3f87ac | black
B-014 | BASE3-06x10-T-6e100f | black
B-015 | BASE3-03x10-T-aa77a9 | black
B-016 | BASE3-06x10-T-838259 | black
B-017 | BASE3-06x10-T-838259 | black
B-018 | BASE3-06x10-T-6159e6 | black
B-019 | BASE3-03x10-T-d79875 | black
B-020 | NP3-TEXT-B | black
B-021 | NP3-LOGO-B | black
B-022 | NP3-KEEPER | black
B-023 | NP3-KEEPER | black
B-024 | NP3-KEEPER | black
B-025 | BR-04x04-H096 | magenta
B-026 | BR-04x04-H096 | magenta
B-027 | BR-02x04-H096 | magenta
B-028 | BR-02x06-H096 | magenta
B-029 | BR-02x04-H096 | black
B-030 | BR-04x04-H096 | black
B-031 | BR-02x04-H096 | black
B-032 | BR-02x06-H096 | magenta
B-033 | BR-02x06-H096 | magenta
B-034 | BR-04x04-H096 | black
B-035 | BR-04x04-H096 | black
B-036 | BR-02x04-H096 | black
B-037 | BR-02x06-H096 | magenta
B-038 | BR-02x06-H096 | magenta
B-039 | BR-02x04-H096 | black
B-040 | BR-04x04-H096 | black
B-041 | BR-04x04-H096 | black
B-042 | BR-02x04-H096 | black
B-043 | BR-02x06-H096 | magenta
B-044 | BR-02x06-H096 | magenta
B-045 | BR-04x04-H096 | black
B-046 | BR-01x04-H096 | green
B-047 | BR-04x04-H096 | black
B-048 | BR-01x04-H096 | green
B-049 | BR-04x04-H096 | black
B-050 | BR-02x06-H096 | magenta
B-051 | BR-02x06-H096 | magenta
B-052 | BR-02x04-H096 | black
B-053 | BR-03x04-H096 | black
B-054 | BR-01x04-H096 | green
B-055 | BR-02x04-H096 | black
B-056 | BR-02x04-H096 | black
B-057 | BR-01x04-H096 | green
B-058 | BR-02x04-H096 | black
B-059 | BR-03x04-H096 | black
B-060 | BR-02x06-H096 | magenta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

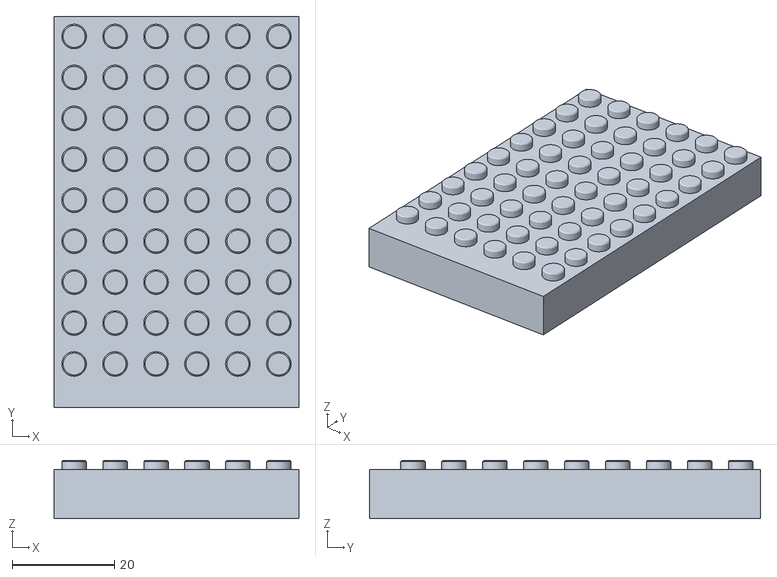
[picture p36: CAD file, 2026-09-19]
kit/B/parts/BASE3-06x10-T-838259.stl
47.8 x 76.4 x 11.4

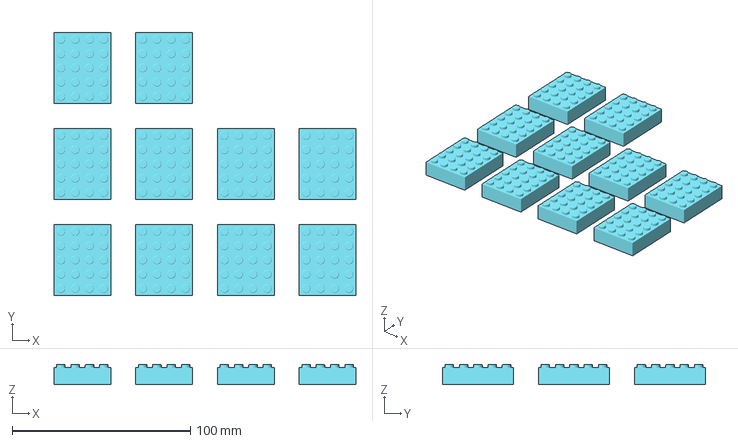
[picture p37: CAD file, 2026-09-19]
kit/B/plates/B-cyan-02.3mf
169.2 x 147.4 x 11.4 mm
BR-04x05-H096 x 10

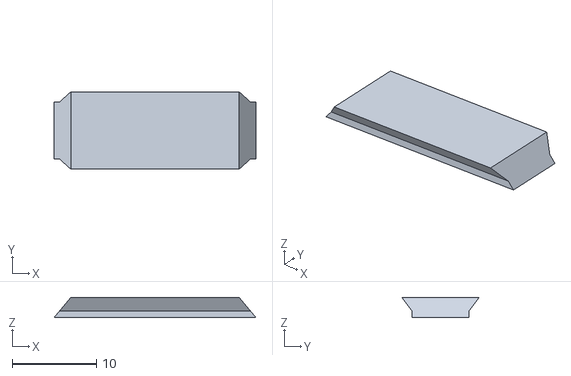
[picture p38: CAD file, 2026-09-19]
kit/fit/NP3-FIT-PLAQUE.stl
24.0 x 9.20 x 2.40

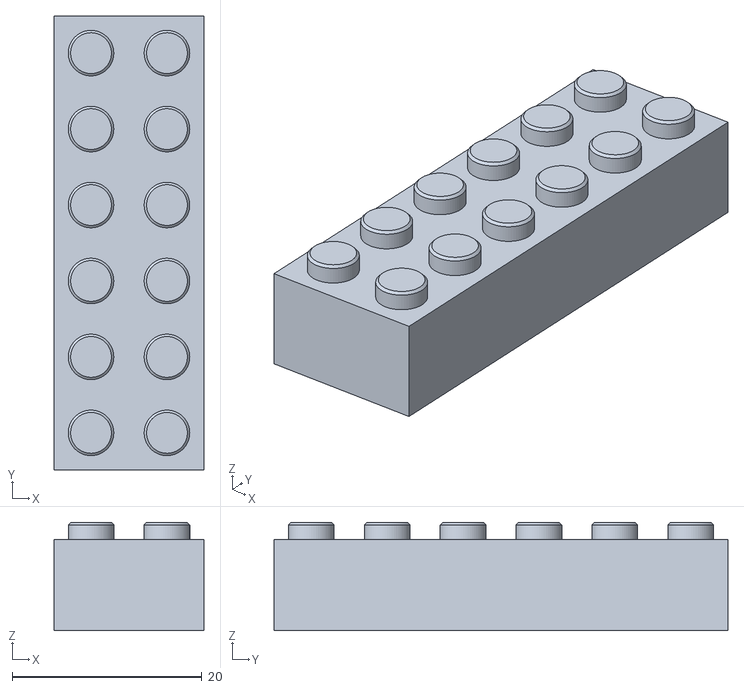
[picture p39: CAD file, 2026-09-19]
kit/B/parts/BR-02x06-H096.stl
15.8 x 47.8 x 11.4

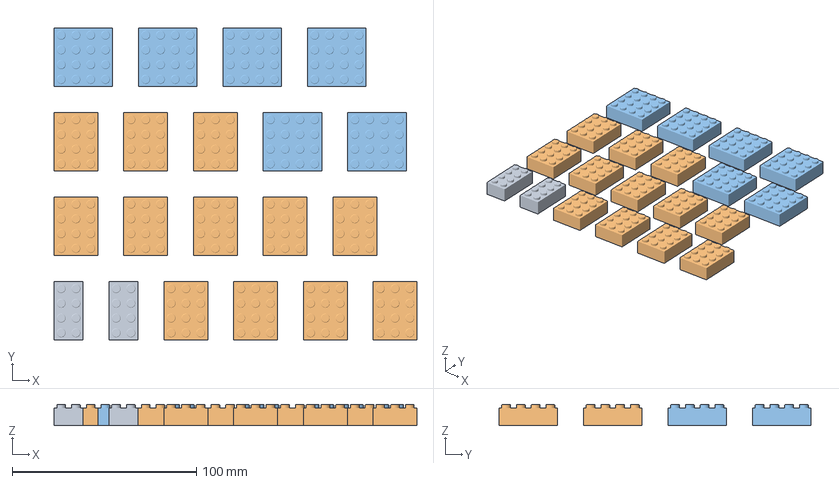
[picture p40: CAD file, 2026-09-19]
kit/B/plates/B-black-05.3mf
196.8 x 169.2 x 11.4 mm
BR-02x04-H096 x 2
BR-03x04-H096 x 12
BR-04x04-H096 x 6

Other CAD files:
proposals/plate-legibility-v2/candidate/plate.step
samples/nameplate-v2/NP3-LETTER-TEST-B-V2.3mf
source/native/NP3-TEXT-B.step
kit/B/parts/BASE3-06x10-T-6e100f.stl
kit/B/parts/BASE3-03x10-T-aa77a9.stl
kit/B/parts/BASE3-03x10-T-d79875.stl
kit/B/parts/BASE3-06x10-T-e1945a.stl
kit/B/parts/BASE3-24x10-B-562406.stl
kit/B/parts/BR-01x04-H096.stl
kit/B/parts/BR-02x04-H064.stl
kit/B/parts/BR-02x04-H096.stl
kit/B/parts/BR-02x05-H096.stl
kit/B/parts/BR-03x04-H096.stl
kit/B/parts/BR-04x04-H064.stl
kit/B/parts/BR-04x04-H096.stl
kit/B/parts/BR-04x05-H096.stl
kit/B/parts/BR-05x04-H096.stl
kit/B/parts/NP3-KEEPER.stl
kit/B/parts/NP3-LOGO-B.stl
kit/B/plates/B-black-01.3mf
kit/B/plates/B-black-02.3mf
kit/B/plates/B-black-03.3mf
kit/B/plates/B-black-04.3mf
kit/B/plates/B-black-06.3mf
kit/B/plates/B-black-07.3mf
kit/B/plates/B-black-to-white-z2p8-01.3mf
kit/B/plates/B-cyan-01.3mf
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

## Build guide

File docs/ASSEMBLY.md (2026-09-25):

# Bを組み立てる・銘板を交換する・分解する

**実制作の進捗：** 2026-09-25に、[ゴーグル・頭頂までの完成写真と本人の完成報告](BUILD-LOG.md#progress-2026-09-25)が届きました。
前の台座・顔下部の途中記録も日付別に残しています。以下は引き続き設計に基づく組立案内で、
写真を正確な工程番号や部品検品結果の代わりにはしていません。
写真で見える紫・黄色と、設計のマゼンタ・緑は区別し、配置・設計色は変更していません。

**現在の銘板は承認済みの可読性改訂版です。** 上12 mm・下10 mm、白い浮彫1.2 mm、
全厚3.6 mmになりました。黒い取付け基材は同じため、以下の差込・keeper操作は変更ありません。
必要な再印刷は文字銘板だけで、[文字試験片](NAMEPLATE-V2.md)は完成150個に数えません。
白い文字の最前面が0.4 mm前へ出るため、完成奥行は80.2 mmです。台座本体は79.8 mmのままです。

[入口](../README.md) · [3Dガイド](../guide/index.html) · [印刷](PRINTING.md) · [少量試作](TRIAL.md) · [28工程の図](STEPS.md)

印刷と冷却を終え、段階試作で指による着脱を確認してから始めます。
接着剤は使いません。強く押す、こじる、打撃を加える、熱で無理に合わせることはしません。
大きい完成形の保持・強度・転倒は未試験です。

**まずZIPを展開し、`guide/index.html`をダブルクリックします。**
空の机から1個ずつ増える組立を、前／次、再生／停止、工程再生で確かめられます。
印刷済みのファイルを選び、部品のslotから組立位置を探すこともできます。
ネット接続やサーバー準備は不要です。[詳しい使い方](GUIDE.md)。

## 図と部品の見方

[B専用PDF](../kit/B/drawings.pdf)と[BOM](../kit/B/bom.csv)を手元に置きます。
PDFは54ページで、全体、分解参考、共通接続、BOM、28工程、21形状の寸法図を収録しています。
紙に出す場合は必要ページだけA4横などで読める大きさへ縮小して構いません。
図は型紙ではなく、寸法数字を参照するものです。**STL自体は100%から変えません。**

**工程平面図は、図の下が手前（銘板側）**です。鏡像にしません。
`B-001` などは**その場所に付ける1個の配置番号**、
`BR-02x04-H096` などは**同じ形状を共有する部品ID**です。
同じ形でも色・個数は[BOM](../kit/B/bom.csv)を確認し、ID別のトレーへ分けます。
3Dガイドの**slot番号は3MF内の部品順の目印**で、刻印ではありません。
同じ部品ID・色なら可換です。案内用の1対1割当を、どの実物がどこへ入るかの断定にしません。
色の見えにくい印刷図では、[工程CSV](../kit/B/steps.csv)と
[配置JSON](../kit/B/assembly.json)を併用してください。

個人Bの完成配置。実STL由来の保存済み画像であり、実物写真ではない

## 1. 黒い台座を5段積む

| 工程 | 今回追加する配置番号 | 個数 | 案内上の出処（`B-*.3mf`） | 見る図 |
|---:|---|---:|---|---|
| 1 | `B-001` | 1 | **black-02 slot 3** | [台座1段目](../kit/B/drawings/step-01.svg) |
| 2 | `B-002`〜`B-005` | 4 | black-01、02、03 | [台座2段目](../kit/B/drawings/step-02.svg) |
| 3 | `B-006`〜`B-010` | 5 | black-01、03 | [台座3段目](../kit/B/drawings/step-03.svg) |
| 4 | `B-011`〜`B-014` | 4 | black-01、02、03 | [台座4段目](../kit/B/drawings/step-04.svg) |
| 5 | `B-015`〜`B-019` | 5 | black-01、**04** | [台座5段目](../kit/B/drawings/step-05.svg) |

**印刷順は組立順ではありません。** 1段目は
`B-black-02.3mf` のslot 3、`BASE3-24x10-B-562406`、
**191.8 × 79.8 mmの黒い台座部品1個だけ**です。
小さい部品を横に並べて1段目の代わりにしません。
平らな机に置き、手前のキー溝を確認します。

実3MFから台座1段目のB-001を探す

2段目は次の4個です。3MFごとではなく、**同じ工程に必要な部品を集めてから**載せます。

| 配置番号 | 部品ID | 案内上の出処 |
|---|---|---|
| `B-002` | `BASE3-06x10-T-e1945a` | `B-black-02.3mf` slot 1 |
| `B-003` | `BASE3-06x10-T-838259` | `B-black-03.3mf` slot 3 |
| `B-004` | `BASE3-06x10-T-3f87ac` | `B-black-03.3mf` slot 1 |
| `B-005` | `BASE3-06x10-T-6e100f` | `B-black-01.3mf` slot 7 |

2〜5段目は図の番号順に、継ぎ目が互い違いになる位置へ載せます。
下段を机で支え、軽い指の力で平行に押し、段間と四隅の浮きを見ます。
`black-01`の8個は2〜5段目で使います。同じ左端形状
`BASE3-03x10-T-aa77a9`の2個は`B-006`／`B-015`用で、左右ペアではありません。
外寸が同じでも溝形状の異なるID同士は代用しません。

空から5段台座、前面2部品、keeper3個を組む実形状アニメーション

台座本体は5×9.6＝**48 mm高、計19個**です。
前面5段のキー溝が一直線に通ることを確認してください。
最前列の補強帯には接続用の通常受け・スタッドを設けていない部分があります。
穴がないことを不良と決めつけて削ったり、市販ブロックを無理に接続したりしません。

## 2. 個人銘板と右ロゴを上から入れる

[工程6の図](../kit/B/drawings/step-06.svg)を見ながら、
左へ **`B-020 / NP3-TEXT-B`**、右へ **`B-021 / NP3-LOGO-B`** を
それぞれ独立した溝へ**上からまっすぐ**差し込みます。
完成配置ではどちらも台座内のZ=4〜44 mmに収まります。
印刷ファイルはそれぞれ `B-black-to-white-z2p4-01.3mf`／
`B-black-to-white-z2p8-01.3mf` のslot 1です。
印刷時は裏面を下、組立時は**X軸まわりに90度回して文字・図柄を手前**にします。
3Dガイドも実配置の90度回転を使い、黒い支持体と白いレリーフを分けて表示します。
銘板は個人版1枚への置換済みで、追加の151個目ではありません。

台座正面。左に個人銘板、右に独立ロゴ

正しい2行：

```text
Same icon, New adventures
github.com/tomokota
```

反り・溝のずれ・途中の引っ掛かりで座らないときは止めます。
前から押し込む方式ではありません。文字やロゴを押して力をかけないでください。

## 3. 上止めのkeeperを3個載せる

[工程7の図](../kit/B/drawings/step-07.svg)で向きを確認し、
台座上の**2列目のスタッド**へ取り付けます。
案内上の出処は `B-black-07.3mf` のslot 8／9／10です。

| 配置番号 | 用途 |
|---|---|
| `B-022`、`B-023` | 銘板の上止め、2個 |
| `B-024` | 右ロゴの上止め、1個 |

keeperの下面受けは後ろ側の1列、前側は中実の上止めです。
前後を反転させないでください。`NP3-KEEPER` は接着せず取り外せる黒い独立部品です。
ここで大きい銘板の保持・溝の整列・交換経路を確認してから、顔へ進みます。
短い試験片や台座端部2個の試作だけでは、この確認を代用できません。

## 4. 顔を下から1段ずつ

[工程8〜26](STEPS.md)は本体19段です。各図の**新しく追加する番号**だけを取り、
色と形を照合して上から載せます。マゼンタ外周、黒い顔、緑の縦線、
シアンのゴーグルの位置を変えません。

最後に[工程27](../kit/B/drawings/step-27.svg)で
`B-148`〜`B-150` の頭頂マゼンタ3個を取り付けます。
顔・頭頂は合計126個です。台座19個＋前面2個＋keeper3個と合わせて**150個**になります。

細い1列部品も、種類ごとにまず1個のつかみやすさ・着脱を確認してください。
大きい2×2／2×4が扱えたから全小部品も大丈夫とは判断しません。
足りない・余る・色が違う場合は、無理に別部品で埋めずBOMと配置番号へ戻ります。

## 5. 飾る前に確認する

[工程28](../kit/B/drawings/step-28.svg)は新しい部品を追加しない確認工程です。
2行と右ロゴの位置、keeperの保持、段間の浮き、台座のがたつき、
前後左右への倒れやすさを、平らで低い机の奥側でそっと確認します。
完成品を反転したり、振ったり、押し倒したりする試験ではありません。

自然に外れる、ぐらつく、ひびが出る場合は飾らず、該当部品と実スライス条件を見直します。
棚の縁、直射日光、暖房器具の近く、車内には置きません。
持ち運びは**台座を両手で支えます**。頭、ゴーグル、銘板、ロゴ、keeperを持ち手にしません。

## 銘板だけ・ロゴだけを交換する

前面機構の実CAD断面。共通形状の参考図で、実物の保持保証ではない

1. 模型を机に置き、台座を支えます。交換する部品に対応したkeeperだけを外します。
   銘板は2個、ロゴは1個です。
2. keeperを**上へ約6 mm**外し、**手前へ32 mm以上**離してから脇へ置きます。
3. 対象の銘板／ロゴを傾けずに**まっすぐ45 mm以上上へ**持ち上げて溝を抜き、
   その後で手前へ取り出します。
4. 同じ取付け仕様の部品を上から入れ、対応するkeeperを戻します。
   キットの銘板は最初から個人版です。初回組立で別の汎用銘板へ交換する必要はありません。

これは既存CADに基づく解除経路です。実物の軽い力での動作は別途確認が必要です。
指で安全につかめない・強い力が必要・ぶつかるときは止め、横へこじりません。
後ろの顔を持ち上げる取っ手として前面部品を使わないでください。

## 全部分解する

まず上記の方法で前面モジュールを外します。
次に顔を頭頂から工程の逆順に1段ずつ、最後に台座を5段目から外します。
下段を支え、外した部品を色・IDごとに戻します。
白化・ひび・欠けのある部品は再使用せず、原因を確認します。

[分解参考図](../kit/B/drawings/exploded.svg)は見やすく位置を離した表示です。
物理シミュレーション、許容荷重、実物の分解保証ではありません。

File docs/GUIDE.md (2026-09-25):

# 印刷した部品を探す・3Dで組み方を見る

[実写真の制作記録](BUILD-LOG.md)／[オフライン閲覧版](BUILD-LOG.html)も追加しました。
台座・前面、顔下部に続く[9/25のゴーグル・頭頂と完成の写真](BUILD-LOG.md#progress-2026-09-25)も含め、
本人の「これで完成ですね」という報告と実物写真を、CGの工程表示とは別に記録しています。
3D画面上部からも開けます。写真を読む場合はZIP全体を展開してください。

2026-09-22承認の新しい銘板を3D・画像・アニメにも反映しています。
前の版から変更したのは文字銘板だけです。[文字試験片と変更点](NAMEPLATE-V2.md)を先に確認し、
台座・顔・右ロゴをこの更新のために刷り直す必要はありません。

[入口](../README.md) · [3Dガイドを開く](../guide/index.html) · [全ファイル対応](FILES.md) · [全工程](STEPS.md)

## ZIPを展開してダブルクリック

保存したZIPを展開し、**`guide/index.html`をブラウザで開きます**。
HTML内に表示用ランタイム、実STL由来のメッシュ、全14枚／150配置のデータを同梱しています。
見るだけならインターネット、Python、Node、FreeCAD、サーバーは不要です。
GitHubのファイル画面やZIPの中から直接開かず、展開済みファイルを使ってください。
フォルダをコピーして別PCへ移しても、個人データを外へ送らず閲覧できます。

WebGLが使える最近のChrome／Edge／Firefox／Safariなどのブラウザが必要です。
3D表示に失敗したら画面のエラーを確認し、WebGL対応ブラウザで開き直します。
安全警告や組織の端末制限を解除する必要はありません。
表示できない端末では、同梱の[工程図](STEPS.md)と[PDF](../kit/B/drawings.pdf)を使います。

## 1. 最初の大きい1枚を探す

**印刷順と組立順は別です。色表やファイル名の01から積み始めません。**

1. 印刷ファイルで **`B-black-02.3mf`** を選びます。
2. プレート上の一番大きい **slot 3** を選びます。一覧からも選択できます。
3. `BASE3-24x10-B-562406`、**191.8 × 79.8 mm**、1個、
   **`B-001`／工程1**という対応を確認します。
4. 組立を空の状態から進め、この広い1枚を机へ置く様子を見ます。
   2段目以降は小さい部品を順に載せます。

black-02 slot 3の実プレート配置と、B-001工程1

`B-black-01.3mf`を先に印刷済みなら、その8個は2〜5段目へ取っておきます。
同じ左端形状2個は3段目・5段目用で、左右ペアではありません。
この理由だけで廃棄・再印刷はしません。

## 2. slot・部品ID・配置番号の違い

| 表示 | 意味 |
|---|---|
| `B-black-02.3mf` | どの印刷ファイルから取るか。ガイドはその実3MFの配置を読み取っています |
| slot 3 | その3MF内の3番目。**案内用の番号で刻印なし**。スライサーの独自番号と同じとは限りません |
| `BASE3-24x10-B-562406` | 形状の部品ID。寸法だけでなく、末尾まで一致することを確認します |
| `B-001` | 完成Bのどこに置く1個かを示す配置番号 |
| 工程1 | 組立に追加する段階。印刷順ではありません |

同じ**部品IDと色**のものは同形・可換です。ガイドには全適用候補と、
150個を過不足なく数えるための便宜上の割当があります。
印刷した特定の実物が特定の配置専用品だとは断定していません。
他のslotや試作から同形・同色の良品を使った場合は、必要数から差し引いてください。
色が違うもの、外寸が同じでも末尾の異なるものは、同じ部品ではありません。

台座の6×10部品は似ていますが、銘板／ロゴの溝形状が異なります。
プレートと組立を回転・拡大し、**正面の溝と下面、端の形**を見比べます。
3Dで見えた穴の有無だけを理由に実物を削らず、部品IDと[寸法図](FILES.md)を照合してください。

## 3. 空の机から全28工程へ

前／次、再生／停止、工程の選択、工程再生、やり直しで進めます。
工程を移動したら再生は停止し、選んだ工程の状態へ切り替わります。
既に置いた部品は残り、その工程の部品だけが順に加わります。
回転・ズーム、前／右／上の視点で接続を確認できます。
完成位置の強調表示と途中の組立表示を使い分けてください。
オレンジの枠や淡い着地点は案内用の表示で、フィラメント色や追加の部品ではありません。
「今の1個の動き」を100%にすると、その1個は図内で配置完了になり、表示個数に含まれます。
「次の1個」で確認して先へ進めます。スライダーの区切りや図内の完了表示は、
実物の作業・保持試験が済んだことを記録するものではありません。
ボタンや一覧はTabで選び、Enter／Spaceで操作できます。3Dのマウス選択だけに頼りません。

| 工程 | 内容・追加数 | 案内上の出処 |
|---|---|---|
| 1 | 幅191.8 mmの1段目、1個 | black-02 slot 3 |
| 2〜5 | 継ぎ目をずらして台座を5段へ、計18個 | black-01〜04。2段目にも01・02・03すべてが必要 |
| 6 | 左の個人銘板と右の独立ロゴ、2個 | black-to-white-z2p4／z2p8の各slot 1 |
| 7 | 2列目へkeeper、3個 | black-07 slot 8〜10 |
| 8〜26 | 顔19段、計123個 | その工程に表示される部品・色・3MFを確認 |
| 27 | 頭頂マゼンタ、3個 | マゼンタの該当slot |
| 28 | 保持・浮き・転倒の確認、追加0個 | 累計150個 |

最初の24個を実形状で組む3Dガイドの短いアニメーション

この動画は空から台座5段・前面2部品・keeper3個が追加される様子です。
全体を回すだけの動画ではありません。全150個は操作できる[3Dガイド](../guide/index.html)で確認します。
プレートの配置やassemblyの位置・回転は実データを使いますが、
持ち上げて見せる移動や分解・透過表示は説明用です。
**衝突回避、挿入力、保持、分解経路の物理保証ではありません。**

## 4. 前面の向き・色・数量を間違えない

銘板とロゴは印刷では裏面を下にして平置きします。
組立では実データどおりX軸まわりに90度回し、文字／ロゴを手前に向け、
台座前面の独立した溝へ上から入れます。前から押し込む方式ではありません。

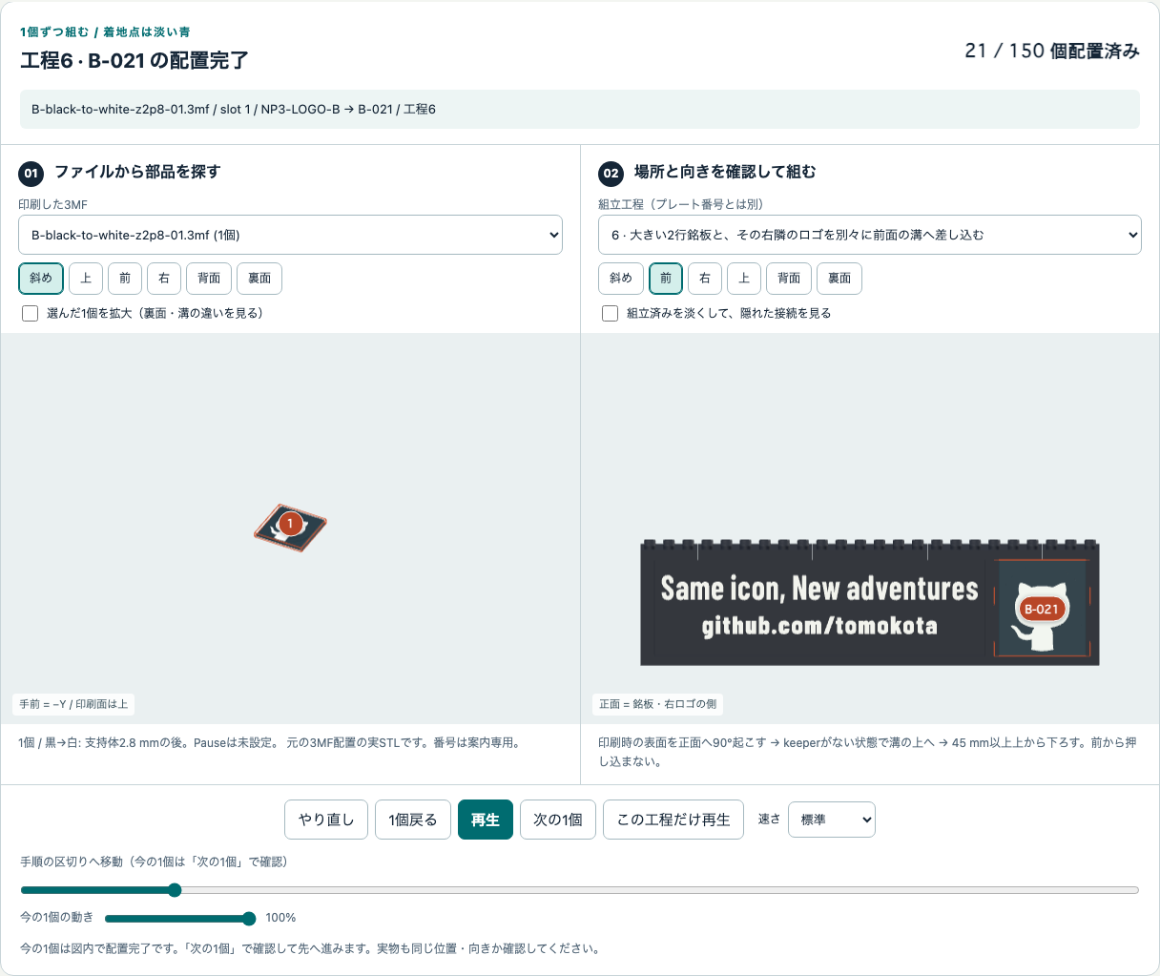
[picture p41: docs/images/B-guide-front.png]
実ビューアで銘板と独立ロゴを正面へ起こして着座させた状態。keeperを載せる前


銘板は `B-black-to-white-z2p4-01.3mf` slot 1 → `NP3-TEXT-B` → `B-020`、
右ロゴは `B-black-to-white-z2p8-01.3mf` slot 1 → `NP3-LOGO-B` → `B-021`。
どちらも工程6です。続く工程7のkeeper3個はblack-07 slot 8〜10 → `B-022`〜`B-024`です。

個人銘板は`NP3-TEXT-B`の1枚、**142 × 40 × 3.6 mm**、
黒の支持体2.4 mm＋白レリーフ1.2 mmです。実際の行の文字高さは12／10 mmです。
ロゴは黒の支持体2.8 mmの後に白となります。
ガイドの配色は形状の高さ境界を示すもので、Pauseや実レイヤー番号を設定しません。
正確な文字は次の2行だけです。

```text
Same icon, New adventures
github.com/tomokota
```

個人銘板は汎用版への**置換1枚**であり、追加ではありません。
完成品は**150個、191.8 × 80.2 × 238.6 mm、黒台座5段48 mm**です。
個数・台座寸法・配置はそのまま、増した白文字だけが0.4 mm前に出ます。
fit試験片と7個の試作セットは別区分です。試作の2×2ブロック2個は完成BOMに含まれません。
他の試作良品は部品ID・色・必要数を確認して流用し、重複印刷を避けます。

## デジタルの案内と実物の安全を分ける

配布データは**NOT_SLICED**です。制作過程と完成写真・本人の完成報告はありますが、
使用版・設定の照合、嵌合、保持、強度、転倒、途中色替え手順の正式な評価結果は未提供です。
今回の旧銘板の実ノズルは0.2 mmとの申告があります。新版の印刷条件は未照合で、
実ノズルとStudio設定、PLA、plate、profileは本人が確認します。
このガイドはプリンタ接続、Send／Print、設定変更を行いません。
穴・溝の閉塞、指でつかめない、座らない、強い力が必要、割れ、保持不足があれば停止し、
[少量試作](TRIAL.md)と[印刷時の点検](PRINTING.md)へ戻ります。

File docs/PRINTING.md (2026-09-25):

# 別のPCで印刷する

**銘板の2026-09-22更新：再印刷対象は文字銘板1枚だけです。**
現行`NP3-TEXT-B`は上12 mm／下10 mm、白1.2 mm、全厚3.6 mm。
台座・顔・右ロゴ・keeperは変更していません。既存部品を一律に刷り直さず、
まず[新しい文字試験片](NAMEPLATE-V2.md)で孔・字間・上面を確認してください。

[入口へ戻る](../README.md) · [3Dガイド](../guide/index.html) · [少量試作](TRIAL.md) · [組立・分解](ASSEMBLY.md)

このキットは **B DESK CLASSIC・個人銘板入りの1種類だけ**です。すべて
**NOT_SLICED（未スライス）**。配布3MFは形状と配置だけで、P1S設定入りの
Bambu Studioプロジェクト、Pause設定、G-codeではありません。
ユーザーによる文字試作・組立過程に加え、[9/25の完成写真と「これで完成ですね」という報告](BUILD-LOG.md#progress-2026-09-25)があります。
使用ファイル／実スライス版の照合、保持・寸法・荷重・転倒等の評価結果は未提供です。
写真があることと、配布3MFに実機設定やPauseが含まれることは別です。
実写真の紫・黄色に合わせて設計色を変更したものではありません。この記録追加による再印刷は不要です。

**色別表は印刷用の仕分けであり、組立順ではありません。**
`B-black-01.3mf`から印刷しても構いませんが、その8個だけで1段目を作ることはできません。
最初の1段目は **`B-black-02.3mf` のslot 3、`BASE3-24x10-B-562406`、
191.8 × 79.8 mmの1枚 → `B-001`／工程1** です。
刷り上がった部品は捨てたり一律に再印刷したりせず、
[3Dガイドの仕分け手順](GUIDE.md)で部品IDと色を確認して保管します。

## 1. 別PCで見る・保存する

1. 別PCで[本人向けの公開案内](https://ktanino10.github.io/copilot-brick-gift-b/)を開くと、
   説明・作り方・3D工程・制作記録をそのまま読めます。閲覧にログインは不要です。
   印刷データを保存するときは、[公開リポジトリ](https://github.com/ktanino10/copilot-brick-gift-b)へ進みます。
2. **Code → Download ZIP** で全体を保存します。印刷用だけなら
   [B-personal-print-kit.zip](https://github.com/ktanino10/copilot-brick-gift-b/blob/main/downloads/B-personal-print-kit.zip)のファイル画面で
   **Download raw file** を選びます。どちらか一方で十分です。
3. エクスプローラー／FinderでZIPを**展開**します。ZIPを直接スライサーへ渡しません。
   展開後の `README.md` と `docs/` が、この説明のオフライン版です。
   **`guide/index.html`をダブルクリック**すると、実3MFの配置と組立の3Dガイドが開きます。
   閲覧にPython／Node／サーバー／ネット接続は不要です。
4. GitHubの閲覧HTMLを「ページとして保存」して `.stl` に改名しないでください。
   実ファイルの拡張子が `.zip`／`.3mf`／`.stl` かを確認します。
   閲覧ページのHTMLが保存された場合は、**Download raw file**から取り直します。

2026-09-23の承認により、個人版の案内をGitHub Pagesでも公開しています。
保存したZIP内の相対リンクも引き続き使えます。
ダウンロード時の一時的な署名付きURLを共有・ブックマークする必要はありません。

## 2. 用意するものと実機の確認

| 用意するもの | 確認すること |
|---|---|
| Bambu Lab P1S、Bambu Studio | **今、実際に装着されているノズル径**とプリンタプリセットが一致すること |
| PLA 5色 | ブラック、シアン、マゼンタ、グリーン、ホワイト。実際の銘柄・色に対応する設定を選ぶ |
| 使用するビルドプレート | 種類とメーカーの取扱手順。清掃・取り外しはその手順に従う |
| 平らな机、柔らかい布、色・ID別トレー | 小部品の落下・混同を防ぐ |
| ノギス | 外形・スタッド・反りの観察用。測定のばらつきも記録する |

接着剤、別ピン、ハンマーは不要です。AMSの有無は未確認ですが、以下は**AMSなしの
色別印刷＋前面2部品の手動色替え**で進める手順です。

本体に0.4 mm、文字・ロゴに0.2 mmノズルを推奨しますが、
**未実機検証の出発点**です。今回の旧銘板は0.2 mmノズルで印刷したとの申告があります。
新版の成功や次回の設定一致を意味しないので、印刷時の実装状態を改めて照合します。
交換する場合はP1Sのメーカー手順に従い、冷却・安全確保後に
行い、Studio側の設定も合わせ直します。

温度・流量・冷却・層高・線幅は、実際のPLA、プレート、ノズルに合う公式プリセットを
起点にします。ここでは成功済みのプロファイルや固定の補正値を指定していません。

## 3. 最初は2個だけ

最初に [FIT-M-D470.stl](../kit/fit/FIT-M-D470.stl) と
[FIT-F-CP12.stl](../kit/fit/FIT-F-CP12.stl) を**各1個**使います。
全数の本体プレートはまだ印刷しません。

1. 新しい空のプロジェクトで実P1S・実ノズル・PLA・プレートを選択します。
   一致するプリセットがなければ、別機種や別径で代用せず止めます。
2. 2つのSTLを読み込み、**mm・倍率100%・各1個**を確認します。
   提供された向きを保ち、下面がZ=0でベッドに接することを確認します。
3. スライス後、下記のレイヤー点検を行います。警告が理解できなければ印刷しません。
4. 設定を配布物とは別名の、ローカルのBambu Studioプロジェクトに保存します。
   記録には[空の記録表](../kit/fit-log.csv)をコピーして使えます。
5. 本人がプレビューと実機条件を確認してから、メーカーの通常操作で印刷します。
   このキットからプリンタへ自動接続・Send・Printはしません。
6. 十分冷まして取り出し、[少量試作の合否](TRIAL.md)を確認します。
   次は必要なキー溝試験片、実ブロック4個、keeperと台座端部の3個の順です。

STLは単位情報を持ちません。大きさを合わせるための拡大・縮小はしないでください。
8 mmピッチと嵌合寸法が変わります。

## 4. スライス後に見る場所

| プレビュー位置 | 印刷前に確認すること |
|---|---|
| 初層・穴入口 | 受けや溝を塞ぐ線、意図しない内側ブリムがない |
| 下面空洞の途中 | 内部へ不要なサポートや隣部品のブリムが入っていない |
| 屋根の最初の層 | ブリッジが必要なリブへ着地する。空洞を埋める経路になっていない |
| スタッド・薄壁・キー溝 | 必要な輪郭が連続し、細い経路が欠落していない |
| 文字・ロゴ | レリーフの最初から最後まで読める経路が残る |
| プレート全体 | 校正線、除外領域、外側ブリム、部品同士が干渉しない |

通常ブロックの屋根下面はおよそZ=8 mm、keeper後列受けの屋根下面はおよそ
Z=2.2 mmです。リブ・屋根は必要な材料です。台座最前列の中実の補強帯を、
本来あるはずの穴が塞がったものと取り違えて削らないでください。

**サポートを穴に自動で詰めないこと**が重要です。「後で全部取れる」と推測しません。
穴側を上へ反転して解決したことにもせず、提供姿勢で点検します。
時間・重量は本人の実スライスに表示された値だけを記録します。

## 5. B本体を色別に印刷する

[プレート一覧・数量](FILES.md)と[完成品BOM](../kit/B/bom.csv)を使います。
本体4色は単色で、白だけの独立部品はありません。
**以下の表の上から順に刷ることと、台座1段目から組むことは別です。**
色でまとめるのは材料交換を減らすためです。黒を刷った順に下から積める、という意味ではありません。

| 色／用途 | `kit/B/plates/` 内のファイル | 候補プレート数 | ノズル案 |
|---|---|---:|---|
| 黒・本体 | `B-black-01.3mf`〜`B-black-07.3mf` | 7 | 0.4 mm |
| シアン | `B-cyan-01.3mf`〜`B-cyan-02.3mf` | 2 | 0.4 mm |
| マゼンタ | `B-magenta-01.3mf`〜`B-magenta-02.3mf` | 2 | 0.4 mm |
| 緑 | `B-green-01.3mf` | 1 | 0.4 mm |
| 個人銘板・黒→白 | `B-black-to-white-z2p4-01.3mf` | 1 | 0.2 mm |
| 右ロゴ・黒→白 | `B-black-to-white-z2p8-01.3mf` | 1 | 0.2 mm |

各3MFは**1回分の候補配置**です。1つずつ新しい空のプレート／プロジェクトに
開き、前の配置へ追加しません。単色プレートでも収録部品・個数はそれぞれ異なります。
プレート数14は部品数150とは違います。

### black-01を既に刷った場合

その8個は**2〜5段目用**です。`BASE3-03x10-T-aa77a9`の2個は
**同じ左端形状を3段目と5段目で使うもの**で、左右ペアではありません。
右端は別IDです。同じ外寸の6×10でもキー溝の形が違うため、
ID末尾まで確認し、3Dの正面・裏面を回して見比べます。
slot番号はガイドの目印で、実物に番号が刻まれているわけではありません。

black-02の大きいslot 3と、組立B-001の対応

1段目の幅191.8 mmの1枚を準備したら、2段目には
**black-01・02・03のそれぞれ**から4個を集めます。
5段目の同形中央部品2個は案内上black-04へ割り当てているため、
5段台座の19個すべてがblack-01〜03だけでそろうわけではありません。
[工程ごとの出処](STEPS.md)と[全slot対応](FILES.md)を使ってください。
同一ID・同一色の良品なら、別slotや試作から引き当てても構いません。
必要な台座形状がそろうまでは、ファイル名・部品ID・色ごとのトレーへ入れて待ちます。
顔の組立開始にはマゼンタなど別色も必要です。黒だけ先にすべて積み上げません。

形状だけの3MFとして読み込み、実機設定を再確認します。Studioが設定を問い合わせた
場合も、この3MFを検証済みP1Sプロファイルとは扱いません。単色部品にはその色のPLAを
割り当てます。印刷順序は**層ごと**を使い、ヘッド干渉未確認のまま
「オブジェクトごと」の順次印刷へ変えません。

**3MF方式とSTL方式は代替です。同じ部品の両形式を同時に読み込まないでください。**
STLで少量ずつ手配置する場合だけ、BOMの色別数量を使います。
試作と実5段台座を確認する間はSTL方式で必要な分だけ選べます。
完成品に使う良品を試作から流用する場合は、BOMで既印刷数を差し引き、
全プレートをそのまま追加印刷して二重に数えないでください。

完全に冷えた部品を外し、外側ブリム・糸引きだけを取り除いて仕分けます。
嵌合面を削る、強く押す、こじる作業を前提にしません。

## 6. 銘板とロゴだけ黒→白に替える

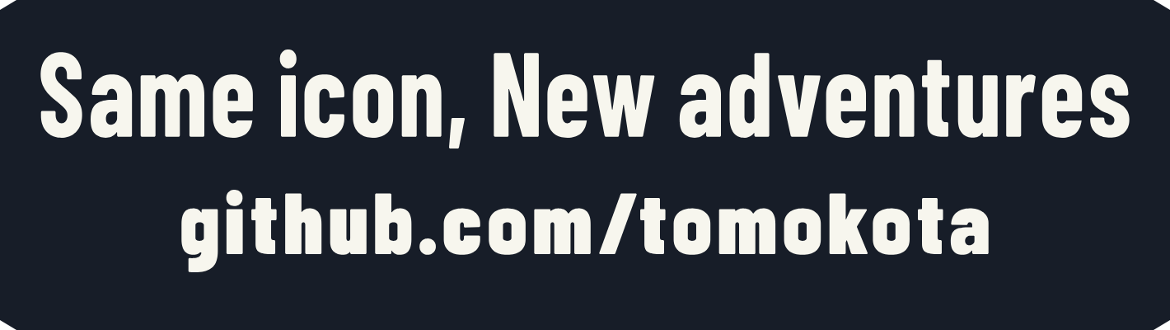
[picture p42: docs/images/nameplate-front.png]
新版の個人銘板の実CAD正面投影


上は新版個人銘板の実CAD投影です。実形状の2行と孔を確認する図で、
実スライスの経路や実物写真ではありません。
[個人銘板の寸法図](../kit/B/drawings/parts/NP3-TEXT-B.svg)にも印刷姿勢を示しています。

この2部品は**黒い支持体と白いレリーフがつながった一体形状**です。
白い文字や白いロゴを別体で接着・組立する方式ではありません。
どちらも、平らな裏面をベッド、文字／図柄を上にして印刷します。

銘板の印刷姿勢と色替え高さの模式図。裏面下、黒支持体2.4 mm、白レリーフ1.2 mm

模式図は向きと高さの説明用で、実スライスの経路や層番号を示すものではありません。

| 部品 | 黒い部分の終了高さ | 白いレリーフ | 合計厚さ |
|---|---:|---:|---:|
| 個人銘板 `NP3-TEXT-B` | Z=2.4 mm | 1.2 mm | 3.6 mm |
| 右ロゴ `NP3-LOGO-B` | Z=2.8 mm | 0.8 mm | 3.6 mm |

大きくしたのは2行目の実際の文字外接高さと、板から出る白いレリーフの高さです。
文字を横太りさせて孔を埋めたものではありません。黒の厚みは変わらず、
**銘板のPause境界は2.4 mmのまま**です。白を厚くしても糸引きや押出過不足が
自動で直るとは限りません。写真だけから温度・流量・乾燥条件の補正値を決めていません。

1. 専用3MFを**1つだけ**開き、100%、部品Z=0、裏面下を確認します。
   別の黒部品を同じプレートへ追加しません。黒PLAで始めます。
2. 実ノズル・PLA・プレートでスライスし、文字またはロゴが初めて現れる経路を探します。
3. **黒い支持体の最終層が終わった後、白いレリーフの最初の経路が始まる前**に
   Pauseが入るようにします。通常はPreviewのレイヤースライダーで該当箇所を右クリックし、
   「一時停止を追加／Add pause」を使います。バージョンにより表示は異なります。
4. Pauseが実際に入ったことと停止タイミングを、レイヤープレビューで本人が確認します。
   **固定層番号は使いません。** 初層高・可変層高により番号が変わり、
   `2.4 ÷ 層高`だけでは決まりません。位置を判断できなければ開始しません。
5. 実機がPauseしたら、P1Sの標準フィラメント交換手順に従って黒→白へ交換します。
   白が出るまで残った黒の排出を確認し、プレート・造形物を動かさずに再開します。
   高温部へ触れず、自動動作前に手を退避します。
6. 冷却後、2行の欠け・文字の欠落・黒の混色・裏面の反りを確認します。

P1Sの画面はボタン操作です。別機種のタッチスクリーン手順や、
未検証の `M600` 等のカスタムG-codeは使いません。
Pause中に必要なunload／load操作ができない、表示が手順と違う、再開方法が分からない
場合は、手動で無理に引き抜いたり動作を迂回せず、メーカーのP1S手順を確認します。
初回のPause・交換・再開は**本人による実機検証が必要**です。

メーカー参照：
[P1シリーズのフィラメント装填](https://wiki.bambulab.com/en/p1/manual/loading-filament) /
[フィラメント交換](https://wiki.bambulab.com/en/p1/manual/replacing-filament)。
これらの一般操作説明は、このキットの途中交換が実機で成功した証拠ではありません。

個人銘板の正確な文字は次の2行です。`@tomokota` の独立行はありません。

```text
Same icon, New adventures
github.com/tomokota
```

このキットの `NP3-TEXT-B` は**既に個人版へ置換済み**です。
汎用版を別途ダウンロードしたり、銘板を2個数えたりしません。完成品は150部品のままです。

## 7. 進めてはいけない状態

穴・溝の閉塞、指でつかめない、最後まで座らない、強い力が必要、割れ・白化、
保持不足のいずれかがあれば**全数印刷を停止**します。
小穴を1個ずつ削る、ハンマー・工具で押し込む、穴径・XY補正・流量・温度を
一律変更することは、このキットの使い方ではありません。

現物と、実際に使った設定入りプロジェクトの断面を照合し、仮説を分けて
1条件ずつ比較します。0.2 mmノズルへ替えるだけで直るとは限りません。
プロジェクトには機器情報やローカルパスが入ることがあるため、そのまま公開しないでください。

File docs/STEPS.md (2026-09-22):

# Bの28工程

[入口](../README.md) · [オフライン3D](../guide/index.html) · [3Dの使い方](GUIDE.md) · [組立・交換・分解](ASSEMBLY.md) · [全図PDF](../kit/B/drawings.pdf)

**現行の銘板は上12／下10 mm・白1.2 mmの改訂版。[文字試験片](NAMEPLATE-V2.md)は完成150個とは別です。**

**ZIPを展開して `guide/index.html` をダブルクリック。空の机から全28工程を3Dで進められます。**
Python／Node／ネット接続は閲覧に不要です。印刷順と組立順は別です。
**工程1は `B-black-02.3mf` のslot 3、`BASE3-24x10-B-562406` → `B-001`。**
black-01の8個は2〜5段目用です。台座5段の出処はblack-01〜04にまたがります。
slot番号は案内用で刻印なし。同一ID・色の実物は可換で、特定個体の割当ではありません。

図の下が手前（銘板側）です。追加する配置番号を、その工程の図で確認します。
最終工程は確認だけで、新しい部品はありません。図は実CAD由来で、実物の合格証拠ではありません。

[全150slotの対応CSV](../kit/B/part-map.csv) · [全14枚の部品・寸法表](FILES.md)

| 工程図 | 内容 | 追加数 | 配置番号 | 3MFの便宜出処 |
|---|---|---:|---|---|
| [01](../kit/B/drawings/step-01.svg) | 黒い台座 1 / 5段目を積む（縦の継ぎ目をずらす） | 1 | `B-001` | `B-black-02.3mf` |
| [02](../kit/B/drawings/step-02.svg) | 黒い台座 2 / 5段目を積む（縦の継ぎ目をずらす） | 4 | `B-002`〜`B-005` | `B-black-01.3mf`、`B-black-02.3mf`、`B-black-03.3mf` |
| [03](../kit/B/drawings/step-03.svg) | 黒い台座 3 / 5段目を積む（縦の継ぎ目をずらす） | 5 | `B-006`〜`B-010` | `B-black-01.3mf`、`B-black-03.3mf` |
| [04](../kit/B/drawings/step-04.svg) | 黒い台座 4 / 5段目を積む（縦の継ぎ目をずらす） | 4 | `B-011`〜`B-014` | `B-black-01.3mf`、`B-black-02.3mf`、`B-black-03.3mf` |
| [05](../kit/B/drawings/step-05.svg) | 黒い台座 5 / 5段目を積む（縦の継ぎ目をずらす） | 5 | `B-015`〜`B-019` | `B-black-01.3mf`、`B-black-04.3mf` |
| [06](../kit/B/drawings/step-06.svg) | 大きい2行銘板と、その右隣のロゴを別々に前面の溝へ差し込む | 2 | `B-020`〜`B-021` | `B-black-to-white-z2p4-01.3mf`、`B-black-to-white-z2p8-01.3mf` |
| [07](../kit/B/drawings/step-07.svg) | 銘板用2個・ロゴ用1個の黒いキーパーを2列目のスタッドに載せる | 3 | `B-022`〜`B-024` | `B-black-07.3mf` |
| [08](../kit/B/drawings/step-08.svg) | 本体 1 段目を左から載せる | 3 | `B-025`〜`B-027` | `B-magenta-01.3mf`、`B-magenta-02.3mf` |
| [09](../kit/B/drawings/step-09.svg) | 本体 2 段目を左から載せる | 5 | `B-028`〜`B-032` | `B-black-04.3mf`、`B-black-05.3mf`、`B-magenta-01.3mf` |
| [10](../kit/B/drawings/step-10.svg) | 本体 3 段目を左から載せる | 5 | `B-033`〜`B-037` | `B-black-04.3mf`、`B-black-05.3mf`、`B-magenta-01.3mf` |
| [11](../kit/B/drawings/step-11.svg) | 本体 4 段目を左から載せる | 6 | `B-038`〜`B-043` | `B-black-04.3mf`、`B-black-05.3mf`、`B-magenta-01.3mf` |
| [12](../kit/B/drawings/step-12.svg) | 本体 5 段目を左から載せる | 7 | `B-044`〜`B-050` | `B-black-05.3mf`、`B-black-06.3mf`、`B-green-01.3mf`、`B-magenta-01.3mf` |
| [13](../kit/B/drawings/step-13.svg) | 本体 6 段目を左から載せる | 10 | `B-051`〜`B-060` | `B-black-04.3mf`、`B-black-05.3mf`、`B-green-01.3mf`、`B-magenta-01.3mf` |
| [14](../kit/B/drawings/step-14.svg) | 本体 7 段目を左から載せる | 7 | `B-061`〜`B-067` | `B-black-06.3mf`、`B-black-07.3mf`、`B-green-01.3mf`、`B-magenta-01.3mf` |
| [15](../kit/B/drawings/step-15.svg) | 本体 8 段目を左から載せる | 10 | `B-068`〜`B-077` | `B-black-04.3mf`、`B-black-05.3mf`、`B-green-01.3mf`、`B-magenta-01.3mf` |
| [16](../kit/B/drawings/step-16.svg) | 本体 9 段目を左から載せる | 6 | `B-078`〜`B-083` | `B-black-06.3mf`、`B-magenta-01.3mf` |
| [17](../kit/B/drawings/step-17.svg) | 本体 10 段目を左から載せる | 6 | `B-084`〜`B-089` | `B-cyan-01.3mf`、`B-cyan-02.3mf` |
| [18](../kit/B/drawings/step-18.svg) | 本体 11 段目を左から載せる | 7 | `B-090`〜`B-096` | `B-black-05.3mf`、`B-black-06.3mf`、`B-cyan-01.3mf` |
| [19](../kit/B/drawings/step-19.svg) | 本体 12 段目を左から載せる | 7 | `B-097`〜`B-103` | `B-black-04.3mf`、`B-black-07.3mf`、`B-cyan-01.3mf` |
| [20](../kit/B/drawings/step-20.svg) | 本体 13 段目を左から載せる | 7 | `B-104`〜`B-110` | `B-black-05.3mf`、`B-black-06.3mf`、`B-cyan-01.3mf` |
| [21](../kit/B/drawings/step-21.svg) | 本体 14 段目を左から載せる | 7 | `B-111`〜`B-117` | `B-black-04.3mf`、`B-black-07.3mf`、`B-cyan-01.3mf` |
| [22](../kit/B/drawings/step-22.svg) | 本体 15 段目を左から載せる | 7 | `B-118`〜`B-124` | `B-black-05.3mf`、`B-black-06.3mf`、`B-cyan-01.3mf` |
| [23](../kit/B/drawings/step-23.svg) | 本体 16 段目を左から載せる | 7 | `B-125`〜`B-131` | `B-black-05.3mf`、`B-black-07.3mf`、`B-cyan-01.3mf` |
| [24](../kit/B/drawings/step-24.svg) | 本体 17 段目を左から載せる | 7 | `B-132`〜`B-138` | `B-black-05.3mf`、`B-black-06.3mf`、`B-cyan-01.3mf` |
| [25](../kit/B/drawings/step-25.svg) | 本体 18 段目を左から載せる | 5 | `B-139`〜`B-143` | `B-cyan-01.3mf`、`B-cyan-02.3mf` |
| [26](../kit/B/drawings/step-26.svg) | 本体 19 段目を左から載せる | 4 | `B-144`〜`B-147` | `B-cyan-02.3mf` |
| [27](../kit/B/drawings/step-27.svg) | 頭頂のマゼンタのプレートを載せる | 3 | `B-148`〜`B-150` | `B-magenta-01.3mf` |
| [28](../kit/B/drawings/step-28.svg) | 2行と右ロゴが5段台座の正面内に収まること、保持と転倒を確認する | 0 | 追加なし | 追加なし |

工程1〜5は台座、6は前面2部品、7はkeeper、8〜26は顔19段、27は頭頂、28は確認です。
試作の端部2個だけを積む操作を、正式な5段配置と取り違えないでください。

実形状による空の机から台座・前面・keeperへの短い組立アニメーション

最初の1枚はblack-02 slot 3。前面はblack-to-white-z2p4／z2p8の各slot 1、keeperはblack-07 slot 8〜10です。持ち上げ・透過・分解表示は説明用で、物理的な経路保証ではありません。

## 前面の取り付け図

前面2部品の取り付け位置

keeper3個の配置

## 1個ごとの取り出し表

以下は3MFの元の順番に対応させた便宜割当です。同一ID・同一色なら別slotの良品を使えます。
実物への刻印ではありません。試作から流用した分もここへ引き当て、再印刷を重複させません。

### 工程1：黒い台座 1 / 5段目を積む（縦の継ぎ目をずらす）

| 配置番号 | 部品ID | 3MF | slot | 印刷姿勢の外形 mm |
|---|---|---|---:|---|
| `B-001` | [BASE3-24x10-B-562406](../kit/B/parts/BASE3-24x10-B-562406.stl) | [B-black-02.3mf](../kit/B/plates/B-black-02.3mf) | 3 | 191.8 × 79.8 × 11.4 |

### 工程2：黒い台座 2 / 5段目を積む（縦の継ぎ目をずらす）

| 配置番号 | 部品ID | 3MF | slot | 印刷姿勢の外形 mm |
|---|---|---|---:|---|
| `B-002` | [BASE3-06x10-T-e1945a](../kit/B/parts/BASE3-06x10-T-e1945a.stl) | [B-black-02.3mf](../kit/B/plates/B-black-02.3mf) | 1 | 47.8 × 79.8 × 11.4 |
| `B-003` | [BASE3-06x10-T-838259](../kit/B/parts/BASE3-06x10-T-838259.stl) | [B-black-03.3mf](../kit/B/plates/B-black-03.3mf) | 3 | 47.8 × 76.4 × 11.4 |
| `B-004` | [BASE3-06x10-T-3f87ac](../kit/B/parts/BASE3-06x10-T-3f87ac.stl) | [B-black-03.3mf](../kit/B/plates/B-black-03.3mf) | 1 | 47.8 × 76.4 × 11.4 |
| `B-005` | [BASE3-06x10-T-6e100f](../kit/B/parts/BASE3-06x10-T-6e100f.stl) | [B-black-01.3mf](../kit/B/plates/B-black-01.3mf) | 7 | 47.8 × 79.8 × 11.4 |

### 工程3：黒い台座 3 / 5段目を積む（縦の継ぎ目をずらす）

| 配置番号 | 部品ID | 3MF | slot | 印刷姿勢の外形 mm |
|---|---|---|---:|---|
| `B-006` | [BASE3-03x10-T-aa77a9](../kit/B/parts/BASE3-03x10-T-aa77a9.stl) | [B-black-01.3mf](../kit/B/plates/B-black-01.3mf) | 1 | 23.8 × 79.8 × 11.4 |
| `B-007` | [BASE3-06x10-T-838259](../kit/B/parts/BASE3-06x10-T-838259.stl) | [B-black-03.3mf](../kit/B/plates/B-black-03.3mf) | 4 | 47.8 × 76.4 × 11.4 |
| `B-008` | [BASE3-06x10-T-838259](../kit/B/parts/BASE3-06x10-T-838259.stl) | [B-black-03.3mf](../kit/B/plates/B-black-03.3mf) | 5 | 47.8 × 76.4 × 11.4 |
| `B-009` | [BASE3-06x10-T-6159e6](../kit/B/parts/BASE3-06x10-T-6159e6.stl) | [B-black-01.3mf](../kit/B/plates/B-black-01.3mf) | 5 | 47.8 × 79.8 × 11.4 |
| `B-010` | [BASE3-03x10-T-d79875](../kit/B/parts/BASE3-03x10-T-d79875.stl) | [B-black-01.3mf](../kit/B/plates/B-black-01.3mf) | 3 | 23.8 × 79.8 × 11.4 |

### 工程4：黒い台座 4 / 5段目を積む（縦の継ぎ目をずらす）

| 配置番号 | 部品ID | 3MF | slot | 印刷姿勢の外形 mm |
|---|---|---|---:|---|
| `B-011` | [BASE3-06x10-T-e1945a](../kit/B/parts/BASE3-06x10-T-e1945a.stl) | [B-black-02.3mf](../kit/B/plates/B-black-02.3mf) | 2 | 47.8 × 79.8 × 11.4 |
| `B-012` | [BASE3-06x10-T-838259](../kit/B/parts/BASE3-06x10-T-838259.stl) | [B-black-03.3mf](../kit/B/plates/B-black-03.3mf) | 6 | 47.8 × 76.4 × 11.4 |
| `B-013` | [BASE3-06x10-T-3f87ac](../kit/B/parts/BASE3-06x10-T-3f87ac.stl) | [B-black-03.3mf](../kit/B/plates/B-black-03.3mf) | 2 | 47.8 × 76.4 × 11.4 |
| `B-014` | [BASE3-06x10-T-6e100f](../kit/B/parts/BASE3-06x10-T-6e100f.stl) | [B-black-01.3mf](../kit/B/plates/B-black-01.3mf) | 8 | 47.8 × 79.8 × 11.4 |

### 工程5：黒い台座 5 / 5段目を積む（縦の継ぎ目をずらす）

| 配置番号 | 部品ID | 3MF | slot | 印刷姿勢の外形 mm |
|---|---|---|---:|---|
| `B-015` | [BASE3-03x10-T-aa77a9](../kit/B/parts/BASE3-03x10-T-aa77a9.stl) | [B-black-01.3mf](../kit/B/plates/B-black-01.3mf) | 2 | 23.8 × 79.8 × 11.4 |
| `B-016` | [BASE3-06x10-T-838259](../kit/B/parts/BASE3-06x10-T-838259.stl) | [B-black-04.3mf](../kit/B/plates/B-black-04.3mf) | 1 | 47.8 × 76.4 × 11.4 |
| `B-017` | [BASE3-06x10-T-838259](../kit/B/parts/BASE3-06x10-T-838259.stl) | [B-black-04.3mf](../kit/B/plates/B-black-04.3mf) | 2 | 47.8 × 76.4 × 11.4 |
| `B-018` | [BASE3-06x10-T-6159e6](../kit/B/parts/BASE3-06x10-T-6159e6.stl) | [B-black-01.3mf](../kit/B/plates/B-black-01.3mf) | 6 | 47.8 × 79.8 × 11.4 |
| `B-019` | [BASE3-03x10-T-d79875](../kit/B/parts/BASE3-03x10-T-d79875.stl) | [B-black-01.3mf](../kit/B/plates/B-black-01.3mf) | 4 | 23.8 × 79.8 × 11.4 |

### 工程6：大きい2行銘板と、その右隣のロゴを別々に前面の溝へ差し込む

| 配置番号 | 部品ID | 3MF | slot | 印刷姿勢の外形 mm |
|---|---|---|---:|---|
| `B-020` | [NP3-TEXT-B](../kit/B/parts/NP3-TEXT-B.stl) | [B-black-to-white-z2p4-01.3mf](../kit/B/plates/B-black-to-white-z2p4-01.3mf) | 1 | 142 × 40 × 3.6 |
| `B-021` | [NP3-LOGO-B](../kit/B/parts/NP3-LOGO-B.stl) | [B-black-to-white-z2p8-01.3mf](../kit/B/plates/B-black-to-white-z2p8-01.3mf) | 1 | 40 × 40 × 3.6 |

### 工程7：銘板用2個・ロゴ用1個の黒いキーパーを2列目のスタッドに載せる

| 配置番号 | 部品ID | 3MF | slot | 印刷姿勢の外形 mm |
|---|---|---|---:|---|
| `B-022` | [NP3-KEEPER](../kit/B/parts/NP3-KEEPER.stl) | [B-black-07.3mf](../kit/B/plates/B-black-07.3mf) | 8 | 15.8 × 15.8 × 3.2 |
| `B-023` | [NP3-KEEPER](../kit/B/parts/NP3-KEEPER.stl) | [B-black-07.3mf](../kit/B/plates/B-black-07.3mf) | 9 | 15.8 × 15.8 × 3.2 |
| `B-024` | [NP3-KEEPER](../kit/B/parts/NP3-KEEPER.stl) | [B-black-07.3mf](../kit/B/plates/B-black-07.3mf) | 10 | 15.8 × 15.8 × 3.2 |

### 工程8：本体 1 段目を左から載せる

| 配置番号 | 部品ID | 3MF | slot | 印刷姿勢の外形 mm |
|---|---|---|---:|---|
| `B-025` | [BR-04x04-H096](../kit/B/parts/BR-04x04-H096.stl) | [B-magenta-02.3mf](../kit/B/plates/B-magenta-02.3mf) | 1 | 31.8 × 31.8 × 11.4 |
| `B-026` | [BR-04x04-H096](../kit/B/parts/BR-04x04-H096.stl) | [B-magenta-02.3mf](../kit/B/plates/B-magenta-02.3mf) | 2 | 31.8 × 31.8 × 11.4 |
| `B-027` | [BR-02x04-H096](../kit/B/parts/BR-02x04-H096.stl) | [B-magenta-01.3mf](../kit/B/plates/B-magenta-01.3mf) | 19 | 15.8 × 31.8 × 11.4 |

### 工程9：本体 2 段目を左から載せる

| 配置番号 | 部品ID | 3MF | slot | 印刷姿勢の外形 mm |
|---|---|---|---:|---|
| `B-028` | [BR-02x06-H096](../kit/B/parts/BR-02x06-H096.stl) | [B-magenta-01.3mf](../kit/B/plates/B-magenta-01.3mf) | 1 | 15.8 × 47.8 × 11.4 |
| `B-029` | [BR-02x04-H096](../kit/B/parts/BR-02x04-H096.stl) | [B-black-04.3mf](../kit/B/plates/B-black-04.3mf) | 3 | 15.8 × 31.8 × 11.4 |
| `B-030` | [BR-04x04-H096](../kit/B/parts/BR-04x04-H096.stl) | [B-black-05.3mf](../kit/B/plates/B-black-05.3mf) | 15 | 31.8 × 31.8 × 11.4 |
| `B-031` | [BR-02x04-H096](../kit/B/parts/BR-02x04-H096.stl) | [B-black-04.3mf](../kit/B/plates/B-black-04.3mf) | 4 | 15.8 × 31.8 × 11.4 |
| `B-032` | [BR-02x06-H096](../kit/B/parts/BR-02x06-H096.stl) | [B-magenta-01.3mf](../kit/B/plates/B-magenta-01.3mf) | 2 | 15.8 × 47.8 × 11.4 |

### 工程10：本体 3 段目を左から載せる

| 配置番号 | 部品ID | 3MF | slot | 印刷姿勢の外形 mm |
|---|---|---|---:|---|
| `B-033` | [BR-02x06-H096](../kit/B/parts/BR-02x06-H096.stl) | [B-magenta-01.3mf](../kit/B/plates/B-magenta-01.3mf) | 3 | 15.8 × 47.8 × 11.4 |
| `B-034` | [BR-04x04-H096](../kit/B/parts/BR-04x04-H096.stl) | [B-black-05.3mf](../kit/B/plates/B-black-05.3mf) | 16 | 31.8 × 31.8 × 11.4 |
| `B-035` | [BR-04x04-H096](../kit/B/parts/BR-04x04-H096.stl) | [B-black-05.3mf](../kit/B/plates/B-black-05.3mf) | 17 | 31.8 × 31.8 × 11.4 |
| `B-036` | [BR-02x04-H096](../kit/B/parts/BR-02x04-H096.stl) | [B-black-04.3mf](../kit/B/plates/B-black-04.3mf) | 5 | 15.8 × 31.8 × 11.4 |
| `B-037` | [BR-02x06-H096](../kit/B/parts/BR-02x06-H096.stl) | [B-magenta-01.3mf](../kit/B/plates/B-magenta-01.3mf) | 4 | 15.8 × 47.8 × 11.4 |

### 工程11：本体 4 段目を左から載せる

| 配置番号 | 部品ID | 3MF | slot | 印刷姿勢の外形 mm |
|---|---|---|---:|---|
| `B-038` | [BR-02x06-H096](../kit/B/parts/BR-02x06-H096.stl) | [B-magenta-01.3mf](../kit/B/plates/B-magenta-01.3mf) | 5 | 15.8 × 47.8 × 11.4 |
| `B-039` | [BR-02x04-H096](../kit/B/parts/BR-02x04-H096.stl) | [B-black-04.3mf](../kit/B/plates/B-black-04.3mf) | 6 | 15.8 × 31.8 × 11.4 |
| `B-040` | [BR-04x04-H096](../kit/B/parts/BR-04x04-H096.stl) | [B-black-05.3mf](../kit/B/plates/B-black-05.3mf) | 18 | 31.8 × 31.8 × 11.4 |
| `B-041` | [BR-04x04-H096](../kit/B/parts/BR-04x04-H096.stl) | [B-black-05.3mf](../kit/B/plates/B-black-05.3mf) | 19 | 31.8 × 31.8 × 11.4 |
| `B-042` | [BR-02x04-H096](../kit/B/parts/BR-02x04-H096.stl) | [B-black-04.3mf](../kit/B/plates/B-black-04.3mf) | 7 | 15.8 × 31.8 × 11.4 |
| `B-043` | [BR-02x06-H096](../kit/B/parts/BR-02x06-H096.stl) | [B-magenta-01.3mf](../kit/B/plates/B-magenta-01.3mf) | 6 | 15.8 × 47.8 × 11.4 |

### 工程12：本体 5 段目を左から載せる

| 配置番号 | 部品ID | 3MF | slot | 印刷姿勢の外形 mm |
|---|---|---|---:|---|
| `B-044` | [BR-02x06-H096](../kit/B/parts/BR-02x06-H096.stl) | [B-magenta-01.3mf](../kit/B/plates/B-magenta-01.3mf) | 7 | 15.8 × 47.8 × 11.4 |
| `B-045` | [BR-04x04-H096](../kit/B/parts/BR-04x04-H096.stl) | [B-black-05.3mf](../kit/B/plates/B-black-05.3mf) | 20 | 31.8 × 31.8 × 11.4 |
| `B-046` | [BR-01x04-H096](../kit/B/parts/BR-01x04-H096.stl) | [B-green-01.3mf](../kit/B/plates/B-green-01.3mf) | 1 | 7.8 × 31.8 × 11.4 |
| `B-047` | [BR-04x04-H096](../kit/B/parts/BR-04x04-H096.stl) | [B-black-06.3mf](../kit/B/plates/B-black-06.3mf) | 1 | 31.8 × 31.8 × 11.4 |
| `B-048` | [BR-01x04-H096](../kit/B/parts/BR-01x04-H096.stl) | [B-green-01.3mf](../kit/B/plates/B-green-01.3mf) | 2 | 7.8 × 31.8 × 11.4 |
| `B-049` | [BR-04x04-H096](../kit/B/parts/BR-04x04-H096.stl) | [B-black-06.3mf](../kit/B/plates/B-black-06.3mf) | 2 | 31.8 × 31.8 × 11.4 |
| `B-050` | [BR-02x06-H096](../kit/B/parts/BR-02x06-H096.stl) | [B-magenta-01.3mf](../kit/B/plates/B-magenta-01.3mf) | 8 | 15.8 × 47.8 × 11.4 |

### 工程13：本体 6 段目を左から載せる

| 配置番号 | 部品ID | 3MF | slot | 印刷姿勢の外形 mm |
|---|---|---|---:|---|
| `B-051` | [BR-02x06-H096](../kit/B/parts/BR-02x06-H096.stl) | [B-magenta-01.3mf](../kit/B/plates/B-magenta-01.3mf) | 9 | 15.8 × 47.8 × 11.4 |
| `B-052` | [BR-02x04-H096](../kit/B/parts/BR-02x04-H096.stl) | [B-black-04.3mf](../kit/B/plates/B-black-04.3mf) | 8 | 15.8 × 31.8 × 11.4 |
| `B-053` | [BR-03x04-H096](../kit/B/parts/BR-03x04-H096.stl) | [B-black-05.3mf](../kit/B/plates/B-black-05.3mf) | 3 | 23.8 × 31.8 × 11.4 |
| `B-054` | [BR-01x04-H096](../kit/B/parts/BR-01x04-H096.stl) | [B-green-01.3mf](../kit/B/plates/B-green-01.3mf) | 3 | 7.8 × 31.8 × 11.4 |
| `B-055` | [BR-02x04-H096](../kit/B/parts/BR-02x04-H096.stl) | [B-black-04.3mf](../kit/B/plates/B-black-04.3mf) | 9 | 15.8 × 31.8 × 11.4 |
| `B-056` | [BR-02x04-H096](../kit/B/parts/BR-02x04-H096.stl) | [B-black-04.3mf](../kit/B/plates/B-black-04.3mf) | 10 | 15.8 × 31.8 × 11.4 |
| `B-057` | [BR-01x04-H096](../kit/B/parts/BR-01x04-H096.stl) | [B-green-01.3mf](../kit/B/plates/B-green-01.3mf) | 4 | 7.8 × 31.8 × 11.4 |
| `B-058` | [BR-02x04-H096](../kit/B/parts/BR-02x04-H096.stl) | [B-black-04.3mf](../kit/B/plates/B-black-04.3mf) | 11 | 15.8 × 31.8 × 11.4 |
| `B-059` | [BR-03x04-H096](../kit/B/parts/BR-03x04-H096.stl) | [B-black-05.3mf](../kit/B/plates/B-black-05.3mf) | 4 | 23.8 × 31.8 × 11.4 |
| `B-060` | [BR-02x06-H096](../kit/B/parts/BR-02x06-H096.stl) | [B-magenta-01.3mf](../kit/B/plates/B-magenta-01.3mf) | 10 | 15.8 × 47.8 × 11.4 |

### 工程14：本体 7 段目を左から載せる

| 配置番号 | 部品ID | 3MF | slot | 印刷姿勢の外形 mm |
|---|---|---|---:|---|
| `B-061` | [BR-02x06-H096](../kit/B/parts/BR-02x06-H096.stl) | [B-magenta-01.3mf](../kit/B/plates/B-magenta-01.3mf) | 11 | 15.8 × 47.8 × 11.4 |
| `B-062` | [BR-05x04-H096](../kit/B/parts/BR-05x04-H096.stl) | [B-black-06.3mf](../kit/B/plates/B-black-06.3mf) | 16 | 39.8 × 31.8 × 11.4 |
| `B-063` | [BR-01x04-H096](../kit/B/parts/BR-01x04-H096.stl) | [B-green-01.3mf](../kit/B/plates/B-green-01.3mf) | 5 | 7.8 × 31.8 × 11.4 |
| `B-064` | [BR-04x04-H096](../kit/B/parts/BR-04x04-H096.stl) | [B-black-06.3mf](../kit/B/plates/B-black-06.3mf) | 3 | 31.8 × 31.8 × 11.4 |
| `B-065` | [BR-01x04-H096](../kit/B/parts/BR-01x04-H096.stl) | [B-green-01.3mf](../kit/B/plates/B-green-01.3mf) | 6 | 7.8 × 31.8 × 11.4 |
| `B-066` | [BR-05x04-H096](../kit/B/parts/BR-05x04-H096.stl) | [B-black-07.3mf](../kit/B/plates/B-black-07.3mf) | 1 | 39.8 × 31.8 × 11.4 |
| `B-067` | [BR-02x06-H096](../kit/B/parts/BR-02x06-H096.stl) | [B-magenta-01.3mf](../kit/B/plates/B-magenta-01.3mf) | 12 | 15.8 × 47.8 × 11.4 |

### 工程15：本体 8 段目を左から載せる

| 配置番号 | 部品ID | 3MF | slot | 印刷姿勢の外形 mm |
|---|---|---|---:|---|
| `B-068` | [BR-02x06-H096](../kit/B/parts/BR-02x06-H096.stl) | [B-magenta-01.3mf](../kit/B/plates/B-magenta-01.3mf) | 13 | 15.8 × 47.8 × 11.4 |
| `B-069` | [BR-02x04-H096](../kit/B/parts/BR-02x04-H096.stl) | [B-black-04.3mf](../kit/B/plates/B-black-04.3mf) | 12 | 15.8 × 31.8 × 11.4 |
| `B-070` | [BR-03x04-H096](../kit/B/parts/BR-03x04-H096.stl) | [B-black-05.3mf](../kit/B/plates/B-black-05.3mf) | 5 | 23.8 × 31.8 × 11.4 |
| `B-071` | [BR-01x04-H096](../kit/B/parts/BR-01x04-H096.stl) | [B-green-01.3mf](../kit/B/plates/B-green-01.3mf) | 7 | 7.8 × 31.8 × 11.4 |
| `B-072` | [BR-02x04-H096](../kit/B/parts/BR-02x04-H096.stl) | [B-black-04.3mf](../kit/B/plates/B-black-04.3mf) | 13 | 15.8 × 31.8 × 11.4 |
| `B-073` | [BR-02x04-H096](../kit/B/parts/BR-02x04-H096.stl) | [B-black-04.3mf](../kit/B/plates/B-black-04.3mf) | 14 | 15.8 × 31.8 × 11.4 |
| `B-074` | [BR-01x04-H096](../kit/B/parts/BR-01x04-H096.stl) | [B-green-01.3mf](../kit/B/plates/B-green-01.3mf) | 8 | 7.8 × 31.8 × 11.4 |
| `B-075` | [BR-02x04-H096](../kit/B/parts/BR-02x04-H096.stl) | [B-black-04.3mf](../kit/B/plates/B-black-04.3mf) | 15 | 15.8 × 31.8 × 11.4 |
| `B-076` | [BR-03x04-H096](../kit/B/parts/BR-03x04-H096.stl) | [B-black-05.3mf](../kit/B/plates/B-black-05.3mf) | 6 | 23.8 × 31.8 × 11.4 |
| `B-077` | [BR-02x06-H096](../kit/B/parts/BR-02x06-H096.stl) | [B-magenta-01.3mf](../kit/B/plates/B-magenta-01.3mf) | 14 | 15.8 × 47.8 × 11.4 |

### 工程16：本体 9 段目を左から載せる

| 配置番号 | 部品ID | 3MF | slot | 印刷姿勢の外形 mm |
|---|---|---|---:|---|
| `B-078` | [BR-02x06-H096](../kit/B/parts/BR-02x06-H096.stl) | [B-magenta-01.3mf](../kit/B/plates/B-magenta-01.3mf) | 15 | 15.8 × 47.8 × 11.4 |
| `B-079` | [BR-04x04-H096](../kit/B/parts/BR-04x04-H096.stl) | [B-black-06.3mf](../kit/B/plates/B-black-06.3mf) | 4 | 31.8 × 31.8 × 11.4 |
| `B-080` | [BR-04x04-H096](../kit/B/parts/BR-04x04-H096.stl) | [B-black-06.3mf](../kit/B/plates/B-black-06.3mf) | 5 | 31.8 × 31.8 × 11.4 |
| `B-081` | [BR-04x04-H096](../kit/B/parts/BR-04x04-H096.stl) | [B-black-06.3mf](../kit/B/plates/B-black-06.3mf) | 6 | 31.8 × 31.8 × 11.4 |
| `B-082` | [BR-04x04-H096](../kit/B/parts/BR-04x04-H096.stl) | [B-black-06.3mf](../kit/B/plates/B-black-06.3mf) | 7 | 31.8 × 31.8 × 11.4 |
| `B-083` | [BR-02x06-H096](../kit/B/parts/BR-02x06-H096.stl) | [B-magenta-01.3mf](../kit/B/plates/B-magenta-01.3mf) | 16 | 15.8 × 47.8 × 11.4 |

### 工程17：本体 10 段目を左から載せる

| 配置番号 | 部品ID | 3MF | slot | 印刷姿勢の外形 mm |
|---|---|---|---:|---|
| `B-084` | [BR-02x05-H096](../kit/B/parts/BR-02x05-H096.stl) | [B-cyan-01.3mf](../kit/B/plates/B-cyan-01.3mf) | 1 | 15.8 × 39.8 × 11.4 |
| `B-085` | [BR-04x05-H096](../kit/B/parts/BR-04x05-H096.stl) | [B-cyan-01.3mf](../kit/B/plates/B-cyan-01.3mf) | 25 | 31.8 × 39.8 × 11.4 |
| `B-086` | [BR-04x05-H096](../kit/B/parts/BR-04x05-H096.stl) | [B-cyan-01.3mf](../kit/B/plates/B-cyan-01.3mf) | 26 | 31.8 × 39.8 × 11.4 |
| `B-087` | [BR-04x05-H096](../kit/B/parts/BR-04x05-H096.stl) | [B-cyan-02.3mf](../kit/B/plates/B-cyan-02.3mf) | 1 | 31.8 × 39.8 × 11.4 |
| `B-088` | [BR-04x05-H096](../kit/B/parts/BR-04x05-H096.stl) | [B-cyan-02.3mf](../kit/B/plates/B-cyan-02.3mf) | 2 | 31.8 × 39.8 × 11.4 |
| `B-089` | [BR-02x05-H096](../kit/B/parts/BR-02x05-H096.stl) | [B-cyan-01.3mf](../kit/B/plates/B-cyan-01.3mf) | 2 | 15.8 × 39.8 × 11.4 |

### 工程18：本体 11 段目を左から載せる

| 配置番号 | 部品ID | 3MF | slot | 印刷姿勢の外形 mm |
|---|---|---|---:|---|
| `B-090` | [BR-02x05-H096](../kit/B/parts/BR-02x05-H096.stl) | [B-cyan-01.3mf](../kit/B/plates/B-cyan-01.3mf) | 3 | 15.8 × 39.8 × 11.4 |
| `B-091` | [BR-04x04-H096](../kit/B/parts/BR-04x04-H096.stl) | [B-black-06.3mf](../kit/B/plates/B-black-06.3mf) | 8 | 31.8 × 31.8 × 11.4 |
| `B-092` | [BR-03x04-H096](../kit/B/parts/BR-03x04-H096.stl) | [B-black-05.3mf](../kit/B/plates/B-black-05.3mf) | 7 | 23.8 × 31.8 × 11.4 |
| `B-093` | [BR-02x05-H096](../kit/B/parts/BR-02x05-H096.stl) | [B-cyan-01.3mf](../kit/B/plates/B-cyan-01.3mf) | 4 | 15.8 × 39.8 × 11.4 |
| `B-094` | [BR-04x04-H096](../kit/B/parts/BR-04x04-H096.stl) | [B-black-06.3mf](../kit/B/plates/B-black-06.3mf) | 9 | 31.8 × 31.8 × 11.4 |
| `B-095` | [BR-03x04-H096](../kit/B/parts/BR-03x04-H096.stl) | [B-black-05.3mf](../kit/B/plates/B-black-05.3mf) | 8 | 23.8 × 31.8 × 11.4 |
| `B-096` | [BR-02x05-H096](../kit/B/parts/BR-02x05-H096.stl) | [B-cyan-01.3mf](../kit/B/plates/B-cyan-01.3mf) | 5 | 15.8 × 39.8 × 11.4 |

### 工程19：本体 12 段目を左から載せる

| 配置番号 | 部品ID | 3MF | slot | 印刷姿勢の外形 mm |
|---|---|---|---:|---|
| `B-097` | [BR-02x05-H096](../kit/B/parts/BR-02x05-H096.stl) | [B-cyan-01.3mf](../kit/B/plates/B-cyan-01.3mf) | 6 | 15.8 × 39.8 × 11.4 |
| `B-098` | [BR-02x04-H096](../kit/B/parts/BR-02x04-H096.stl) | [B-black-04.3mf](../kit/B/plates/B-black-04.3mf) | 16 | 15.8 × 31.8 × 11.4 |
| `B-099` | [BR-05x04-H096](../kit/B/parts/BR-05x04-H096.stl) | [B-black-07.3mf](../kit/B/plates/B-black-07.3mf) | 2 | 39.8 × 31.8 × 11.4 |
| `B-100` | [BR-02x05-H096](../kit/B/parts/BR-02x05-H096.stl) | [B-cyan-01.3mf](../kit/B/plates/B-cyan-01.3mf) | 7 | 15.8 × 39.8 × 11.4 |
| `B-101` | [BR-02x04-H096](../kit/B/parts/BR-02x04-H096.stl) | [B-black-04.3mf](../kit/B/plates/B-black-04.3mf) | 17 | 15.8 × 31.8 × 11.4 |
| `B-102` | [BR-05x04-H096](../kit/B/parts/BR-05x04-H096.stl) | [B-black-07.3mf](../kit/B/plates/B-black-07.3mf) | 3 | 39.8 × 31.8 × 11.4 |
| `B-103` | [BR-02x05-H096](../kit/B/parts/BR-02x05-H096.stl) | [B-cyan-01.3mf](../kit/B/plates/B-cyan-01.3mf) | 8 | 15.8 × 39.8 × 11.4 |

### 工程20：本体 13 段目を左から載せる

| 配置番号 | 部品ID | 3MF | slot | 印刷姿勢の外形 mm |
|---|---|---|---:|---|
| `B-104` | [BR-02x05-H096](../kit/B/parts/BR-02x05-H096.stl) | [B-cyan-01.3mf](../kit/B/plates/B-cyan-01.3mf) | 9 | 15.8 × 39.8 × 11.4 |
| `B-105` | [BR-04x04-H096](../kit/B/parts/BR-04x04-H096.stl) | [B-black-06.3mf](../kit/B/plates/B-black-06.3mf) | 10 | 31.8 × 31.8 × 11.4 |
| `B-106` | [BR-03x04-H096](../kit/B/parts/BR-03x04-H096.stl) | [B-black-05.3mf](../kit/B/plates/B-black-05.3mf) | 9 | 23.8 × 31.8 × 11.4 |
| `B-107` | [BR-02x05-H096](../kit/B/parts/BR-02x05-H096.stl) | [B-cyan-01.3mf](../kit/B/plates/B-cyan-01.3mf) | 10 | 15.8 × 39.8 × 11.4 |
| `B-108` | [BR-04x04-H096](../kit/B/parts/BR-04x04-H096.stl) | [B-black-06.3mf](../kit/B/plates/B-black-06.3mf) | 11 | 31.8 × 31.8 × 11.4 |
| `B-109` | [BR-03x04-H096](../kit/B/parts/BR-03x04-H096.stl) | [B-black-05.3mf](../kit/B/plates/B-black-05.3mf) | 10 | 23.8 × 31.8 × 11.4 |
| `B-110` | [BR-02x05-H096](../kit/B/parts/BR-02x05-H096.stl) | [B-cyan-01.3mf](../kit/B/plates/B-cyan-01.3mf) | 11 | 15.8 × 39.8 × 11.4 |

### 工程21：本体 14 段目を左から載せる

| 配置番号 | 部品ID | 3MF | slot | 印刷姿勢の外形 mm |
|---|---|---|---:|---|
| `B-111` | [BR-02x05-H096](../kit/B/parts/BR-02x05-H096.stl) | [B-cyan-01.3mf](../kit/B/plates/B-cyan-01.3mf) | 12 | 15.8 × 39.8 × 11.4 |
| `B-112` | [BR-02x04-H096](../kit/B/parts/BR-02x04-H096.stl) | [B-black-04.3mf](../kit/B/plates/B-black-04.3mf) | 18 | 15.8 × 31.8 × 11.4 |
| `B-113` | [BR-05x04-H096](../kit/B/parts/BR-05x04-H096.stl) | [B-black-07.3mf](../kit/B/plates/B-black-07.3mf) | 4 | 39.8 × 31.8 × 11.4 |
| `B-114` | [BR-02x05-H096](../kit/B/parts/BR-02x05-H096.stl) | [B-cyan-01.3mf](../kit/B/plates/B-cyan-01.3mf) | 13 | 15.8 × 39.8 × 11.4 |
| `B-115` | [BR-02x04-H096](../kit/B/parts/BR-02x04-H096.stl) | [B-black-04.3mf](../kit/B/plates/B-black-04.3mf) | 19 | 15.8 × 31.8 × 11.4 |
| `B-116` | [BR-05x04-H096](../kit/B/parts/BR-05x04-H096.stl) | [B-black-07.3mf](../kit/B/plates/B-black-07.3mf) | 5 | 39.8 × 31.8 × 11.4 |
| `B-117` | [BR-02x05-H096](../kit/B/parts/BR-02x05-H096.stl) | [B-cyan-01.3mf](../kit/B/plates/B-cyan-01.3mf) | 14 | 15.8 × 39.8 × 11.4 |

### 工程22：本体 15 段目を左から載せる

| 配置番号 | 部品ID | 3MF | slot | 印刷姿勢の外形 mm |
|---|---|---|---:|---|
| `B-118` | [BR-02x05-H096](../kit/B/parts/BR-02x05-H096.stl) | [B-cyan-01.3mf](../kit/B/plates/B-cyan-01.3mf) | 15 | 15.8 × 39.8 × 11.4 |
| `B-119` | [BR-04x04-H096](../kit/B/parts/BR-04x04-H096.stl) | [B-black-06.3mf](../kit/B/plates/B-black-06.3mf) | 12 | 31.8 × 31.8 × 11.4 |
| `B-120` | [BR-03x04-H096](../kit/B/parts/BR-03x04-H096.stl) | [B-black-05.3mf](../kit/B/plates/B-black-05.3mf) | 11 | 23.8 × 31.8 × 11.4 |
| `B-121` | [BR-02x05-H096](../kit/B/parts/BR-02x05-H096.stl) | [B-cyan-01.3mf](../kit/B/plates/B-cyan-01.3mf) | 16 | 15.8 × 39.8 × 11.4 |
| `B-122` | [BR-04x04-H096](../kit/B/parts/BR-04x04-H096.stl) | [B-black-06.3mf](../kit/B/plates/B-black-06.3mf) | 13 | 31.8 × 31.8 × 11.4 |
| `B-123` | [BR-03x04-H096](../kit/B/parts/BR-03x04-H096.stl) | [B-black-05.3mf](../kit/B/plates/B-black-05.3mf) | 12 | 23.8 × 31.8 × 11.4 |
| `B-124` | [BR-02x05-H096](../kit/B/parts/BR-02x05-H096.stl) | [B-cyan-01.3mf](../kit/B/plates/B-cyan-01.3mf) | 17 | 15.8 × 39.8 × 11.4 |

### 工程23：本体 16 段目を左から載せる

| 配置番号 | 部品ID | 3MF | slot | 印刷姿勢の外形 mm |
|---|---|---|---:|---|
| `B-125` | [BR-02x05-H096](../kit/B/parts/BR-02x05-H096.stl) | [B-cyan-01.3mf](../kit/B/plates/B-cyan-01.3mf) | 18 | 15.8 × 39.8 × 11.4 |
| `B-126` | [BR-02x04-H096](../kit/B/parts/BR-02x04-H096.stl) | [B-black-05.3mf](../kit/B/plates/B-black-05.3mf) | 1 | 15.8 × 31.8 × 11.4 |
| `B-127` | [BR-05x04-H096](../kit/B/parts/BR-05x04-H096.stl) | [B-black-07.3mf](../kit/B/plates/B-black-07.3mf) | 6 | 39.8 × 31.8 × 11.4 |
| `B-128` | [BR-02x05-H096](../kit/B/parts/BR-02x05-H096.stl) | [B-cyan-01.3mf](../kit/B/plates/B-cyan-01.3mf) | 19 | 15.8 × 39.8 × 11.4 |
| `B-129` | [BR-02x04-H096](../kit/B/parts/BR-02x04-H096.stl) | [B-black-05.3mf](../kit/B/plates/B-black-05.3mf) | 2 | 15.8 × 31.8 × 11.4 |
| `B-130` | [BR-05x04-H096](../kit/B/parts/BR-05x04-H096.stl) | [B-black-07.3mf](../kit/B/plates/B-black-07.3mf) | 7 | 39.8 × 31.8 × 11.4 |
| `B-131` | [BR-02x05-H096](../kit/B/parts/BR-02x05-H096.stl) | [B-cyan-01.3mf](../kit/B/plates/B-cyan-01.3mf) | 20 | 15.8 × 39.8 × 11.4 |

### 工程24：本体 17 段目を左から載せる

| 配置番号 | 部品ID | 3MF | slot | 印刷姿勢の外形 mm |
|---|---|---|---:|---|
| `B-132` | [BR-02x05-H096](../kit/B/parts/BR-02x05-H096.stl) | [B-cyan-01.3mf](../kit/B/plates/B-cyan-01.3mf) | 21 | 15.8 × 39.8 × 11.4 |
| `B-133` | [BR-04x04-H096](../kit/B/parts/BR-04x04-H096.stl) | [B-black-06.3mf](../kit/B/plates/B-black-06.3mf) | 14 | 31.8 × 31.8 × 11.4 |
| `B-134` | [BR-03x04-H096](../kit/B/parts/BR-03x04-H096.stl) | [B-black-05.3mf](../kit/B/plates/B-black-05.3mf) | 13 | 23.8 × 31.8 × 11.4 |
| `B-135` | [BR-02x05-H096](../kit/B/parts/BR-02x05-H096.stl) | [B-cyan-01.3mf](../kit/B/plates/B-cyan-01.3mf) | 22 | 15.8 × 39.8 × 11.4 |
| `B-136` | [BR-04x04-H096](../kit/B/parts/BR-04x04-H096.stl) | [B-black-06.3mf](../kit/B/plates/B-black-06.3mf) | 15 | 31.8 × 31.8 × 11.4 |
| `B-137` | [BR-03x04-H096](../kit/B/parts/BR-03x04-H096.stl) | [B-black-05.3mf](../kit/B/plates/B-black-05.3mf) | 14 | 23.8 × 31.8 × 11.4 |
| `B-138` | [BR-02x05-H096](../kit/B/parts/BR-02x05-H096.stl) | [B-cyan-01.3mf](../kit/B/plates/B-cyan-01.3mf) | 23 | 15.8 × 39.8 × 11.4 |

### 工程25：本体 18 段目を左から載せる

| 配置番号 | 部品ID | 3MF | slot | 印刷姿勢の外形 mm |
|---|---|---|---:|---|
| `B-139` | [BR-02x05-H096](../kit/B/parts/BR-02x05-H096.stl) | [B-cyan-01.3mf](../kit/B/plates/B-cyan-01.3mf) | 24 | 15.8 × 39.8 × 11.4 |
| `B-140` | [BR-04x05-H096](../kit/B/parts/BR-04x05-H096.stl) | [B-cyan-02.3mf](../kit/B/plates/B-cyan-02.3mf) | 3 | 31.8 × 39.8 × 11.4 |
| `B-141` | [BR-04x05-H096](../kit/B/parts/BR-04x05-H096.stl) | [B-cyan-02.3mf](../kit/B/plates/B-cyan-02.3mf) | 4 | 31.8 × 39.8 × 11.4 |
| `B-142` | [BR-04x05-H096](../kit/B/parts/BR-04x05-H096.stl) | [B-cyan-02.3mf](../kit/B/plates/B-cyan-02.3mf) | 5 | 31.8 × 39.8 × 11.4 |
| `B-143` | [BR-04x05-H096](../kit/B/parts/BR-04x05-H096.stl) | [B-cyan-02.3mf](../kit/B/plates/B-cyan-02.3mf) | 6 | 31.8 × 39.8 × 11.4 |

### 工程26：本体 19 段目を左から載せる

| 配置番号 | 部品ID | 3MF | slot | 印刷姿勢の外形 mm |
|---|---|---|---:|---|
| `B-144` | [BR-04x05-H096](../kit/B/parts/BR-04x05-H096.stl) | [B-cyan-02.3mf](../kit/B/plates/B-cyan-02.3mf) | 7 | 31.8 × 39.8 × 11.4 |
| `B-145` | [BR-04x05-H096](../kit/B/parts/BR-04x05-H096.stl) | [B-cyan-02.3mf](../kit/B/plates/B-cyan-02.3mf) | 8 | 31.8 × 39.8 × 11.4 |
| `B-146` | [BR-04x05-H096](../kit/B/parts/BR-04x05-H096.stl) | [B-cyan-02.3mf](../kit/B/plates/B-cyan-02.3mf) | 9 | 31.8 × 39.8 × 11.4 |
| `B-147` | [BR-04x05-H096](../kit/B/parts/BR-04x05-H096.stl) | [B-cyan-02.3mf](../kit/B/plates/B-cyan-02.3mf) | 10 | 31.8 × 39.8 × 11.4 |

### 工程27：頭頂のマゼンタのプレートを載せる

| 配置番号 | 部品ID | 3MF | slot | 印刷姿勢の外形 mm |
|---|---|---|---:|---|
| `B-148` | [BR-02x04-H064](../kit/B/parts/BR-02x04-H064.stl) | [B-magenta-01.3mf](../kit/B/plates/B-magenta-01.3mf) | 17 | 15.8 × 31.8 × 8.2 |
| `B-149` | [BR-04x04-H064](../kit/B/parts/BR-04x04-H064.stl) | [B-magenta-01.3mf](../kit/B/plates/B-magenta-01.3mf) | 20 | 31.8 × 31.8 × 8.2 |
| `B-150` | [BR-02x04-H064](../kit/B/parts/BR-02x04-H064.stl) | [B-magenta-01.3mf](../kit/B/plates/B-magenta-01.3mf) | 18 | 15.8 × 31.8 × 8.2 |

### 工程28：2行と右ロゴが5段台座の正面内に収まること、保持と転倒を確認する

追加0個。150個がそろったら実物の保持・着座・安定を確認します。

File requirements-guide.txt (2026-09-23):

-r requirements-verify.txt
playwright==1.55.0
Pillow==11.3.0
Markdown==3.8.2

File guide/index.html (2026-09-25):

BRICK / ASSEMBLY LAB

# B DESK CLASSIC / 個人版・印刷ファイルから組み立てる3Dガイド

印刷したファイルを、実物の部品の形で探す。
見つけたら、1個ずつ組み立てよう。

実写真の制作記録を読む

文字の試作から台座、顔、ゴーグルを組み、9/25に完成のご報告が届きました。実写真と本人の言葉で制作の歩みを残しています。

写真の記録はZIP全体を展開するとオフラインで読めます。3Dの動きは説明用CGで、写真や実組立動画ではありません。

印刷順 ≠ 組立順。プレート番号は「段数」ではありません。

最初の部品を確認しています。

最初の1個を見せる

5段台座に必要なファイルを確認

下のファイルにある対象部品を先に仕分けます。同じ形・同じ色のコピーは交換可能ですが、必要な個数は減りません。

実STLとプレート対応を読み込み中…

1個ずつ組む

## 最初の1個

### 01 ファイルから部品を探す

印刷した3MF

斜め上 前右 背面裏面

選んだ1個を拡大（裏面・溝の違いを見る）

手前 = −Y / 印刷面は上

### 02 場所と向きを確認して組む

組立工程（プレート番号とは別）

斜め前 右上 背面裏面

組立済みを淡くして、隠れた接続を見る

正面 = 銘板・右ロゴの側

やり直し1個戻る 再生次の1個 この工程だけ再生 速さ

手順の区切りへ移動（今の1個は「次の1個」で確認）

今の1個の動き 0%

## プレート内の番号から選ぶ

番号はこのガイド用のslotです。部品への刻印ではありません。 Bambu Studio側の並べ替え後の番号でもありません。元の配置と形で照合してください。

同じpart ID＋同じ色の部品は交換可能です。「便宜割当」は仕分け例であり、その実物1個だけの行き先を断定しません。寸法が同じでも、IDや溝が違うものは交換しません。

### 使える組立場所

選ぶとその場所を示します。「ここから組む」で、その直前まで組立済みの状態へ移動します。

### 同じ形・色を取り出せる全ファイル

3D内の部品も選択できます。図形が重なる場合は上のslot・場所ボタンを使ってください。回転はドラッグ／左右キー、ズームはホイール／ピンチです。

## 図で分かることと、実物で確認すること

実STL・実配置から作った説明用3DCGです。動きは手順の案内であり、物理シミュレーションや嵌合合格の証拠ではありません。無接着。無理押し・打撃をしないでください。

NOT_SLICED / 実機嵌合・keeper保持・強度・転倒は未試験。 先にFIT・NP3-FIT・少量試作。閉塞・白化・強い力・着座不良があれば全数印刷と組立を止めます。

本体は色別単色。銘板は黒支持体2.4 mm、右ロゴは2.8 mmの後に白レリーフが続きます。実レイヤープレビューで最初の白経路の直前にPauseを設定します。固定層番号ではありません。汎用3MFにPauseやプリンタ設定は入っていません。

STLを100%・mmで使用。同じ部品のSTLと3MFは重ねて読み込まないでください。スロット一覧はダウンロード・スライス・プリンタ送信を実行しません。

オフライン・使用ライブラリ

実形状と対応データはこのHTMLに埋め込まれています。通信、CDN、API、解析サービスは使用しません。Chrome・Edge・Firefox・Safariの現行版で開いてください。Three.js / OrbitControls / STLLoader はMITライセンス（Copyright © 2010–2025 three.js authors）。著作権表示とライセンス全文は同梱runtimeにも保持されています。本作品は非公式で、包括ライセンス・互換認証・玩具認証は付与していません。

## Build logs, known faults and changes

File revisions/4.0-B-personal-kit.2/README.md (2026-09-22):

# 旧銘板の履歴 — 現行印刷対象ではありません

2026-09-22の可読性改訂前の、正確な個人2行銘板を保存しています。
旧版は上段12 mm／下段8 mm、白い浮彫0.8 mm、全厚3.2 mmです。
黒の基材と裏取付けは新版と同じです。

`nameplate/plate.stl`と`plate.3mf`は同じ旧板1個の代替形式です。
ここから旧板を現行キットへ混ぜないでください。旧版の資料・再現のためだけに残しています。
現行は[新版説明](../../docs/NAMEPLATE-V2.md)から選んでください。
この旧版フォルダは現行印刷ZIPには含めません。

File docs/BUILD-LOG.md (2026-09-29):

# Bの制作記録 — 文字試作・土台から完成まで

[3D工程へ](../guide/index.html) · [印刷手順](PRINTING.md) · [組立手順](ASSEMBLY.md) · [銘板の設計改訂](NAMEPLATE-V2.md)

**2026-09-30（JST）追加：[CLI風アレンジの実物写真](#cli-arrangement-2026-09-30)。**
ブロックを変更した、標準配布モデルとは異なるアレンジ例です。これまでの制作・完成写真も残しています。

**2026-09-25、完成しました。**
「制作過程の写真です」に続き、**「これで完成ですね」**とご報告いただきました。
ゴーグルの上枠が閉じ、紫の頭頂パーツまでそろった姿を、実物の完成記録として残します。
[9/25の完成までの写真へ](#progress-2026-09-25)進むか、文字試作から順に読めます。
前の16枚を保持し、この日の8枚を加えて9/25までの写真は24枚になりました。

**前の記録：2026-09-24、顔下部の組立途中。**
本人の言葉は「こちらは組み立ての途中記録になります」でした。
[9/24の節](#progress-2026-09-24)は、その日に届いた途中の状態として残しています。
当時の写真には上部ゴーグル・頭頂はまだ写っていません。

**前の記録：2026-09-23、「土台が組み上がりました」との報告。**
黒い台座、前面の空き溝、右ロゴを入れた状態、2行の個人銘板と右ロゴがそろった状態を、
ユーザー提供の実写真で記録します。ここまでの実制作の節目であり、
**顔・ゴーグル・150部品すべての完成写真ではありません。**

写真は各回の掲載許可を得て、必要な向き・切り取りを整え、元のメタデータを除去したものです。
一部写真には、無関係な背景PC画面などを隠す不透明マスクもあります。
造形の欠点・部品の段数・装着状態を変える合成はしていません。
各節の日付は**報告日または追加日**です。撮影日時や撮影順は未確定で、
別角度の写真がすべて別の工程・別の日を表すとは限りません。

## 今回の制作は5工程

ユーザーが示した制作の流れは、**企画 → 設計 → 3Dプリント → 超音波洗浄 → アッセンブリー（組み立て）**です。
下の工程案内から設計資料・ページ内動画・実物写真へ進めます。写真の日付別記録は、そのまま下に残しています。

| 工程 | 今回の内容 | 見るもの |
|---|---|---|
| 1. 企画 | 贈って卓上に飾る模型の形・用途・大きさを考える | [企画・仕様](#process-planning) |
| 2. 設計 | FreeCADで分割・取付けを設計し、CG・図面と銘板改良を確認 | [設計資料](#process-design) |
| 3. 3Dプリント | 設計したパーツを印刷する工程 | [ページ内の印刷動画](#printing-video-2026-09-25) |
| 4. 超音波洗浄 | 今回の印刷後の後処理 | [ページ内の洗浄動画](#post-processing-ultrasonic-2026-09-25) |
| 5. アッセンブリー | 土台から顔・ゴーグル・頭頂まで組む | [実写真と3D工程](#process-assembly) |

#### 企画 — 飾る形と贈る内容を考える

卓上に飾るBモデルとして、形・用途・大きさと、2行の個人銘板を検討しました。
選んだモデルの仕様は[案内トップ](../README.md)にまとめています。

#### 設計 — 実形状・分割・完成像を確認する

FreeCADで部品の実形状と分割・取付けを設計し、Blenderを使った設計段階のCGなどで完成像を確認しました。
その後の[銘板の可読性改良](NAMEPLATE-V2.md)は、現行のCAD・図へ反映しています。
[寸法・組立図](../kit/B/drawings.pdf)と[出典・現行CGの作成方法](PROVENANCE.md)を参照できます。
設計CGと、ここに掲載する実物写真は別の資料です。

#### アッセンブリー — 積み上げて完成へ

[部品を探せる3D組立ガイド](../guide/index.html)と、
[9/25の完成までの実写真](#progress-2026-09-25)で、土台からゴーグル・頭頂までをたどれます。
制作過程を振り返る写真と、次に作る人が使う設計上の組立手順を行き来できる構成です。

## ここまでの流れ

| 報告日・追加日 | 本人の報告・写真で確認できること | 設計変更・未確認事項 |
|---|---|---|
| 2026-09-22 | 文字が小さく、隙間が狭くて印刷しにくそうとの相談。白文字の糸や表面の荒れも見える。使用ノズルは本人回答で0.2 mm | 2行を維持する方針で改訂。写真だけから流量・温度・乾燥状態の原因や補正値は決めていない |
| 2026-09-23 12:09 | 銘板2枚の写真と「いけているみたい」との報告 | 改訂後の試作についての手応えとして記録。2枚の旧・新版対応、STLや実スライスの版・hashは未照合 |
| 2026-09-23 12:18 | 「土台が組み上がりました」との報告。積層・継ぎ目・前面部品を取り付けた台座が写っている | 取付状態の写真はあるが、接着の有無、保持力、実測寸法、着脱回数、荷重・転倒の評価結果は未提供 |
| 2026-09-24 22:27 | 「こちらは組み立ての途中記録になります」との報告。土台の上の紫・黒の層、左右の段付き輪郭、黄色い縦2列が見える | 顔下部の途中記録。正確なCAD工程番号・部品数・撮影順・使用ファイル／実スライス版は未照合。上部ゴーグル・頭頂・全体完成は未確認 |
| 2026-09-25 | 「制作過程の写真です」に続き「これで完成ですね」との報告。水色のゴーグル枠を組み、上枠と紫の頭頂までそろった姿が見える | 本人の完成報告と実物写真を記録。設計値や個々の部品検品、使用データの版・実測試験とは区別する |
| 2026-09-30（追加日） | ブロックを変更してCLI風にした、との本人説明と実物写真1枚 | 標準配布モデルとは異なるアレンジ例。標準の設計・印刷データは変更せず、撮影日や使用部品の版対応も推測しない |

## 9/22〜23 — 文字試作と台座の記録

### 1. 最初の文字試作で、余裕の少なさが見えた

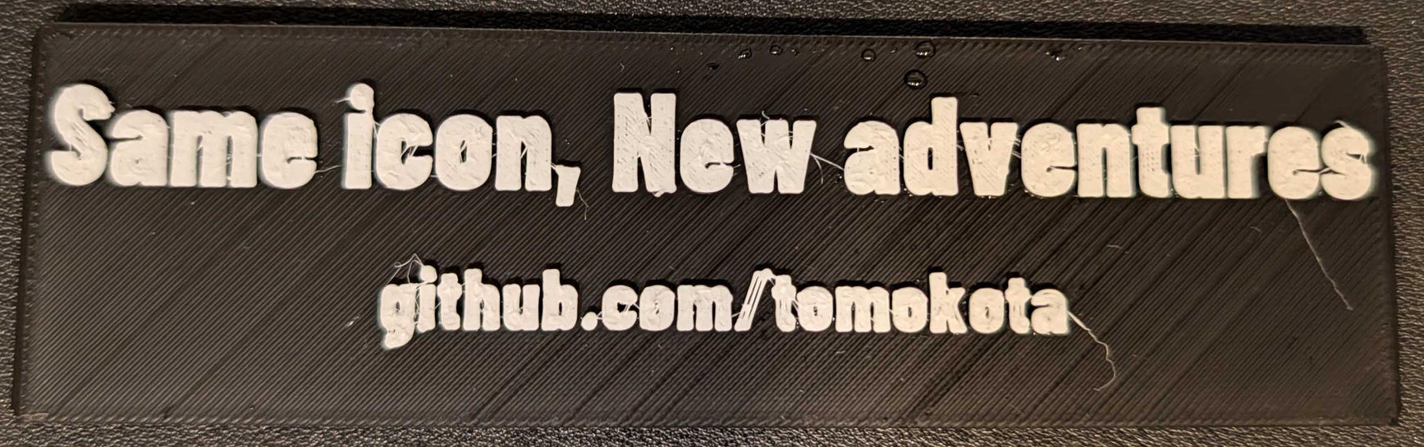
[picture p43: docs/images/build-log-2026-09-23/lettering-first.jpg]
2026-09-22の文字相談に添えられた銘板。白文字の狭い孔や字間、糸状の樹脂と表面の荒れが見える


**報告日：2026-09-22。** 2行の銘板を実際に作ったことで、
画面の見え方だけでは分かりにくかった文字内の孔・字間・表面の状態を確認するきっかけになりました。
0.2 mmノズルという情報は、この相談時の本人回答です。他の写真すべての印刷条件を示すものではありません。

その後、ユーザーは2行を維持し、下段を少し大きく、上段の孔に余裕を持たせ、
白い文字を厚くする方針を選びました。[採用した設計](NAMEPLATE-V2.md)は
上段12 mmを維持、下段8→10 mm、白の浮彫0.8→1.2 mm、黒2.4 mmと取付け基材は不変です。
これは**設計の値**で、写真から現物を測った結果ではありません。

### 2. 改訂後、銘板の試作について手応えの報告

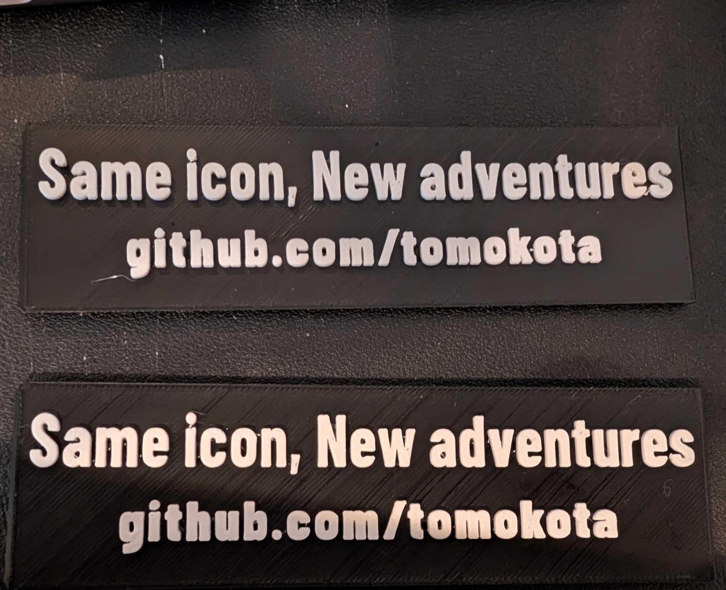
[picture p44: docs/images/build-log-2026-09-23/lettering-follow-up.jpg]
2026-09-23の追加写真。2行の個人銘板が上下に2枚並んでいる。各板の版対応は未照合


**報告日：2026-09-23。本人の言葉：「いけているみたい」。**
2枚の実物が並んだ写真と、制作が進められそうという手応えが届きました。
上・下のどちらを旧版／新版と呼べるかは未照合なので、断定ラベルは付けません。
この報告を、特定のSTL版の印刷合格や、糸引き・表面荒れの完全解消とは扱いません。

### 3. 黒い台座の積層・継ぎ目と、前面の空き領域

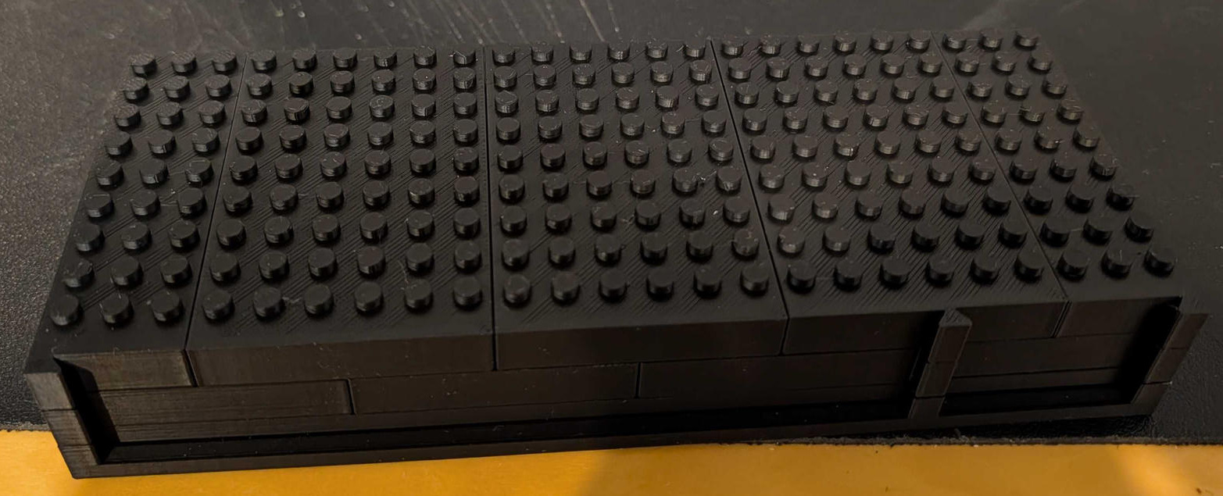
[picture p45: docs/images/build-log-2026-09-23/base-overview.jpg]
積み重ねた黒い台座。上面のスタッド、ブロックの継ぎ目、前面の空いた銘板用とロゴ用の領域が見える


**報告日：2026-09-23。** 台座の積層と継ぎ目、上面のスタッド、
前面部品を入れる領域が見える写真です。
「ファイルを印刷する」から「台座の形に組む」へ進んだ様子が分かります。
写真から正確な段数・部品数・クリアランス値を補ってはいません。
設計上の5段・台座19個は[組立手順](ASSEMBLY.md)の値として区別します。

### 4. 右側のロゴが入った状態

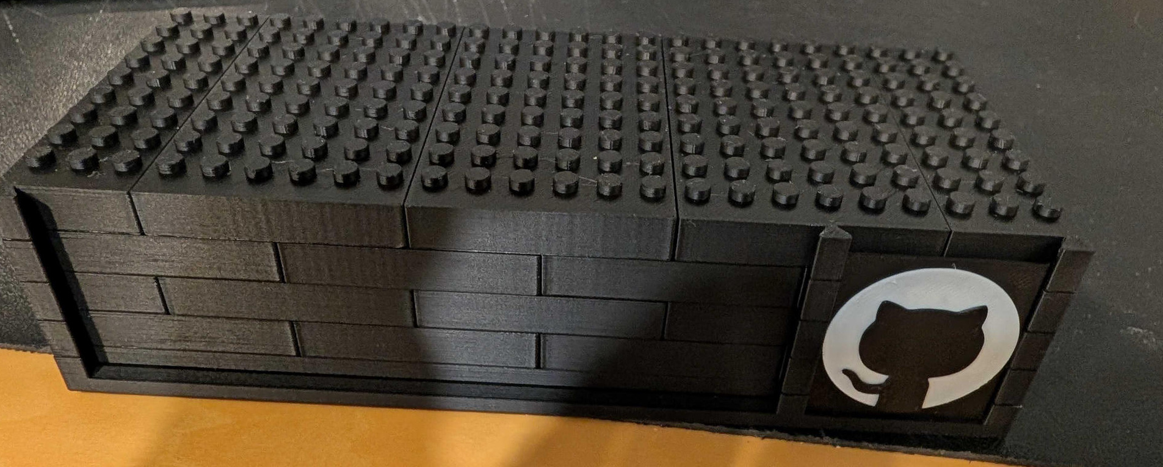
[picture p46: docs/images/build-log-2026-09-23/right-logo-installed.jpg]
右側の前面にロゴ部品が入った台座。左の銘板領域は空いている


**報告日：2026-09-23。** 右側のロゴ部品が入った状態を確認できます。
左の銘板領域は空いています。掲載順は組み方を理解しやすい順であり、
この写真が他の写真より先に撮影されたという意味ではありません。
差し込む操作、必要な力、保持力、何回着脱できたかは写っていません。

### 5. 個人銘板と右ロゴを取り付けた土台へ

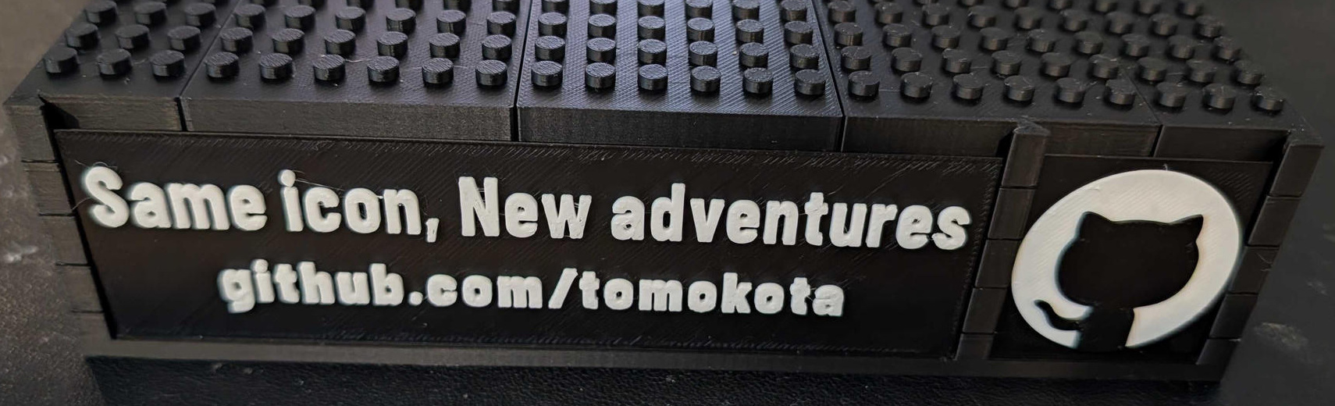
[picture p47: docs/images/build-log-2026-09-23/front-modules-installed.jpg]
2行の個人銘板と右側のロゴが取り付けられた黒い台座。顔やゴーグルはこの写真にはない


**報告日：2026-09-23。本人の言葉：「土台が組み上がりました」。**
前面に2行の個人銘板と右ロゴがそろった状態です。
今回は**台座と前面部品の実制作マイルストーン**として記録します。
写真だけで無接着を証明したり、keeperの保持・分解耐久・完成模型の安定性が合格したとは言いません。
**9/23時点**では顔・ゴーグル・完成150部品全体の制作写真は未提供でした。
その後の顔下部の進捗は、下の[9/24追記](#progress-2026-09-24)として区別しています。

## 補足ギャラリー — 同じ進捗の別角度も含む

<details markdown="1">
<summary>台座の上面・側面・前面を、あと4枚で見る</summary>

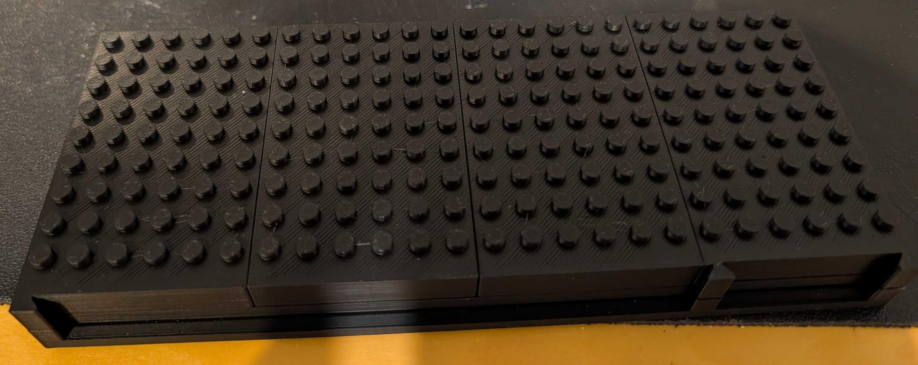
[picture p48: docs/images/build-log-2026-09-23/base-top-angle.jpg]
台座の上面のスタッドと継ぎ目が分かる別角度


**上面側。報告日：2026-09-23。** スタッドと継ぎ目を確認できます。寸法・段数の実測記録ではありません。

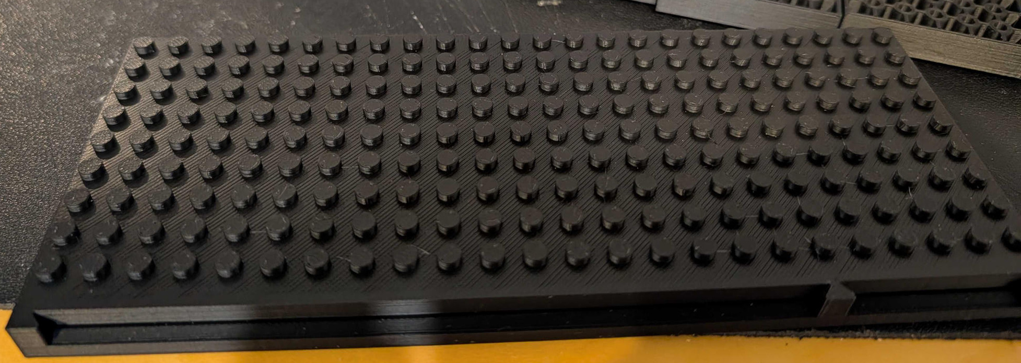
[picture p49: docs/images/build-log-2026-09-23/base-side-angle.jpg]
黒い台座の側面と上面を見た別角度


**側面側。報告日：2026-09-23。** 同じ進捗を別角度から写した可能性があります。未撮影の組立操作を補う写真ではありません。

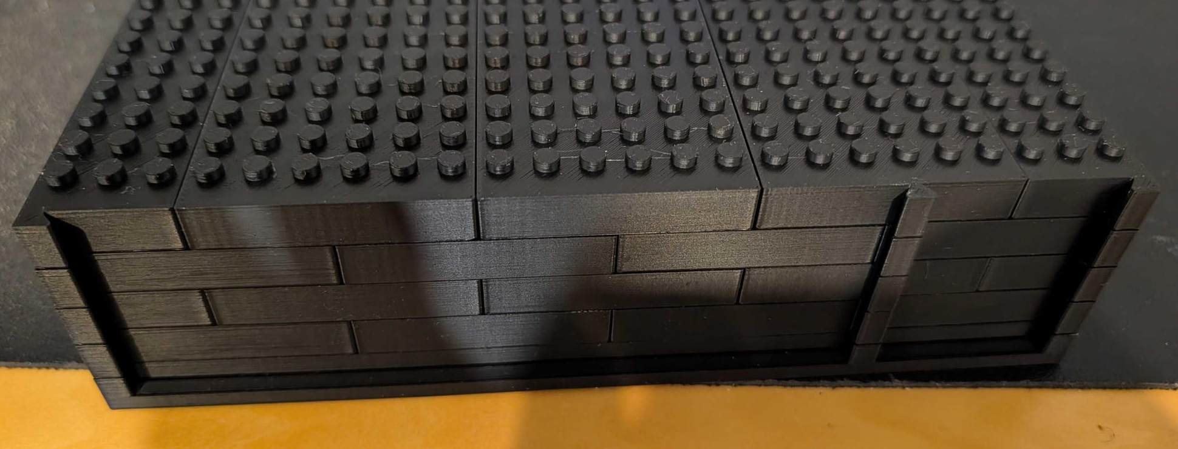
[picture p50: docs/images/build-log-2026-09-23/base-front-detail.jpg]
前面の継ぎ目と2つの取付け領域の詳細


**前面の詳細。報告日：2026-09-23。** 継ぎ目と取付け領域が見えます。写真の画素から嵌合公差は算定しません。

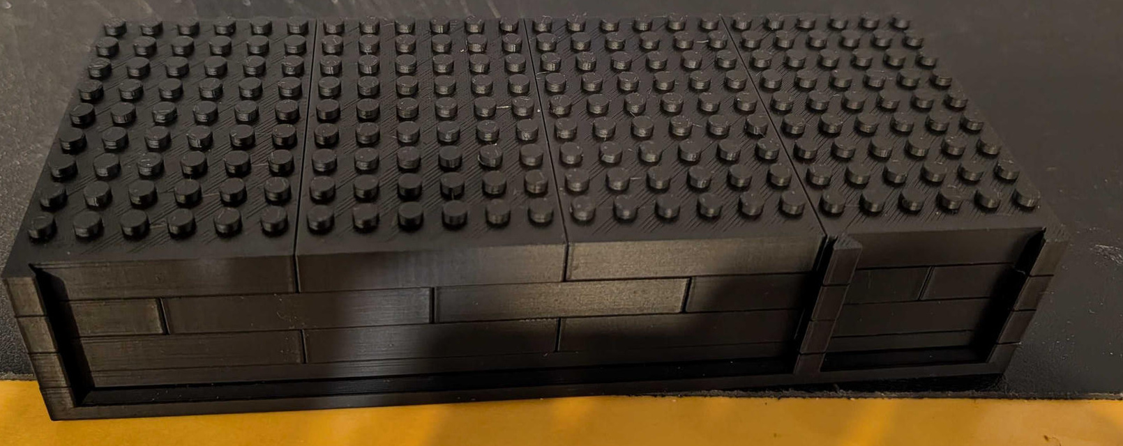
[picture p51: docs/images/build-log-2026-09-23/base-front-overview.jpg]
前面パーツが入っていない状態の台座全景


**前面全景。報告日：2026-09-23。** 前面部品が入っていない状態です。写真の番号・掲載順は撮影時刻の順番を保証しません。

</details>

## 2026-09-24 — 土台の上へ、顔下部を組む途中記録

本人の言葉：**「こちらは組み立ての途中記録になります」。**
銘板・右ロゴを取り付けた土台の上へ部品を積み、顔下部の輪郭が立ち上がってきました。
以下は理解しやすい**説明順**です。添付順や元ファイルの時刻を撮影順・正式なCAD工程番号に変換していません。
同じ進捗を別角度から撮った写真も含みます。

**色も観察と設計を分けます。** 実写真では紫と黄色に見える部品があります。
設計データのマゼンタ／緑を変更したものではなく、この記録追加でSTL・BOM・3Dの配色を変えていません。
部品を探すときは[3D工程](../guide/index.html)や[工程表](STEPS.md)を参考にできますが、
写真だけで特定の`B-xxx`や正確な部品数・工程番号を認定しません。

### 1. 土台の上に、紫の低い横並び

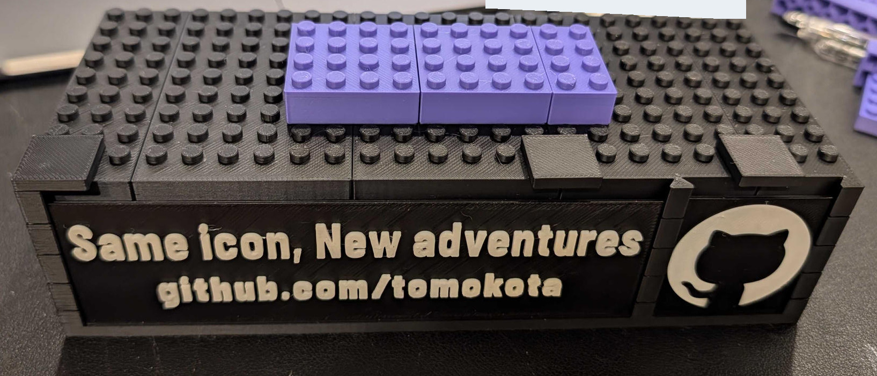
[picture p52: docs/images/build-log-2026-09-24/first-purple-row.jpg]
銘板と右ロゴのある台座の上へ、紫色の低いパーツが横並びに載った途中の状態


**報告日：2026-09-24。** 銘板と右ロゴの付いた土台の上に、
紫の低いパーツが横並びに載った状態です。
台座から顔側へ組立が進み始めた見え方として記録し、実際に何個追加したかは写真から補いません。

### 2. 黒い層と、紫の左右の段付き輪郭

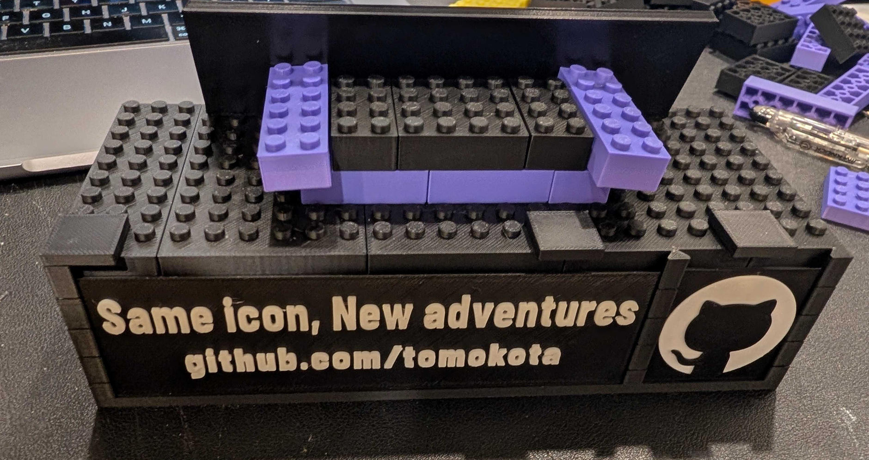
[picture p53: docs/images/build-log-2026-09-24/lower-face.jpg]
台座の上へ黒い層と紫の左右の輪郭を積んだ顔下部。背面の黒い板状物の用途は未確認


**報告日：2026-09-24。** 黒い層の左右に紫の段付き輪郭が見え、
顔下部が土台より上へ立ち上がってきた状態です。
写真で確認できるのはこの途中形状で、上部ゴーグルが完成した状態ではありません。

### 3. 黄色い縦2列が入った顔下部

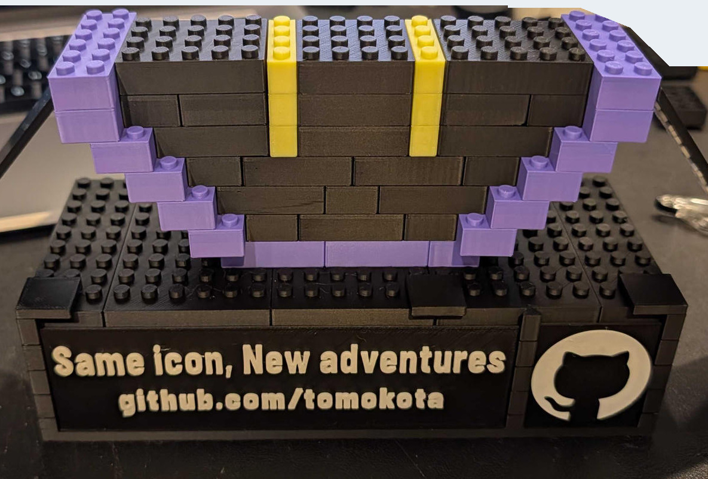
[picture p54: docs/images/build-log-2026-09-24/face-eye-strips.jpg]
黒い顔下部と紫の段付き輪郭の中に黄色い縦2列が見える途中写真。上部ゴーグルは写っていない


**報告日：2026-09-24。** 黒い顔下部の中に黄色い縦2列が見えます。
写真の見た目をそのまま記述しており、設計上の緑色の部品を黄色へ変更する指示にはしていません。
材料の銘柄や色名、使用した印刷ファイルの版までは未照合です。

### 4. その上へ黒い列を加えた状態

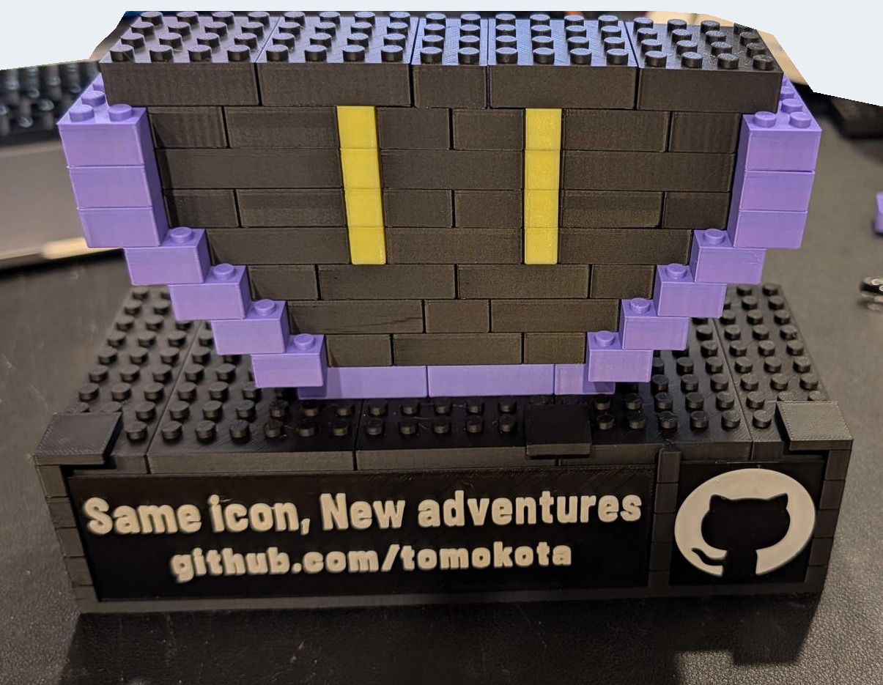
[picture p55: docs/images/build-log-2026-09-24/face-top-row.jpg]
黄色い縦2列の上に黒い横列がある顔下部の途中状態。上部ゴーグルと頭頂はまだ写っていない


**報告日：2026-09-24。** 黄色い縦2列の上に黒い列が加わった状態が写っています。
**9/24の記録**はここまでの顔下部の組立途中です。当日の写真には上部ゴーグル・頭頂は写っておらず、
全150部品の完成や模型全体の強度・保持・転倒の合格へ広げません。

<details markdown="1">
<summary>9/24の近い状態を、補足の3枚で見る</summary>

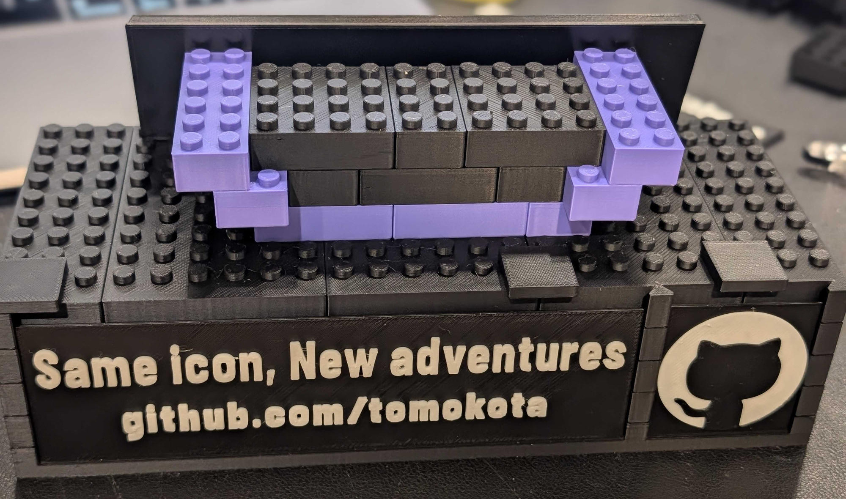
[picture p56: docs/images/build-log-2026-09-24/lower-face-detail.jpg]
黒い顔下部と紫色の段付き輪郭を近くから写した補足写真


**顔下部の詳細。報告日：2026-09-24。** 継ぎ目と左右の輪郭を見られる角度です。
上の写真と別工程だったとは断定しません。

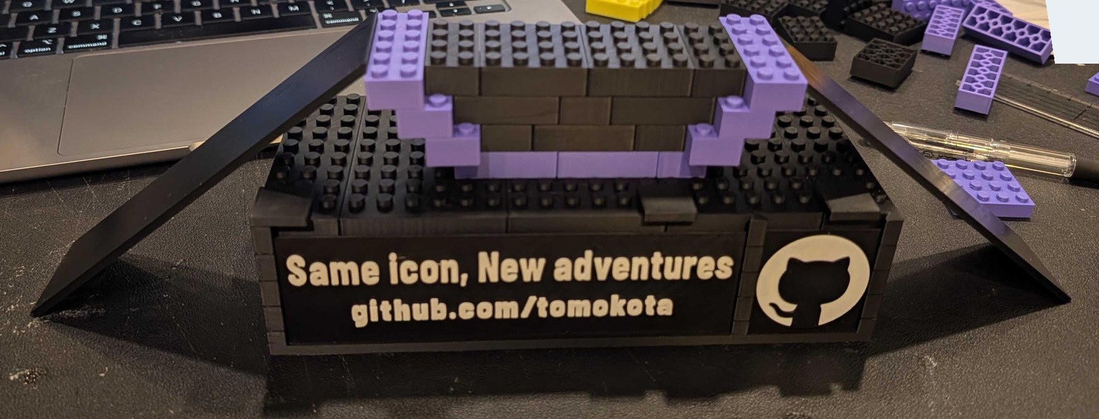
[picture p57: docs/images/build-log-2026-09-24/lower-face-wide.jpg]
顔下部を積んだ台座と、周囲に斜めに置かれた用途未確認の黒い板状物が写る補足写真


**少し離れた角度。報告日：2026-09-24。** 周囲の板状物も写っています。
その用途や固定方法を、写真から推定して部品表へ追加することはしません。

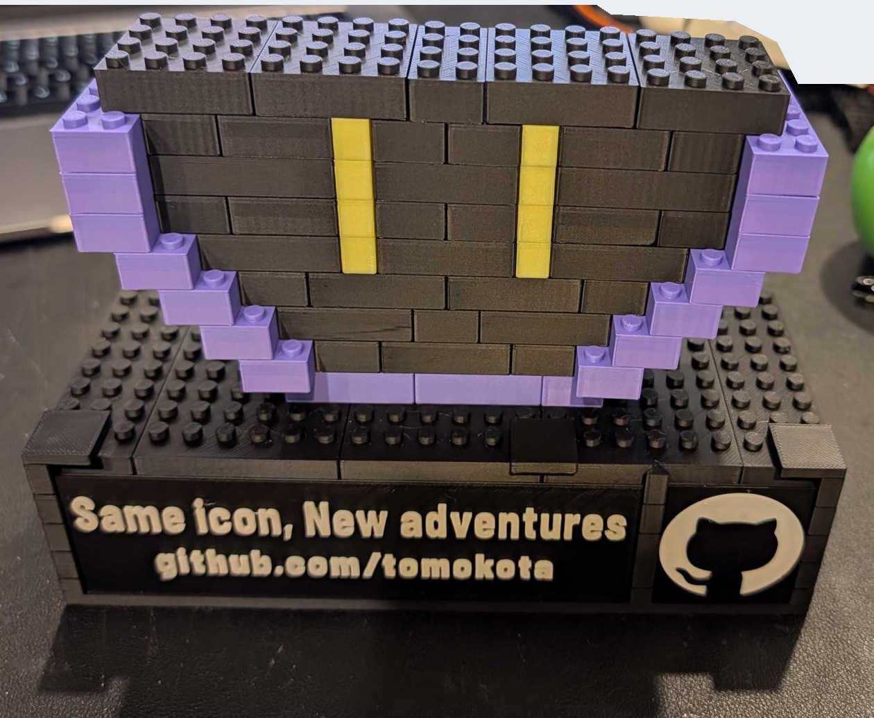
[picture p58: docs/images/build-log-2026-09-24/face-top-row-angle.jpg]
黄色い縦2列と上の黒い列がある顔下部を別角度から写した途中写真


**上の黒い列がある状態の別角度。報告日：2026-09-24。**
同じ進捗の補足写真として扱い、新しい独立した工程や完成写真には数えません。

</details>

#### 写り込みと未確認事項

一部には背面に立つ黒い板や、左右へ斜めに置かれた板状物も写っています。
用途・材質・固定方法は説明されていないため、保持具・構造部材・同梱パーツ・失敗対策等とは断定しません。
造形物やこれらの板状物を、写真から都合よく消す加工はしていません。

9/24時点で前の9/23記録から分かったのは、顔下部の実制作が途中まで進んだということです。
接着の有無、各接続の保持力、荷重、寸法公差、着脱寿命、実スライスとの版対応は引き続き未確認です。

## 2026-09-25 — ゴーグルを組み、頭頂までそろって完成

本人の言葉：**「制作過程の写真です」**、そして **「これで完成ですね」**。
前日の顔下部から、水色のゴーグル枠が立ち上がり、最後に上枠と紫の頭頂がそろいました。
文字の試作から一つずつ積み上げてきたBが、ついに形になりました。完成おめでとうございます。

以下は実写真でたどる4つの説明段階です。近い状態の別角度も含むため、
8枚を8つの正式なCAD工程とは数えず、撮影時刻や厳密な前後関係も推測していません。
日付はすべて**報告日2026-09-25**です。

### 1. 水色のゴーグル下縁と側支柱が加わる

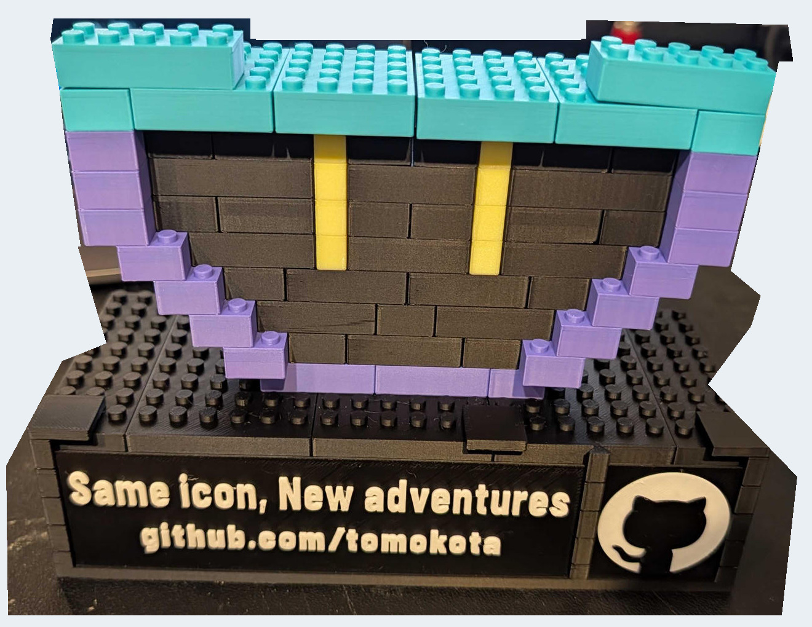
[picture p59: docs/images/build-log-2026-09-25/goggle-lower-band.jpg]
顔下部の上へシアン・水色のゴーグル下縁と端のブロックが加わった実物の途中写真。背景は切り取りとマスク処理済み


顔下部の上にシアン／水色の下縁が横に伸び、左右に支柱が立った状態です。
それまでの紫の輪郭と黄色い縦2列の上へ、ゴーグルの形が見えてきました。

### 2. 左右の黒い領域と中央の水色列を積む

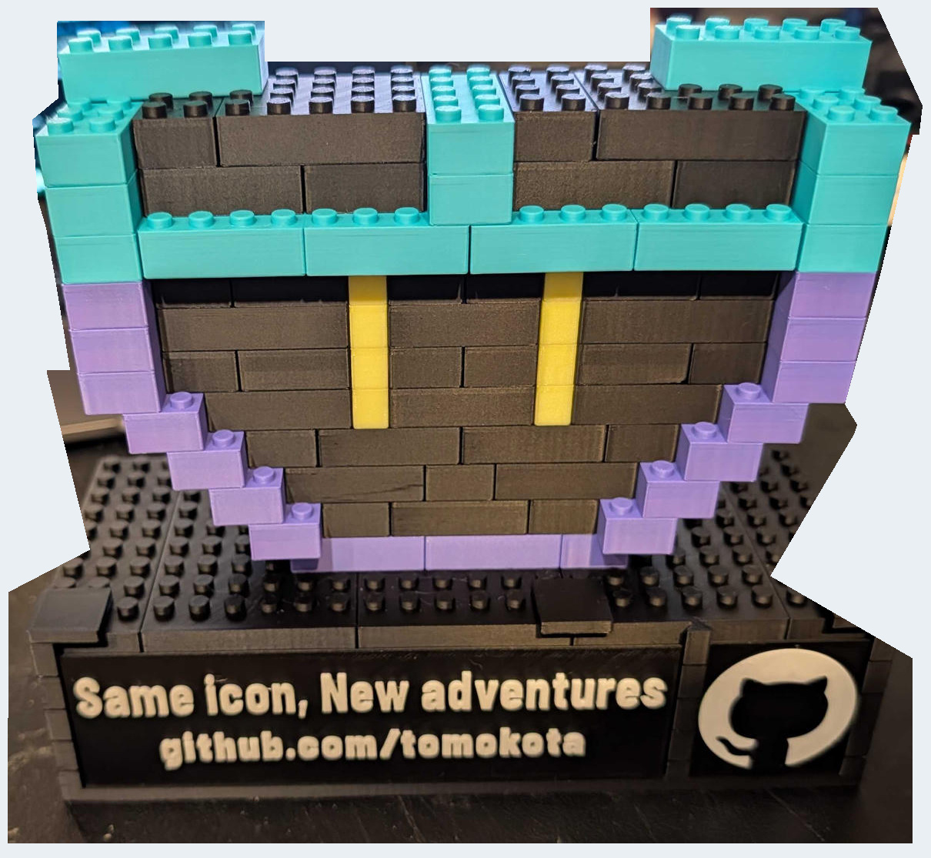
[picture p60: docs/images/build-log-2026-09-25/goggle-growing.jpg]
ゴーグル部分の左右の黒い領域と中央のシアン・水色の列が見える実物の途中写真


左右の黒い領域と、その間のシアン／水色の列が高くなる途中です。
外周と中央の列を見比べながら、顔の上半分が立ち上がっていく様子を記録します。

### 3. 上部が開いた、高いゴーグル枠

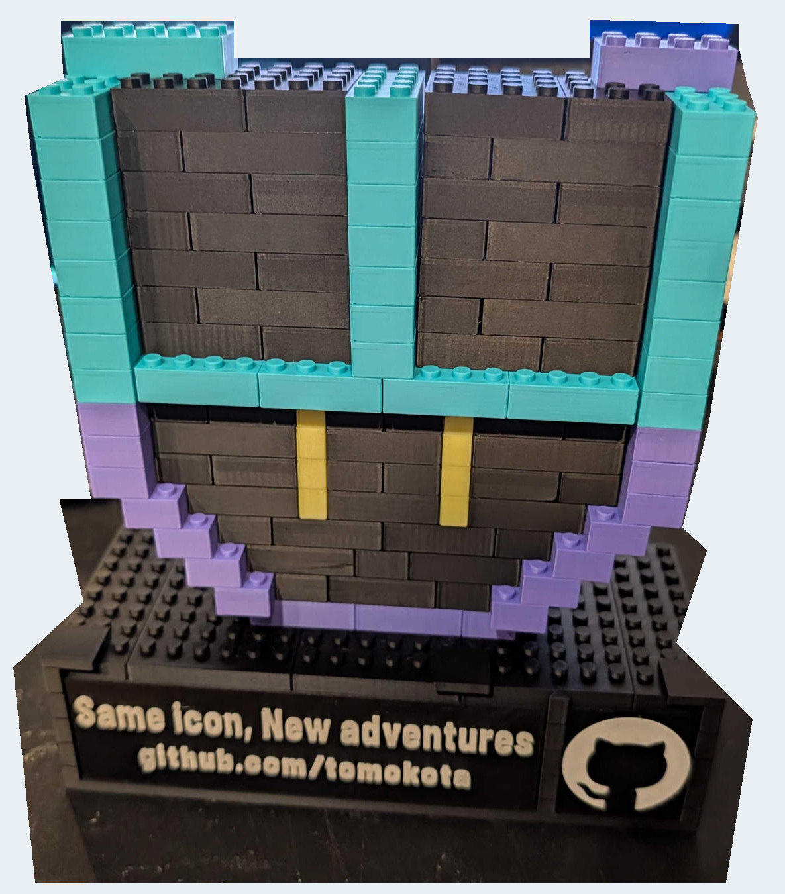
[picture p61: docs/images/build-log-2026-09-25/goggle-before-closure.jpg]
左右の黒い面とシアン・水色の側面と中央列が高くなった、上枠を閉じる前の実物写真


側面と中央が高くなり、まだ上部が開いている状態です。
仕上げの上枠を取り付ける前の姿として、完成写真と並べて見ることができます。

### 4. 上枠と紫の頭頂までそろって完成

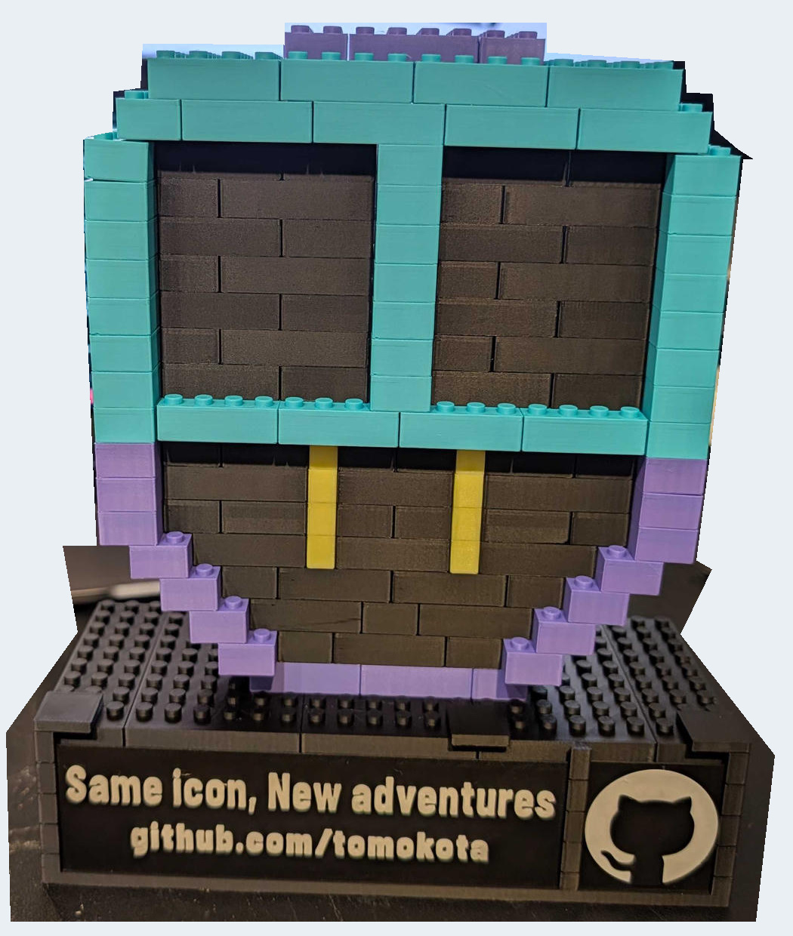
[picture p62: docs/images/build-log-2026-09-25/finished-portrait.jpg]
9/25の実物完成写真。ゴーグル上枠と紫の頭頂、顔、台座、個人銘板、右ロゴまでそろった姿。背景は切り取りとマスク処理済み


ゴーグルの上枠が閉じ、紫の頭頂パーツまでそろっています。
銘板と右ロゴのある台座から頭頂まで写った姿と、本人の「これで完成ですね」という言葉を、
今回の完成記録として残します。

**実物の完成写真です。** 背景PC画面などを隠すため、輪郭の周囲に薄グレーの不透明マスクが入っています。
撮って出しではありませんが、模型の色・印刷線・糸・隙間を修復したり、CGで補完したりしていません。

<details markdown="1">
<summary>9/25の組立過程を、補足の4枚で見る</summary>

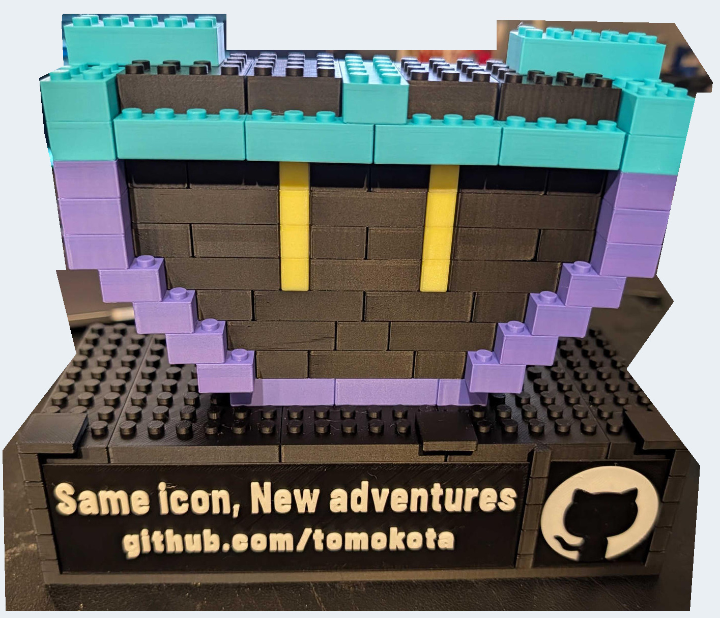
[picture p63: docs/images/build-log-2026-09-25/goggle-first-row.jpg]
シアン・水色の下縁と側面、中央列の間へ黒い上部ブロックを積んだ補足写真


**下縁から上へ。報告日：2026-09-25。** 側面と中央の列の間に黒いブロックが見えます。
正式な工程番号を決めるためではなく、この時点の見え方を残す写真です。

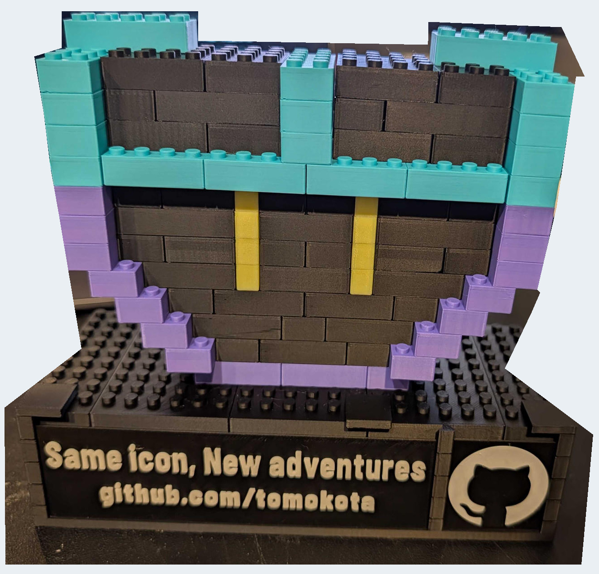
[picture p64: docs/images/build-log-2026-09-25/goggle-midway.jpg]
左右の黒いブロックとシアン・水色の縁を別角度から見たゴーグル組立途中の補足写真


**左右の領域を別角度から。報告日：2026-09-25。**
似た状態の写真もあり、それぞれを独立した工程とは数えていません。

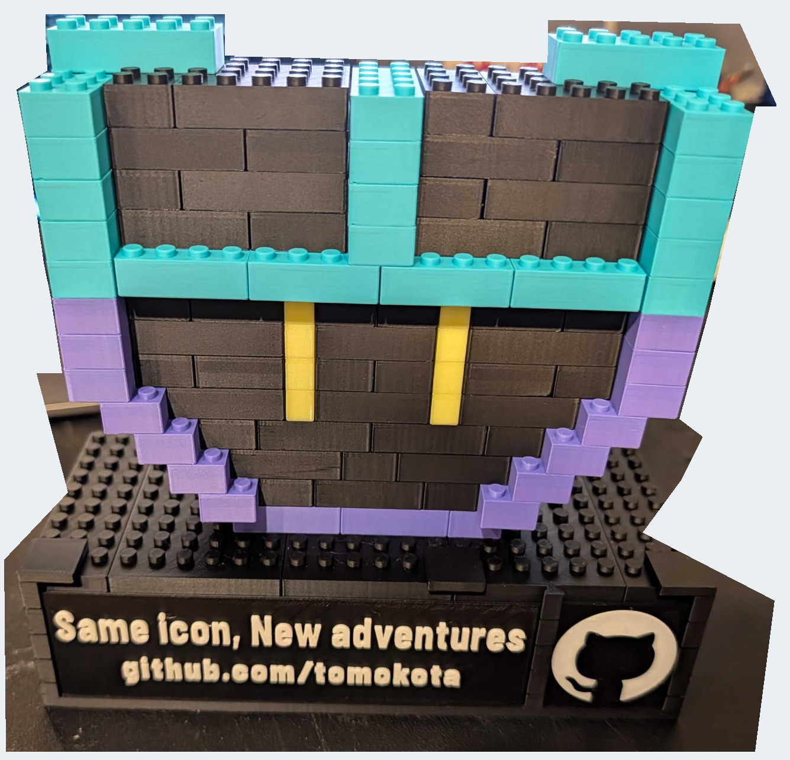
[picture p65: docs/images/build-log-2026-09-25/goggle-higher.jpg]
黒い左右の面と中央のシアン・水色の列が高く積まれ、上枠がまだ開いている途中写真


**高くなったゴーグル部分。報告日：2026-09-25。**
黒い面と中央の列が上へ伸びています。上枠を閉じる前の姿です。

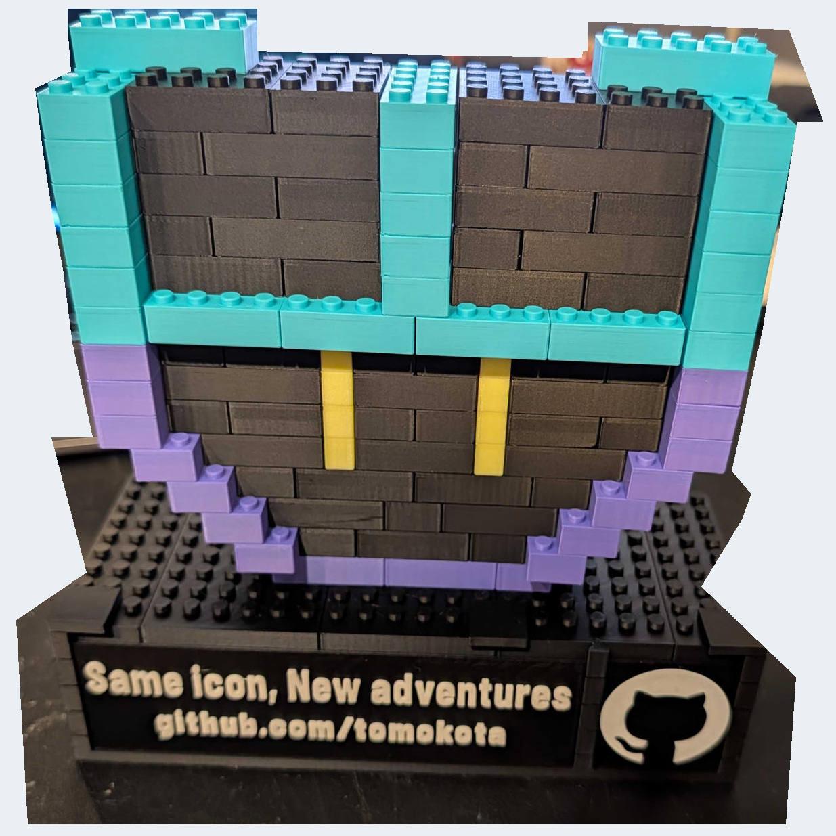
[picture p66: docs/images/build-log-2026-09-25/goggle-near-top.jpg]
高くなったゴーグル部分を写した、頭頂を仕上げる前の実物の補足写真


**頭頂の仕上げ前。報告日：2026-09-25。**
完成写真に至る途中の姿として残しています。掲載順は撮影時刻の証明ではありません。

</details>

写真の紫・黄色は実制作の配色です。設計データのマゼンタ・緑を書き換えたものではありません。
画面の完成CGは引き続きCGとして区別し、ここには実物写真を掲載しています。

#### 3. 3Dプリント — 設計したパーツを印刷する

公開タイトル：**AIでLEGO風ブロックを設計して3Dプリント｜GitHub Copilot × FreeCAD × Blender**

ユーザーが「3Dプリントの動画」として提供した、今回の印刷工程の映像です。
Web版では上のプレイヤーで**▶を押してページ内再生**できます。自動再生はしません。
続く超音波洗浄との並びは制作フローの説明順で、撮影順や実経過時間を証明するものではありません。

**視聴にはインターネット接続が必要です。** GitHub上のMarkdownや保存版からは、
<a href="https://ktanino10.github.io/copilot-brick-gift-b/docs/BUILD-LOG.html#printing-video-2026-09-25" target="_blank" rel="noopener noreferrer">Web版の3Dプリント動画をページ内で見る</a>。
<a href="https://youtu.be/sinN3dKGwRg" target="_blank" rel="noopener noreferrer">埋込みで再生できない場合はYouTubeで開く（補助リンク・新しいタブ）</a>。
公開タイトルは確認されていますが、動画から印刷設定・時間・材料量を推測して記録していません。

#### 4. 超音波洗浄 — 今回の印刷後の後処理

公開タイトル：**3Dプリント後のパーツを超音波洗浄｜Ultrasonic Cleaning of 3D-Printed Parts**

Web版では、この場所のYouTubeプレイヤーの**▶を押してページ内で再生**できます。自動再生はしません。
**視聴にはインターネット接続が必要です。** プレイヤーの読み込み・視聴時にはYouTubeへ通信し、
環境により同意や接続の確認が表示されることがあります。

GitHub上のMarkdownや保存したオフライン記録からは、
<a href="https://ktanino10.github.io/copilot-brick-gift-b/docs/BUILD-LOG.html#post-processing-ultrasonic-2026-09-25" target="_blank" rel="noopener noreferrer">Web版のページ内プレイヤーで見る</a>。
ファイルを直接開いた場合も写真と3Dは通信不要のままで、動画だけはWeb版で視聴してください。

<a href="https://youtu.be/Lc_enNE3nng" target="_blank" rel="noopener noreferrer">埋込みで再生できない場合はYouTubeで開く（補助リンク・新しいタブ）</a>

ユーザーが今回の制作工程として示した「3D Print後の超音波洗浄」の動画です。
洗浄条件や結果をこちらで確認したものではなく、どの模型にも必須という案内や検証済みの洗浄レシピではありません。
上の写真に洗浄の様子が写っているという意味でもありません。

動画本体やサムネイルのファイルをキットへコピー・再配信していません。
保存版には外部プレイヤーを埋め込まず、オフラインの写真読込みをYouTubeへ依存させていません。

## CLI風アレンジ（実物写真）

ブロックを変更してCLI風にアレンジした実物です。**標準配布モデルとは異なるアレンジ例です。**
シアンのゴーグル枠、黒い顔、マゼンタの輪郭と緑色の目が見えます。

CLI風にアレンジした実物のブロック模型。シアンのゴーグル枠、黒い顔、マゼンタの輪郭、緑色の目と黒い台座。背景モニターの文字部分はマスク処理済み

**追加日：2026-09-30（JST）。撮影日は未確認です。**
標準モデルのCAD・STL・3MF・3D組立順は変更していません。
写真だけで、全部品が配布STLと同一であることや、嵌合・強度・転倒への安定性を確認したものではありません。

## 学びと、次に残る確認

実物の文字相談から設計を見直し、その後に手応えの報告と台座・前面の写真、
9/24の顔下部の途中、9/25のゴーグル・頭頂と完成へ続く制作の流れを残しました。
写真と本人の言葉を通して、部品が少しずつ模型になっていく過程を振り返れます。

| 残した実制作の記録 | 記録の位置づけ |
|---|---|
| 文字の相談、改訂と試作についての手応え | 本人の感想と実写真。印刷条件による効果の測定とは別 |
| 土台と前面、顔下部、ゴーグルの組立過程 | 日付別の写真観察。写真番号を正式CAD工程や撮影時刻に置き換えない |
| 上枠と紫の頭頂までそろった写真と「これで完成ですね」 | 本人の完成報告と、完成した姿の実制作記録 |

**設計・測定との区別：** 完成の報告を、写真だけで150個を個別検品した結果、
寸法・荷重・耐久・転倒の測定合格、使用STL／実スライスの版・hash照合とはしていません。
それらの記録は未提供です。制作の完成を否定するものではなく、記録の種類を分けています。
この制作記録の追加で、STL・3MF・native・150配置や、黒→白の境界を変更していません。
配布データは引き続き**NOT_SLICED**です。
作業を進める際は[印刷手順](PRINTING.md)・[少量試作](TRIAL.md)・[組立手順](ASSEMBLY.md)を参照し、
強い力、白化・割れ、着座不良や保持不足があれば止めてください。

## 写真の取扱い

写真の権利はユーザーに帰属します。今回の掲載許可は、モデル・フォント・ソフトウェアのライセンスを
写真へ自動適用したり、第三者へ包括的な再利用権を与えたりするものではありません。
この個人版には許可された銘板の文字を残し、無関係な背景を可能な範囲で切り取っています。
2026-09-23の追加承認により、個人版repoとこの案内ページも公開対象になりました。
一般向けrepoの伏字画像とは別系統です。加工前の原画像・EXIF・監査元パスは公開しません。

9/24の新しい7枚についても、個人版は銘板の文面を残し、一般向け版は個人URLを伏せ、
両方で背景PC画面と撮影メタデータを除去する形での掲載を、本人が別途承認しています。
親担当が一度だけ加工した派生をそのまま取り込み、このrepo内で再加工していません。
9/25の制作過程・完成の8枚も、同じ公開範囲で制作記録へ追記することを本人が承認しています。
背景の切り取り・必要なマスクなどの加工内容は、各日のmanifestに記録しています。

9/30のCLI風アレンジ写真1枚は、このrepoと既存Pagesへの追加として提供されました。
背景モニターの文字部分だけを不透明にマスクし、模型本体は修整せず、Web向けに縮小・JPEG化してメタデータを除去しています。
原画像は変更していません。

このページに含むのは加工済みの実写真**25枚（9/23までの9枚＋9/24の7枚＋9/25の8枚＋9/30追加の1枚）**です。元ファイル名・EXIF・位置・カメラ情報、
加工前の原画像、監査用の元パス対応表は収録していません。
[9/23までの画像一覧](images/build-log-2026-09-23/manifest.json)、
[9/24の画像一覧](images/build-log-2026-09-24/manifest.json)、
[9/25の画像一覧](images/build-log-2026-09-25/manifest.json)、
[9/30追加の画像一覧](images/build-log-2026-09-30/manifest.json)には、
中立ID・報告日・寸法・配布画像のhash・回転／切り取り／メタデータ除去の範囲など、
配布用の情報を記録しています。
写真のスライドショーを実組立動画と称していません。

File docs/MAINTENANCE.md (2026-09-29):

# 検証と保守

[入口](../README.md) · [出典](PROVENANCE.md)

印刷するだけ、または3Dガイドを見るだけなら、このページのPython・Node・FreeCADコマンドは不要です。
ZIPを展開して`guide/index.html`をダブルクリックし、[印刷手順](PRINTING.md)を使ってください。
ここは梱包・整合性を確認する人向けです。

## 確認できる範囲

| 確認 | 記録・方法 |
|---|---|
| 150個、21形状、23 BOM行、14枚3MF、28工程 | [kit.json](../verification/kit.json)／`scripts/verify_kit.py` |
| STLの閉鎖、辺の向き、頂点manifold、単一連結、正体積 | 同上。B21＋fit12＋接続試作1＝34 masterに、別の文字試験片1を追加 |
| 3MFの実ジオメトリ・数量・色・配置・Z=0 | XMLを再読込し、対応STL・BOM・manifestと照合 |
| 個人Bのnative再open | [native.json](../verification/native.json)。150配置、正確な2行、外形・銘板寸法、銘板干渉候補 |
| 元担当の取付け確認 | [引継ぎnative記録](../verification/inherited-plate-native.json)。元のキャリアとの対称差0 |
| 手順・画像・PDF・ZIP | 相対リンク、個人PDF、SHA-256、ZIPの欠落・重複、機器情報／ローカルパスの混入を点検 |
| 全150slotと全150配置の双方向対応 | `scripts/verify_guide_mapping.py`。全14実3MFの順番・位置、全候補、便宜割当、23 part/color群、工程、寸法、STLのbyte一致 |
| オフライン3Dの実ブラウザ操作 | [guide-browser.json](../verification/guide-browser.json)。通信遮断したChromiumで150組の双方向対応、14枚と23部品ID／色群の実選択、28工程、再生停止、90度姿勢、320〜1440 px、keyboard、カメラの枠内表示 |
| ガイドの通信不要・配布資源 | `scripts/verify_offline_html.py`。classic runtime／CSS／meshを埋込、外部active resourceなし、CSP `connect-src 'none'` |

3MF配置の256×256 mmと6 mmブリム余地の確認は**公称ベッドのデジタル検査**です。
実機の除外領域、校正線、ヘッド干渉、実ツールパスの保証ではありません。
配布データは`NOT_SLICED`です。実制作写真と本人報告は[制作記録](BUILD-LOG.md)へ分け、
正式な物理評価や使用版・スライス条件の照合が未提供であることを維持してください。

制作記録だけを更新する場合は`build_photo_log.py`→`verify_build_log.py`→通常の梱包・検査を実行します。
写真は登録したメタデータ除去済み派生をbyte不変更で扱い、元画像を配布へ含めません。
3Dへの固定ナビゲーションを除いたHTMLが過去の検証済み文書とbyte一致することを確認し、
以前の全工程・CG媒体の検査記録は書き換えず、新しい写真／リンク／オフライン検査を別記録に残します。
この文書だけの変更で、STL・native・全CGアニメーションを再生成する必要はありません。

2026-09-23の写真記録追加時はローカルブラウザの起動環境が利用できず、
今回の実ブラウザ検査を`NOT_RUN_ENVIRONMENT`として別記録にしています。
承認済みの`verify_build_log.py --static-only`で、9画像の実decode・メタデータ・hash、
文書とローカル画像リンク・標準レスポンシブCSS・固定ナビゲーションだけの変更・61入力hash不変を確認しました。
従来の3DブラウザPASSを新しい制作記録のブラウザPASSに読み替えていません。
公開後のPages検査は既存Linux CIで行い、日付別の追記ではHTTP版に加えて
ネット切断したローカルHTMLの画像読込み・往復操作も同じ安全なrunnerで確認します。
macOSで複数ブラウザの起動を繰り返したり、権限・停止機構を回避したりしません。

写真は`build_photo_log.py`の承認済み日付別batch一覧で指定し、元のmanifestのhashを保持します。
9/23の9枚と9/24の7枚を置き換えず、9/25の8枚を別folderへ追加します。
9/30にはCLI風アレンジの1枚を別folderへ追加し、既存24枚はそのまま保持します。
新しい写真は背景モニターの文字部分だけをマスクし、縮小・JPEG化とメタデータ除去を行った派生です。
日付は追加日（JST）で、撮影日や標準配布STLとの一致を示しません。
メタデータ・リンク・全25画像の実decodeを確認し、追記前に保存した155件の
印刷／native／図面／3D媒体／旧写真のhashと照合します。
標準モデルの完成記録は`BUILD-LOG.html#progress-2026-09-25`、
アレンジ写真は`BUILD-LOG.html#cli-arrangement-2026-09-30`です。9/24のanchorも維持します。
9/30の追記ではローカルChromiumで25枚の読込み、375 px幅、既存3Dから写真への往復を確認しています。
今回の結果は`verification/build-log.json`に記録し、以前の3D全工程検査とは分けています。

3Dプリントと超音波洗浄の動画は公開Pagesの各小節だけに、別々の公式`youtube-nocookie.com`プレイヤーを埋め込みます。
保存版の写真ログにはiframeを入れず、オンラインの同小節への案内と補助リンクだけを残します。
公開ページだけが限定した`frame-src`とreferrer設定を持ち、写真・3D自体のオフライン条件は変えません。
Pages配信後に`verify_youtube_player.py`が2本の実プレイヤー表示と通常の再生・停止操作をまとめて観察します。
YouTube側の同意・アクセス・動画提供の制限は正確な表示とともに記録し、
iframeの存在や見た目だけを再生成功と扱いません。

## ファイルを照合する

展開したルートの `SHA256SUMS.txt` は、配布内容のハッシュ一覧です。
WindowsではPowerShellの `Get-FileHash`、macOS/Linuxでは `shasum -a 256` 等で
個別ファイルを確認できます。例：

```powershell
Get-FileHash .\kit\B\parts\NP3-TEXT-B.stl -Algorithm SHA256
```

```bash
shasum -a 256 kit/B/parts/NP3-TEXT-B.stl
```

期待する新版銘板SHA-256は[現行一覧](../SHA256SUMS.txt)の
`kit/B/parts/NP3-TEXT-B.stl`と照合します。旧版のhashを新版の合格値にしません。

今回の可読性改訂は[変更説明と測定値](NAMEPLATE-V2.md)を参照してください。
`requirements-cad.txt`は図面をまとめ直すReportLab／svglib／pypdfと、輪郭測定のShapely／SciPyを追加します。
変更したのは銘板1形状だけで、元の20形状／13プレート／150配置の不変を別途検査します。

ZIP自身のハッシュは、GitHub上の
[downloads/SHA256SUMS.txt](https://github.com/ktanino10/copilot-brick-gift-b/blob/main/downloads/SHA256SUMS.txt)
にあります。ZIPの中へ同じZIPを入れた二重配布はしていません。
ZIPを展開した後のダウンロードリンクだけは認証付きGitHubの入口であり、
組立・試作・図面・sourceのリンクは展開フォルダ内で完結します。

## 梱包と検査をやり直す

検証用Pythonライブラリは [requirements-verify.txt](../requirements-verify.txt)。
`pdftotext`（Poppler）も使います。FreeCADのnative検査は、別途FreeCAD 1.1.3の
対応Pythonとライブラリを使用しました。アプリ本体は同梱しません。

必要なライブラリがない場合だけ、専用仮想環境へ導入します。

```bash
python3 -m venv .venv
.venv/bin/python -m pip install -r requirements-verify.txt
```

梱包を更新する順序：

```bash
.venv/bin/python scripts/build_b_guide.py
.venv/bin/python scripts/verify_guide_mapping.py
.venv/bin/python -m unittest discover -s scripts -p 'test_*.py'
npm run test:guide-model
.venv/bin/python scripts/verify_guide_browser.py --capture --write-report
.venv/bin/python scripts/build_print_kit.py
.venv/bin/python scripts/verify_kit.py --write-report
.venv/bin/python scripts/build_print_kit.py
.venv/bin/python scripts/verify_kit.py
.venv/bin/python scripts/verify_extracted_guide.py
```

最初の梱包を検査して報告を書き、その報告を含めて梱包・ハッシュを確定し、
最後は書き換えず再検査します。ZIPは固定のmember順・時刻で作ります。
各ZIP memberは相対パスで、B以外の模型、重複するmaster、nested ZIPを含みません。
文字試験片は`samples/nameplate-v2/`に別区分で入れ、150個の組立プレートへ加えません。
revision付きの旧銘板や未選択の候補フォルダは現行印刷ZIPの収録対象外です。
生成ファイルは `guide/index.html`／`index.mapping.json`、実ビューアのPNG／GIF、
`docs/FILES.md`、`docs/STEPS.md`、`kit/B/steps.csv`／`part-map.csv`、
`kit/manifest.json`、検証記録、ハッシュ一覧、全キットZIPです。
manifestは印刷データのinventoryに加え、HTMLとmappingのbytes／SHAも持ちます。
HTMLを変更した後で古いbrowser検証を流用すると、entry hashが一致せず梱包検査が停止します。
最後の`verify_extracted_guide.py`は、生成ZIPを一時フォルダへ展開してブラウザで開き、
さらにHTMLだけを日本語・空白を含む別名へコピーして再確認します。
ネット遮断下で最初の1個と全150個を表示し、一時フォルダは終了時に削除します。

### ガイド生成・撮影の依存を用意する場合

必要なパッケージがない場合だけ、[requirements-guide.txt](../requirements-guide.txt)を使用します。
既存の検証用依存にPlaywrightとPillowを加えたもので、閲覧用PCへの導入は不要です。

```bash
.venv/bin/python -m pip install -r requirements-guide.txt
.venv/bin/python -m playwright install chromium
```

ブラウザ検査は独立したheadless Chromiumを使い、ユーザーの開いているブラウザを操作しません。
通信をofflineにし、HTTP／HTTPS／WebSocketを記録・遮断して要求0を確認します。
`--capture`で出力する画像・GIFは同じビューアの実renderです。中間フレームは配布しません。
`--entry`には展開ZIP内の別の`guide/index.html`も指定できるため、梱包後の実ファイルを検査できます。
成功時のみ`--write-report`で記録し、通常の検査はファイルを変更しません。

同梱ランタイムは`web/assembly-guide/runtime.js`です。コードを変更せず、入力を反映し直すだけなら
`build_b_guide.py`がこれを使うため、Nodeでのbundle作成は不要です。
共通viewerコードを更新する場合だけ、[package.json](../package.json)とlockのexact依存で再bundleします。
Three.js 0.180.0はMIT、esbuild 0.25.10はbuild用です。

```bash
npm ci --ignore-scripts --no-audit --no-fund
npm run build:guide-runtime
```

その後に上記のガイド生成・browser撮影・梱包検査を一巡します。
共有sourceの取り込みは明示されたファイルだけを読み、自分のworktreeでbuildします。
公開側へ個人データを渡したり、他worktreeでbuildしてはいけません。

### nativeを再openする

`FREECAD_PYTHON` をFreeCADに対応する埋込Python、
`FREECAD_LIB` を同じインストールのモジュールディレクトリへ設定してから実行します。
個人端末の絶対パスをこのリポジトリへ書き込まないでください。

```bash
mkdir -p .work
FREECAD_USER_HOME="$PWD/.work/freecad-profile" \
QT_QPA_PLATFORM=offscreen OMP_NUM_THREADS=2 \
PYTHONPATH="${FREECAD_LIB:?Set the matching FreeCAD library directory}" \
"${FREECAD_PYTHON:?Set the matching FreeCAD Python executable}" scripts/verify_native.py
```

これは専用プロセスでファイルを読んで閉じる検査です。
ユーザーが開いているGUI documentや他のworktreeを操作しません。
`FreeCAD` を先にimportしてから `Part` をimportします。
nativeをsave／saveAsせず、検査前後のhash一致も確認します。
寸法はtrimmed面の過大なBoundBoxを避けて `optimalBoundingBox` を使います。

`--refresh-catalog-metadata` は、既存nativeから銘板と全体の計算済みメタデータを
更新する保守オプションです。形状は生成しません。通常の再検査には不要です。
使用後は上記の梱包・検査をやり直してください。

### 元の配置計算だけを確認する

```bash
python3 source/scripts/design.py --output .work/new-layout-check
```

新しい未使用フォルダが必要です。Bと確定した2行以外は受け付けず、
配布source内のファイルへ上書きしません。
共通のgeometry builderと寸法sourceは保管していますが、このコマンドだけで
全CAD・PDF・3MFを再生成したことにはなりません。
機構や寸法を変える場合は、今回の「同形状再利用」の検証範囲外です。
旧STLと混ぜず、変更範囲を定めて別途再検証・試作してください。

## 承認された公開先へ保存する

2026-09-23のユーザー承認後は、この個人向けrepoをpublicにしてPagesを使用します。
uploadの直前に、remoteのfetch／push先がこの独立repoだけであること、
`private=false`、`visibility=public`、`has_pages=true`、`fork=false`と明示公開方針を照合します。

```bash
python3 scripts/check_repository_target.py
```

既存の一般向けrepoへ個人ファイルを二重コピーしません。ReleaseやMakerWorldの操作も別範囲です。
`.github/workflows/pages.yml`は、選別した`_site`だけを検査してPagesへ配信します。
リポジトリのルート、未追跡データ、session資料をPages artifactへアップロードしません。
通常のnonforce pushの直前にも、この確認を行います。

Pagesの再生成は以下です。ローカルのブラウザ起動が利用できない場合も、
実ブラウザの結果を捏造せず、GitHub ActionsのLinux検査と実配信を確認します。

```bash
python scripts/build_recipient_site.py
python scripts/verify_recipient_site.py
```

公開前の許可・履歴点検・除外範囲は[公開方針](../publication/README.md)に残しています。

native・図面の保存先を変更しても、機器のtoken・ID、Bambuの実設定入りプロジェクト、
人物写真・会話履歴をそのまま追跡対象へ追加しないでください。
実機の診断に必要なデータは内容と共有先を別途確認します。

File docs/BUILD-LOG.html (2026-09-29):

# Bの制作記録 — 文字試作・土台から完成まで

3D工程へ · 印刷手順 · 組立手順 · 銘板の設計改訂

2026-09-30（JST）追加：CLI風アレンジの実物写真。 ブロックを変更した、標準配布モデルとは異なるアレンジ例です。これまでの制作・完成写真も残しています。

2026-09-25、完成しました。 「制作過程の写真です」に続き、「これで完成ですね」とご報告いただきました。 ゴーグルの上枠が閉じ、紫の頭頂パーツまでそろった姿を、実物の完成記録として残します。 9/25の完成までの写真へ進むか、文字試作から順に読めます。 前の16枚を保持し、この日の8枚を加えて9/25までの写真は24枚になりました。

前の記録：2026-09-24、顔下部の組立途中。 本人の言葉は「こちらは組み立ての途中記録になります」でした。 9/24の節は、その日に届いた途中の状態として残しています。 当時の写真には上部ゴーグル・頭頂はまだ写っていません。

前の記録：2026-09-23、「土台が組み上がりました」との報告。 黒い台座、前面の空き溝、右ロゴを入れた状態、2行の個人銘板と右ロゴがそろった状態を、 ユーザー提供の実写真で記録します。ここまでの実制作の節目であり、 顔・ゴーグル・150部品すべての完成写真ではありません。

写真は各回の掲載許可を得て、必要な向き・切り取りを整え、元のメタデータを除去したものです。 一部写真には、無関係な背景PC画面などを隠す不透明マスクもあります。 造形の欠点・部品の段数・装着状態を変える合成はしていません。 各節の日付は報告日または追加日です。撮影日時や撮影順は未確定で、 別角度の写真がすべて別の工程・別の日を表すとは限りません。

## 今回の制作は5工程

ユーザーが示した制作の流れは、企画 → 設計 → 3Dプリント → 超音波洗浄 → アッセンブリー（組み立て）です。 下の工程案内から設計資料・ページ内動画・実物写真へ進めます。写真の日付別記録は、そのまま下に残しています。

工程 | 今回の内容 | 見るもの
1. 企画 | 贈って卓上に飾る模型の形・用途・大きさを考える | 企画・仕様
2. 設計 | FreeCADで分割・取付けを設計し、CG・図面と銘板改良を確認 | 設計資料
3. 3Dプリント | 設計したパーツを印刷する工程 | ページ内の印刷動画
4. 超音波洗浄 | 今回の印刷後の後処理 | ページ内の洗浄動画
5. アッセンブリー | 土台から顔・ゴーグル・頭頂まで組む | 実写真と3D工程

#### 企画 — 飾る形と贈る内容を考える

卓上に飾るBモデルとして、形・用途・大きさと、2行の個人銘板を検討しました。 選んだモデルの仕様は案内トップにまとめています。

#### 設計 — 実形状・分割・完成像を確認する

FreeCADで部品の実形状と分割・取付けを設計し、Blenderを使った設計段階のCGなどで完成像を確認しました。 その後の銘板の可読性改良は、現行のCAD・図へ反映しています。 寸法・組立図と出典・現行CGの作成方法を参照できます。 設計CGと、ここに掲載する実物写真は別の資料です。

#### アッセンブリー — 積み上げて完成へ

部品を探せる3D組立ガイドと、 9/25の完成までの実写真で、土台からゴーグル・頭頂までをたどれます。 制作過程を振り返る写真と、次に作る人が使う設計上の組立手順を行き来できる構成です。

## ここまでの流れ

報告日・追加日 | 本人の報告・写真で確認できること | 設計変更・未確認事項
2026-09-22 | 文字が小さく、隙間が狭くて印刷しにくそうとの相談。白文字の糸や表面の荒れも見える。使用ノズルは本人回答で0.2 mm | 2行を維持する方針で改訂。写真だけから流量・温度・乾燥状態の原因や補正値は決めていない
2026-09-23 12:09 | 銘板2枚の写真と「いけているみたい」との報告 | 改訂後の試作についての手応えとして記録。2枚の旧・新版対応、STLや実スライスの版・hashは未照合
2026-09-23 12:18 | 「土台が組み上がりました」との報告。積層・継ぎ目・前面部品を取り付けた台座が写っている | 取付状態の写真はあるが、接着の有無、保持力、実測寸法、着脱回数、荷重・転倒の評価結果は未提供
2026-09-24 22:27 | 「こちらは組み立ての途中記録になります」との報告。土台の上の紫・黒の層、左右の段付き輪郭、黄色い縦2列が見える | 顔下部の途中記録。正確なCAD工程番号・部品数・撮影順・使用ファイル／実スライス版は未照合。上部ゴーグル・頭頂・全体完成は未確認
2026-09-25 | 「制作過程の写真です」に続き「これで完成ですね」との報告。水色のゴーグル枠を組み、上枠と紫の頭頂までそろった姿が見える | 本人の完成報告と実物写真を記録。設計値や個々の部品検品、使用データの版・実測試験とは区別する
2026-09-30（追加日） | ブロックを変更してCLI風にした、との本人説明と実物写真1枚 | 標準配布モデルとは異なるアレンジ例。標準の設計・印刷データは変更せず、撮影日や使用部品の版対応も推測しない

## 9/22〜23 — 文字試作と台座の記録

### 1. 最初の文字試作で、余裕の少なさが見えた

2026-09-22の文字相談に添えられた銘板。白文字の狭い孔や字間、糸状の樹脂と表面の荒れが見える

報告日：2026-09-22。 2行の銘板を実際に作ったことで、 画面の見え方だけでは分かりにくかった文字内の孔・字間・表面の状態を確認するきっかけになりました。 0.2 mmノズルという情報は、この相談時の本人回答です。他の写真すべての印刷条件を示すものではありません。

その後、ユーザーは2行を維持し、下段を少し大きく、上段の孔に余裕を持たせ、 白い文字を厚くする方針を選びました。採用した設計は 上段12 mmを維持、下段8→10 mm、白の浮彫0.8→1.2 mm、黒2.4 mmと取付け基材は不変です。 これは設計の値で、写真から現物を測った結果ではありません。

### 2. 改訂後、銘板の試作について手応えの報告

2026-09-23の追加写真。2行の個人銘板が上下に2枚並んでいる。各板の版対応は未照合

報告日：2026-09-23。本人の言葉：「いけているみたい」。 2枚の実物が並んだ写真と、制作が進められそうという手応えが届きました。 上・下のどちらを旧版／新版と呼べるかは未照合なので、断定ラベルは付けません。 この報告を、特定のSTL版の印刷合格や、糸引き・表面荒れの完全解消とは扱いません。

### 3. 黒い台座の積層・継ぎ目と、前面の空き領域

積み重ねた黒い台座。上面のスタッド、ブロックの継ぎ目、前面の空いた銘板用とロゴ用の領域が見える

報告日：2026-09-23。 台座の積層と継ぎ目、上面のスタッド、 前面部品を入れる領域が見える写真です。 「ファイルを印刷する」から「台座の形に組む」へ進んだ様子が分かります。 写真から正確な段数・部品数・クリアランス値を補ってはいません。 設計上の5段・台座19個は組立手順の値として区別します。

### 4. 右側のロゴが入った状態

右側の前面にロゴ部品が入った台座。左の銘板領域は空いている

報告日：2026-09-23。 右側のロゴ部品が入った状態を確認できます。 左の銘板領域は空いています。掲載順は組み方を理解しやすい順であり、 この写真が他の写真より先に撮影されたという意味ではありません。 差し込む操作、必要な力、保持力、何回着脱できたかは写っていません。

### 5. 個人銘板と右ロゴを取り付けた土台へ

2行の個人銘板と右側のロゴが取り付けられた黒い台座。顔やゴーグルはこの写真にはない

報告日：2026-09-23。本人の言葉：「土台が組み上がりました」。 前面に2行の個人銘板と右ロゴがそろった状態です。 今回は台座と前面部品の実制作マイルストーンとして記録します。 写真だけで無接着を証明したり、keeperの保持・分解耐久・完成模型の安定性が合格したとは言いません。 9/23時点では顔・ゴーグル・完成150部品全体の制作写真は未提供でした。 その後の顔下部の進捗は、下の9/24追記として区別しています。

## 補足ギャラリー — 同じ進捗の別角度も含む

台座の上面・側面・前面を、あと4枚で見る

台座の上面のスタッドと継ぎ目が分かる別角度

上面側。報告日：2026-09-23。 スタッドと継ぎ目を確認できます。寸法・段数の実測記録ではありません。

黒い台座の側面と上面を見た別角度

側面側。報告日：2026-09-23。 同じ進捗を別角度から写した可能性があります。未撮影の組立操作を補う写真ではありません。

前面の継ぎ目と2つの取付け領域の詳細

前面の詳細。報告日：2026-09-23。 継ぎ目と取付け領域が見えます。写真の画素から嵌合公差は算定しません。

前面パーツが入っていない状態の台座全景

前面全景。報告日：2026-09-23。 前面部品が入っていない状態です。写真の番号・掲載順は撮影時刻の順番を保証しません。

## 2026-09-24 — 土台の上へ、顔下部を組む途中記録

本人の言葉：「こちらは組み立ての途中記録になります」。 銘板・右ロゴを取り付けた土台の上へ部品を積み、顔下部の輪郭が立ち上がってきました。 以下は理解しやすい説明順です。添付順や元ファイルの時刻を撮影順・正式なCAD工程番号に変換していません。 同じ進捗を別角度から撮った写真も含みます。

色も観察と設計を分けます。 実写真では紫と黄色に見える部品があります。 設計データのマゼンタ／緑を変更したものではなく、この記録追加でSTL・BOM・3Dの配色を変えていません。 部品を探すときは3D工程や工程表を参考にできますが、 写真だけで特定のB-xxxや正確な部品数・工程番号を認定しません。

### 1. 土台の上に、紫の低い横並び

銘板と右ロゴのある台座の上へ、紫色の低いパーツが横並びに載った途中の状態

報告日：2026-09-24。 銘板と右ロゴの付いた土台の上に、 紫の低いパーツが横並びに載った状態です。 台座から顔側へ組立が進み始めた見え方として記録し、実際に何個追加したかは写真から補いません。

### 2. 黒い層と、紫の左右の段付き輪郭

台座の上へ黒い層と紫の左右の輪郭を積んだ顔下部。背面の黒い板状物の用途は未確認

報告日：2026-09-24。 黒い層の左右に紫の段付き輪郭が見え、 顔下部が土台より上へ立ち上がってきた状態です。 写真で確認できるのはこの途中形状で、上部ゴーグルが完成した状態ではありません。

### 3. 黄色い縦2列が入った顔下部

黒い顔下部と紫の段付き輪郭の中に黄色い縦2列が見える途中写真。上部ゴーグルは写っていない

報告日：2026-09-24。 黒い顔下部の中に黄色い縦2列が見えます。 写真の見た目をそのまま記述しており、設計上の緑色の部品を黄色へ変更する指示にはしていません。 材料の銘柄や色名、使用した印刷ファイルの版までは未照合です。

### 4. その上へ黒い列を加えた状態

黄色い縦2列の上に黒い横列がある顔下部の途中状態。上部ゴーグルと頭頂はまだ写っていない

報告日：2026-09-24。 黄色い縦2列の上に黒い列が加わった状態が写っています。 9/24の記録はここまでの顔下部の組立途中です。当日の写真には上部ゴーグル・頭頂は写っておらず、 全150部品の完成や模型全体の強度・保持・転倒の合格へ広げません。

9/24の近い状態を、補足の3枚で見る

黒い顔下部と紫色の段付き輪郭を近くから写した補足写真

顔下部の詳細。報告日：2026-09-24。 継ぎ目と左右の輪郭を見られる角度です。 上の写真と別工程だったとは断定しません。

顔下部を積んだ台座と、周囲に斜めに置かれた用途未確認の黒い板状物が写る補足写真

少し離れた角度。報告日：2026-09-24。 周囲の板状物も写っています。 その用途や固定方法を、写真から推定して部品表へ追加することはしません。

黄色い縦2列と上の黒い列がある顔下部を別角度から写した途中写真

上の黒い列がある状態の別角度。報告日：2026-09-24。 同じ進捗の補足写真として扱い、新しい独立した工程や完成写真には数えません。

#### 写り込みと未確認事項

一部には背面に立つ黒い板や、左右へ斜めに置かれた板状物も写っています。 用途・材質・固定方法は説明されていないため、保持具・構造部材・同梱パーツ・失敗対策等とは断定しません。 造形物やこれらの板状物を、写真から都合よく消す加工はしていません。

9/24時点で前の9/23記録から分かったのは、顔下部の実制作が途中まで進んだということです。 接着の有無、各接続の保持力、荷重、寸法公差、着脱寿命、実スライスとの版対応は引き続き未確認です。

## 2026-09-25 — ゴーグルを組み、頭頂までそろって完成

本人の言葉：「制作過程の写真です」、そして 「これで完成ですね」。 前日の顔下部から、水色のゴーグル枠が立ち上がり、最後に上枠と紫の頭頂がそろいました。 文字の試作から一つずつ積み上げてきたBが、ついに形になりました。完成おめでとうございます。

以下は実写真でたどる4つの説明段階です。近い状態の別角度も含むため、 8枚を8つの正式なCAD工程とは数えず、撮影時刻や厳密な前後関係も推測していません。 日付はすべて報告日2026-09-25です。

### 1. 水色のゴーグル下縁と側支柱が加わる

顔下部の上へシアン・水色のゴーグル下縁と端のブロックが加わった実物の途中写真。背景は切り取りとマスク処理済み

顔下部の上にシアン／水色の下縁が横に伸び、左右に支柱が立った状態です。 それまでの紫の輪郭と黄色い縦2列の上へ、ゴーグルの形が見えてきました。

### 2. 左右の黒い領域と中央の水色列を積む

ゴーグル部分の左右の黒い領域と中央のシアン・水色の列が見える実物の途中写真

左右の黒い領域と、その間のシアン／水色の列が高くなる途中です。 外周と中央の列を見比べながら、顔の上半分が立ち上がっていく様子を記録します。

### 3. 上部が開いた、高いゴーグル枠

左右の黒い面とシアン・水色の側面と中央列が高くなった、上枠を閉じる前の実物写真

側面と中央が高くなり、まだ上部が開いている状態です。 仕上げの上枠を取り付ける前の姿として、完成写真と並べて見ることができます。

### 4. 上枠と紫の頭頂までそろって完成

9/25の実物完成写真。ゴーグル上枠と紫の頭頂、顔、台座、個人銘板、右ロゴまでそろった姿。背景は切り取りとマスク処理済み

ゴーグルの上枠が閉じ、紫の頭頂パーツまでそろっています。 銘板と右ロゴのある台座から頭頂まで写った姿と、本人の「これで完成ですね」という言葉を、 今回の完成記録として残します。

実物の完成写真です。 背景PC画面などを隠すため、輪郭の周囲に薄グレーの不透明マスクが入っています。 撮って出しではありませんが、模型の色・印刷線・糸・隙間を修復したり、CGで補完したりしていません。

9/25の組立過程を、補足の4枚で見る

シアン・水色の下縁と側面、中央列の間へ黒い上部ブロックを積んだ補足写真

下縁から上へ。報告日：2026-09-25。 側面と中央の列の間に黒いブロックが見えます。 正式な工程番号を決めるためではなく、この時点の見え方を残す写真です。

左右の黒いブロックとシアン・水色の縁を別角度から見たゴーグル組立途中の補足写真

左右の領域を別角度から。報告日：2026-09-25。 似た状態の写真もあり、それぞれを独立した工程とは数えていません。

黒い左右の面と中央のシアン・水色の列が高く積まれ、上枠がまだ開いている途中写真

高くなったゴーグル部分。報告日：2026-09-25。 黒い面と中央の列が上へ伸びています。上枠を閉じる前の姿です。

高くなったゴーグル部分を写した、頭頂を仕上げる前の実物の補足写真

頭頂の仕上げ前。報告日：2026-09-25。 完成写真に至る途中の姿として残しています。掲載順は撮影時刻の証明ではありません。

写真の紫・黄色は実制作の配色です。設計データのマゼンタ・緑を書き換えたものではありません。 画面の完成CGは引き続きCGとして区別し、ここには実物写真を掲載しています。

#### 3. 3Dプリント — 設計したパーツを印刷する

公開タイトル：AIでLEGO風ブロックを設計して3Dプリント｜GitHub Copilot × FreeCAD × Blender

ユーザーが「3Dプリントの動画」として提供した、今回の印刷工程の映像です。 Web版では上のプレイヤーで▶を押してページ内再生できます。自動再生はしません。 続く超音波洗浄との並びは制作フローの説明順で、撮影順や実経過時間を証明するものではありません。

視聴にはインターネット接続が必要です。 GitHub上のMarkdownや保存版からは、 Web版の3Dプリント動画をページ内で見る (https://ktanino10.github.io/copilot-brick-gift-b/docs/BUILD-LOG.html#printing-video-2026-09-25)。 埋込みで再生できない場合はYouTubeで開く（補助リンク・新しいタブ） (https://youtu.be/sinN3dKGwRg)。 公開タイトルは確認されていますが、動画から印刷設定・時間・材料量を推測して記録していません。

#### 4. 超音波洗浄 — 今回の印刷後の後処理

公開タイトル：3Dプリント後のパーツを超音波洗浄｜Ultrasonic Cleaning of 3D-Printed Parts

Web版では、この場所のYouTubeプレイヤーの▶を押してページ内で再生できます。自動再生はしません。 視聴にはインターネット接続が必要です。 プレイヤーの読み込み・視聴時にはYouTubeへ通信し、 環境により同意や接続の確認が表示されることがあります。

GitHub上のMarkdownや保存したオフライン記録からは、 Web版のページ内プレイヤーで見る (https://ktanino10.github.io/copilot-brick-gift-b/docs/BUILD-LOG.html)。 ファイルを直接開いた場合も写真と3Dは通信不要のままで、動画だけはWeb版で視聴してください。

埋込みで再生できない場合はYouTubeで開く（補助リンク・新しいタブ） (https://youtu.be/Lc_enNE3nng)

ユーザーが今回の制作工程として示した「3D Print後の超音波洗浄」の動画です。 洗浄条件や結果をこちらで確認したものではなく、どの模型にも必須という案内や検証済みの洗浄レシピではありません。 上の写真に洗浄の様子が写っているという意味でもありません。

動画本体やサムネイルのファイルをキットへコピー・再配信していません。 保存版には外部プレイヤーを埋め込まず、オフラインの写真読込みをYouTubeへ依存させていません。

## CLI風アレンジ（実物写真）

ブロックを変更してCLI風にアレンジした実物です。標準配布モデルとは異なるアレンジ例です。 シアンのゴーグル枠、黒い顔、マゼンタの輪郭と緑色の目が見えます。

CLI風にアレンジした実物のブロック模型。シアンのゴーグル枠、黒い顔、マゼンタの輪郭、緑色の目と黒い台座。背景モニターの文字部分はマスク処理済み

追加日：2026-09-30（JST）。撮影日は未確認です。 標準モデルのCAD・STL・3MF・3D組立順は変更していません。 写真だけで、全部品が配布STLと同一であることや、嵌合・強度・転倒への安定性を確認したものではありません。

## 学びと、次に残る確認

実物の文字相談から設計を見直し、その後に手応えの報告と台座・前面の写真、 9/24の顔下部の途中、9/25のゴーグル・頭頂と完成へ続く制作の流れを残しました。 写真と本人の言葉を通して、部品が少しずつ模型になっていく過程を振り返れます。

残した実制作の記録 | 記録の位置づけ
文字の相談、改訂と試作についての手応え | 本人の感想と実写真。印刷条件による効果の測定とは別
土台と前面、顔下部、ゴーグルの組立過程 | 日付別の写真観察。写真番号を正式CAD工程や撮影時刻に置き換えない
上枠と紫の頭頂までそろった写真と「これで完成ですね」 | 本人の完成報告と、完成した姿の実制作記録

設計・測定との区別： 完成の報告を、写真だけで150個を個別検品した結果、 寸法・荷重・耐久・転倒の測定合格、使用STL／実スライスの版・hash照合とはしていません。 それらの記録は未提供です。制作の完成を否定するものではなく、記録の種類を分けています。 この制作記録の追加で、STL・3MF・native・150配置や、黒→白の境界を変更していません。 配布データは引き続きNOT_SLICEDです。 作業を進める際は印刷手順・少量試作・組立手順を参照し、 強い力、白化・割れ、着座不良や保持不足があれば止めてください。

## 写真の取扱い

写真の権利はユーザーに帰属します。今回の掲載許可は、モデル・フォント・ソフトウェアのライセンスを 写真へ自動適用したり、第三者へ包括的な再利用権を与えたりするものではありません。 この個人版には許可された銘板の文字を残し、無関係な背景を可能な範囲で切り取っています。 2026-09-23の追加承認により、個人版repoとこの案内ページも公開対象になりました。 一般向けrepoの伏字画像とは別系統です。加工前の原画像・EXIF・監査元パスは公開しません。

9/24の新しい7枚についても、個人版は銘板の文面を残し、一般向け版は個人URLを伏せ、 両方で背景PC画面と撮影メタデータを除去する形での掲載を、本人が別途承認しています。 親担当が一度だけ加工した派生をそのまま取り込み、このrepo内で再加工していません。 9/25の制作過程・完成の8枚も、同じ公開範囲で制作記録へ追記することを本人が承認しています。 背景の切り取り・必要なマスクなどの加工内容は、各日のmanifestに記録しています。

9/30のCLI風アレンジ写真1枚は、このrepoと既存Pagesへの追加として提供されました。 背景モニターの文字部分だけを不透明にマスクし、模型本体は修整せず、Web向けに縮小・JPEG化してメタデータを除去しています。 原画像は変更していません。

このページに含むのは加工済みの実写真25枚（9/23までの9枚＋9/24の7枚＋9/25の8枚＋9/30追加の1枚）です。元ファイル名・EXIF・位置・カメラ情報、 加工前の原画像、監査用の元パス対応表は収録していません。 9/23までの画像一覧、 9/24の画像一覧、 9/25の画像一覧、 9/30追加の画像一覧には、 中立ID・報告日・寸法・配布画像のhash・回転／切り取り／メタデータ除去の範囲など、 配布用の情報を記録しています。 写真のスライドショーを実組立動画と称していません。

公開許可済みの個人版制作記録。掲載順は説明順です。撮影日時・版・実測条件は未照合です。図面の設計値や3Dの説明用の動きと、写真で確認できる状態を分けてください。

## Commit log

2026-09-19 Complete personal B print kit and Japanese guides
    [B-black-01.3mf, B-black-02.3mf, B-black-03.3mf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]
2026-09-20 Add offline B print-to-place assembly guide
    Bundle the actual-mesh offline viewer, all 150 slot mappings, beginner guides, rendered media, and verified private kit archive.
    [part-map.csv, steps.csv]
2026-09-22 Adopt the approved two-line nameplate legibility revision
    Keep the black carrier, 20 other masters and all 150 placements unchanged; update the real native/STEP, plate, lettering coupon, current drawings, guide media and private kit.
    [B-black-to-white-z2p4-01.3mf, B.FCStd, NP3-LETTER-TEST-B-V2.3mf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]
2026-09-23 Record the photographed base and nameplate build milestones
    Add the nine approved metadata-free private photos, distinguish user reports and observed milestones from unprovided physical validation, and link the offline build journal without changing print geo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
2026-09-23 Publish the approved personal B recipient guide with GitHub Pages
    Record explicit public-repository consent and history audit; deploy only allowlisted current pages, guide display assets and approved photographs. Preserve original photos, local audit/session state 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
2026-09-24 Append the September 24 lower-face assembly photo record
    Preserve the earlier nine photos and all print/native/3D media while adding seven approved, metadata-stripped recipient photos, four observed stages and a stable dated link. Distinguish purple/yellow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
2026-09-25 Record the September 25 assembly completion photos
    Append the eight approved recipient derivatives through the closed goggle frame and purple crown, retain the earlier sixteen photos and dated anchors, and recognize the user's completion report witho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
2026-09-25 Link the user-provided ultrasonic cleaning video
    Add only the exact external YouTube reference to the completion record and README, with online-viewing notice and safe new-tab attributes. Do not embed, download or rehost video or thumbnails, or inf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
2026-09-25 Embed the user video within the public completion journal
    Use the exact privacy-enhanced YouTube player with inline manual playback, compatible referrer policy and frame-src limited to youtube-nocookie.com on that page only. Keep offline photos and3D indepe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
2026-09-25 Present the five-stage build with printing and cleaning players
    Keep both exact user videos as separate manual inline players in printing-then-cleaning order. Link planning, design, printing, ultrasonic cleaning and assembly to the existing materials and completi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
